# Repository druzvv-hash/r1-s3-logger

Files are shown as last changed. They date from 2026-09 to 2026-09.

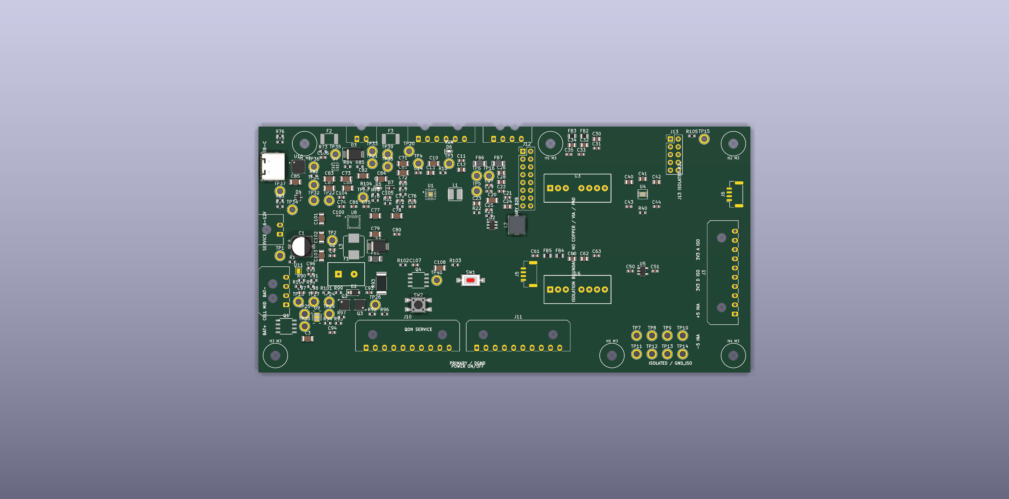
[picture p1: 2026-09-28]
hardware/kicad/R3_PowerBox/reports/R3_power_preliminary_placement.png

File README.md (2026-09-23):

# R1-S3 Logger

**[Посібник екосистеми: схеми, підключення та інструкції](../lily-logger-r3/docs/manual/README.uk.md)** — актуальний спільний вхід для R3, R1, CANBox і Viewer.

**English** | [Українська](README.uk.md)

Rebuilding Logger R1 around **ESP32-S3 + INA228**. Current firmware: **PANEL v0.36-can-live-dev**, with USB/Wi-Fi Start/Stop controls, integer 1–300 Hz measurements with presets and manual input, a 30/60 FPS live chart and explicit draft/apply/save settings. Sessions flow through a PSRAM FIFO into checked block writes on microSD. The encoder remains a no-GPIO stub. [Recording guide](docs/P5_RECORDING.md).

CAN tab: shared live/CBX playback/finite transmit workspace, using CANBox USB or
Wi-Fi directly. BLE remains service-only. [CAN guide](../GLL%20CANBox/docs/CAN_WORKSPACE.uk.md).

INA228 averaging/conversion controls and 10/30/60 s chart navigation: [guide](docs/INA228_PANEL.md).
**R3 ecosystem:** saved authenticated association, boot reconnect, coarse RTC
correction while idle and optional remote Start/Stop through R3's `/ecosystem`
page are implemented and host-tested. A [bounded two-board bench passed](docs/ECOSYSTEM_ACCEPTANCE_2026-09-09.md)
for saved permissions, coarse RTC correction, selected control and reboot recovery. Save
time-only or explicitly enable recording permission. New files use CSV v2 with
static group/RTC provenance, preserving v1 reading. [Operator guide](docs/ECOSYSTEM_CONTROL.md).

**Device UI:** run [device_ui/start.cmd](device_ui/start.cmd) with the board on native USB (COM9 on this PC),
or join the logger's Wi-Fi AP and open 192.168.4.1. Credentials are shown in the USB
panel's Diagnostics tab. [Test-panel guide](docs/P4A_TEST_PANEL.md).

**SD files:** the **Файли SD** tab lists folders and downloads existing files through
USB or Wi-Fi, without removing the card. [File transfer guide](docs/SD_DOWNLOADS.md).
The scrolling explorer includes search, sorting and automatic full-folder loading.
[Measured rate/noise limits](docs/RATE_BENCHMARK.md) distinguish usable control from
the experimental recording ceiling; v0.22 adds explicit [1–300 Hz profiles](docs/MEASUREMENT_RATES.md) with visible speed/noise tradeoffs.

## Hardware

- ESP32-S3-WROOM-2-N32R16V (reported marking MCN32R16V): 32 MB Octal Flash, 16 MB Octal PSRAM.
- Shared I²C bus: SDA GPIO8, SCL GPIO9, 100 kHz; INA228 `0x40`, SH1106G 128×64 OLED `0x3C`, 24C32 EEPROM `0x50`, DS3231 RTC `0x68`.
- SPI SD: CS GPIO10, MOSI GPIO11, SCK GPIO12, MISO GPIO13.
- INA228 ALERT: GPIO14. External shunt: owner-confirmed 60 mV / 400 A (150 microohms).
- OLED rotation: 180°. The current bench uses direct ESP32-S3 USB Serial/JTAG on COM9.

See the [pin map](hardware/pinmap.md). Board revision and SD module circuitry remain to be recorded.

Selected local control: [Bourns PEC11R-4220F-S0024](hardware/encoder.md), not yet installed. Physical and web controls will share one device state.

## Verified status

| Component | Result |
|---|---|
| Flash / PSRAM | Detected; no memory stress test performed |
| I²C | Four expected addresses responding in repeated scans without bus errors |
| SD | 10 MHz write, close, remount and exact readback PASS; output files checked on a PC |
| OLED | SH1106G 128×64 image and 180° rotation confirmed by the owner |
| EEPROM | Owner confirmed EEP PASS: backup, sample write, restore and full-image comparison |
| RTC | Browser UTC synchronization verified; OSF=0, tick PASS; retention checked after owner-reported power disconnection |
| INA228 | Fresh ADC and owner-reported voltage comparison established; independent current calibration and active ALERT pending |

Native USB flashing, full-image verification and console operation are confirmed. Use direct USB going forward; the cause of intermittent CP210x failures remains unproven.

## VS Code / PlatformIO

Open the repository root in VS Code with PlatformIO IDE installed. Dependencies are pinned to `espressif32@6.12.0` (Arduino 2.0.17), `Adafruit SH110X@2.1.12` and `NimBLE-Arduino@1.4.3`.

```sh
pio run
```

The default environment is `esp32-s3-usb`: direct USB Serial/JTAG with the console enabled. This R1 is COM9; confirm device identity before flashing (CANBox is COM11). Close the UI bridge / Serial Monitor before uploading. Port numbers may change on another PC.

```sh
pio run -e esp32-s3-usb -t upload --upload-port COM9
pio device monitor -e esp32-s3-usb -p COM9
```

`esp32-s3-uart-manual` retains the BOOT + RESET fallback (manual RESET after upload). `esp32-s3` retains the old UART profile; native USB is the normal workflow. The explicit `esp32-s3-service` build enables the original SD/EEPROM write tests; ordinary builds exclude them.

## Current behavior and migration

Normal boot reads the SD root and checks two complete EEPROM reads, then displays live voltage/current. It creates no SD test files and writes no EEPROM patterns. `SD READ / SAVED` indicates readable SD and matching persisted settings; UNSAVED means explicit saving is needed. The explicit [RTC sync](docs/rtc-sync.md) command remains available; saved R3 enrollment also permits automatic fresh RTC correction while idle. INA228 uses timed 1–300 Hz acquisition. Explicit START creates a session; STOP drains, verifies and closes it before publishing the CSV.

[3 A / 3 V load acceptance](docs/LOAD_TEST_2026-09-08.md): all three rates passed without missed samples or I2C errors; 40 verified USB downloads passed alongside 100 Hz acquisition. v0.17 fixes delayed panel-state publication found during these tests.

The [PSRAM FIFO and block-buffer foundation](docs/BUFFERING_AND_REUSE.md) is implemented and host-tested. Boot reserves the configured sample budget in PSRAM plus 8 KiB internal SD staging; the recorder now uses these buffers after explicit Start. P4a now has a working web test panel on core 0 and a hardware command owner on core 1. [P4b live acquisition](docs/P4B_LIVE_ACQUISITION.md) now uses timed INA conversions, chunked OLED transfers and batched PSRAM preview. [P5 session files](docs/P5_RECORDING.md) are implemented; local menus remain.

[P0 baseline and backup evidence](docs/P0_BASELINE.md). P1 contracts: [settings/EEPROM](docs/CONFIG_SCHEMA.md), [self-contained CSV](docs/FILE_FORMAT.md), [viewer compatibility](docs/VIEWER_COMPATIBILITY.md). Run host checks with `python -m unittest discover -s tests -v` (Python 3.10+; firmware-core tests also need a native C++ compiler). P2 viewer is implemented: launch `viewer/start.cmd` or `python viewer/server.py`. [Viewer guide](viewer/README.md) · [P2 results](docs/P2_VIEWER.md). P3 settings/EEPROM are implemented: [commands and evidence](docs/P3_SETTINGS.md). P5 connects acquisition to session recording, checkpoints and rotation; physical acceptance and limits are in the recording guide. The owner deferred remaining R5 analysis/plugins until real logger files exist. The current viewer is a data-reading foundation, not a feature-complete R5 replacement.

## Repository guide

- [BLE link controls](docs/BLE_LINK.md): authenticated pairing and explicit saved permission through **BLE · R3**. The [v0.24 two-board bench](docs/ECOSYSTEM_ACCEPTANCE_2026-09-09.md) verifies control and recovery within documented limits; extended qualification and the earlier 300 Hz signal-quality question remain open.
- [Ecosystem control](docs/ECOSYSTEM_CONTROL.md): time-only/remote permission, ON/OFF/FORGET, boot RTC correction and selected R3 control.
- [Ecosystem synchronization](docs/ECOSYSTEM_TIME_SYNC.md): R3 / R1-S3 / CAN architecture; [CSV v2](docs/FILE_FORMAT_V2.md) has static provenance, while precise sample alignment and the CAN adapter remain pending.
- [firmware/](firmware/README.md): Arduino test firmware and GPIO constants.
- [hardware/](hardware/README.md): hardware notes and pin map.
- [Bring-up plan and results](docs/bring-up.md).
- [SD serial evidence](docs/sd-test-v0.2-serial.txt).
- [Project context](docs/project-context-review.md): relevant findings from earlier logger work.
- [Ukrainian owner notes](docs/uk/README.md): historical bench notes and local workspace review.

See the staged plan below for remaining acquisition, calibration, ALERT and recording acceptance work.

Legacy recovery: [R1 firmware and viewer review](docs/legacy-r1-analysis.md).

- [Migration journal](docs/R1_MIGRATION.md): migration stages, decisions and dated hardware evidence.

- [Engineering plan](docs/R1_S3_PLAN.md): architecture, EEPROM, self-contained recording and cross-version viewer roadmap.

## CANBox fallback (experimental)

The direct CANBox control adapter and panel are implemented in the working tree.
R1 flashing and the two-board BLE acceptance are pending a manual BOOT/RESET.
See [CANBox fallback status and procedure](docs/CANBOX_FALLBACK.md).

The owner confirmed that the R1 SD card was removed during the CANBox bench. The observed SD FAIL therefore does not establish an SD fault; recheck after reinsertion.

Deployed update: **0.28-canbox-dev** adds an always-visible CANBox status and controls, including unknown/offline and pending states. Native USB deployment and live CANBox readiness/authorization verified.

## CANBox clock update 0.29

Deployed: the connected R1 supplies its valid, fresh RTC calendar to CANBox.
START requires clock_synced; STOP remains available. Live synchronization
passed; the new SD-file acceptance test awaits card reinsertion in CANBox.
See `C:\Projects\GLL CANBox\docs\CLOCK_SYNC_2026-09-15.uk.md`.

**CANBox + R1:** [Спільний запис / linked Start and Stop](docs/LINKED_RECORDING.uk.md) — перемикач біля старту CANBox, одна група сесій, підтверджений стан обох пристроїв.

Wi-Fi firmware updates: [Browser OTA](docs/OTA.md).

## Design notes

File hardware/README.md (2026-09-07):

# Hardware

The current bench consists of an ESP32-S3 board and external INA228 module, shared I²C peripherals and SPI SD storage. Initial supply checks were reported as normal; a complete numerical measurement record is still needed.

- [Pin map](pinmap.md)
- [Bring-up plan and results](../docs/bring-up.md)

The owner reports ESP32-S3-WROOM-2-N32R16V (MCN32R16V): 32 MB Octal Flash / 16 MB Octal PSRAM. Firmware detects 32 MiB Flash and approximately 16 MiB PSRAM; no stress test has been performed. The bench CP210x USB–UART bridge currently appears as COM5 on Windows.

Store schematics, BOM, wiring photos and shunt specifications here as they become available. No schematic or PCB files are included yet. Record the exact board revision, SH1106G OLED and DS3231 module wiring, SD module power circuitry, shunt resistance and allowable current.

## External shunt

Owner-confirmed on 2026-09-07: **60 mV / 400 A**, nominal **150 microohms (0.00015 ohm)**; owner reports it connected. HWTEST v0.9 uses this nominal resistance for signed current from VSHUNT. This is not measured calibration. Wiring/polarity, shunt tolerance and temperature coefficient remain to be recorded. See [migration journal](../docs/R1_MIGRATION.md).

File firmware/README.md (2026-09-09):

# PANEL v0.20 firmware

PlatformIO + Arduino for ESP32-S3 N32R16V. Run commands from the repository root. See the [main README](../README.md) for build and upload environments.

The [device test panel](../docs/P4A_TEST_PANEL.md) now provides USB/Wi-Fi controls.
The hardware owner remains core 1; the web task on core 0 uses snapshots and commands.
I²C scanning after startup is explicit, not periodic. Timed integer 1–300 Hz sampling,
chunked OLED and PSRAM live preview are implemented. [Session recording](../docs/P5_RECORDING.md) uses the PSRAM FIFO and checked SD block writes.
See [cadence and transport](../docs/P4B_LIVE_ACQUISITION.md).
Existing SD files can now be downloaded through the panel; the dedicated storage
owner is in `sd_files.cpp`. See [file transfers](../docs/SD_DOWNLOADS.md).

- `src/main.cpp`: memory information, explicit I²C scans, SD test and SH1106G 128×64 OLED rotated 180°.
- `src/eeprom_test.cpp`: 24C32 backup to SD, sample write, restoration and full-image comparison.
- `src/rtc_test.cpp`: read-only DS3231 calendar/BCD, temperature, OSF/EOSC and tick checks.
- `include/pins.h`: GPIO constants matching [hardware/pinmap.md](../hardware/pinmap.md).
- `r3_time_beacon.h/.cpp`: portable strict legacy R3 TMB decoder and bounded observation tracker. Not attached to runtime BLE/UART; never changes RTC or sample time. [Ecosystem time architecture](../docs/ECOSYSTEM_TIME_SYNC.md).

Ordinary boot only reads SD/EEPROM. Explicit CONFIG SAVE writes settings; see [P3 workflow](../docs/P3_SETTINGS.md). `esp32-s3-service` explicitly enables the legacy SD file and EEPROM pattern/restore tests. Periodic checks never set time; the explicit browser command does. See [RTC sync](../docs/rtc-sync.md). The EEPROM write test is temporary diagnostic code; keep power connected until restoration completes.

The default environment is `esp32-s3`; manual UART remains a fallback. Automatic UART reset and experimental native USB environments remain in `platformio.ini`. Automatic UART uploads passed after USB-UART controller rework; long-term reliability remains to be established. See [bring-up results](../docs/bring-up.md).

- `src/ina228_test.cpp`: identity, fresh triggered VBUS/VSHUNT/temperature sample, ADC_CONFIG restoration and passive ALERT level. See the [migration journal](../docs/R1_MIGRATION.md) for test side effects and acceptance limits.

- `include/shunt_config.h`: historical nominal shunt checks. Runtime conversion now uses `appliedSettings()` with validated polarity, shunt, offsets and gains.
- `settings_core.cpp`: portable TLV/CRC/A-B store, INA apply/readback/rollback.
- `settings.cpp`: 24C32 adapter and STOP-only draft/apply/save UART workflow.
- `config_fields.h` and `config_codec_generated.inc`: generated from schemas/config-v1.json. Regenerate with tools/generate_config.py; do not hand-edit.
- `local_input.cpp`: no-hardware encoder stub; no GPIO accessed. [Selected encoder](../hardware/encoder.md).
- `recording_buffer.cpp`: SPSC numeric FIFO and checked block-output primitives; `recording_memory.cpp` reserves PSRAM payload plus an 8 KiB internal DMA-capable staging buffer at boot. Acquisition/SD owners are not yet connected to them. [Reuse evidence and limits](../docs/BUFFERING_AND_REUSE.md).

- `src/storage_check.cpp`: read-only SD-independent EEPROM checks and `EEPROM DUMP` backup transport. See [P0](../docs/P0_BASELINE.md).

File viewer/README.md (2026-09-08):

# R1 / R1-S3 offline viewer 0.2

P2 offline viewer, Python 3.10+ and a modern browser. **No pip/npm install, CDN, Internet connection or device connection is required.** The interface is Ukrainian; code/contracts/documentation are English.

## Start

Windows: double-click `viewer/start.cmd` (requires the Python `py` launcher), or run from the repository/bundle root:

```text
python viewer/server.py
```

The launcher opens the browser. Choose a CSV file or drag it onto the upload area. Keep the launcher running; Ctrl+C stops it. If port 8766 is occupied, use `python viewer/server.py --port 0` to select an available local port. `--no-browser` prints the URL without opening it.

This is a local Python application with a browser interface, **not a standalone HTML or executable**. It binds only to 127.0.0.1, uses a per-run access token, and rejects cross-origin mutation requests. Recordings travel only from the browser to the same computer. Temporary SQLite data are removed at normal shutdown; after a process crash an OS temporary folder can remain. Source recordings are never edited.

## Supported and intentionally limited

- R1 named eight-column CSV: columns by name, optional reordered/extra fields, BOM/CRLF, comments before/after header.
- R1 Pss CSV: current/voltage/power by names; Pss_Wh remains separately labelled because its accumulator meaning is unverified.
- Short/headerless R1 CSV: explicit user confirmation of milliseconds, A, V, W and net Wh before import. Headerless presets have six/eight columns. Unknown layouts require a matching source/mapping, not automatic guesses.
- R1S3 native CSV v1: metadata/config/units, raw/calibrated consistency, monotonic/UTC time, integration, CRC/checkpoints and SHA256 END checks. Exact u64 values remain integer strings in normalized records. Plot coordinates use bounded segment-relative floating seconds.
- Interrupted native file: only checkpoint-verified rows enter charts/statistics; complete unverified tail count and partial-line status are reported. Corrupt files fail explicitly, rather than displaying misleading data.
- LYLI/R3 binary files are recognized but unsupported until P8's verified adapters.

Legacy timezone is unknown unless a fixed UTC offset is explicitly supplied (minutes). This does not implement automatic DST. Existing timezone-qualified strings retain their own offset when interpreted. Relative time stays authoritative. Wrong-width or invalid-time rows are skipped with a continuity break; missing/nonfinite measurements become null and mark the row invalid. Malformed optional columns become null with a diagnostic. This initial viewer conservatively excludes an invalid measurement row from all channel analysis. Parsed numeric values, original timestamp text, line numbers and byte offsets remain in temporary normalized records; unavailable optional text is not retained as a numeric channel.

Select a segment when time resets or a repeated header starts a new session. The viewer never sorts away resets or bridges them. For legacy gaps, twice `interval_us` metadata is used when present; otherwise the explicit import threshold (default 1000 ms) applies. Legacy files cannot prove fresh cadence or missing samples merely from nominal metadata. Adjust the threshold and re-import when necessary.

## Graphs and analysis

Select any available series with the checkboxes. Each channel has its own labelled value axis; all panels share the same time viewport. The statistics-channel selector is independent of visible series. Wheel zoom is anchored at the cursor; choose drag-zoom or pan in the interaction selector. Double-click or “Увесь сегмент” resets the viewport. Numeric start/end inputs provide reproducible selection.

In marker mode, clicks place A then B at the nearest original samples (subsequent clicks replace the oldest). The panel displays exact original t_us, timestamp text, source line and quality. Delta time is signed B minus A. Full-resolution interval statistics use the sorted A/B bounds, independently of zoom. Shift-click places horizontal C/D levels for a single channel; choosing a different channel starts a new value pair so unlike units are never subtracted. Markers persist through zoom and series changes, and clear on new files/segments. “Масштаб A–B” fits their interval.

Hover reports the nearest actual row, its distance from the cursor, original values, quality and continuity status. It does not interpolate values or silently jump over invalid rows. In a gap the nearest sample can be far from the cursor; its displayed distance is intentional. Preview bins retain min/max extrema; a bin containing invalid data or a gap is isolated instead of joined across it.

Statistics scan all valid full-resolution rows in the selected range, not the preview. Mean is sample-weighted. Charge and energy use actual elapsed time, trapezoidal sign splitting, and no integration across gaps/invalid rows. No extrapolation/interpolation to range edges: uncovered edge intervals are included in “without data / outside samples”. Recorded Wh_net delta is shown separately from recomputed energy. First/last cumulative values of an independently opened rotation part are not proof of cross-part continuity.

Download JSON report contains interpretation metadata, diagnostics and selected-range statistics/preview, **not a full-resolution data export; marker coordinates and A/B statistics are included**. At most 200 diagnostic examples are retained, with total count separately available. Unknown optional text values are not plotted as numbers. An old-viewer CSV export, starter/battery plugins, binary adapters and automatic part joining remain later work; they are not advertised by this release.

## Capacity and verification

Input cap: 1 GiB, 10 million rows and 1000 time segments; disk space must accommodate the source upload plus a temporary database that can be substantially larger than CSV. Import reads bounded lines (64 KiB legacy record, 16 KiB native metadata, <=1024 native rows/checkpoint). SQLite uses a 4 MiB page cache; data live on disk. Plot output is at most 2000 extrema bins per selected channel (up to 32 known distinct channels per request). Import/statistics run in the local service, keeping the browser responsive; large scans may take time. Only one recording is active at a time.

Run `python -m unittest discover -s tests -v`. Optional UI smoke test uses Playwright/Chrome supplied by the developer environment: `node tests/smoke_viewer.cjs <printed URL>` and `node tests/r5_viewer.cjs <printed URL>`. It is not a runtime dependency. `python tools/benchmark_viewer.py --rows 350000` tests streaming native input above the P1 oracle's 16 MiB limit. [P2 results](../docs/P2_VIEWER.md) record measured scope and remaining limits.

Build a portable folder ZIP (Python runtime not included): `python tools/package_viewer.py`. Unzip before launching `viewer/start.cmd`.

## R5 preservation correction

This release is the file-reading foundation, not a feature-complete replacement for R5. P2.1a marker/series/navigation recovery is implemented. P2.1b analysis and P2.1c plugin recovery still precede firmware P3; see [migration matrix](../docs/R5_FEATURE_MIGRATION.md). Direct index.html opening now shows launcher instructions and disables nonworking file import.

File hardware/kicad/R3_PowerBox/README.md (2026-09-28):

# R3 PowerBox

Editable KiCad 10 project for the R3 power module. The schematic uses one root
page and ten functional child sheets so battery/BMS, charger/power-path,
user system-power control, primary converters, isolation, LDOs, INA bipolar power and connectors can be
reviewed independently.

## Open

Open `R3_power.kicad_pro` in KiCad 10. The canonical schematic is
`R3_power.kicad_sch`; the PCB file is `R3_power.kicad_pcb`.

## Directory layout

- `R3_power.kicad_pro` — KiCad project settings;
- `R3_power.kicad_sch` — power schematic;
- `R3_power.kicad_pcb` — PCB workspace;
- `libraries/` — project-local symbols and source libraries;
- `footprints/` — project-local provisional footprints;
- `docs/` — design decisions, checks, and transfer notes;
- `bom/` — KiCad-exported BOM plus sourcing/review notes;
- `legacy/` — read-only KiCad 5 source retained for migration reference;
- `tools/` — reproducible schematic generator and its setup notes;
- `manufacturing/` — release outputs only after schematic/PCB review;
- `reports/` — ERC/DRC reports generated during checks.

## Safety and design status

- The board is a unified 2S Li-ion power-management design. The preliminary
  system range is 6.0-8.4 V; there is no intermediate 2S-to-9 V converter.
- J1 is retained as a protected service/bench charger input. USB-C is the
  primary external input; STUSB4500 implements 5/9/12 V negotiation with
  12 V/2 A preferred and a boot-safe 0.50 A charger default.
- `DGND` and `GND_ISO` are separate galvanic domains and must never be joined.
- SW1/Q4 disconnect only `VSYS_MAIN`; BMS, PD and charging remain active while
  R3 is off. SW2 is the separate QON ship/wake/service control.
- The present files are an engineering prototype, not a manufacturing release.
- Q2/Q3, F1/F2/F3 and the dual-NTC strategy are selected for Rev.A. Battery
  chemistry/configuration, hot-current validation and PD NVM compliance remain
  open before ordering a PCB.
- The PCB contains a 160 x 80 mm outline, four spatial zones, an isolation
  keepout on all four copper layers, six NPTH M3 mounting holes, optional
  primary/isolated B2B headers and final pre-routing component placement. It
  has no routing or vias.
- KiCad ERC has zero errors. Remaining generator-related warnings and the visual
  review limitations are recorded in `docs/VERIFICATION.md`.

Start with [the current power review](R3_POWER_REVIEW.md) and
[battery architecture](R3_BATTERY_POWER_ARCHITECTURE.md), then see the compact
[design notes](docs/R3_power_module_design.md) and
[verification status](docs/VERIFICATION.md). Placement images are in
`reports/R3_power_preliminary_placement.png` and
`reports/R3_power_zone_isolation_annotated.png`; mechanical stack dimensions
and views are in [the B2B interface note](docs/R3_BOARD_TO_BOARD_INTERFACE.md).

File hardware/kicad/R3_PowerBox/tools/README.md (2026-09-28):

# Schematic regeneration

`generate_hierarchical.py` is the reproducible electrical source for the root
sheet and ten KiCad 10 child sheets. It requires Python and `skidl==2.3.0`.

Set `KICAD10_SYMBOL_DIR` to KiCad's `share/kicad/symbols` directory, run the
generator from the `R3_PowerBox` directory, and then open/save the result in
KiCad 10. Then run `tools/arrange_schematic.py` from the same Python environment.
It applies the reviewed, deterministic sheet layout without changing connectivity.
Regeneration replaces the generated schematic sheets, so always rerun the
arranger before review.

The arranger also fixes the dense battery/BMS sheet to A3 and the
charger/power-path sheet to A2. This prevents SKiDL's automatic paper-size
selection from clipping or crowding those two sheets on regeneration.

The generator also writes `logical_nets.json`. This is the authoritative
pin-to-net map used by the arranger, avoiding accidental reliance on labels that
may overlap in the initial automatic drawing.

The project-local symbol source is `libraries/R3_POWER.lib`; the native KiCad
library used by the editor is `libraries/R3_POWER.kicad_sym`.

`generate_preliminary_placement.py` is a separate, explicitly unrouted PCB
placement generator. Run it with KiCad 10's bundled Python after schematic
regeneration. It exports a temporary XML netlist, reloads the assigned
footprints, assigns nets and packs them into the documented four zones while
preserving the outline and isolation keepout. It never creates tracks or vias.

The placement generator also adds the six project-local M3 NPTH footprints,
their four-layer keepouts and the `Dwgs.User` future-R3 envelope. These are
mechanical PCB objects and intentionally do not appear in the schematic BOM.

`generate_mechanical_views.py` regenerates the annotated zone/isolation,
stack-top and stack-side PNG references (plus the annotated-zone PDF) from the
dimensioned coordinates used by this pass.

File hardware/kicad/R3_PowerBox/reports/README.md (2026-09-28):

# Verification reports

KiCad ERC and DRC reports are stored here. A report documents only the file and
revision that generated it; it is not physical hardware acceptance.

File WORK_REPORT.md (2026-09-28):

# r1-s3-logger — work reports

## 2026-09-28 — R3 PowerBox mechanical and B2B pass

Added six electrically floating 3.20 mm NPTH M3 holes with project-local 8 mm
all-copper-layer keepouts, DNP J12 primary 2x8 and J13 isolated 2x5 generic
2.54 mm THT stacking interfaces, a dimensioned `Dwgs.User` upper-board
envelope and reproducible top/side mechanical views. Existing Micro-Fit cable
interfaces, user power controls, zones and 3 mm isolation corridor remain.

The final placement has 193 electrical footprints plus six mechanical holes,
0 tracks and 0 vias. KiCad checks report ERC 0 errors/412 known generator-grid
warnings and zero clearance, copper-edge, hole, drill, annular or courtyard
geometry errors. Visual review covered all 11 schematic PDF pages. U3/U6 are
11.1 mm high, making 15 mm the recommended stack; 12 mm needs upper-board
cutouts. Routing remains blocked by the pre-existing programming/bench/thermal
gates plus final enclosure, M3 and header/socket mechanical selection.

## 2026-09-28 — R3 PowerBox KiCad capture

Created and advanced `hardware/kicad/R3_PowerBox` to a final pre-routing
checkpoint. The editable SKiDL source now generates a root plus ten functional
sheets covering 2S battery/BQ28Z610 protection, BQ25798 NVDC charging,
STUSB4500 USB-C PD, service-input muxing, user load switching, TPS62132/TPS54302,
separate ADS and INA primary filters, RS3E/RS3 isolation, ADM7150/TPS7A20 clean
rails, connectors and test points. `DGND` and `GND_ISO` remain distinct.

Closed the final UI/control correction: Q4 `DMP3007LSS-13` switches
`VSYS_PROT` to `VSYS_MAIN` while BMS/PD/charging remain upstream; SW1 is normal
latching power and SW2 is separate QON service. D5 remains on REGN/raw
`BQ_STAT_RAW`; BAT54WS isolates the 3.3 V `CHARGE_STATUS` logic. J11 exports
panel power/control/I2C/status without shared onboard LED-anode nets or GND_ISO.
The conservative status LOW is <=0.72 V, below STM32H755 and ESP32-S3 limits.

Validation with KiCad 10.0.0 and SKiDL 2.3.0: PDF export PASS and all 11 pages
visually inspected; ERC 0 errors / 408 generated library-grid warnings. BOM and
logical net map regenerated. The 160 x 80 mm four-layer preliminary placement
contains 191 footprints, no courtyard overlap, 0 tracks and 0 vias. DRC has zero
clearance, copper-to-edge, drill-range and annular-width findings; remaining
items are expected unrouted connections and silkscreen cleanup. No Gerbers,
routing, procurement, assembly, power-up, thermal, ripple, EMC, isolation or
load acceptance was performed. Exact routing blockers remain recorded in
`hardware/kicad/R3_PowerBox/docs/VERIFICATION.md`.

## 2026-09-24 — shared session files and BLE resilience

R1 0.38 / CANBox 0.6.5 / R3 CC 0.2.1 deployed; STM32 CM7 LFN/UTC update
ST-LINK verified. R1/CANBox share UTC/group basenames and continue through BLE
loss; explicit offline STOP reconciles original session on reconnect. Hardware
R1/R3-controller tests PASS with no CAN frames; R1 finalized file integrity PASS.
Actual FatFs host test validates creation/modification fields and LFN. STM32
recording awaits ADS131 development (owner clarified), not yet ECO1 group member.
Earlier R1 HTTP outage cause unresolved; final short download PASS. No overnight
or load qualification. Viewer reader updated; running server needs restart.
[Contract, evidence, deployment and limits](../GLL%20CANBox/docs/SESSION_RESILIENCE_2026-09-24.md).

## 2026-09-23 — shared owner manual

Created the Ukrainian ecosystem manual with topology, entry points, workflows,
troubleshooting and evidence limits. Update it alongside user-visible changes.
Documentation only; no new build, firmware deployment or hardware acceptance.
[Manual](../lily-logger-r3/docs/manual/README.uk.md).

## 2026-09-23 — R3 primary CANBox integration verified

R3 now controls R1 and CANBox together and provides coarse UTC. R1 firmware
unchanged. Group START/STOP, saved R1 fallback and return to R3 passed;
25/25 post-return fresh/time samples, not precision acceptance. Canonical report:
../lily-logger-r3/docs/CANBOX_CONTROL.md. Existing averaging owner edits preserved.

## 2026-09-23 — CAN Live update deployed

Shared CAN assets deployed by OTA alongside existing0.37 owner changes.
88 tests/build PASS; real UI122722/0 live-ring losses, not hardware losslessness.
R1↔R3 unchanged; CANBox UTC invalid/service adapter missing.
See [deployment report](docs/CAN_LIVE_FIXES_2026-09-23.md).

## 2026-09-22 — shared CAN workspace

Added CAN tab, embedded `/can`, PC bridge route and generated common assets from
../GLL CANBox/workspace. BLE remains service/control/time only. Browser directly
uses CANBox USB/Wi-Fi; no CAN payload relay through R1. Version 0.36-can-live-dev.
Preserved OTA, timezone and linked-recording implementation.

HOST TESTED: build and 88 Python tests PASS (PlatformIO Python with pyserial).
BENCH TESTED: native COM9 flash/hash to verified active app1 0x490000; subsequent
STATE 0.36/READY/generation 6. Real R1-hosted `/can` + CANBox Wi-Fi: rejected wrong
token, 60 s live/status without stale UI, clean disconnect. Concurrent R1 BLE:
12/12 connected/fresh/clock synced; fallback mode enabled. Zero CAN frames seen.
No physical TX, loaded traffic or new analog accuracy qualification. No R3 flash.
Canonical protocol, LED wiring and limits: sibling docs/CAN_WORKSPACE.md and
CAN_WORKSPACE.uk.md. Evidence stays private in CANBox/local; secrets not committed.

Append dated entries with scope, changes, validation, limitations, deployment and next steps. Do not include credentials or claim unperformed tests.

## 2026-09-21 — reporting established

Created this project-specific report at the owner's request. Existing notes and
history remain authoritative; this entry does not claim a retrospective code or
hardware audit. No firmware was deployed and no project functionality changed
as part of this reporting setup.

## 2026-09-21 — Control Center clock priority and local time UI

Request: make the R1 clock configurable with R3 Control Center priority and manual
fallback; consult existing ideas and maintain independent project reports.

Changes:
- Added Overview date/time controls: explicit browser clock or local calendar
  entry, timezone display and conversion to UTC. Invalid dates and spring DST
  gaps are rejected; repeated autumn times use the browser's earlier occurrence.
- Fresh authenticated valid R3 UTC (under 5 seconds old) prevents manual RTC
  writes in both UI and firmware, including legacy serial commands. CANBox is
  not treated as R3 time authority. Disconnect/invalid/stale R3 allows fallback.
- Existing recording guard and RTC readback remain. Only the already validated
  ecosystem owner path bypasses the local-clock priority guard; it still cannot
  change time while recording. Manual changes invalidate old R3 provenance,
  allowing existing automatic synchronization to resume when R3 returns.
- Accepted 9-digit Unix timestamps for the supported year-2000 RTC range.
- Version: 0.32-time-dev; no EEPROM schema or recording format change.
- Read R1 engineering/time plans and sibling R3 NOTES.md. Added R1 NOTES.md links,
  owner time instructions and shared C:/Projects/AGENTS.md continuity rules.
- Created independent WORK_REPORT.md files in seven active Git repositories;
  archive/snapshot directories were excluded. Other repositories received only
  their reporting file, not functional changes.

Validation:
- Production PlatformIO build PASS: RAM 87,556 bytes; Flash 1,202,421 bytes.
- RTC priority host test PASS: executes actual admission functions against mocked
  hardware; freshness boundary, authentication, CANBox exclusion, recording lock,
  epoch bounds and absence of write/provenance side effects on rejected commands.
- Time browser fixture PASS: local-to-UTC, DST gap, no implicit write, authority
  and recording locks, mobile width. General panel and BLE browser fixtures PASS.
- Nine panel/API/bundle host tests and two BLE trust/protocol tests PASS.
- Updated the old BLE fixture assembly to include INA/chart modules and use the
  stable tab selector; it previously failed before exercising any BLE controls.
- git diff --check PASS.

Deployment: built locally, not uploaded to a board; no physical RTC/radio test,
commit or GitHub push in this work session. Next: deploy to an identified idle R1
and test manual set/readback, R3 reconnect priority and power-cycle RTC retention.

## 2026-09-21 — requested deployment of time controls

Identified R1-S3 on native USB COM9 by MAC 90:e5:b1:cd:55:74 and PANEL
0.31-canbox-dev response. Recorder was READY with saved settings generation 5.
Built/uploaded esp32-s3-usb 0.32-time-dev successfully; flash hash verified.
Native build: RAM 87,356 bytes, Flash 1,187,985 bytes.

Three post-boot STATE responses confirmed 0.32-time-dev, READY, advancing samples
and RTC, ADC OK, TICK OK and zero I2C errors. Full configuration and EEPROM
generation matched pre-upload state. No TIME or EEPROM Save command was sent.
R3 time authority was unavailable during this check; physical R3 priority and
manual time write/readback remain separate acceptance tests. No Git commit/push.

## 2026-09-21 — shared LAN Wi-Fi, TTGO-style connection

Request: access R1 while phone/PC stays on the home network; provision known Wi-Fi
profiles. Read TTGO README/main.cpp and R3 NOTES.md. The inspected notes did not
contain home credentials; used the owner's saved Windows WLAN profiles instead.

Implemented AP+STA, three NVS profile blobs, 20-second nonblocking profile retry,
mDNS r1-s3-7455.local, LAN status/links and primary-network UI configuration.
Network writes run on the network task, with recording/download checks at both
queue admission and execution. Existing AP remains available. Fixed SD download
redirect to use the incoming interface's local IP instead of always the AP IP.
No OTA or captive portal was added. TTGO functional code was not modified.

Provisioned TP-Link_CC06, dlink_DWR-932_4280 and iPhone. Secret bootstrap header is
Git-ignored; credentials are absent from public docs and station status. NVS is
separate from measurement settings. Private seeded firmware must not be published.

Validation/deployment:
- LAN browser fixture and existing panel browser checks PASS; nine host panel/API
  checks PASS. Verified mobile layout and removed obsolete AP-only UI text.
- Built/flashed final 0.33-lan-dev via native USB COM9; image hash verified.
  RAM 89,796 bytes; Flash 1,219,625 bytes.
- R1 joined TP-Link_CC06 while PC stayed on the same network. Both
  http://192.168.0.149/ and http://r1-s3-7455.local/ worked.
- Real Chrome page showed advancing samples on one boot, zero I2C errors and no
  page errors over a bounded 15-second observation. SD directory listing passed.
- Downloaded an existing 735,865-byte CSV through the LAN redirect on port 81;
  Content-Length matched. SHA-256:
  c4dd33c702b56b1967f739f6ec1ece9b6a8744d2e9ed12facf5f52aca564bf9d.
  This is a transport check, not renewed measurement-file validation.
- After the final cosmetic reflash, automatic reconnect worked, READY returned,
  measurement configuration and saved generation 5 matched baseline, and the
  HTTP-served page matched the generated asset byte-for-byte.

Limits: alternate hotspots, router-loss recovery, profile changes through the
physical UI, phone acceptance and long-term BLE/Wi-Fi coexistence are not yet
qualified. RSSI varied roughly -71 to -82 dBm. No measurement settings, RTC or
recordings were changed; no Git commit/push was performed.

## 2026-09-21 — requested Git synchronization

Set RTC from PC using the visible UI button; UI confirmed RTC UTC written and verified. R3 time was unavailable, recorder idle. Audited the five outgoing CANBox commits and current time/LAN work for known WLAN secrets; ignored bootstrap/data remain excluded. Committing and pushing to the existing origin/main as requested. Previous build and targeted tests are recorded above.

## 2026-09-21 — unified local operator time requirement

Reviewed the reported two-hour discrepancy and current time/display code.
The R1 live clock explicitly renders UTC, whereas RTC input and directory dates
use browser local time. Existing display_utc_offset_min is not used for these
views; recording session names explicitly use UTC Z. The ecosystem contract
currently synchronizes UTC, without a shared operator timezone.
Recorded the owner requirement in NOTES.md: one shared local display convention
from the Control Center, persistent fallback, recording-time timezone provenance,
and compatible canonical timestamps. No firmware, RTC, recording or remote
repository was changed in this requirement review. Implementation and hardware
validation across R1, R3, CANBox and viewer remain outstanding.

## 2026-09-21 — R1 local operator time implemented

Deployed 0.34-local-time-dev on R1 native USB COM9. UI live clock and manual
calendar now use saved display_utc_offset_min rather than mixing UTC and browser
local time. PC time button applies/saves its current offset when different, then
sets RTC; existing priority/recording locks remain. OLED header now shows local
HH:MM:SS. New recording names include local calendar and explicit numeric offset;
random identity suffixes remain. Directory parser accepts both new offset names
and legacy UTC names; new names preserve their original local date after an
offset change. Existing CSV canonical UTC and config snapshot remain compatible;
recorded config already carries display_utc_offset_min. Other devices/viewer
were not modified.

Validation: nine serializer/contract/viewer roundtrip tests PASS, including
positive/negative offset, leap-day rollover and unknown time. Nine panel tests
PASS; browser fixture passed local conversion, legacy/new filename recognition,
priority/recording locks and mobile layout. Production build/upload PASS with
hash verification (RAM 89,796; Flash 1,220,093 bytes). Actual visible UI PC-time
button saved generation 6 and offset +120; full config comparison showed ONLY
that field changed. UI displayed 18:08:30 local; RTC was within one second of PC
in a sequential HTTP comparison, TICK OK, zero I2C errors. OLED time rendering
compiled/deployed but not visually observed. No new physical SD recording was
created; filename serialization was host-tested. Browser fixture ran in Prague;
no cross-timezone physical browser test claimed.

Limit: fixed saved offset, not automatic DST; update from PC at seasonal change.
Historical UTC-named files have no filename offset and use current R1 display
offset. Canonical CSV times remain UTC; viewer display work is deferred as asked.

## 2026-09-21 — browser OTA delivered

Read TTGO src/main.cpp as reference; no TTGO edits. Added authenticated /update
page with progress, same-origin/header validation, bounded exact image length,
S3 header check and standard Update verification before slot activation. R1
owner pauses acquisition only after excluding active/linked recording and taking
the SD request gate; releases on failure. Added Wi-Fi panel link and OTA guide.
USB bootstrap deployed 0.35-ota-dev, RAM 90,012 bytes, Flash 1,235,577 bytes.

Validation: nine panel host tests PASS; production build and USB upload/hash PASS.
Physical HTTP bench: missing authentication 401; foreign Origin, invalid header,
and truncated image rejected without reboot; owner resumed. Real Wi-Fi firmware
upload succeeded, verified app0 -> app1 and new boot ID, READY. Full configuration
and EEPROM generation preserved. Additional actual file OPEN lease blocked OTA;
lease closed afterward. A short test recording also blocked OTA while continuing
RUNNING, then STOP finalized it and returned READY. That SD file is a guard test,
not measurement qualification. An initial exhausted directory-list test did not
hold a lease (expected auto-close); the subsequent file OPEN exercised the guard.

Limits: browser form itself not manually uploaded in this bench; matching HTTP
multipart endpoint was exercised. Power loss, unhealthy-image rollback and hostile
LAN isolation are not qualified. See docs/OTA.md for authentication boundary and
firmware selection. No ArduinoOTA IDE protocol added. Existing trusted-LAN model
retained; credentials/images remain outside Git.

## 2026-09-21 — external-memory audit and bootstrap

### Request / Context
Establish durable project context without copying chat transcripts. Reviewed
existing entry documents, relevant reports, repository status and recent commits.

### Changes
Added/linked bootstrap and concise evidence-aware project memory. Existing
technical history, owner notes and unsuccessful approaches retained.

### Validation
Documentation-only audit: local reference existence and Git change scope checked.
No new build, host runtime, browser, bench, hardware acceptance or vehicle test.
Previously reported evidence remains attributed to its original source/scope.

### Result / Limitations
A new task can enter via AGENTS -> NOTES -> relevant WORK_REPORT/docs. This is
not a full code re-audit; contradictory old dates/version banners require the
linked newer report and current code. Private raw evidence may be local-only.

### Failed / rejected approaches
Rejected copying entire histories or turning backup/snapshot folders into active
projects. See NOTES for project-specific negative knowledge.

### Deployment / Next
Documentation only; no device changes. Workspace audit at
C:/Projects/PROJECT_MEMORY.md records repository classification and commit status.
Maintain checkpoints after substantial work; resolve the open tasks in NOTES.

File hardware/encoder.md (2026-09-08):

# Local control encoder

Selected 2026-09-08: **Bourns PEC11R-4220F-S0024**, plus a knob for a **6 mm D-shaft**. The owner has not purchased/installed it yet. GPIO remain unassigned.

This part has 24 detents and 24 quadrature pulses/revolution, a momentary push switch, a 20 mm metal flatted shaft and panel fastening hardware. One complete quadrature cycle corresponds to one detent. The 20 mm dimension is the manufacturer's actuator dimension; check the drawing against the enclosure and knob depth before drilling. Source: [Bourns PEC11R datasheet and ordering table](https://www.bourns.com/docs/product-datasheets/pec11r.pdf). [Supplier product page](https://www.tme.eu/en/details/pec11r-4220f-s0024/incremental-type-encoders/bourns/); no price or stock level is frozen in this document.

This is a compact mechanical menu control, not a precision shaft-position sensor. It offers enough tactile steps for navigating the small OLED, fine adjustments and software-selected larger increments. The push switch provides Select; a long press can provide Back. Keep a visible Back menu action too. A separate momentary REC/STOP button is optional, not required to use the logger. Debounce and full quadrature transition validation are required when implementing the real adapter.

## Electrical implementation target

- Bare encoder: A/B/common contacts and two separate push-switch contacts; no module power pin. Common and one switch contact go to GND; A, B and the other switch contact go to three confirmed GPIO inputs.
- Use pull-ups to **3.3 V** for ESP32-S3 inputs. The datasheet's 5 V contact rating is not a requirement to apply 5 V to the MCU. Select pull-ups/filter values for the actual wiring; the manufacturer shows a filter example. Verify bounce, fast rotation, press/release and idle levels on the assembled unit.
- Confirm the particular footprint/contact orientation from the drawing. Do not infer pin order from a generic KY-040 board.
- Keep BOOT/RESET and the existing I2C/SD/ALERT wiring unchanged; no pin allocation in this stage.

`firmware/include/local_input.h` defines Previous/Next/Select/Back/Start/Stop actions. `local_input.cpp` is deliberately disconnected: available=false, poll returns no action, with no GPIO, pull-up or interrupt operations. The future adapter changes input acquisition, not recording ownership. The stub is not a simulated working encoder and not a finished menu UI.

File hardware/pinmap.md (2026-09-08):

# R1-S3 pin map

Numbers below are **ESP32-S3 GPIO numbers**, not connector pin positions.

| Interface | Signal | GPIO |
|---|---|---:|
| I²C | SDA | 8 |
| I²C | SCL | 9 |
| SD / SPI | CS | 10 |
| SD / SPI | MOSI | 11 |
| SD / SPI | SCK | 12 |
| SD / SPI | MISO | 13 |
| INA228 | ALERT | 14 |

All four I²C devices share the bus. Verify common ground and SDA/SCL pull-ups to 3.3 V, not 5 V. Check the actual INA228 module schematic for ALERT wiring and pull-up requirements before testing.

## I²C addresses

| Device | 7-bit address | Evidence |
|---|---|---|
| INA228 | `0x40` | ID 0x5449/0x2281 and fresh ADC readings confirmed; analog comparison pending |
| SH1106G OLED, 128×64 | `0x3C` | ACK and readable image confirmed; rotation 180° |
| EEPROM 24C32 | `0x50` | ACK and sample write/restore test PASS |
| DS3231 RTC | `0x68` | UTC synchronization and ticking confirmed, OSF=0; time retained after main-power removal |

Repeated scans found all four addresses without bus errors. Address ACK alone does not establish device identity or full functionality. EEPROM address depends on A0–A2; INA228 address depends on its address configuration.

Keep this map and [firmware/include/pins.h](../firmware/include/pins.h) synchronized when wiring changes.

Local encoder A/B/SW: **not assigned, hardware not installed**. The current input adapter is a no-GPIO stub. See [selected encoder](encoder.md) before assigning three new input pins.

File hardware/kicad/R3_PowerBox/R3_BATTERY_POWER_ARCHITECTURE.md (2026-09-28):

# R3 PowerBox 2S battery and power architecture

Date: 2026-09-28
Status: final UI / power-control / DRC pass complete; electrical validation gates
remain before a routing release.

## Fixed system decision

R3 uses one onboard-managed **2S Li-ion battery**:

- nominal stack voltage: about 7.4 V;
- maximum charge voltage: 8.4 V;
- preliminary operating system range: 6.0-8.4 V;
- final per-cell undervoltage thresholds remain a chemistry/BMS configuration decision.

There is no separate BMS/charger board and no intermediate 2S-to-9 V converter.

## Direct 2S operation of the existing converters

### TPS62132

The official datasheet specifies 3-17 V input, 3 A output and 100% duty-cycle operation. A 6.0-8.4 V system rail is therefore inside the guaranteed input range with ample headroom for 3.3 V. Startup UVLO is below the 2S range. Existing soft-start, FB-to-AGND connection, inductor and output capacitors are retained.

### TPS54302

The official datasheet specifies 4.5-28 V input, 3 A, 400 kHz operation and internal VIN UVLO of 4.1 V typical. At 6.0 V input, an ideal 5 V output requires 83.3% duty cycle. This is within a normal buck operating region, but TI's published reference design is characterized from 8 V and the datasheet does not give a guaranteed dropout curve at 5 V/3 A. Direct 2S operation is retained, with a required bench test at 6.0 V under load and transient conditions.

The old 511 kOhm / 105 kOhm external EN divider was copied from the 8-28 V reference design and would block part of the required 2S range. It has been removed; EN follows the switched `VSYS_MAIN` rail. Battery undervoltage protection is owned by the BMS and TPS54302 retains internal UVLO.

## Implemented architecture

```text
2S cells: BAT_POS_RAW / CELL_MID / BAT_NEG_RAW
  -> BQ28Z610 gauge + protection + cell balancing
  -> TI-EVM-style common-drain CSD17577Q3AT DSG/CHG N-FET pair
  -> PACK_POS
  -> 10 mOhm Kelvin shunt in negative path -> DGND

USB-C -> F2 / SMBJ13A / STUSB4500 (5/9/12 V PD) ---+
                                     -> TPS2121 input mux -> CHARGER_IN
J1 service/bench 6-12 V -> existing protection ---+

CHARGER_IN -> BQ25798 buck-boost NVDC charger/power-path
PACK_POS   -> BQ25798 BAT
BQ25798 SYS -> VSYS_RAW -> F3 system protection -> VSYS_PROT
             -> Q4 DMP3007LSS user load switch -> VSYS_MAIN

VSYS_MAIN -> TPS62132 -> +3V3_D
VSYS_MAIN -> TPS54302 -> +5V_PREISO
  -> independent +5V_PREISO_ADS filter -> RS3E -> ADS isolated rails
  -> independent +5V_PREISO_INA filter -> RS3 dual -> INA851 +/-5 V
```

`DGND` and `GND_ISO` remain galvanically separate. `BAT_NEG_RAW` is in the primary domain but is not the same schematic net as `DGND` because the Kelvin current shunt lies between them.

## USER POWER AND INDICATION

Normal user power control is deliberately downstream of the charger. Q4
`DMP3007LSS-13` is a 30 V P-channel SO-8 high-side switch between
`VSYS_PROT` and `VSYS_MAIN`. R102 (100 kOhm) returns its gate to the source, so
the default/unplugged state is OFF. Local maintained SW1 or a remote switch on
J11 closes `POWER_CTRL` to DGND through R103 (10 kOhm); C107 (100 nF) controls
the gate edge. The switch carries about 55-76 uA over 6.0-8.4 V, not load
current.

At a conservative hot RDS(on) of 15 mOhm, Q4 drop/loss is:

| Main current | Voltage drop | Q4 dissipation |
|---:|---:|---:|
| 1.0 A | 15 mV | 15 mW |
| 2.0 A | 30 mV | 60 mW |
| 3.3 A | 49.5 mV | 163 mW |

With SW1 OFF, BQ28Z610, STUSB4500 and BQ25798 remain operational and charging
continues; only `VSYS_MAIN` and the downstream R3 electronics are removed.
QON is separately connected to momentary SW2/J11.4 for ship exit, wake and the
documented long-hold reset. It is not the normal user power switch, and no
external ship FET is populated in Rev.A.

The red CHG indicator is powered from BQ25798 REGN through 2.2 kOhm and sinks
into raw open-drain `BQ_STAT_RAW`, so it works while `VSYS_MAIN` is off.
`CHARGE_STATUS` has a separate 10 kOhm pull-up to +3V3_D and reaches raw STAT
only through D7 `BAT54WS-7-F` (anode at logic, cathode at raw STAT). This
prevents the REGN/LED circuit from back-powering the main 3.3 V rail. The green
RUN indicator is powered from +3V3_D and therefore shows actual main-rail
operation. Battery level is software-derived from BQ28Z610 SOC/capacity over
PM I2C rather than an analog voltage LED bar.

J11 USER PANEL is primary-only: 1 +3V3_D, 2 DGND, 3 POWER_CTRL,
4 QON_SERVICE, 5 CHARGE_STATUS, 6 PG_3V3_D, 7 PM_I2C_SCL, 8 PM_I2C_SDA,
9 BQ_STAT_RAW and 10 SPARE/NC. It never carries GND_ISO or shared onboard LED
anode nets. Panel indicators require their own series resistors. POWER_CTRL is
for a latching contact to DGND only; QON_SERVICE is for a momentary contact to
DGND only.

## Charger and power-path comparison

| Candidate | Topology and strengths | Costs/risks | Result |
|---|---|---|---|
| TI BQ25798 | 3.6-24 V input, 1-4 cells, integrated four-switch buck-boost, integrated BATFET/current sensing, 5 A programmable charge, NVDC power path, DPM, I2C, ADC and NTC; 29-pin 4x4 mm QFN | fine-pitch QFN, firmware/register configuration, switching noise must be confined to Zone A; no per-cell balancing | **Implemented provisional recommendation**; works from 5 V and future 9/12 V PD without changing charger |
| TI BQ25713 | 1-4 cell buck-boost NVDC controller with external power MOSFETs; high power and repairable external switches | largest BOM/area, most high-current loops and gate-drive layout risk | Good for substantially higher power; unnecessarily complex for current R3 load |
| TI BQ24780S | SMBus narrow-VDC buck charger, suitable for 12 V PD to 2S and external FETs | cannot charge 2S from 5 V without another boost stage; external FET/BOM complexity | Lowest conversion complexity with mandatory 12 V PD, but loses useful 5 V fallback |

The BQ25798 is not treated as the BMS. Its charger protections do not replace independent per-cell OV/UV, short-circuit and pack-current protection.

## BMS, protection and balancing comparison

| Candidate | Coverage | Result |
|---|---|---|
| TI BQ28Z610 | 1-2S gauge, per-cell measurement, programmable voltage/current/temperature protection, high-side CHG/DSG N-FET drive, internal 200-ohm balancing paths, coulomb counter, I2C/SOC | **Implemented provisional recommendation** |
| TI BQ40Z50-R2 | 2-4S gauge/protector/balancer with more pins and pack-management features | technically capable but larger and unnecessarily complex for fixed 2S |
| TI BQ29209 plus separate protector/gauge | 2S overvoltage protection and balancing | incomplete by itself: still needs UV, current/short protection, current measurement and SOC; more ICs and validation |

The BQ28Z610 requires data-flash configuration and validation of OV, UV, overcurrent, short-circuit, temperature, recovery, balancing and FET behavior before it is safety-relevant.

### BQ28Z610 reference-network correction

The schematic now follows BQ28Z610EVM Figure 20 for the requested functions:

- `VC2` senses `BAT_POS_RAW`; `VC1` senses `CELL_MID`; VSS senses
  `BAT_NEG_RAW`;
- the retained 100 ohm Kelvin resistors feed the two VC pins;
- 100 nF is connected VC1-to-VSS for Cell1 and another 100 nF VC2-to-VC1
  for Cell2;
- the high-side N-FETs are common-drain: `PACK_POS -> Q2 DSG source`, common
  drains, then `Q3 CHG source -> BAT_POS_RAW`;
- each gate has the EVM-class 5.1 kOhm series resistor and 10 MOhm
  gate-to-local-source bias; each FET has 100 nF drain-source capacitance;
- the 10 mOhm Kelvin shunt, 100 ohm SRP/SRN resistors and 100 nF differential
  capacitor are retained.

U11 is only an unconnected DNP DRV0006A footprint-space reservation for a
possible future `BQ294502DRVR`/BQ2945xx secondary-overvoltage circuit. It is
not a populate-able or functional protection circuit and must not be fitted in
Rev.A. The exact threshold variant, cell RC network, OUT/fuse interface and
local bypass must be designed and reviewed before any future population.

### Q2/Q3 MOSFET study

Losses below use published **maximum** RDS(on) at 10 V and two series devices
at 25 C, matching the BQ28Z610 nominal 9.5 V drive more closely. Hot
resistance/PCB copper must still be validated.

| Candidate | VDS / package | Max RDS(on) @10 V | Pair loss @1 A | @3.3 A | @5 A | Comment |
|---|---|---:|---:|---:|---:|---|
| TI CSD17577Q3A | 30 V, SON 3.3 x 3.3 mm | 4.8 mOhm | 9.6 mW | 104.5 mW | 240 mW | **selected for Rev.A**; compact, 13 nC Qg |
| Vishay SiRA80DP | 30 V, PowerPAK SO-8 | 0.62 mOhm | 1.24 mW | 13.5 mW | 31.0 mW | lowest conduction loss; about 60 nC Qg |
| Vishay SQJA26EP | 30 V, PowerPAK SO-8L | 0.77 mOhm | 1.54 mW | 16.8 mW | 38.5 mW | AEC-Q101; larger package and gate charge |

`CSD17577Q3AT` is the fixed Rev.A pre-routing Q2/Q3 selection. The BQ28Z610 specifies
8.75-10.25 V FET-on drive over the relevant stack range, so the device's
4.8 mOhm maximum RDS(on) at 10 V is the correct nominal design point. Pair
loss is 9.6 mW at 1 A, 104.5 mW at 3.3 A and 240 mW at 5 A at 25 C. Its
13 nC typical gate charge is materially easier on the gauge's protected FET
drive than the roughly 60 nC SiRA80DP. A project-local DQG/VSON footprint is
assigned. Using 1.8x the 25 C maximum RDS(on) as a conservative hot estimate,
pair loss is 17.3 mW at 1 A, 188 mW at 3.3 A and 432 mW at 5 A. Reserve at
least 200 mm2 combined L1 spreading copper and 4-6 x 0.30 mm finished thermal
vias per FET into primary copper. SOA/short-circuit interruption and assembly
yield remain validation gates, not component-selection blockers.

## USB-C and PD implementation

`STUSB4500QTR` is now the provisional standalone PD sink. It negotiates without
the MCU, is powered from protected connector-side VBUS, and uses the documented
`CC1DB->CC1` / `CC2DB->CC2` dead-battery wiring. Legacy R70/R71 standalone Rd
resistors are removed. USB data remains unused.

The programmed logical NVM profile is:

| PDO | Voltage/current | Use |
|---|---|---|
| PDO1 | 5 V / 3 A maximum capability | Type-C/PD fallback; actual draw remains source-capability limited |
| PDO2 | 9 V / 2 A | secondary PD fallback |
| PDO3 | 12 V / 2 A | preferred R3 contract |

No 15 V or 20 V PDO is advertised. `RESET` is tied directly to `DGND`.
`POWER_OK_CFG=10b` selects ST power-OK configuration 2: `POWER_OK3` is
active-low only after a successful PDO3 contract and PS_READY, so it is valid
as `PD_CONTRACT_12V_N`; `ALERT` is exported as `PD_ALERT_N`. The exact NVM record,
programming and recovery procedure are in `docs/STUSB4500_PD_CONFIG.md`.

Before any confirmed contract/source capability, the BQ25798 243 kOhm/100 kOhm
ILIM_HIZ divider enforces about 0.50 A. Firmware may clear `EN_EXTILIM` and
increase IINDPM only after reading the STUSB4500 state: 1.35 A for confirmed
5 V/1.5 A, 2.25 A for confirmed 5 V/3 A, and 1.80 A for 9 V/2 A or 12 V/2 A.
The 2.25 A cap deliberately stays below the approximately 2.5 A TPS2121 ILIM
and current F2 design class; the 12 V/2 A policy is unchanged.

## Input and power-path behavior

TPS2121 combines the USB input and the retained J1 service/bench input. It supports 2.8-22 V, reverse-current blocking, seamless switchover and programmable current limiting. R73 currently targets about 2.5 A typical. J1 keeps its PTC, reverse-polarity PMOS, TVS and filter, but is now explicitly an alternate charger input rather than a fixed 9 V system rail. D1 and USB D3 are Bourns-class SMBJ13A: 13 V VRWM, 14.4-15.9 V breakdown and 21.5 V maximum clamp at 28 A for a 10/1000 us pulse. At the documented 10 A design surge assumption, linear interpolation gives about 17.9 V, leaving about 4.1 V to the TPS2121 22 V recommended maximum; even the TVS-rated 28 A clamp remains 0.5 V below that recommended maximum and 2.5 V below the 24 V absolute maximum.

BQ25798 has a distinct local VBUS bypass bank of 100 nF plus three 10 uF/25 V ceramics. The 100 nF part is a 0402 intended directly at the VBUS/GND pins; C73 remains TPS2121 output bulk and is not counted as this bypass.

BQ25798 NVDC power-path supplies R3:

- from external input with battery absent;
- from battery with external input absent;
- while charging;
- with input-current/voltage DPM and battery supplement behavior during source overload.

## Temperature sensing

One NTC cannot be connected directly to both BQ28Z610 TS1 and BQ25798 TS because each IC biases its input. The schematic therefore provides:

- J8 pin 4: `NTC_BMS` for BQ28Z610;
- J9: separate `NTC_CHG` and `DGND` return for BQ25798. On PCB this conductor is named/treated as `DGND_CHG_SENSE`: a quiet Kelvin return to the charger ground area, never to `BAT_NEG_RAW` on the battery side of the shunt.

Rev.A therefore uses two separate SEMITEC `103AT-2` probes: 10.0 kOhm at
25 C, B25/85=3435 K, both resistance and B-value tolerance 1%. The harness
entries are recorded in `bom/R3_power_harness_bom.csv`; the probes are not
shared or passively paralleled.

## Battery and MCU telemetry

The BQ28Z610 exposes cell voltages, pack voltage, current, temperature and SOC over primary-side `PM_I2C_SCL/SDA`. These correspond to `CELL1_VOLTAGE`, `CELL2_VOLTAGE`, `BAT_VOLTAGE`, `BAT_CURRENT`, `BAT_TEMPERATURE` and `SOC`; duplicate analog dividers were not added.

J10 exports:

1. `+3V3_D`
2. `DGND`
3. `PM_I2C_SCL`
4. `PM_I2C_SDA`
5. `CHARGE_STATUS`
6. `PG_3V3_D` as system power-good
7. `CHARGER_INT_FAULT`
8. `INPUT_SOURCE_STATUS`
9. `PD_ALERT_N`
10. `PD_CONTRACT_12V_N`

J11 exports the primary user-panel interface documented above. Pin 9 is the
raw open-drain charger status, not a shared LED-anode feed, and J11 contains no
GND_ISO.

BQ28Z610 has no dedicated general fault interrupt pin. Critical faults autonomously control CHG/DSG FETs; detailed status is read over I2C. If the MCU requires a separate hardware BMS fault line, an additional supervisor or FET-state detector is still open.

## Power budget assumptions

The expected table is an engineering planning case, not a measured result. It assumes STM32/ESP32/SD average digital load of 0.85 A at 3.3 V, about 0.8 W into the ADS isolated converter, and about 0.25 W no/light-load input for the INA converter. Peak is a plausible simultaneous activity case. Design worst case is the sum of converter nameplate limits and is not an intended operating mode.

### A. Design worst case

| Rail | Voltage | Worst current | Output power | Assumed efficiency | Upstream input/current | Thermal estimate |
|---|---:|---:|---:|---:|---:|---:|
| `VSYS_PROT` | 6.0-8.4 V | 3.30 A at 6 V equivalent | 19.8 W input demand | - | battery: 3.30 A at 6 V | wiring/FET/shunt case, not normal load |
| `VSYS_MAIN` | 6.0-8.4 V minus Q4 drop | 3.30 A at 6 V equivalent | 19.8 W demand | Q4 >99% | from VSYS_PROT | about 0.163 W at 3.3 A using 15 mOhm hot estimate |
| `+3V3_D` | 3.3 V | 3.00 A | 9.90 W | 90% planning | 11.0 W from VSYS | about 1.1 W converter loss |
| `+5V_PREISO` | 5.0 V | 1.59 A | 7.95 W | 90% planning | 8.83 W from VSYS | about 0.88 W buck loss |
| `+5V_PREISO_ADS` | 5.0 V | 0.80 A nominal / 0.889 A at U3 4.5 V limit | 4.0 W input | branch loss negligible | U3 limited to 3 W output | bead rated 2 A |
| `+5V_PREISO_INA` | 5.0 V | 0.789 A nominal / 0.877 A at U6 4.5 V limit | 3.95 W input | branch loss negligible | U6 limited to 3 W output | bead rated 2 A |
| `+5V_ISO_RAW` | 5.0 V | 0.60 A | 3.00 W | U3 75% typical | 4.0 W from ADS branch | about 1.0 W U3 loss |
| `+5V_ISO_A` | 5.0 V | 0.30 A allocation | 1.50 W | filter | from U3 shared 3 W | measure bead rise |
| `+5V_ISO_D` | 5.0 V | 0.30 A allocation | 1.50 W | filter | from U3 shared 3 W | measure bead rise |
| `+3V3_A_ISO` | 3.3 V | 0.30 A planning cap | 0.99 W | LDO | 1.50 W at 5 V | about 0.51 W LDO loss |
| `+3V3_D_ISO` | 3.3 V | 0.30 A IC limit | 0.99 W | LDO | 1.50 W at 5 V | about 0.51 W LDO loss |
| `+5V_INA` | +5.0 V | 0.30 A converter rating | 1.50 W | U6 combined 76% minimum | shared with negative rail | not a valid INA851 load case |
| `-5V_INA` | -5.0 V | 0.30 A converter rating | 1.50 W | U6 combined 76% minimum | shared with positive rail | not a valid INA851 load case |

### B. Expected R3 load

| Rail | Expected current | Peak current | Expected power | Efficiency/input estimate | Approximate local loss |
|---|---:|---:|---:|---:|---:|
| `VSYS_PROT` | 0.59 A at 7.4 V | 1.08 A at 7.4 V | 4.4 W expected / 8.0 W peak | battery path | shunt 3.5 mW expected |
| `VSYS_MAIN` | 0.59 A at 7.4 V | 1.08 A at 7.4 V | 4.4 W expected / 8.0 W peak | Q4 >99% | about 5.2 mW expected / 17.5 mW peak using 15 mOhm |
| `+3V3_D` | 0.85 A | 1.50 A | 2.81 W | 90%; about 3.12 W input | about 0.31 W expected |
| `+5V_PREISO` | 0.21 A | 0.44 A | 1.05 W | 90%; about 1.17 W input | about 0.12 W expected |
| `+5V_PREISO_ADS` | 0.16 A | 0.35 A | 0.80 W | feeds U3 | bead loss negligible at expected load |
| `+5V_PREISO_INA` | 0.05 A | 0.10 A | 0.25 W | dominated by U6 light-load draw | validate on bench |
| `+5V_ISO_RAW` | 0.12 A | 0.25 A | 0.60 W | about 75% U3 | about 0.20 W expected |
| `+5V_ISO_A` | 0.08 A | 0.15 A | 0.40 W | ADM7150 input | filter loss small |
| `+5V_ISO_D` | 0.04 A | 0.10 A | 0.20 W | TPS7A20 input | filter loss small |
| `+3V3_A_ISO` | 0.08 A | 0.15 A | 0.264 W | LDO | about 0.136 W expected |
| `+3V3_D_ISO` | 0.04 A | 0.10 A | 0.132 W | LDO | about 0.068 W expected |
| `+5V_INA` | 6 mA | 20 mA | 30 mW | U6 light-load operation | included in U6 idle loss |
| `-5V_INA` | 6 mA | 20 mA | 30 mW | U6 light-load operation | included in U6 idle loss |

### Battery current

| Battery voltage | Expected 4.4 W | Peak 8.0 W | Design-worst 19.8 W |
|---:|---:|---:|---:|
| 8.4 V | 0.52 A | 0.95 A | 2.36 A |
| 7.4 V | 0.59 A | 1.08 A | 2.68 A |
| 6.0 V | 0.73 A | 1.33 A | 3.30 A |

## Battery-path sizing target

Based on expected peak rather than only regulator nameplates:

- keyed battery connector: at least 5 A/contact system rating with suitable wire;
- BMS path and protection FETs: 5 A continuous design target, at least 8-10 A short transient capability, at least 20 V VDS;
- shunt: 10 mOhm, 1 W, Kelvin connected; 0.25 W at 5 A;
- battery/system copper: size for 5 A local path and temperature rise, not for average current only;
- TPS2121 input mux: 2.5 A typical current-limit target in current draft;
- F1 service input: Bourns `MF-R250-0-10`, 30 V, 2.50 A hold/5.00 A trip at
  23 C, 1.70 A hold at 60 C, radial 5.1 mm pitch;
- F2 USB input: Bourns `MF-MSMF260/16X-2`, 16 V, 2.60 A hold/5.00 A trip at
  23 C, 2.00 A hold at 60 C, 1812;
- F3 system rail: Bourns `MF-MSMF250/16X-2`, 16 V, 2.50 A hold/5.00 A trip at
  23 C, 1.85 A hold at 60 C, 1812;
- charge/input connector and protection: minimum 3 A if 5 V fallback is used near its useful limit.

The PPTCs are fixed for Rev.A placement/BOM, but hot sustained current is still
a validation gate. In particular, the 2.25 A confirmed 5 V/3 A firmware policy
exceeds F2's 60 C hold value; charger thermal/DPM derating or a separately
reviewed fuse option is required if that combination must be continuous.

## Charge-current examples

Assuming 90% conversion efficiency and 4.4 W simultaneous expected system
load, required adapter input is `(VBAT * ICHG + 4.4 W) / 0.90`:

| VBAT | 1 A charge input power / current at 12 V | 2 A charge input power / current at 12 V |
|---:|---:|---:|
| 6.0 V | 11.56 W / 0.96 A | 18.22 W / 1.52 A |
| 7.4 V | 13.11 W / 1.09 A | 21.33 W / 1.78 A |
| 8.4 V | 14.22 W / 1.19 A | 23.56 W / 1.96 A |

The 12 V/2 A contract is limited in firmware to 1.80 A (21.6 W) for margin.
It supports 2 A charging at low/mid state of charge with expected system load,
but cannot maintain a full 2 A near 8.4 V or during the 8 W system peak. Input
DPM must reduce charge current; battery supplement may carry brief system peaks.
At 9 V/2 A with a 1.80 A policy limit, only 16.2 W is available, so 2 A charge
is not sustainable and even 1 A charge must be power-managed at peak load.
Unknown 5 V starts at 0.50 A (2.5 W), which may require battery supplement and
does not guarantee charging. Confirmed 5 V/1.5 A or 3 A may use the documented
1.35 A or 2.25 A limits, respectively.

Charge current remains programmable and is not frozen until cell capacity, allowed C-rate, connector temperature and enclosure cooling are known.

## Test points

New dirty-side test points:

- TP20 `USB_VBUS_RAW`
- TP21 `CHARGER_IN`
- TP22 `VSYS_RAW`
- TP23 `VSYS_PROT`
- TP24 `BAT_POS_RAW`
- TP25 `CELL_MID`
- TP26 `BAT_NEG_RAW`
- TP27 `BMS_SRP_FILT`
- TP28 `BMS_SRN_FILT`
- TP29 `NTC_BMS`
- TP30 `NTC_CHG`
- TP31 `USB_CC1`
- TP32 `USB_CC2`
- TP33 `USB_VBUS_PROT`
- TP34 `PD_VDD` (fed from protected VBUS through the 0 ohm R85 link)
- TP35 `PD_VREG_2V7`
- TP36 `PD_ALERT_N`
- TP37 `PM_I2C_SCL`
- TP38 `PM_I2C_SDA`
- TP39 `QON_SERVICE`
- TP40 `VSYS_MAIN`

Existing primary and isolated test points are retained. Dirty and clean points belong on opposite physical areas.

## PCB floorplan and layers

The PCB draft uses four explicit spatial zones:

```text
DIRTY EDGE                     MIDDLE                    CLEAN EDGE
+----------------------+----------------+-----------+----------------------+
| USB-C / J1 / battery | TPS62132       | RS3E/RS3  | ADM7150 / TPS7A20    |
| TPS2121 / BQ25798    | TPS54302       | isolation | clean filters        |
| BQ28Z610 / FET/shunt | Q4 / J10 / J11 | keep-out  | ADS/INA connectors   |
+----------------------+----------------+-----------+----------------------+
```

Charger SW1/SW2 and L3 stay entirely inside Zone A. TPS62132/TPS54302
switching loops stay in Zone B. U3/U6 pins 1/2/3 face primary and pins
5/6/7/8 face clean. The full-height x=121...124 mm rule area blocks pads,
vias, tracks and pours on all four copper layers. The SIP8 geometry provides
3.08 mm edge-to-edge between pad 3 and pad 5, so the adopted rule is 3.0 mm
minimum copper clearance and board-surface creepage. This is a low-voltage
functional-isolation rule, not a mains/reinforced certification claim.

A four-layer board is recommended:

- L1 components/signals and compact switching loops;
- L2 continuous primary DGND plane, interrupted only by the isolation corridor;
- L3 power distribution/quiet routing with no copper under the barrier;
- L4 secondary routing and clean ground/power areas.

Four layers improve return-path control, EMI and heat spreading enough to
justify the added cost. No thermal copper, plane or via may cross the isolation
corridor. L3 charger, L1 TPS62132 and L2 TPS54302 are alternately oriented;
U3/U6 are vertically separated from that magnetic group and from the clean
LDOs. Board size remains 160 x 80 mm.

## Mechanical mounting and future R3 stacking

The PowerBox now has six 3.20 mm NPTH M3 holes with no electrical net or
plating. Their coordinates are H1 (35.0,25.5), H2 (174.5,25.5), H3
(25.5,94.5), H4 (174.5,94.5), H5 (115.0,25.5) and H6 (135.0,94.5). Every
hole includes an 8 mm all-copper-layer keepout/courtyard. No hole or hardware
enters the x=121...124 mm functional-isolation corridor; insulating standoffs
are the prototype default.

Cable assembly remains fully supported. Optional DNP J12 (primary 2x8) and J13
(isolated 2x5) provide parallel generic 2.54 mm THT stacking interfaces without
mixing DGND and GND_ISO. The future-R3 envelope is a `Dwgs.User` reference only.
Use 15 mm standoffs as the baseline because U3/U6 are 11.1 mm high; 12 mm is
conditional on an upper-board cutout/keepout. Exact dimensions, pinouts and
header/socket guidance are maintained in
`docs/R3_BOARD_TO_BOARD_INTERFACE.md`.

## Open technical decisions and blockers

1. Program and compliance-test the provisional STUSB4500 5/9/12 V NVM profile and firmware current-limit policy.
2. Validate CSD17577Q3AT protection-event SOA/turn-off and the specified
   thermal-copper implementation at 5 A/hot conditions.
3. Validate both 103AT-2 harness locations and temperature thresholds.
4. Freeze battery chemistry/capacity and program/validate BQ28Z610 protection, balancing, recovery and gauge parameters.
5. Validate BQ25798/BQ28Z610/STUSB4500 shared-bus interoperability and the boot-safe 0.50 A charger default.
6. Bench-test TPS54302 5 V regulation and transients at VSYS = 6.0 V.
7. Resolve RS3-0505D/H3 light-load and rail-balance behavior for INA851.
8. Measure expected/peak loads and hot ambient, then validate the fixed
   F1/F2/F3 choices, connector contacts and copper widths.
9. Decide whether the reserved BQ2945xx secondary-OV footprint is populated; its active network is intentionally DNP/unconnected in Rev.A.
10. Check J3/J10/J11 mating-housing, latch, enclosure and cable-bend clearances in
    mechanical CAD.
11. Freeze J12/J13 long-post header/socket MPNs and verify engagement at the
    selected 15 mm spacing; validate the M3 hardware diameter against the 8 mm
    local keepouts.

PCB routing and production outputs remain blocked until these decisions are closed.

## Original manufacturer references

- TI TPS62132: https://www.ti.com/lit/ds/symlink/tps62132.pdf
- TI TPS54302: https://www.ti.com/lit/ds/symlink/tps54302.pdf
- TI TPS2121: https://www.ti.com/lit/ds/symlink/tps2121.pdf
- TI BQ25798: https://www.ti.com/lit/ds/symlink/bq25798.pdf
- TI BQ28Z610: https://www.ti.com/lit/ds/symlink/bq28z610.pdf
- TI BQ25713 candidate: https://www.ti.com/lit/ds/symlink/bq25713.pdf
- TI BQ24780S candidate: https://www.ti.com/lit/ds/symlink/bq24780s.pdf
- ST STUSB4500: https://www.st.com/resource/en/datasheet/stusb4500.pdf
- TI BQ28Z610EVM: https://www.ti.com/lit/ug/sluube3/sluube3.pdf
- Bourns SMBJ series: https://www.bourns.com/data/global/pdfs/SMBJ.pdf
- Bourns MF-R: https://www.bourns.com/docs/product-datasheets/mf-r.pdf
- Bourns MF-MSMF: https://www.bourns.com/docs/product-datasheets/mf-msmf.pdf
- SEMITEC 103AT-2: https://www.semitec-global.com/products/thermistor_at/
- TI CSD17577Q3A: https://www.ti.com/lit/ds/symlink/csd17577q3a.pdf
- ST ESDA25W: https://www.st.com/resource/en/datasheet/esdaxxxwx.pdf
- TI TPS25750 candidate: https://www.ti.com/lit/ds/symlink/tps25750.pdf
- Infineon CYPD3177 candidate product page: https://www.infineon.com/part/CYPD3177-24LQXQ

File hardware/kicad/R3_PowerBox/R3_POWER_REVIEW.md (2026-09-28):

# R3 PowerBox review

Review date: 2026-09-28
Status: final UI / power-control / DRC pass complete; **routing remains blocked by the validation items below**.

The editable electrical source is `tools/generate_hierarchical.py`. Generated KiCad sheets, PDF and BOM are derived artifacts. The detailed battery decision record and budgets are in `R3_BATTERY_POWER_ARCHITECTURE.md`.

## Implemented in this pass

- Added a normal user load switch after F3: `VSYS_PROT -> Q4 -> VSYS_MAIN`.
  Q4 is `DMP3007LSS-13`, a 30 V P-channel SO-8 MOSFET. Its 100 kOhm
  gate-source resistor makes the default state OFF; SW1 closes only the
  low-current gate-control path through 10 kOhm, and C107 provides controlled
  turn-on. BMS, STUSB4500 and BQ25798 stay upstream, so charging continues
  while R3 main electronics are off.
- Corrected the invalid/ambiguous old `DMP3010LSS` reverse-polarity MPN to the
  verified P-channel `DMP3007LSS-13` for Q1 and added a project-local SO-8
  footprint with the physical 1-3=S, 4=G, 5-8=D mapping.
- Connected BQ25798 QON to local momentary SW2 and `QON_SERVICE`; QON remains a
  ship/wake/service input and is not used as normal ON/OFF.
- Added `LED_CHARGE` from REGN through 2.2 kOhm to raw open-drain
  `BQ_STAT_RAW`, and `LED_RUN` from switched `+3V3_D`. `CHARGE_STATUS` is now
  a separate 3.3 V logic net isolated from raw STAT by D7. Added ten-pin
  primary-only J11 for the user panel and SOC/I2C expansion.
- Cleared all 18 copper-to-edge, 8 drill-range, 4 annular-width and 20
  footprint-internal-clearance DRC findings. USB-C moved 1.8 mm inward from
  its original provisional origin; U1/U7 use non-via land patterns, with
  0.30/0.70 mm thermal vias reserved for routing. The project fine-pitch
  minimum is 0.13 mm versus the selected 4-layer process capability of
  0.09 mm; use 0.20 mm wherever density permits.

- Replaced service-input D1 and USB VBUS D3 with `SMBJ13A` (13 V VRWM,
  14.4-15.9 V VBR, 21.5 V clamp at 28 A/10-1000 us). At the 10 A design surge
  assumption the interpolated clamp is about 17.9 V, below TPS2121's 22 V
  recommended and 24 V absolute maximum limits.
- Corrected BQ28Z610 2S VC wiring to the TI pin definitions: `BAT_POS_RAW`
  through 100 ohm to VC2, `CELL_MID` through 100 ohm to VC1, and
  `BAT_NEG_RAW` to VSS. Cell filters are 100 nF VC1-VSS (Cell1) and 100 nF
  VC2-VC1 (Cell2).
- Rebuilt Q2/Q3 as the TI-EVM common-drain pair: DSG FET on PACK side, CHG FET
  on cell side, 5.1 kOhm gate resistors, 10 MOhm gate-source bias and 100 nF
  drain-source capacitors. Q2/Q3 are fixed as `CSD17577Q3AT` in the
  project-local 3.3 x 3.3 mm DQG/VSON footprint.
- Changed J9 pin 2 from `BAT_NEG_RAW` to `DGND`. Layout must implement the
  conductor as quiet `DGND_CHG_SENSE` direct to the BQ25798 ground area.
- Added BQ25798-local VBUS bypass: 100 nF 0402 plus three 10 uF/25 V ceramics.
- Added `STUSB4500QTR` autonomous PD sink, documented dead-battery CC wiring,
  ESDA25W CC protection, 5/9/12 V PDO record, PD test points and J10 PD status.
- Removed legacy independent 5.1 kOhm CC Rd resistors.
- Changed BQ25798 ILIM_HIZ divider to 243 kOhm/100 kOhm for approximately
  0.50 A hardware default until a source contract is confirmed.
- Marked U11 explicitly as an unconnected DNP footprint-space reservation,
  not a functional BQ294502 secondary-overvoltage circuit.
- Tied STUSB4500 RESET directly to `DGND`; PDO3 remains 12 V/2 A and
  `POWER_OK_CFG=10b` maps POWER_OK3 only to a successful PDO3 contract after
  PS_READY.

The earlier architecture items below remain valid unless superseded by this
correction list.

- Fixed the product architecture at 2S Li-ion, 6.0-8.4 V preliminary range and 8.4 V charge voltage.
- Renamed fixed-9-V system nets to `VSYS_RAW` and `VSYS_PROT`.
- Retained J1 and its protection as a 6-12 V service/bench charger input, not as the battery/system rail.
- Retained the USB protection/TPS2121 input mux and upgraded the USB-C input to autonomous 5/9/12 V PD with safe 5 V fallback.
- Added provisional BQ25798 1-4S buck-boost NVDC charger/power-path, configured as a 2S architecture.
- Added 4-pin keyed 2S connector with `BAT_POS_RAW`, `CELL_MID`, `BAT_NEG_RAW`, `NTC_BMS` and an optional separate charger-NTC connector.
- Added provisional BQ28Z610 1-2S gauge/protector with per-cell monitoring, internal balancing, CHG/DSG high-side FET control and a 10 mOhm Kelvin shunt.
- Added primary-side I2C and charger/status telemetry connector J10.
- Preserved the existing TPS62132, TPS54302, independent ADS/INA pre-isolation filters, RS3E, RS3 dual, ADM7150 and TPS7A20 architecture.
- Removed the TPS54302 8-V reference-design EN divider because it blocked the 6-8.4 V 2S range; EN now follows `VSYS_PROT` and battery cutoff belongs to the BMS.
- Added battery, cell, NTC, shunt, charger-input and VSYS test points.
- Added a reproducible preliminary placement inside the DIRTY -> PRIMARY ->
  ISOLATION -> CLEAN floorplan and retained the isolation copper/via/pad
  keepout. No routing, vias or copper pours were added.
- Converted the board definition to four copper layers and extended the
  3.0 mm isolation keepout across every copper layer and the entire board
  height. U3/U6 primary pins face DGND and secondary pins face GND_ISO.
- Fixed Rev.A protection/temperature choices: F1 `MF-R250-0-10`, F2
  `MF-MSMF260/16X-2`, F3 `MF-MSMF250/16X-2`, and two independent SEMITEC
  `103AT-2` NTC probes.

## Current power tree

```text
USB-C 5/9/12 V -- F2/SMBJ13A/STUSB4500 --+
                                  +-> TPS2121 -> CHARGER_IN
J1 service 6-12 V -- existing protection --+

2S cells -> BQ28Z610 / CHG+DSG FETs / shunt -> PACK_POS + DGND

CHARGER_IN + PACK_POS -> BQ25798 NVDC charger/power-path
                       -> VSYS_RAW -> F3 MF-MSMF250/16X-2 -> VSYS_PROT
                       -> Q4 DMP3007LSS / SW1 -> VSYS_MAIN

VSYS_MAIN -> TPS62132 -> +3V3_D
VSYS_MAIN -> TPS54302 -> +5V_PREISO
  -> FB6/C26/C27 -> +5V_PREISO_ADS -> RS3E -> isolated ADS rails
  -> FB7/C28/C29 -> +5V_PREISO_INA -> RS3 dual -> isolated INA rails

DGND || galvanic isolation || GND_ISO
```

## Direct 2S verification

- TPS62132: 3-17 V input and 100% duty mode; direct 2S operation is supported.
- TPS54302: 4.5-28 V input and internal UVLO below the 2S range. Required duty at 6.0 V to make 5.0 V is 83.3%. Direct operation is retained, but TI does not publish a guaranteed 5 V/3 A dropout curve at 6 V, so low-battery load/transient bench validation is mandatory.
- No 2S-to-9 V converter was added.

## New IC/package verification

| Part | Verified manufacturer pin/package summary |
|---|---|
| TPS2121RUXR | RUX VQFN-HR-12: OUT 1/8, IN2 2, CP2 3, OV2 4, OV1 5, PR1 6, IN1 7, ST 9, ILIM 10, SS 11, GND 12; 2.8-22 V, 24 V absolute maximum, 4.5 A class |
| BQ25798RQM | RQM VQFN-29 4x4 mm: exact pins 1-29 captured from TI Table 5-1; 3.6-24 V, 1-4S, 5 A charge, integrated buck-boost and NVDC BATFET power path |
| BQ28Z610DRZR | DRZ VSON-12+EP: VSS 1, SRN 2, SRP 3, TS1 4, SCL 5, SDA 6, DSG 7, PACK 8, CHG 9, PBI 10, VC2 11, VC1 12, EP 13; 1-2S gauge/protection/balancing |
| STUSB4500QTR | QFN-24 EP: official KiCad/ST pin mapping verified; VDD 4.1-22 V, VSYS 3.0-5.5 V, VBUS pins 28 V tolerant, CC short-to-VBUS protection to 22 V, 3 NVM PDOs and dead-battery operation |
| DMP3007LSS-13 | 30 V P-channel SO-8; 10 mOhm maximum RDS(on) at VGS=-4.5 V; project footprint maps physical 1-3=S, 4=G, 5-8=D to the logical PMOS symbol |

STUSB4500 `RESET` is tied directly to `DGND`. The NVM definition uses PDO3 =
12 V/2 A and `POWER_OK_CFG=10b`; consequently `PD_CONTRACT_12V_N` is low only
after PDO3 is selected and the source completes the transition with PS_READY.

Original TI datasheets are assigned in each symbol. The BQ28Z610 project
footprint follows TI DRZ0012A dimensions. Q2/Q3 are fixed as
`CSD17577Q3AT`; the project DQG footprint maps the physical gate, source and
drain lands to the existing logical three-pin symbol.

## Connectors

| Connector | Function/pinout |
|---|---|
| J1 | service/bench input: 1 `SERVICE_IN_RAW`, 2 `DGND` |
| J2 | digital power: two `+3V3_D`, two `DGND`, `PG_3V3_D`, NC |
| J3 | isolated rails with repeated `GND_ISO`, unchanged |
| J4 | `DGND`, `PG_3V3_D`, `CTRL_RS3E_PRI`, NC |
| J5/J6 | primary/isolated AUX DNP, unchanged |
| J7 | USB-C PD input; CC1/CC2 owned by STUSB4500 with CCxDB dead-battery connections; data pins unused |
| J8 | keyed 2S battery: `BAT_POS_RAW`, `CELL_MID`, `BAT_NEG_RAW`, `NTC_BMS` |
| J9 | optional separate `NTC_CHG`, `DGND` quiet/Kelvin charger return |
| J10 | `+3V3_D`, `DGND`, PM I2C, charge status, `PG_3V3_D`, charger fault/interrupt, input-source status, `PD_ALERT_N`, `PD_CONTRACT_12V_N` |
| J11 | user panel: 1 `+3V3_D`, 2 `DGND`, 3 `POWER_CTRL`, 4 `QON_SERVICE`, 5 `CHARGE_STATUS`, 6 `PG_3V3_D`, 7/8 PM I2C SCL/SDA, 9 `BQ_STAT_RAW`, 10 SPARE/NC |

No connector contains both `DGND` and `GND_ISO`.

## New test points

TP20 USB VBUS raw, TP21 charger input, TP22 VSYS raw, TP23 VSYS protected,
TP24 battery positive, TP25 cell midpoint, TP26 battery negative, TP27/TP28
filtered Kelvin shunt sense, TP29 BMS NTC, TP30 charger NTC, TP31/TP32 CC1/CC2,
TP33 protected USB VBUS, TP34 PD VDD, TP35 PD 2.7 V regulator, TP36 PD alert
and TP37/TP38 PM I2C. All existing primary and isolated test points remain.

## Budget summary

- Expected R3 system input: approximately 4.4 W.
- Expected battery current: 0.52 A at 8.4 V, 0.59 A at 7.4 V, 0.73 A at 6.0 V.
- Plausible peak case: approximately 8 W, or 0.95/1.08/1.33 A at 8.4/7.4/6.0 V.
- Converter-nameplate design worst case: approximately 19.8 W, or 2.36/2.68/3.30 A. This is a sizing bound, not the expected R3 operating load.
- Proposed battery path target: 5 A connector/FET/shunt/copper class. F3 is
  `MF-MSMF250/16X-2`: 2.50 A hold at 23 C and 1.85 A at 60 C, so the measured
  peak current/temperature gate remains mandatory.
- With 4.4 W system load and 90% conversion, 1 A charging needs 0.96/1.09/1.19 A from 12 V at BAT=6.0/7.4/8.4 V. A 2 A setting needs 1.52/1.78/1.96 A. The 12 V/2 A contract policy limits IINDPM to 1.80 A, so DPM must reduce charge near full battery and during system peaks.

### PD/source current policy

| Confirmed source | BQ25798 input limit | Available input power | Charging consequence with expected 4.4 W system load |
|---|---:|---:|---|
| unknown 5 V / no PD | 0.50 A hardware | 2.5 W | system may need battery supplement; charging not guaranteed |
| confirmed 5 V/1.5 A | 1.35 A | 6.75 W | slow charging only |
| confirmed 5 V/3 A | 2.25 A | 11.25 W policy cap | reduced charging; kept below TPS2121/F2 approximately 2.5 A hardware class |
| 9 V/2 A PD | 1.80 A | 16.2 W | 1 A charge expected; 2 A not sustainable |
| 12 V/2 A PD | 1.80 A | 21.6 W | 2 A possible at low/mid BAT; reduced near 8.4 V/peak load |

## Technical issues not silently hidden

1. **PD configuration:** STUSB4500 is implemented, but its NVM must be programmed/read back and USB-PD behavior verified with an analyzer before higher IINDPM values are enabled.
2. **Dual temperature inputs:** Rev.A uses two independent SEMITEC `103AT-2`
   probes (10.0 kOhm at 25 C, B25/85=3435 K, 1%). `NTC_BMS` terminates at
   the pack/BQ28Z610 reference; `NTC_CHG` returns quietly to charger DGND.
3. **BMS configuration:** BQ28Z610 safety and gauge data-flash values, chemistry profile, recovery and balancing require configuration and test.
4. **MOSFETs:** Q2/Q3 use the final pre-routing `CSD17577Q3AT` selection and a
   project-local DQG/VSON footprint. BQ28Z610 drives approximately 9.5 V, so
   the relevant 10 V maximum RDS(on) is 4.8 mOhm: pair conduction loss is
   9.6 mW at 1 A, 104.5 mW at 3.3 A and 240 mW at 5 A at 25 C. Using a
   conservative 1.8x hot-resistance multiplier gives 17.3 mW, 188 mW and
   432 mW for the pair. Reserve at least 200 mm2 combined L1 spreading copper
   and 4-6 0.30 mm finished thermal vias per FET into primary copper. Protection
   event SOA/turn-off and assembly yield still require validation.
   Distributor check on 2026-09-28 found CSD17577Q3AT stocked at Mouser; the
   part is active, but procurement must recheck stock at release time.
5. **TPS54302 dropout:** verify 5 V regulation, startup and load steps at `VSYS=6.0 V`.
6. **INA isolated supply:** RS3-0505D/H3 light-load regulation and rail balance remain unresolved.
7. **BMS hardware fault signal:** BQ28Z610 has autonomous FET protection and I2C status but no general alert pin. Add an external supervisor only if the MCU requires a dedicated fault wire.
8. **PPTC temperature:** F1/F2/F3 are fixed for Rev.A placement and BOM, but
   their hold current derates with ambient. At 60 C F1 is 1.70 A, F2 is
   2.00 A and F3 is 1.85 A. The 5 V/3 A firmware policy remains 2.25 A, so
   sustained hot operation must invoke charger thermal/DPM derating or use a
   separately reviewed non-resettable-fuse option.
   MF-MSMF250/16X-2, MF-MSMF260/16X-2 and MF-R250-0-10 were stocked at
   authorized distributors on 2026-09-28; purchasing must preserve the exact
   F1 5.1 mm lead-style suffix.

## USER POWER AND INDICATION

- **Normal OFF:** SW1 open lets R102 pull Q4 gate to `VSYS_PROT`; Q4 is off,
  `VSYS_MAIN`, TPS62132, TPS54302 and all R3 main loads are de-energized.
  BQ28Z610, STUSB4500 and BQ25798 remain connected to their upstream rails.
- **Normal ON:** SW1 closes `POWER_CTRL` to DGND through R103. At 8.4 V the
  control current is about 76 uA; no 3-5 A load current crosses SW1. C107/R103
  controls the gate edge. Q4 logical pin 2/physical pins 1-3 are the source on
  `VSYS_PROT`; logical pin 3/physical pins 5-8 are the drain on `VSYS_MAIN`.
- **Loss:** using a conservative hot 15 mOhm Q4 resistance gives 15/30/49.5 mV
  drop and 15/60/163 mW at 1/2/3.3 A. Even the 3.3 A design-worst case is
  modest for SO-8 with local top copper; verify temperature on the prototype.
- **Charge while OFF:** BQ25798 SYS/charger and STAT are upstream of Q4, so
  charging and LED_CHARGE remain functional with `VSYS_MAIN` off.
- **QON/ship mode:** SW2 or J11.4 momentarily pulls the internally biased QON
  pin low. Rev.C uses the programmed 1 s default or 15 ms `WKUP_DLY` interval
  to exit ship mode; an approximately 10 s low requests system-power reset.
  No external ship FET is fitted in Rev.A.
- **CHARGE LED:** REGN -> R104 2.2 kOhm -> red D5 -> `BQ_STAT_RAW`. Expected current is
  about 1.3 mA. Charging=ON, complete/disabled/battery-only=OFF, fault=1 Hz
  blink. R80 pulls the separate `CHARGE_STATUS` net to switched +3V3_D, while
  D7 `BAT54WS-7-F` connects anode=`CHARGE_STATUS`, cathode=`BQ_STAT_RAW`.
  Therefore STAT LOW propagates to logic but REGN/D5 cannot back-power
  +3V3_D. At the combined approximately 1.6 mA STAT sink, the TI maximum
  `VOL_STAT` specification is 0.4 V; adding the BAT54WS maximum 0.32 V at
  1 mA gives a conservative logic LOW no greater than 0.72 V. This is below
  the ESP32-S3 0.25*VDD = 0.825 V and STM32H755 0.3*VDD = 0.99 V limits at
  3.3 V.
- **RUN LED:** +3V3_D -> R105 2.2 kOhm -> green D6 -> DGND, about 0.6-0.8 mA.
  It indicates the actual main digital rail and is dark in normal OFF.
- **SOC:** no analog LED gauge is added. BQ28Z610 supplies SOC, voltage,
  current/state and capacity over PM I2C to the R3 display/UI.
- **J11:** primary-only user-panel connector; it never exposes GND_ISO or the
  onboard LED anode nets. J11.9 is raw open-drain `BQ_STAT_RAW`; every panel
  LED must have its own series resistor. `POWER_CTRL` accepts only a latching
  contact to DGND; `QON_SERVICE` accepts only a momentary contact to DGND.

## ERC and files

Final ERC result: **0 errors and 412 warnings**, limited to 206
`endpoint_off_grid` and 206 `lib_symbol_mismatch` findings from the SKiDL
embedded-library/deterministic-grid generation path. The count is recorded in
`reports/R3_power_erc.txt` and `docs/VERIFICATION.md`. Generated outputs are:

- schematic PDF: `reports/R3_power_schematic.pdf`;
- BOM: `bom/R3_power_kicad_bom.csv`;
- harness BOM: `bom/R3_power_harness_bom.csv`;
- logical pin/net map: `tools/logical_nets.json`.
- high-resolution placement: `reports/R3_power_preliminary_placement.png`;
- annotated zones/isolation: `reports/R3_power_zone_isolation_annotated.png`;
- stacked-board top/side references:
  `reports/R3_power_mechanical_stack_top.png` and
  `reports/R3_power_mechanical_stack_side.png`;
- unrouted placement DRC: `reports/R3_power_pcb_drc.txt`.

## Mechanical and board-to-board interface

Six electrically floating 3.20 mm NPTH M3 holes are present. Each has an
8.0 x 8.0 mm four-copper-layer routing/pad/via/pour keepout and 8.0 mm
courtyard. Coordinates are H1 (35.0,25.5), H2 (174.5,25.5), H3
(25.5,94.5), H4 (174.5,94.5), H5 (115.0,25.5) and H6 (135.0,94.5). H1-H4
are the preferred common mounting set for the future R3 board; H5/H6 stiffen
the PowerBox without entering x=121...124 mm.

J12 is a DNP generic 2x8/2.54 mm THT primary header at pin-1 origin
(106.0,28.0). It duplicates +3V3_D/DGND contacts and exports PM I2C, PG,
charger/input/PD status, POWER_CTRL and QON_SERVICE. J13 is a physically
separate DNP 2x5/2.54 mm THT isolated header at (154.0,24.0), with one
GND_ISO return adjacent to each clean rail. J12 has no GND_ISO and J13 has no
DGND. Existing Micro-Fit cable connectors are unchanged and remain in parallel.

The future-board reference envelope is on `Dwgs.User`, not `Edge.Cuts`.
U3/U6 set the height limit at 11.1 mm. A 12 mm spacing leaves only 0.9 mm
nominal and requires an upper-board cutout/keepout; **15 mm is recommended**
and leaves about 3.9 mm nominal. Final header/socket MPNs, standoff tolerance,
J3/J10/J11 latch access and enclosure cable bends remain a mechanical-CAD
gate. Full dimensions and pin tables are in
`docs/R3_BOARD_TO_BOARD_INTERFACE.md`.

## PCB recommendation and blockers

The board is explicitly four-layer: L1 components/critical loops, L2 primary
DGND, L3 power/quiet routing and L4 secondary/clean routing. Every layer is
interrupted by the x=121...124 mm isolation rule area. The resulting 3.0 mm
minimum board copper clearance/creepage is the maximum supported by the SIP8
pad-3/pad-5 geometry (3.08 mm edge-to-edge) and is accepted here for
low-voltage functional isolation only, not certified mains/reinforced safety.

The unrouted PCB DRC has **zero** clearance, copper-to-edge, hole-to-hole,
hole-to-copper, drill-range, annular-width and courtyard-overlap errors. It
retains 437 expected unconnected/ratsnest findings, 233 expected
schematic-parity findings and 214 non-electrical silkscreen findings.
These do not authorize routing release; final reference-text cleanup remains.

PCB routing is blocked by STUSB4500 NVM/compliance validation, BQ28Z610
configuration thresholds, Q2/Q3 protection-event SOA, hot PPTC/current
validation, enclosure/mating-connector/B2B stack clearance, measured power budget,
TPS54302 low-battery validation and the RS3 INA light-load decision. Secondary
OV remains a documented DNP space reservation and is not active in Rev.A.

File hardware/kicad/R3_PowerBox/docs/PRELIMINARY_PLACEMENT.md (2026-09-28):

# R3 PowerBox preliminary placement

Status: final pre-routing placement checkpoint; **no tracks or production
copper pours are present**.

The board now also carries six M3 NPTH mounting holes, optional primary and
isolated B2B headers, and a `Dwgs.User` future-R3 envelope. Exact coordinates
and pinouts are in `R3_BOARD_TO_BOARD_INTERFACE.md`.

## Board and zones

Rev.A remains 160 x 80 mm and four-layer. Placement follows the approved
left-to-right order:

1. DIRTY: USB-C, service input, TPS2121, BQ25798, battery connector,
   BQ28Z610, Q2/Q3 and the Kelvin shunt.
2. PRIMARY: TPS62132, TPS54302, digital/control connectors and primary test
   points, Q4 system load switch, SW1 and J11 user panel.
3. ISOLATION: RS3E-0505S/H3 and RS3-0505D/H3.
4. CLEAN: ADM7150, TPS7A20, isolated filtering, isolated test points and J3.

U3 and U6 are oriented with pins 1/2/3 toward PRIMARY and pins 5/6/7/8 toward
CLEAN. Their pad-3 to pad-5 center gap is 5.08 mm. With 2.0 mm pads the board
edge-to-edge copper gap is 3.08 mm; this layout therefore adopts a **3.0 mm
minimum copper clearance and surface creepage corridor** from x=121 to
x=124 mm across the full board height. The rule area blocks pads, vias,
tracks and copper pours on L1, L2, L3 and L4. It is a low-voltage functional
isolation decision, not a claim of mains/reinforced-insulation certification.

## Stackup intent

- L1: components, critical signals and the smallest switching loops.
- L2: primary DGND plane; it stops completely at the isolation corridor.
- L3: power distribution and quiet sensing; no copper crosses the corridor.
- L4: secondary/clean routing and GND_ISO copper; it also stops at the
  corridor.

No split islands are planned inside the primary domain. Return-current control
comes from compact placement and uninterrupted local reference copper.

## Critical placement

- BQ25798, L3, bootstrap capacitors, charger-local VBUS bank, PMID, SYS and
  BAT capacitors are grouped in Zone A. SW1/SW2 copper must remain local and
  must not extend under any adjacent block.
- STUSB4500, CC ESD and TP31/TP32 are adjacent to J7. CC test pads are inline
  access points, not permission for long routed stubs.
- BQ28Z610, the common-drain CSD17577Q3AT pair, VC filters, SRP/SRN filters and
  WSL2512 shunt form one battery-management group. SRP/SRN and VC1/VC2 remain
  Kelvin/quiet paths.
- L3 is rotated 90 degrees, L1 is 0 degrees and L2 is 90 degrees. U3/U6 retain
  the electrical left-to-right isolation orientation and are vertically
  separated. These choices avoid a single aligned magnetic row and keep all
  magnetics away from the clean-edge LDOs.
- C40-C44 surround U4 and C50/C51 flank U5. These parts are placement-locked
  for short stability/bypass connections during routing.
- Q4, R102/R103, C107, C108 and TP40 form a compact primary-side
  `VSYS_PROT -> VSYS_MAIN` group. SW1 carries gate-control current only.
  Local CHG/RUN LED footprints are visible for bench work; J11 is kept on the
  primary/service edge for an external front-panel harness.
- J3 and J6 are vertical at the clean edge. J1/J7/J8 remain on the dirty edge,
  J2/J4/J9 on the primary edge, and J10/J11 on the primary/service edge. Courtyards
  do not overlap; the board-edge side of each right-angle connector is left
  free for its mating housing, latch and cable bend.
- J12 2x8 is at (106.0,28.0) entirely on PRIMARY. J13 2x5 is at
  (154.0,24.0) entirely on CLEAN/ISOLATED. Both are generic 2.54 mm THT and
  DNP in Rev.A; neither crosses or approaches the isolation corridor.

Primary and dirty test points remain left of the isolation corridor. TP7-TP14
form two dedicated isolated rows at the clean edge. Silkscreen explicitly says
`PRIMARY / DGND`, `ISOLATED / GND_ISO` and marks the isolation boundary.

## Thermal reservations

- Q2/Q3: at least 200 mm2 combined top-layer drain/source copper around the
  pair, with 4-6 x 0.30 mm finished thermal vias per FET into primary-domain
  spreading copper where the Kelvin path permits.
- BQ25798, TPS2121, TPS62132 and TPS54302: exposed-pad copper and thermal-via
  arrays per the respective manufacturer land/layout guidance.
- R93: symmetric 2512 copper with Kelvin taps taken inside the force-current
  pads; do not add thermal-via asymmetry that creates measurement error.
- ADM7150: local copper/EP vias only if the validated load makes its estimated
  dissipation require them.

No thermal copper or via crosses the isolation corridor.

## Connector mechanical gate

The footprints/courtyards are collision-free, but enclosure CAD and the exact
mating housings are still required before routing release. J3, J10 and J11 are the
highest-risk interfaces because their latch access and cable bend direction
must be checked against the future enclosure.

## Mounting and stacked-board reference

- H1-H6 are 3.20 mm NPTH M3 holes with no net and no plating. Each includes an
  8.0 x 8.0 mm F.Cu/In1.Cu/In2.Cu/B.Cu keepout and matching mechanical
  courtyard. Coordinates are H1 (35.0,25.5), H2 (174.5,25.5), H3
  (25.5,94.5), H4 (174.5,94.5), H5 (115.0,25.5), H6 (135.0,94.5).
- H1 is intentionally moved inward for the USB-C plug. H5/H6 avoid both the
  connector rows and x=121...124 mm isolation corridor. Insulating standoffs
  are preferred; no mounting feature bonds either ground domain.
- The future-board reference on `Dwgs.User` spans (22,22) to (178,98). It is
  not a manufacturing outline. H1-H4 are the preferred common mounting set.
- U3 and U6 are the height limit at 11.1 mm. A 12 mm board spacing leaves only
  0.9 mm nominal and therefore requires an upper-board cutout/keepout. Use
  15 mm for the baseline; it leaves about 3.9 mm nominal above the modules.
- Side-entry cable connectors remain reachable in the reference envelope, but
  J3/J10/J11 still require exact latch, housing, bend-radius and enclosure CAD.

## USER POWER AND INDICATION

- Local SW1 is a maintained low-current ON switch; J11.3 provides the same
  `POWER_CTRL` node for a panel-mounted contact to DGND.
- Local SW2 is momentary QON service/wake; J11.4 provides remote access.
- D5 CHG sits in the dirty/charger section and is fed from REGN, so it remains
  active when the main system is off. D7/R80 sit beside it and separate
  `BQ_STAT_RAW` from 3.3 V `CHARGE_STATUS`. D6 RUN is in the primary section
  and is fed from +3V3_D.
- J11.7/J11.8 expose the primary PM I2C bus for a future SOC display based on
  BQ28Z610 data. J11.9 is `BQ_STAT_RAW`; panel LEDs use independent series
  resistors. J11 contains no isolated rail or GND_ISO. J11.3 POWER_CTRL is a
  latching contact-to-DGND input, while J11.4 QON_SERVICE is momentary-to-DGND.
- J7 was shifted inward enough to provide at least 0.5 mm copper-to-edge
  clearance without changing the DIRTY -> PRIMARY -> ISOLATION -> CLEAN
  ordering.

## Generated mechanical views

- `reports/R3_power_preliminary_placement.png`: high-resolution KiCad top view;
- `reports/R3_power_zone_isolation_annotated.png`: zones and barrier;
- `reports/R3_power_mechanical_stack_top.png`: mounting/header coordinates and
  upper-board envelope;
- `reports/R3_power_mechanical_stack_side.png`: 12/15 mm height decision.

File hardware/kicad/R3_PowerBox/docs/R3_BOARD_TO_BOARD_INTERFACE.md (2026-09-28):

# R3 PowerBox board-to-board and mounting interface

Status: **final pre-routing mechanical reference; not a released mechanical
drawing and not routed**.

## Coordinate system

All dimensions below are millimetres in the KiCad PCB coordinate system. The
PowerBox outline is x=20.0...180.0, y=20.0...100.0 (160 x 80 mm). Coordinates
refer to the KiCad footprint origin/pin-1 origin, not the footprint centroid.
The proposed future-R3 reference envelope is drawn on `Dwgs.User` from
(22.0,22.0) to (178.0,98.0). It is intentionally not on `Edge.Cuts` and is not
a final upper-board outline.

## M3 mounting pattern

All six holes use the project-local
`MountingHole_M3_NPTH_3.2mm_Keepout8mm` footprint: 3.20 mm NPTH, unplated,
unnumbered and electrically floating. Each footprint carries an 8.0 x 8.0 mm
keepout on F.Cu, In1.Cu, In2.Cu and B.Cu plus an 8.0 mm courtyard. Tracks,
vias, pads and copper pours are prohibited in that square. The courtyard is the
minimum screw-head/washer/standoff component clearance; enlarge it in the final
enclosure if the selected hardware exceeds 8 mm diameter.

| Hole | X | Y | Note |
|---|---:|---:|---|
| H1 | 35.0 | 25.5 | moved inward for USB-C plug/shell access |
| H2 | 174.5 | 25.5 | upper-right corner |
| H3 | 25.5 | 94.5 | lower-left corner |
| H4 | 174.5 | 94.5 | lower-right corner |
| H5 | 115.0 | 25.5 | upper long edge, primary side |
| H6 | 135.0 | 94.5 | lower long edge, isolated side |

H1-H4 are the preferred reusable four-hole upper-board pattern. H5/H6 add
PowerBox stiffness; their asymmetric x coordinates avoid J10/J11 and the
x=121...124 mm isolation corridor. No hole or 8 mm keepout enters the corridor.
Use insulating standoffs for the prototype. Metal hardware remains floating;
do not use a mounting hole as DGND, GND_ISO or chassis bonding.

## J12 PRIMARY B2B

Footprint origin/pin 1: **(106.0,28.0)**. Footprint:
`PinHeader_2x08_P2.54mm_Vertical`, generic 2x8, 2.54 mm pitch, THT, DNP in
Rev.A. Odd/even pins are paired by row.

| Pin | Signal | Pin | Signal |
|---:|---|---:|---|
| 1 | +3V3_D | 2 | +3V3_D |
| 3 | DGND | 4 | DGND |
| 5 | PM_I2C_SCL | 6 | PM_I2C_SDA |
| 7 | PG_3V3_D | 8 | CHARGE_STATUS |
| 9 | CHARGER_INT_FAULT | 10 | INPUT_SOURCE_STATUS |
| 11 | PD_ALERT_N | 12 | PD_CONTRACT_12V_N |
| 13 | POWER_CTRL | 14 | QON_SERVICE |
| 15 | SPARE / NC | 16 | SPARE / NC |

Pins 1/2 and 3/4 intentionally share current and reduce connector/return
impedance. `POWER_CTRL` is a maintained contact to DGND only. `QON_SERVICE` is
a momentary contact to DGND only. J12 contains no GND_ISO.

## J13 ISOLATED B2B

Footprint origin/pin 1: **(154.0,24.0)**. Footprint:
`PinHeader_2x05_P2.54mm_Vertical`, generic 2x5, 2.54 mm pitch, THT, DNP in
Rev.A.

| Pin | Signal | Pin | Signal |
|---:|---|---:|---|
| 1 | +5V_ISO_RAW | 2 | GND_ISO |
| 3 | +3V3_A_ISO | 4 | GND_ISO |
| 5 | +3V3_D_ISO | 6 | GND_ISO |
| 7 | +5V_INA | 8 | GND_ISO |
| 9 | -5V_INA | 10 | GND_ISO |

Every even pin is the same GND_ISO network and gives its adjacent rail a short
return. J13 contains no DGND. J12 and J13 are on opposite sides of the
functional-isolation barrier; no trace, plane, via, pad or mounting hardware may
bridge the x=121...124 mm corridor.

## Header/socket combinations and stack height

The land patterns accept ordinary straight male headers, female sockets and
long-post stacking headers. A right-angle part is mechanically possible on the
same 2.54 mm grid but must be checked against the upper board and adjacent
parts. Do not select a shrouded body larger than the plotted courtyard without
rerunning the mechanical check.

- **15 mm recommended:** 15 mm M3 standoffs, a 2xN long-post/stacking male on
  one PCB and a low-profile 2xN female socket on the other. Select post length
  for at least 2.5-3.0 mm contact engagement after both PCB thicknesses and the
  socket-body height are included. This gives about 13 mm practical under-board
  component allowance after reserving about 2 mm for tolerance/solder leads.
- **12 mm conditional:** 12 mm standoffs with a low-profile female socket and
  appropriately shortened stacking post. Practical allowance is about 10 mm.
  It is not acceptable over U3/U6 without an upper-board cutout/keepout because
  the RECOM modules are 11.1 mm high.

Freeze an exact header/socket manufacturer series only after the future R3 PCB
thickness, standoff tolerance and enclosure height are known. The DNP Rev.A
default preserves cable-only assembly.

## Component-height and upper-board keepout

| Item | Height / constraint | Stack result |
|---|---|---|
| U3 RS3E-0505S/H3 | 11.1 mm manufacturer height | fails the practical 12 mm allowance; fits nominal 15 mm with about 3.9 mm geometric clearance |
| U6 RS3-0505D/H3 | 11.1 mm manufacturer height | same as U3 |
| C1 CP_Elec_6.3x5.8 | 5.8 mm body | fits 12/15 mm |
| L3 SRP7028A class | 2.8 mm class | fits 12/15 mm |
| L1 XFL4020 | about 2.1 mm class | fits 12/15 mm |
| L2 SRP5030T class | about 3.0 mm class | fits 12/15 mm |
| Micro-Fit right-angle headers | edge-entry; housing/latch/cable envelope dominates | keep upper-board edge and enclosure out of mating/latch corridor |
| test points | bare plated-hole footprint; probe hardware not fixed | use low-profile pads under overlap; tall posts require upper-board keepout |
| SW1/SW2 | local low-profile controls | provide finger/tool cutout if the upper board overlaps them |

For a 12 mm stack, the upper board must exclude/cut out the U3/U6 projected
areas. For 15 mm, retain at least 1.5-2.0 mm tolerance above every fitted item;
the nominal 3.9 mm margin over U3/U6 satisfies that target. STEP/enclosure CAD
remains required before production release.

## Cable and stacked assembly

- **Cable mode:** populate the existing Micro-Fit/JST connectors; leave J12 and
  J13 DNP.
- **Stacked mode:** populate J12/J13 with the selected header/socket pair.
  Existing cable connectors remain electrically parallel and may remain fitted.
- J1/J7/J8 exit the DIRTY edge; J2/J4/J9 exit the upper primary edge; J3/J6
  exit the CLEAN edge; J10/J11 exit the lower primary edge. Their side-entry
  mating direction remains unobstructed by the reference upper PCB, but the
  final upper-board/enclosure outline needs local edge notches or setbacks for
  latch release and cable bend radius.
- J3, J10 and J11 remain the highest-risk access interfaces. Validate the exact
  43645 mating housings, wire gauge, latch tool/finger access and bend radius in
  assembly CAD before routing release.

## Isolation restrictions

The 3.0 mm corridor x=121...124 mm is an all-layer functional-isolation rule
area. L1/L2/L3/L4 copper, zones, tracks, vias and pads are forbidden. The future
R3 PCB must implement its own corresponding barrier and must not reconnect
DGND to GND_ISO through headers, mounting hardware, shields, test equipment or
mechanical metalwork. This is low-voltage functional isolation, not a claim of
mains/basic/reinforced safety certification.

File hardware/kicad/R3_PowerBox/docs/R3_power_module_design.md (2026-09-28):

# R3 PowerBox design notes

Status: unified 2S architecture review; not ready for PCB routing.

Authoritative documents:

- `../R3_POWER_REVIEW.md`
- `../R3_BATTERY_POWER_ARCHITECTURE.md`
- reproducible source: `../tools/generate_hierarchical.py`

## Architecture

```text
USB-C 5 V fallback + protected J1 service input
  -> TPS2121 input mux
  -> BQ25798 2S buck-boost charger/NVDC power-path

2S cells
  -> BQ28Z610 gauge/protection/balancing
  -> external CHG/DSG FETs + Kelvin shunt
  -> BQ25798 BAT

BQ25798 SYS -> VSYS_RAW -> F3 MF-MSMF250/16X-2 -> VSYS_PROT
  -> Q4 DMP3007LSS / SW1 user control -> VSYS_MAIN
  +-> TPS62132 -> +3V3_D
  +-> TPS54302 -> +5V_PREISO
       +-> separate ADS filter -> RS3E -> clean ADS rails
       +-> separate INA filter -> RS3 dual -> INA +/-5 V
```

No 2S-to-9 V stage is used. `DGND` and `GND_ISO` remain galvanically separate. `BAT_NEG_RAW` differs from `DGND` only across the battery-current shunt and must use Kelvin sensing.

## Floorplan constraints

- Zone A, dirty edge: USB-C, J1, TPS2121, BQ25798, battery connector, BQ28Z610, protection FETs, shunt and charger inductor.
- Zone B: TPS62132, TPS54302, digital output/control.
- Zone C: RS3E/RS3 modules and explicit isolation keepout.
- Zone D, opposite clean edge: secondary filters, ADM7150, TPS7A20, isolated connectors/test points.
- Keep charger SW1/SW2/L3 loop local. Do not route it under or toward the clean secondary zone.
- Do not cluster the charger, TPS62132, TPS54302 and RECOM magnetics; vary orientation and spacing after mechanical review.
- Use one controlled DGND plane rather than arbitrary split islands. Keep high-current and sense returns local, with Kelvin shunt and quiet cell/NTC traces.
- Use four copper layers: L1 critical loops/components, L2 primary DGND, L3
  power/quiet routing and L4 clean/secondary routing. The full-height 3.0 mm
  isolation rule area blocks pads, vias, tracks and pours on every copper layer.
- Rev.A protection parts are F1 `MF-R250-0-10`, F2 `MF-MSMF260/16X-2` and F3
  `MF-MSMF250/16X-2`. NTC_BMS and NTC_CHG are separate `103AT-2` probes.
- Four layers are recommended; no final stackup is approved yet.

The current PCB file contains the floorplan/keepout and a preliminary
component placement. It intentionally contains no routing or vias.

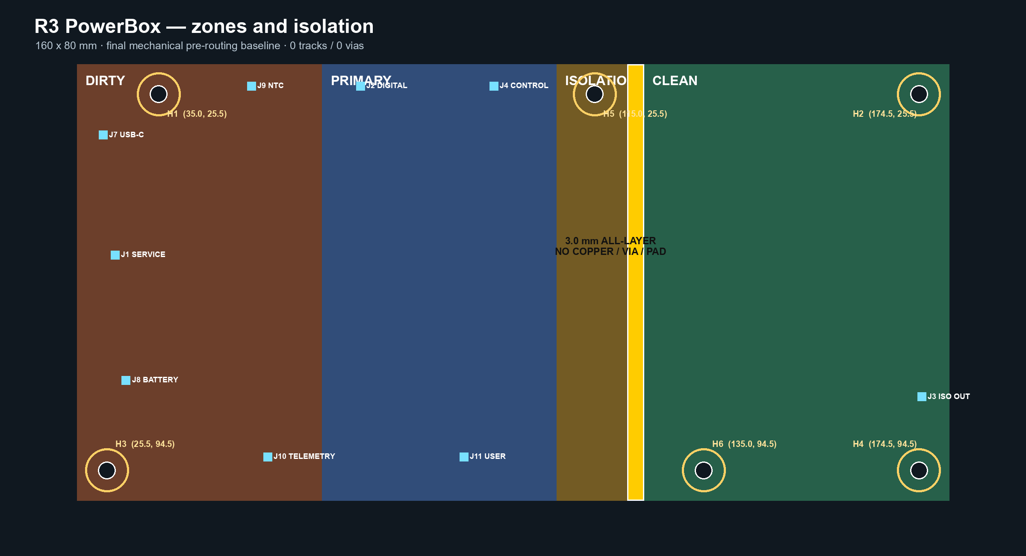
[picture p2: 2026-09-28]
hardware/kicad/R3_PowerBox/reports/R3_power_zone_isolation_annotated.png

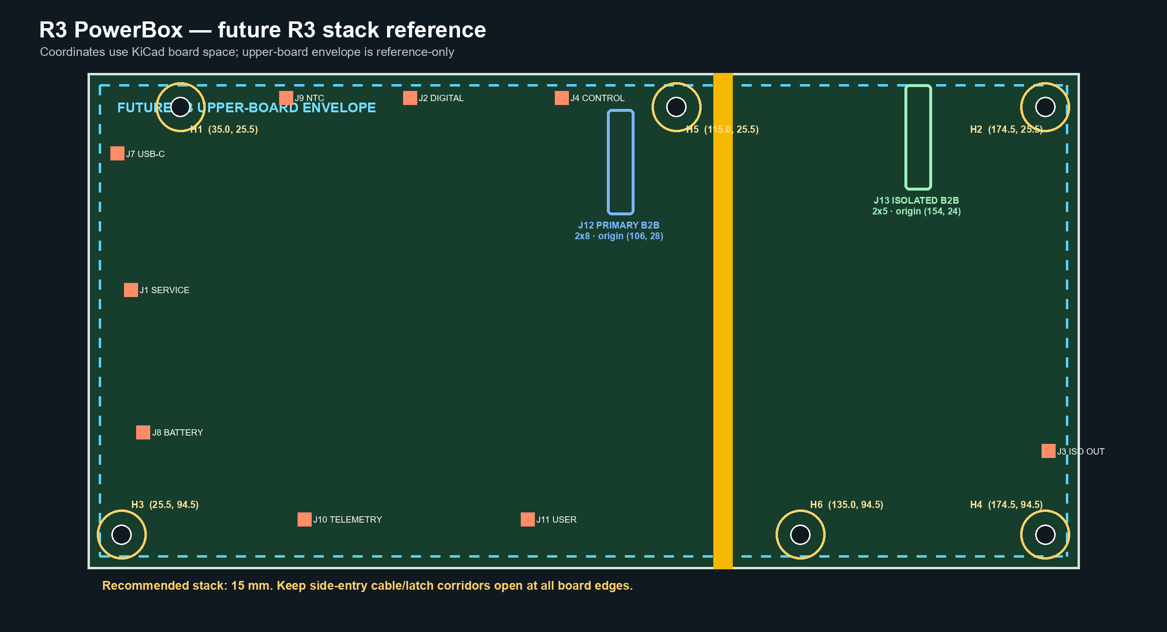
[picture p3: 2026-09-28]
hardware/kicad/R3_PowerBox/reports/R3_power_mechanical_stack_top.png

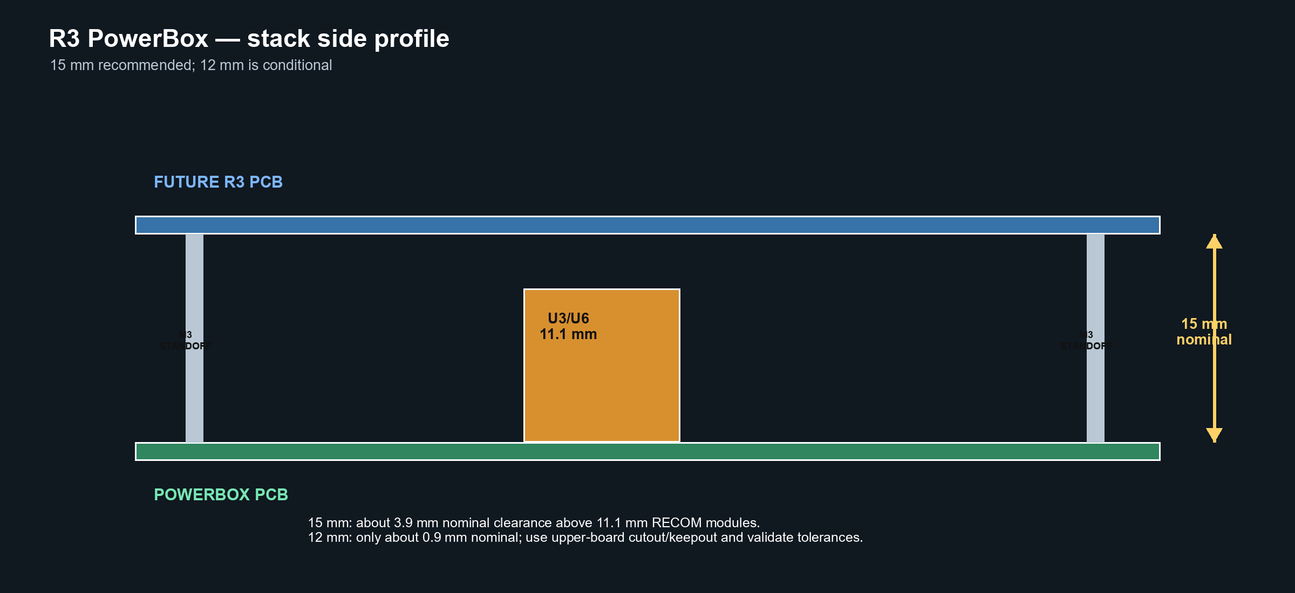
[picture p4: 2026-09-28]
hardware/kicad/R3_PowerBox/reports/R3_power_mechanical_stack_side.png

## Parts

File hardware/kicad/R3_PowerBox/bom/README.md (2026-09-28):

# Bill of materials

- `R3_power_kicad_bom.csv` is generated directly from the current KiCad
  schematic and is the sole reference for schematic quantities, values,
  footprints and designators.
- `R3_power_harness_bom.csv` records the two off-board SEMITEC 103AT-2
  temperature probes plus the optional DNP stacking-mate/standoff selections
  that cannot be fully represented by populated PowerBox footprints.
- Sourcing status, package checks and unresolved selections are maintained in
  `../R3_POWER_REVIEW.md` so they cannot drift from the design review.

Regenerate the KiCad BOM after every schematic change. It is not an approved
purchasing list until all exact manufacturer part numbers and package variants
listed in the power review have been closed.

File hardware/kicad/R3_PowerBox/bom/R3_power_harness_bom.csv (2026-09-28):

Reference | Function | Manufacturer | MPN | Nominal | B25/85 | Tolerance | Connection | Rev.A status
NTC_BMS | Battery-pack protection temperature | SEMITEC | 103AT-2 | 10.0 kOhm @25C | 3435 K | 1% | J8 pin 4 to BAT_NEG_RAW | Populate in battery harness
NTC_CHG | Charger temperature qualification | SEMITEC | 103AT-2 | 10.0 kOhm @25C | 3435 K | 1% | J9 pin 1 to quiet DGND_CHG_SENSE return | Populate as separate probe
J12_MATE | Optional primary stacking interface | Generic 2.54mm / series TBD | 2x8 long-post header plus low-profile socket | 15 mm recommended |  |  | J12 2x8 THT | DNP Rev.A / select after stack CAD
J13_MATE | Optional isolated stacking interface | Generic 2.54mm / series TBD | 2x5 long-post header plus low-profile socket | 15 mm recommended |  |  | J13 2x5 THT | DNP Rev.A / select after stack CAD
M3_STACK | Optional stacked-board hardware | Generic insulated | M3 standoffs and screws | 15 mm nominal |  |  | H1-H4 preferred shared pattern | Select after enclosure CAD

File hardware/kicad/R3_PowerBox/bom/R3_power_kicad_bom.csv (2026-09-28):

Refs | Value | Footprint | Qty | DNP
C1 | 47uF/25V low-ESR | Capacitor_SMD:CP_Elec_6.3x5.8 | 1
C2,C4,C11,C21 | 100nF/25V | Capacitor_SMD:C_0603_1608Metric | 4
C3 | 22uF/25V | Capacitor_SMD:C_1206_3216Metric | 1
C10,C20 | 10uF/25V | Capacitor_SMD:C_1206_3216Metric | 2
C12,C13,C23,C24 | 22uF/10V | Capacitor_SMD:C_0805_2012Metric | 4
C14 | 3.3nF | Capacitor_SMD:C_0603_1608Metric | 1
C22 | 100nF BOOT | Capacitor_SMD:C_0603_1608Metric | 1
C25 | 75pF C0G | Capacitor_SMD:C_0603_1608Metric | 1
C26 | 10uF/10V ADS IN | Capacitor_SMD:C_0805_2012Metric | 1
C27 | 100nF ADS IN | Capacitor_SMD:C_0603_1608Metric | 1
C28 | 10uF/10V INA IN | Capacitor_SMD:C_0805_2012Metric | 1
C29 | 100nF INA IN | Capacitor_SMD:C_0603_1608Metric | 1
C30 | 10uF/10V RAW | Capacitor_SMD:C_0805_2012Metric | 1
C31 | 100nF RAW | Capacitor_SMD:C_0603_1608Metric | 1
C32 | 10uF A bulk | Capacitor_SMD:C_0805_2012Metric | 1
C33 | 100nF A | Capacitor_SMD:C_0603_1608Metric | 1
C34 | 10uF D bulk | Capacitor_SMD:C_0805_2012Metric | 1
C35 | 100nF D | Capacitor_SMD:C_0603_1608Metric | 1
C40 | 10uF VIN | Capacitor_SMD:C_0805_2012Metric | 1
C41 | 10uF VREG | Capacitor_SMD:C_0805_2012Metric | 1
C42 | 10uF VOUT | Capacitor_SMD:C_0805_2012Metric | 1
C43 | 1uF REF | Capacitor_SMD:C_0603_1608Metric | 1
C44 | 1uF BYP | Capacitor_SMD:C_0603_1608Metric | 1
C50 | 2.2uF IN | Capacitor_SMD:C_0603_1608Metric | 1
C51 | 4.7uF OUT | Capacitor_SMD:C_0603_1608Metric | 1
C60 | 10uF +5V bulk | Capacitor_SMD:C_0805_2012Metric | 1
C61 | 100nF +5V | Capacitor_SMD:C_0603_1608Metric | 1
C62 | 10uF -5V bulk | Capacitor_SMD:C_0805_2012Metric | 1
C63 | 100nF -5V | Capacitor_SMD:C_0603_1608Metric | 1
C70 | 4.7nF SHIELD | Capacitor_SMD:C_0603_1608Metric | 1
C71 | 10uF/25V USB | Capacitor_SMD:C_1206_3216Metric | 1
C72 | 100nF MUX SS | Capacitor_SMD:C_0603_1608Metric | 1
C73 | 10uF/25V MUX OUT | Capacitor_SMD:C_1206_3216Metric | 1
C74 | 47nF BTST1 | Capacitor_SMD:C_0603_1608Metric | 1
C75 | 47nF BTST2 | Capacitor_SMD:C_0603_1608Metric | 1
C76 | 4.7uF REGN | Capacitor_SMD:C_0603_1608Metric | 1
C77-C79 | 10uF/25V PMID | Capacitor_SMD:C_1206_3216Metric | 3
C80 | 100nF PMID | Capacitor_SMD:C_0603_1608Metric | 1
C81-C85 | 10uF/16V SYS | Capacitor_SMD:C_1206_3216Metric | 5
C86 | 100nF SYS | Capacitor_SMD:C_0603_1608Metric | 1
C87,C88 | 10uF/16V BAT | Capacitor_SMD:C_1206_3216Metric | 2
C89 | 1nF SDRV | Capacitor_SMD:C_0603_1608Metric | 1
C93 | 2.2uF PBI | Capacitor_SMD:C_0603_1608Metric | 1
C94 | 100nF SHUNT DIFF | Capacitor_SMD:C_0603_1608Metric | 1
C95 | 100nF DSG D-S / TI EVM | Capacitor_SMD:C_0603_1608Metric | 1
C96 | 100nF CHG D-S / TI EVM | Capacitor_SMD:C_0603_1608Metric | 1
C97 | 100nF VC2-VC1 / CELL2 | Capacitor_SMD:C_0603_1608Metric | 1
C98 | 100nF VC1-VSS / CELL1 | Capacitor_SMD:C_0603_1608Metric | 1
C100 | 100nF/25V VBUS LOCAL | Capacitor_SMD:C_0402_1005Metric | 1
C101-C103 | 10uF/25V VBUS LOCAL | Capacitor_SMD:C_1206_3216Metric | 3
C104 | 1uF VREG_1V2 | Capacitor_SMD:C_0603_1608Metric | 1
C105 | 1uF VREG_2V7 | Capacitor_SMD:C_0603_1608Metric | 1
C106 | 4.7uF/25V PD VDD | Capacitor_SMD:C_0603_1608Metric | 1
C107 | 100nF G-S / SOFT START | Capacitor_SMD:C_0603_1608Metric | 1
C108 | 10uF/16V VSYS_MAIN | Capacitor_SMD:C_1206_3216Metric | 1
D1 | SMBJ13A / 13V VRWM | Diode_SMD:D_SMB | 1
D2 | BZT52C10 | Diode_SMD:D_SOD-123 | 1
D3 | SMBJ13A / 13V VRWM USB VBUS | Diode_SMD:D_SMB | 1
D4 | ESDA25W CC ESD / P1,P2=CC P3=GND | Package_TO_SOT_SMD:SOT-323_SC-70 | 1
D5 | LTST-C190KRKT RED / CHG | LED_SMD:LED_0603_1608Metric | 1
D6 | LTST-C190KGKT GREEN / RUN | LED_SMD:LED_0603_1608Metric | 1
D7 | BAT54WS-7-F STAT ISOLATION | Diode_SMD:D_SOD-323 | 1
F1 | MF-R250-0-10 2.5A/30V PPTC | R3_Power:Fuse_PTC_MF-R250 | 1
F2 | MF-MSMF260/16X-2 2.6A/16V PPTC | Fuse:Fuse_1812_4532Metric_Pad1.30x3.40mm_HandSolder | 1
F3 | MF-MSMF250/16X-2 2.5A/16V PPTC | Fuse:Fuse_1812_4532Metric_Pad1.30x3.40mm_HandSolder | 1
FB1 | BLM31PG601SN1 | Inductor_SMD:L_1206_3216Metric_Pad1.22x1.90mm_HandSolder | 1
FB2 | FB_A / FB-or-0R | Resistor_SMD:R_0805_2012Metric | 1
FB3 | FB_D / FB-or-0R | Resistor_SMD:R_0805_2012Metric | 1
FB4 | FB_INA_P / FB-or-0R | Resistor_SMD:R_0805_2012Metric | 1
FB5 | FB_INA_N / FB-or-0R | Resistor_SMD:R_0805_2012Metric | 1
FB6,FB7 | BLM31KN601B family / 2A | Inductor_SMD:L_1206_3216Metric_Pad1.22x1.90mm_HandSolder | 2
J1 | SERVICE / BENCH INPUT 6-12V | Connector_Molex:Molex_Micro-Fit_3.0_43650-0200_1x02_P3.00mm_Horizontal | 1
J2 | DIGITAL POWER OUT | Connector_Molex:Molex_Micro-Fit_3.0_43650-0600_1x06_P3.00mm_Horizontal | 1
J3 | ISOLATED POWER OUT | Connector_Molex:Molex_Micro-Fit_3.0_43650-1000_1x10_P3.00mm_Horizontal | 1
J4 | CONTROL / SERVICE | Connector_Molex:Molex_Micro-Fit_3.0_43650-0400_1x04_P3.00mm_Horizontal | 1
J5 | PRIMARY AUX DNP | Connector_JST:JST_GH_SM04B-GHS-TB_1x04-1MP_P1.25mm_Horizontal | 1
J6 | ISOLATED AUX DNP | Connector_JST:JST_GH_SM04B-GHS-TB_1x04-1MP_P1.25mm_Horizontal | 1
J7 | USB-C POWER INPUT | Connector_USB:USB_C_Receptacle_GCT_USB4105-xx-A_16P_TopMnt_Horizontal | 1
J8 | 2S BATTERY / KEYED / NTC_BMS=103AT-2 | Connector_Molex:Molex_Micro-Fit_3.0_43650-0400_1x04_P3.00mm_Horizontal | 1
J9 | NTC_CHG=103AT-2 / QUIET DGND RETURN | Connector_Molex:Molex_Micro-Fit_3.0_43650-0200_1x02_P3.00mm_Horizontal | 1
J10 | BATTERY / CHARGER TELEMETRY | Connector_Molex:Molex_Micro-Fit_3.0_43650-1000_1x10_P3.00mm_Horizontal | 1
J11 | USER PANEL / PRIMARY ONLY | Connector_Molex:Molex_Micro-Fit_3.0_43650-1000_1x10_P3.00mm_Horizontal | 1
J12 | PRIMARY B2B 2x8 / DNP | Connector_PinHeader_2.54mm:PinHeader_2x08_P2.54mm_Vertical | 1
J13 | ISOLATED B2B 2x5 / DNP | Connector_PinHeader_2.54mm:PinHeader_2x05_P2.54mm_Vertical | 1
L1 | 2.2uH XFL4020-222ME | R3_Power:L_Coilcraft_XFL4020 | 1
L2 | 10uH SRP5030TA-100M | Inductor_SMD:L_Bourns_SRP5030T | 1
L3 | 1.0uH >=6A / MPN TBD | Inductor_SMD:L_Bourns_SRP7028A_7.3x6.6mm | 1
Q1 | DMP3007LSS-13 | R3_Power:DMP3007LSS_SO8_LOGICAL | 1
Q2 | CSD17577Q3AT 30V NMOS DSG | R3_Power:CSD17577Q3A_VSON-8_3.3x3.3mm | 1
Q3 | CSD17577Q3AT 30V NMOS CHG | R3_Power:CSD17577Q3A_VSON-8_3.3x3.3mm | 1
Q4 | DMP3007LSS-13 SYSTEM LOAD SWITCH | R3_Power:DMP3007LSS_SO8_LOGICAL | 1
R1,R10 | 100k | Resistor_SMD:R_0603_1608Metric | 2
R21 | 100k 1% | Resistor_SMD:R_0603_1608Metric | 1
R22 | 13.3k 1% | Resistor_SMD:R_0603_1608Metric | 1
R40 | 10k | Resistor_SMD:R_0603_1608Metric | 1
R72 | 1M SHIELD | Resistor_SMD:R_0603_1608Metric | 1
R73 | 44.2k / ILIM typ 2.5A | Resistor_SMD:R_0603_1608Metric | 1
R74 | 100R BATP | Resistor_SMD:R_0603_1608Metric | 1
R75 | 6.04k PROG / 2S PROFILE | Resistor_SMD:R_0603_1608Metric | 1
R76 | 243k ILIM TOP / DEFAULT 0.50A | Resistor_SMD:R_0603_1608Metric | 1
R77 | 100k ILIM BOT | Resistor_SMD:R_0603_1608Metric | 1
R78 | 5.24k TS TOP | Resistor_SMD:R_0603_1608Metric | 1
R79 | 30.31k TS BOT | Resistor_SMD:R_0603_1608Metric | 1
R80 | 10k CHARGE_STATUS PU | Resistor_SMD:R_0603_1608Metric | 1
R81 | 10k INT PU | Resistor_SMD:R_0603_1608Metric | 1
R82 | 10k MUX ST PU | Resistor_SMD:R_0603_1608Metric | 1
R83 | 10k ALERT PU | Resistor_SMD:R_0603_1608Metric | 1
R84 | 10k PDO3 OK PU | Resistor_SMD:R_0603_1608Metric | 1
R85 | 0R PD VDD FEED | Resistor_SMD:R_0603_1608Metric | 1
R90 | 100R VC2 / KELVIN | Resistor_SMD:R_0603_1608Metric | 1
R91 | 100R VC1 / KELVIN | Resistor_SMD:R_0603_1608Metric | 1
R92 | 100R TS | Resistor_SMD:R_0603_1608Metric | 1
R93 | WSL2512R0100FEA 10mR 1W | Resistor_SMD:R_2512_6332Metric_Pad1.40x3.35mm_HandSolder | 1
R94,R95 | 100R KELVIN | Resistor_SMD:R_0603_1608Metric | 2
R96,R97 | 10k I2C | Resistor_SMD:R_0603_1608Metric | 2
R98 | 5.1k DSG GATE / TI EVM | Resistor_SMD:R_0603_1608Metric | 1
R99 | 10M DSG G-S / TI EVM | Resistor_SMD:R_0603_1608Metric | 1
R100 | 5.1k CHG GATE / TI EVM | Resistor_SMD:R_0603_1608Metric | 1
R101 | 10M CHG G-S / TI EVM | Resistor_SMD:R_0603_1608Metric | 1
R102 | 100k G-S / DEFAULT OFF | Resistor_SMD:R_0603_1608Metric | 1
R103 | 10k GATE SERIES | Resistor_SMD:R_0603_1608Metric | 1
R104 | 2.2k CHG LED / ~1.3mA | Resistor_SMD:R_0603_1608Metric | 1
R105 | 2.2k RUN LED / ~0.7mA | Resistor_SMD:R_0603_1608Metric | 1
SW1 | C&K RS282G05A3 / POWER ON | Button_Switch_SMD:SW_SPST_CK_RS282G05A3 | 1
SW2 | QON SERVICE / TL3305AF160QG | Button_Switch_SMD:SW_SPST_TL3305A | 1
TP1 | SERVICE_IN_RAW | TestPoint:TestPoint_Plated_Hole_D2.0mm | 1
TP2 | SERVICE_IN_PROT | TestPoint:TestPoint_Plated_Hole_D2.0mm | 1
TP3 | +3V3_D | TestPoint:TestPoint_Plated_Hole_D2.0mm | 1
TP4 | PG_3V3_D | TestPoint:TestPoint_Plated_Hole_D2.0mm | 1
TP5 | +5V_PREISO | TestPoint:TestPoint_Plated_Hole_D2.0mm | 1
TP6 | +5V_PREISO_ADS | TestPoint:TestPoint_Plated_Hole_D2.0mm | 1
TP7 | +5V_ISO_RAW | TestPoint:TestPoint_Plated_Hole_D2.0mm | 1
TP8 | +5V_ISO_A | TestPoint:TestPoint_Plated_Hole_D2.0mm | 1
TP9 | +5V_ISO_D | TestPoint:TestPoint_Plated_Hole_D2.0mm | 1
TP10 | GND_ISO | TestPoint:TestPoint_Plated_Hole_D2.0mm | 1
TP11 | +3V3_A_ISO | TestPoint:TestPoint_Plated_Hole_D2.0mm | 1
TP12 | +3V3_D_ISO | TestPoint:TestPoint_Plated_Hole_D2.0mm | 1
TP13 | +5V_INA | TestPoint:TestPoint_Plated_Hole_D2.0mm | 1
TP14 | -5V_INA | TestPoint:TestPoint_Plated_Hole_D2.0mm | 1
TP15 | DGND | TestPoint:TestPoint_Plated_Hole_D2.0mm | 1
TP16 | +5V_PREISO_INA | TestPoint:TestPoint_Plated_Hole_D2.0mm | 1
TP20 | USB_VBUS_RAW | TestPoint:TestPoint_Plated_Hole_D2.0mm | 1
TP21 | CHARGER_IN | TestPoint:TestPoint_Plated_Hole_D2.0mm | 1
TP22 | VSYS_RAW | TestPoint:TestPoint_Plated_Hole_D2.0mm | 1
TP23 | VSYS_PROT | TestPoint:TestPoint_Plated_Hole_D2.0mm | 1
TP24 | BAT_POS_RAW | TestPoint:TestPoint_Plated_Hole_D2.0mm | 1
TP25 | CELL_MID | TestPoint:TestPoint_Plated_Hole_D2.0mm | 1
TP26 | BAT_NEG_RAW | TestPoint:TestPoint_Plated_Hole_D2.0mm | 1
TP27 | BMS_SRP_FILT | TestPoint:TestPoint_Plated_Hole_D2.0mm | 1
TP28 | BMS_SRN_FILT | TestPoint:TestPoint_Plated_Hole_D2.0mm | 1
TP29 | NTC_BMS | TestPoint:TestPoint_Plated_Hole_D2.0mm | 1
TP30 | NTC_CHG | TestPoint:TestPoint_Plated_Hole_D2.0mm | 1
TP31 | USB_CC1 | TestPoint:TestPoint_Plated_Hole_D2.0mm | 1
TP32 | USB_CC2 | TestPoint:TestPoint_Plated_Hole_D2.0mm | 1
TP33 | USB_VBUS_PROT | TestPoint:TestPoint_Plated_Hole_D2.0mm | 1
TP34 | PD_VDD | TestPoint:TestPoint_Plated_Hole_D2.0mm | 1
TP35 | PD_VREG_2V7 | TestPoint:TestPoint_Plated_Hole_D2.0mm | 1
TP36 | PD_ALERT_N | TestPoint:TestPoint_Plated_Hole_D2.0mm | 1
TP37 | PM_I2C_SCL | TestPoint:TestPoint_Plated_Hole_D2.0mm | 1
TP38 | PM_I2C_SDA | TestPoint:TestPoint_Plated_Hole_D2.0mm | 1
TP39 | QON_SERVICE | TestPoint:TestPoint_Plated_Hole_D2.0mm | 1
TP40 | VSYS_MAIN | TestPoint:TestPoint_Plated_Hole_D2.0mm | 1
U1 | TPS62132RGTR | Package_DFN_QFN:VQFN-16-1EP_3x3mm_P0.5mm_EP1.45x1.45mm | 1
U2 | TPS54302DDCR | Package_TO_SOT_SMD:SOT-23-6 | 1
U3 | RS3E-0505S/H3 | R3_Power:Converter_DCDC_RECOM_RS3E_SIP8 | 1
U4 | ADM7150ACPZ-3.3-R7 | R3_Power:LFCSP-8-1EP_3x3mm_P0.5mm_EP1.74x1.45mm | 1
U5 | TPS7A2033PDBVR | Package_TO_SOT_SMD:SOT-23-5 | 1
U6 | RS3-0505D/H3 | R3_Power:Converter_DCDC_RECOM_RS3_SIP8 | 1
U7 | TPS2121RUXR | Package_DFN_QFN:Texas_VQFN-HR-12_2x2.5mm_P0.5mm | 1
U8 | BQ25798RQM | Package_DFN_QFN:Texas_RQM0029A_VQFN-29_4x4mm_P0.4mm | 1
U9 | BQ28Z610DRZR | R3_Power:Texas_DRZ0012A_VSON-12 | 1
U10 | STUSB4500QTR | Package_DFN_QFN:QFN-24-1EP_4x4mm_P0.5mm_EP2.7x2.7mm | 1
U11 | BQ294502 SPACE ONLY / NC / DNP | Package_SON:WSON-6-1EP_2x2mm_P0.65mm_EP1x1.6mm | 1

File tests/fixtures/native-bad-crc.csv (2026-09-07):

# R1S3_LOG schema=1
# META {"acquisition":{"adc_config":31592 | measured_hz:null | requested_hz:50 | timestamp_note:"synthetic; sequential channels | ready-observation time"} | config:{"adc_range":0 | allow_unknown_utc:true | average_code:0 | calibration_id:"nominal-uncalibrated" | calibration_note:"" | calibration_utc:"" | calibration_valid:false | display_filter_tau_ms:0 | display_hz:5 | display_utc_offset_min:0 | flush_interval_ms:1000 | i_gain:1 | i_zero_uV:0 | live_hz:5 | max_gap_us:40000 | oled_contrast:127 | polarity:1 | queue_bytes:65536 | ready_timeout_us:15000 | requested_rate_hz:50 | reserve_bytes:67108864 | rotation_bytes:1073741824 | shunt_uohm:150 | temp_ct_code:5 | u_gain:1 | u_zero_V:0 | vbus_ct_code:5 | vshunt_ct_code:5} | config_generation:1 | config_sha256:"a14e3288209a80dc239b42de6e868940652a92d8114366c685d19ef87cc584c2" | description:"Synthetic public fixture | no bench data" | hardware:{"board":"ESP32-S3-N32R16V" | device_id:8833 | manufacturer_id:21577 | sensor:"INA228" | sensor_address:64 | shunt_nameplate:"60mV/400A" | topology:"low-side"} | integration:"trapezoid-sign-split-no-gap-v1" | part:0 | previous_part_sha256:null | raw:{"temp":"signed16" | temp_C_lsb:0.0078125 | vbus:"unsigned20" | vbus_V_lsb:0.0001953125 | vshunt:"signed20" | vshunt_uV_lsb:0.3125} | schema:1 | session_id:"synthetic-contract-001" | time:{"anchor_t_us":0 | sample_point:"conversion-ready-observed" | source:"unknown" | uncertainty_us:null | utc_anchor:null}
# META_CRC32 E5002121
timestamp | ms_from_start | I_A | U_V | P_W | Wh_net | Whc | Whd | seq | t_us | vshunt_raw | vbus_raw | temp_raw | quality | Ah_net | Ahc | Ahd
 | 0 | 1.0 | 5.0 | 5.0 | 0.0 | 0.0 | 0.0 | 0 | 0 | 481 | 25600 | 3200 | 8 | 0.0 | 0.0 | 0.0
 | 20 | 1.0 | 5.0 | 5.0 | 2.777777777777778e-05 | 2.777777777777778e-05 | 0.0 | 1 | 20000 | 480 | 25600 | 3200 | 8 | 5.555555555555556e-06 | 5.555555555555556e-06 | 0.0
# CHECKPOINT {"crc32":"7AB437E2" | end:2038 | first_seq:0 | last_seq:1 | rows:2 | start:1841}
 | 40 | -1.0 | 5.0 | -5.0 | 2.777777777777778e-05 | 3.472222222222222e-05 | 6.944444444444445e-06 | 2 | 40000 | -480 | 25600 | 3200 | 8 | 5.555555555555556e-06 | 6.944444444444445e-06 | 1.388888888888889e-06
 | 60 | -1.0 | 5.0 | -5.0 | 0.0 | 3.472222222222222e-05 | 3.472222222222222e-05 | 3 | 60000 | -480 | 25600 | 3200 | 8 | 0.0 | 6.944444444444445e-06 | 6.944444444444445e-06
# CHECKPOINT {"crc32":"F79CD485" | end:2448 | first_seq:2 | last_seq:3 | rows:2 | start:2132}
# END {"clean":true | reason:"stop" | rows:4 | sha256:"dd7485c3ef43b94d5401e0a7740316876c66999cd7b70536cfb6ecfc395b079c"}
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

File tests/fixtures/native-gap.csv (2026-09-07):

# R1S3_LOG schema=1
# META {"acquisition":{"adc_config":31592 | measured_hz:null | requested_hz:50 | timestamp_note:"synthetic; sequential channels | ready-observation time"} | config:{"adc_range":0 | allow_unknown_utc:true | average_code:0 | calibration_id:"nominal-uncalibrated" | calibration_note:"" | calibration_utc:"" | calibration_valid:false | display_filter_tau_ms:0 | display_hz:5 | display_utc_offset_min:0 | flush_interval_ms:1000 | i_gain:1 | i_zero_uV:0 | live_hz:5 | max_gap_us:40000 | oled_contrast:127 | polarity:1 | queue_bytes:65536 | ready_timeout_us:15000 | requested_rate_hz:50 | reserve_bytes:67108864 | rotation_bytes:1073741824 | shunt_uohm:150 | temp_ct_code:5 | u_gain:1 | u_zero_V:0 | vbus_ct_code:5 | vshunt_ct_code:5} | config_generation:1 | config_sha256:"a14e3288209a80dc239b42de6e868940652a92d8114366c685d19ef87cc584c2" | description:"Synthetic public fixture | no bench data" | hardware:{"board":"ESP32-S3-N32R16V" | device_id:8833 | manufacturer_id:21577 | sensor:"INA228" | sensor_address:64 | shunt_nameplate:"60mV/400A" | topology:"low-side"} | integration:"trapezoid-sign-split-no-gap-v1" | part:0 | previous_part_sha256:null | raw:{"temp":"signed16" | temp_C_lsb:0.0078125 | vbus:"unsigned20" | vbus_V_lsb:0.0001953125 | vshunt:"signed20" | vshunt_uV_lsb:0.3125} | schema:1 | session_id:"synthetic-contract-001" | time:{"anchor_t_us":0 | sample_point:"conversion-ready-observed" | source:"unknown" | uncertainty_us:null | utc_anchor:null}
# META_CRC32 E5002121
timestamp | ms_from_start | I_A | U_V | P_W | Wh_net | Whc | Whd | seq | t_us | vshunt_raw | vbus_raw | temp_raw | quality | Ah_net | Ahc | Ahd
 | 0 | 1.0 | 5.0 | 5.0 | 0.0 | 0.0 | 0.0 | 0 | 0 | 480 | 25600 | 3200 | 8 | 0.0 | 0.0 | 0.0
 | 20 |  |  |  | 0.0 | 0.0 | 0.0 | 1 | 20000 |  |  |  | 25 | 0.0 | 0.0 | 0.0
# CHECKPOINT {"crc32":"2B51D4A1" | end:1946 | first_seq:0 | last_seq:1 | rows:2 | start:1841}
 | 80 | -1.0 | 5.0 | -5.0 | 0.0 | 0.0 | 0.0 | 4 | 80000 | -480 | 25600 | 3200 | 26 | 0.0 | 0.0 | 0.0
 | 100 | -1.0 | 5.0 | -5.0 | -2.777777777777778e-05 | 0.0 | 2.777777777777778e-05 | 5 | 100000 | -480 | 25600 | 3200 | 24 | -5.555555555555556e-06 | 0.0 | 5.555555555555556e-06
# CHECKPOINT {"crc32":"4B8035C2" | end:2254 | first_seq:4 | last_seq:5 | rows:2 | start:2040}
# END {"clean":true | reason:"stop" | rows:4 | sha256:"a8f3b5012fb56c7ae558b4a49a7b553572761d390bd5735da78af239cc7117bf"}
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

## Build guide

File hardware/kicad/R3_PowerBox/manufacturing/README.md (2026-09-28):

# Manufacturing outputs

Put reviewed release artifacts here: Gerbers, drill files, position files, BOM,
assembly drawings, and a release checksum manifest.

Do not manufacture from this directory until ERC and DRC are clean, footprints
are verified against purchased parts, and a release revision is recorded.

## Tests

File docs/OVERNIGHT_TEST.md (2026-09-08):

# Overnight UART and SD endurance — 2026-09-08/09

The owner authorized an unattended night test with the logger powered, bench
supply OFF and its measurement wiring still connected. This tests transport,
acquisition and recording stability near zero input, not loaded accuracy or the
cause of the earlier intermittent fault. Firmware v0.22 remains unchanged.

## Bounded run

Started at **2026-09-08 20:27 Europe/Prague**, with a ten-hour budget ending near
**2026-09-09 06:27 Europe/Prague**. Cleanup may extend the finish slightly.

1. Make, close, download and validate a five-second 50 Hz canary recording.
2. Record approximately 20 minutes each at 50, 100 and 300 Hz. After each STOP,
   download that entire finalized file through UART with per-block CRC32 checks.
3. Validate native metadata/configuration, checkpoint CRCs, final SHA-256,
   raw/calibrated values, integration, quality and cadence with the production
   streaming viewer decoder. Files no larger than 16 MiB also use the independent
   whole-file reference reader. Retain originals and validation reports.
4. Use the remaining budget for 300 Hz acquisition with continuous LIVE polling
   and health snapshots. Downloads also leave acquisition running.
5. Close any owned transfer/recording and restore the exact initial volatile
   configuration: 50 Hz, EEPROM generation 3. Keep the panel available.

UART at 115200 with hexadecimal file replies is deliberately slow. The run has
a hard time budget: an unfinished transfer is retained as `.download`, reported
as incomplete, and must never count as a verified file. Existing SD files are
not overwritten or deleted. Twenty-minute sessions fit the initial rotation
policy; the runner refuses a smaller incompatible rotation setting.

## Evidence and stopping

The runner shares one serialized UART connection with the local panel. During
testing the panel permits live/state reads; configuration and SD file controls
are reserved by the test. Windows UART error masks, request failures, boot ID,
advancing uptime/sample counters, FIFO occupancy/overflows, SD write/sync maxima,
I2C errors, internal/PSRAM free memory and OLED progress are captured. Preview
drops are distinct from acquisition loss. Logs are bounded and private.

Unexpected reset, acquisition/I2C loss, UART error flags, storage/validation
failure, low memory or unrecoverable transport failure stops the test and
triggers best-effort cleanup. State-changing commands are never automatically
replayed after an ambiguous response. Cleanup does not overwrite an externally
changed configuration or stop an identified unrelated recording. If communication
is lost, cleanup is reported as unconfirmed; the tool cannot guarantee an SD
STOP without a working command path. No automatic hardware reset hides failures.

The PC is temporarily kept awake by the test thread; its permanent power plan
is not changed. Keep the PC powered and running. Firmware, EEPROM and RTC are
not written. A thread heartbeat checks progress every 30 minutes and reports
failure or completion, without repeating unchanged status messages.

Private artifacts: `data/overnight-2026-09-08_20-27-07/`. `status.json` contains
safe progress, `events.jsonl` bounded observations, `uart-errors.json` error
flags, and `baseline.json`/`restored.json` private full configuration. Do not
publish raw state/session files. The status PID identifies the actual Python
worker (Windows may also have a Python launcher parent).

Orderly cancellation: create a file named `STOP` inside that exact run directory,
or POST to the current panel's authenticated `/api/overnight-stop` endpoint.
Allow cleanup to finish before manually using SD/configuration controls. This
runner is a local process; the scheduled heartbeat supervises it independently.

## Outcome

**Interrupted by a reproduced UART fault; the ten-hour plan did not complete.**
The worker ended at **2026-09-08 22:33:29 Europe/Prague**, after **7,579.4 s
(2 h 6 min 19 s)** including its initial cleanup attempt. The first transfer
failure occurred two seconds earlier. No second overnight run was started.

Startup canary: 322 rows / 84,417 bytes, verified clean in both
readers; actual cadence 49.999572 Hz, no missing/invalid/gap rows. Complete-file
SHA-256: `5e966c1ebe3bb712720c8df8ef5192609dd6b747b9028d3a8a4b7bd471314302`.
The five-second polling window produced about 6.42 seconds between first/last
stored samples, including command/publication latency; durations are measured
from the file rather than assumed from the PC timer. Seven host guard tests
pass, covering ambiguous control replies, ownership, external configuration,
unexpected boot, lost samples, cancellation and corrupt-file rejection.

### Recording and transfer results

| Stage | Device recording | PC verification |
| --- | --- | --- |
| Canary, 50 Hz | 322 rows / 84,417 bytes | Complete; both readers verified clean |
| 50 Hz, 20-minute target | 60,098 rows / 15,517,430 bytes | Complete; both readers verified clean; no missing/invalid/gap rows |
| 100 Hz, 20-minute target | 120,122 rows / 30,981,634 bytes; device finalized `.csv` and returned READY | Transfer interrupted; only 1,153,024 bytes retained on PC; full file remains unverified |
| 300 Hz recording and remaining soak | Not reached | Not tested in this overnight run |

The verified 50 Hz file has 1,201.939998 s between first and last sample,
50.000000083 Hz actual cadence and 19,084–20,874 us sample intervals. Its
complete-file SHA-256 was independently recomputed after the failure:
`887c0fe32cfb6d67103430274b3c5c8bf0828e86dae7604d0cf30535931e871b`.
The device reports 1,201.465 s for the finalized 100 Hz session; its complete
file cadence/quality cannot be established from the interrupted download.

The partial 100 Hz PC copy passes 4,407 checkpoint-verified rows, followed by
76 complete but unverified rows and a partial line. It is correctly classified
as interrupted. Integrity of the remaining bytes on SD is untested; the
incomplete transfer does not establish corruption of the SD source file.

### Failure and health evidence

Before the worker finished, it counted **35,356 successful requests** and two
failed operations: a FILES reply with an invalid JSON control character, then
a cleanup CLOSE that could not obtain the UART lock within two seconds. Windows
reported **two `CE_FRAME` (`0x0008`) notifications** at 22:33:26.694 and
22:33:26.697 local time. They are error notifications, not counts of damaged
bytes or proof of two separate physical incidents. No other UART mask was
recorded during the run. Subsequent panel requests also saw temporary lock
timeouts and a LIVE timeout; these occurred after the worker's final counters.

Across **1,356 health snapshots**, the boot ID remained `135af910`. Missed
samples, invalid samples, I2C errors and FIFO overflows all remained zero.
Maximum FIFO occupancy was 6 samples at 50 Hz and 14 at 100 Hz, within the
2,048-sample PSRAM queue. Maximum SD write/sync times were 106.364/78.851 ms
at 50 Hz and 132.234/117.983 ms at 100 Hz. Free internal heap ranged from
93,000 to 103,756 bytes, and free PSRAM from 16,555,807 to 16,591,247 bytes.
Chip temperature was 24.617–25.125 C. No memory-reserve guard triggered; this
bounded observation is not a proof of indefinite leak-free operation.

The recurrence occurred with the bench supply OFF, so the earlier powered load
is not required for this failure. The error still does not identify a specific
component, joint, signal-integrity issue or driver as its cause. No firmware,
EEPROM, RTC or hardware reset operation was used to recover this run.

### Cleanup and final state

The runner's first cleanup stopped at the busy UART lock before restoration,
leaving `needs_attention` and the initial evidence intact. The heartbeat then
queried the **existing panel/serial owner**, verified the same boot and READY,
and confirmed the expired transfer was closed. It compared the applied 100 Hz
profile with the exact test-generated profile before restoring the baseline.
By **22:37:44 local time**, two fresh states confirmed **READY, 50 Hz, SAVED,
EEPROM generation 3**, the original configuration bytes and advancing samples.
No additional STOP was needed because the 100 Hz recording had already closed.
The panel remains running and temporary sleep inhibition has been released.

Private evidence is retained under the original run directory, including
`failure-evidence/`, `supervisor-audit.json`, `supervisor-recovery.json` and
`supervisor-restored.json`. The original worker status is deliberately not
rewritten to imply that its cleanup succeeded. The follow-up check is stopped
after this final report. Before another unattended run, cleanup should prevent
panel polling from taking the UART lock ahead of bounded recovery operations;
this host-side cleanup limitation is separate from the recorded framing fault.

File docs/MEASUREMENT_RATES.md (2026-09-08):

# Measurement rates: 1–300 Hz

PANEL v0.22 accepts every **integer** from 1 through 300 Hz. The overview provides
1, 5, 10, 25, 50, 100, 150, 200, 250 and 300 Hz buttons and a number field.
Select a preset or type a number, inspect the displayed ADC mode, then choose
**Apply frequency** (or Enter). Selection alone sends no command. Rates cannot
change during a recording. Stop and wait for the CSV to close first.

## Speed and noise

The overview applies these explicit profiles; conversion time applies separately
to shunt voltage, bus voltage and die temperature. No averaging is enabled.

| Requested rate | Conversion time per channel | I2C clock | Profile |
| --- | --- | --- | --- |
| 1–100 Hz | 1052 µs | 100 kHz | Normal |
| 101–200 Hz | 150 µs | 400 kHz | Fast |
| 201–300 Hz | 50 µs | 400 kHz | Maximum speed |

The panel displays the profile and explains increased noise before application.
The previous [benchmark](RATE_BENCHMARK.md) contains measured examples of the
tradeoff. Sampling frequency and chart frame rate (30/60 FPS) are independent;
animation does not create ADC samples. USB at 115200 baud can limit preview
delivery. Wi-Fi polls extra batches (up to a 10 Hz delivery target) while a queue
is waiting. If USB falls over 0.75 seconds behind (at least one 48-point batch),
the preview requests a recent window and marks the skipped section as a gap.
It does not silently replay increasingly old data. The SD file retains all raw
samples independently of these bounded preview windows.

Shunt resistance, polarity, gains, offsets, range and calibration provenance are
preserved. In particular, a high rate does not silently select the narrow shunt
range. Advanced settings still allow explicit conversion/averaging choices, but
firmware rejects combinations without room for conversion plus the bus and
scheduling budget. The bus clock follows the requested rate in production.

## Persistence and file interpretation

Apply affects runtime only. **Save to EEPROM** is a separate, explicit action.
There is no implicit SAVE at boot, on rate selection or during acceptance tests.
The next boot uses the last explicitly saved configuration.

Quick profiles raise `max_gap_us` to at least `ceil(2000000 / Hz)`; at 1 Hz this is
2,000,000 µs, preventing ordinary one-second sample intervals from being excluded
from energy integration. A larger existing gap threshold is preserved. Advanced
settings may deliberately choose a different integration gap limit.

Config v1.1 retains the same 28 TLV fields. New readers accept v1.0. A profile
with 10/50/100 Hz and a gap limit up to 1,000,000 µs remains byte-compatible v1.0;
other frequencies or a larger gap limit use minor version 1 in JSON/EEPROM.
Older firmware protects a committed v1.1 slot from overwriting. It must not be
used to edit new profiles. See [configuration contract](CONFIG_SCHEMA.md).

R1S3 CSV v1 remains self-contained with exact applied coefficients, conversion
settings, requested frequency and raw samples. The updated reader accepts the
expanded range and older R1/R1-S3 recordings. Old viewers with a fixed rate enum
need this reader update to open new rates. Sample timestamps remain measured
read times; the microsecond scheduler period is integer-quantized, so the measured
average can differ slightly from the requested integer frequency.

## Scheduling

Core 1 owns acquisition, I2C and SD work. Core 0 formats panel JSON from a bounded
snapshot copied by the owner; it never reads the mutable settings or calls Wire.
Optional OLED/RTC work can use ADC conversion wait time if the complete operation
fits before the next service deadline. The loop sleeps a tick when time permits
and checks short deadlines without adding a mandatory full tick to every phase.
PSRAM FIFO and block SD writes remain in place. No recorded sample is replaced
with display-filtered data.

## Verification

Host tests cover all 300 integer profiles, shared JS/Python TLV bytes, C++ timing
bounds and slot readback, unchanged v1.0 fixture bytes, forward protection,
invalid/fractional input, JSON import/export, and EEPROM failure injection.
Browser tests cover presets, manual 137 Hz, 1 Hz and 300 Hz, preservation of
unapplied input while polling, the recording lock, no implicit SAVE and mobile
layout. Hardware results are recorded below after the actual runs.

Reproduce a bounded production sweep through the running USB panel:

```text
python tools/test_rate_range.py --hardware --label my-rate-test --seconds 10
```

It creates new recordings, leaves them on SD and restores the exact starting
runtime configuration on normal completion. Private evidence goes under
`data/production-rates/`. Download the resulting files and run
`tools/analyze_rate_record.py` to verify their integrity with both readers.

## Hardware acceptance — 2026-09-08

Measurements used the connected bench load (roughly 3.26 V / 3.09 A), nominal 150 µΩ shunt and existing coefficients. Acquisition firmware was built clean from `d52defec1bcc0f23bfe114e185d7e43f83e8ff10`. No calibration, RTC write or EEPROM SAVE was performed.

All 15 files were downloaded over native Wi-Fi: **60,759 rows, 12,674,362 bytes**. Both the strict native reader and production streaming viewer verified CRC/checkpoints/SHA, raw-to-engineering values, timestamps and integration. Every file closed cleanly, with zero missing sequences, invalid rows or gap rows.

| Requested Hz | Verified rows | Measured Hz | OLED frames during test |
| --- | --- | --- | --- |
| 1 | 9 | 1.000006 | 26 |
| 5 | 45 | 4.999993 | 26 |
| 10 | 91 | 9.999922 | 26 |
| 25 | 225 | 24.999972 | 23 |
| 37 | 336 | 37.000049 | 24 |
| 50 | 452 | 49.999867 | 24 |
| 100 | 900 | 99.999956 | 16 |
| 137 | 1,223 | 137.005115 | 52 |
| 150 | 1,342 | 150.014230 | 52 |
| 200 | 1,797 | 200.000245 | 47 |
| 250 | 2,231 | 249.996805 | 51 |
| 299 | 2,661 | 299.042121 | 37 |
| 300 | 4,810 | 300.029591 | 61 |
| 300 | 36,405 | 300.029897 | 424 |

The 1 Hz file integrates normally: final energy `0.022424171 Wh`, gap threshold 2,000,000 µs. The long 300 Hz run covers about 121 seconds of samples: FIFO high-water 42 entries, maximum SD write 117.261 ms, no overflow. Owner state was fresh in all 109 sampled snapshots and OLED advanced 424 frames. Read-time intervals were 2513–4174 µs (p99 3447 µs); this is measured scheduling jitter, not a uniform timestamp claim.

A direct Wi-Fi mobile-browser run before the preview delivery adjustment recorded 8,232 verified rows at 300.029161 Hz with zero lost/invalid samples and 94 OLED frames. Its graph rendered about 59.88 FPS but only 16/25 observations were fresh, with up to 3.99 seconds of lag. This exposed the 48-point / 5-packet-per-second delivery ceiling; acquisition was unaffected.

The subsequent preview adjustment (`ab1e7d0`) was tested through the USB bridge during the long run: all 76 observations at RUNNING/300 Hz were fresh, median 59.83 FPS, no browser errors. USB deliberately marks skipped preview windows; all ADC samples remain in the verified file.

After the owner replaced the USB cable and reconnected UART, the final clean v0.22 build `ab1e7d0457238221d81c99c30223e886df434139` uploaded successfully on COM5 with Flash hash verification. Firmware SHA-256: `ed9697924b8f914b5144111ad9a38990cc54a982d7a4ef8778c5055a066d06fd`. This completes deployment of the revised embedded panel.

Direct Wi-Fi acceptance on that final build used the embedded page at a 390 × 844 mobile viewport: manual 300 Hz, Apply, Start and Stop. All **25/25** sampled graph observations were fresh, median rendering rate **59.90 FPS**, no browser errors, zero missed/invalid samples or FIFO overflows, and 98 OLED frames. The first CSV download timed out; a separate retry downloaded the complete 1,737,293-byte file in 9.969 seconds and restored the PC's original network.

The final record `r1s3_2026-09-08_15-27-02Z_3047473d_f5b0eb2c_0000.csv` contains **8,376 verified rows at 300.029294 Hz**. Both readers confirm clean closure, integrity, raw values and integration, with zero missing sequences, invalid rows or gap rows. File SHA-256: `aef5a75c9cd200e3377e2da3a6ddf307cb667b16eb58b0e7c1b91e004af58a05`. Read-time intervals were 2587–4092 µs (median 3335 µs, p99 3492 µs). Together with the initial 15 files, acceptance now covers **16 files, 69,135 rows and 14,411,655 bytes**.

Final runtime checks confirm READY at **100 Hz**, I2C 100 kHz, the exact original volatile config payload and unchanged EEPROM generation **3**. No EEPROM SAVE was performed; the panel's UNSAVED indication remains expected because the original runtime profile differs from the persisted profile. The USB panel reconnects, sample/uptime values advance and its graph renders at about 59.71 FPS without browser errors.

These bounded tests support this implementation on the present bench setup. They do not close the earlier unexplained reset, intermittent USB-UART issue, long-duration endurance or full-range metrology work.

A later ROM-entry test reproduced UART failure with the new USB cable while
Wi-Fi acquisition remained responsive. See the separate
[UART diagnostic report](UART_DIAGNOSTICS.md); the successful rate tests above
must not be treated as proof of permanent USB-UART reliability.

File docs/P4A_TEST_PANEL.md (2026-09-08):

# Device test panel v0.20

This is the device control interface, separate from the deferred offline recording viewer.
It reuses the recovered R1 instrument colors: cyan current, yellow voltage, pink power,
a dark graph and compact tabs. It reports actual timed samples, not simulated data.

## Opening the panel

- **PC, USB-UART:** connect the UART connector, close Termite/PlatformIO Serial Monitor,
  then run device_ui/start.cmd. It opens the loopback USB bridge on port 8767 with a
  per-run URL token. PlatformIO's Python with pyserial is used; another installation
  can run python device_ui/bridge.py --port COM5 --open.
- **Phone, standalone:** the normal firmware starts a password-protected AP named
  R1-S3-xxxx. Its generated password is visible in the USB panel's Wi-Fi tab
  and in the UART boot message. Join this network, keep the connection without Internet,
  and open http://192.168.4.1/. No PC bridge is needed for this route.
- Before flashing, use **Release USB for flashing** in Diagnostics or device_ui/stop.cmd.
  Closing only a browser tab does not release a serial port held by the bridge.
- Direct file:// opening is unsupported and displays launcher instructions.
  The existing offline viewer remains on its own port 8766.

The AP credential is generated on first use and stored in internal NVS at boot,
before the UI task starts. It is separate from the measurement EEPROM schema and
never exported in configuration profiles. This is the only new automatic persistent
write in this stage. There is no inherited donor password, cloud service or CDN.
STA/home-Wi-Fi provisioning is not implemented in this test panel.

## Available controls

| Control | Owner behavior |
|---|---|
| Live U/I/P, temperature, raw counts/shunt µV | Applied calibration coefficients; invalid/stale values shown as unavailable |
| U/I graph | 10/30 second viewport; 30/60 FPS rendering; real timestamped samples and visible gaps |
| Measurement frequency | Apply integer 1–300 Hz with visible ADC profile; Save remains explicit |
| Pause/clear graph | Browser display only; does not stop device conversions |
| Measure now | Fresh triggered INA228 conversion with ADC register restoration |
| I²C scan | Address acknowledgements/errors, only on explicit request after startup |
| SD read test | Mount and open root read-only, no format, no file creation |
| EEPROM read test | Two matching complete 4096-byte reads, no writes |
| RTC test / UTC sync | Read health; explicit host UTC write with register readback |
| Configuration | All 28 schema fields, local draft/difference, Apply, separate Save |
| Profile import/export | P1 r1s3-config v1.0 JSON envelope and exact TLV encoding |

Apply validates schema, bounds and INA timing before hardware register readback.
Failed readback retains the earlier applied configuration or exposes the existing
INA fault latch. Save uses the existing A/B footer-last store; no slider autosaves.
Boot identity and configuration revision reject stale edits after a reboot, another
panel's apply, or a UART settings transfer. An uncertain command timeout is never
automatically retried. Read the current device state before deciding what to repeat.

For the installed 400 A / 60 mV shunt, the default is 150 µΩ. The narrow ±40.96 mV
range cannot cover its full rating. Applying nominal values does not validate calibration.

## Task and memory boundaries

- Core 0: UART protocol service plus Wi-Fi AP and HTTP service in an explicitly pinned low-priority task.
- Core 1: existing Arduino hardware owner; INA, RTC, EEPROM, SD diagnostics and OLED.
- HTTP consumes a copied JSON snapshot and submits a bounded command queue. It never
  accesses Wire, SD, the mutable configuration or the recording buffers.
- UART executes the same owner-side command dispatcher and uses request identifiers
  so old responses cannot be mistaken for a new request.
- Web, UART and owner stacks are internal RAM, 24 KiB each. Queue/control storage is internal;
  the existing sample pool remains explicitly allocated in PSRAM and SD staging is
  8 KiB internal DMA-capable RAM.
- Firmware snapshots publish up to twice per second; the browser/USB bridge polls about
  once per second, with separate live batches at the configured delivery target. Heartbeat freshness is checked independently from HTTP success:
  a responding web task cannot make a frozen owner snapshot look live.

The embedded HTML is generated from device_ui/index.template.html, style.css,
codec.js, app.js and the existing config registry. tools/build_panel.py emits
the USB HTML and a gzip PROGMEM asset; PlatformIO regenerates it through a pre-build hook.
No browser libraries or assets are fetched from the Internet.

## Scope and limits

The timed acquisition/live portion of P4b is now active. See
[v0.15 scheduling, quality and transport](P4B_LIVE_ACQUISITION.md).
OLED data is sent in short chunks by the single I2C owner. The browser independently
animates up to 60 FPS. Maintenance commands pause acquisition and mark a gap.

[Production SD sessions](P5_RECORDING.md), totals and file downloads are implemented.
The stopped recorder reallocates the FIFO at the next START after a budget change;
Save remains a separate explicit action. Browser disconnect does not request STOP.

The encoder remains a no-GPIO stub. Local menus, confirmed input GPIO and optional
AP lifecycle controls remain pending. See [P6 Wi-Fi acceptance](P6_WIFI.md) for
native-radio tests, separately from the earlier USB evidence.

## v0.14 baseline validation

For current cadence acceptance, see [v0.15 results](P4B_LIVE_ACQUISITION.md).

- 40 host tests include the existing EEPROM fault injection and FIFO tests, plus JS/Python
  TLV agreement, invalid inputs and loopback API token/origin/size boundaries.
- Chrome fixture acceptance covers dirty drafts, invalid values, external revision
  changes, disconnected/frozen data and responsive layout.
- Physical USB acceptance: normal firmware upload, live INA values, reversible OLED
  contrast Apply/restore through the real browser, and saved generation 3 retained.
- Physical API tests passed for INA, I²C, SD read, EEPROM read and RTC read. A stale boot
  SAVE command was rejected. The complete post-upload EEPROM image matches the pre-panel
  backup byte for byte (CRC32 EBDAE9A1). No EEPROM Save or clock adjustment was needed.
- Normal and explicit service configurations compile; only normal firmware is flashed.
- Native AP startup is reported by the board. Phone-to-AP browser operation still
  needs the owner's check; desktop USB acceptance is not evidence of that radio path.

Private EEPROM backups, live captures and connection credentials remain under
private backup folders / ignored data/, outside the public repository.

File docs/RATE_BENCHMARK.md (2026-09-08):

# Rate and noise experiments

> Historical v0.21 sweep. The subsequent user-approved 1–300 Hz implementation is documented in [Measurement rates](MEASUREMENT_RATES.md). Results below describe the earlier scheduler.

The normal profile still offers 10/50/100 Hz. Experimental results do not promote
a higher rate or a different ADC preset automatically. The owner requested a
measured speed/noise comparison before choosing supported compromises.

`esp32-s3-benchmark` is a separate build, labelled `0.21-bench` in the panel and
recording metadata. It accepts experimental requested rates from 10 to 1000 Hz;
normal configuration validation remains unchanged. EEPROM writes are blocked at
both command and storage levels in the benchmark build. The UI displays a warning.

Through the existing revision-checked command queue, `BENCH Hz CT AVG I2C_Hz seconds`
starts one recording with equal shunt/bus/temperature CT codes, selected averaging
and either 100 or 400 kHz I2C. Duration is 5–600 seconds. The hardware owner stops
the recording and restores the previous volatile profile and I2C clock after
finalization, without depending on the browser or PC timer. Reboot still loads
the previously saved EEPROM profile. Other settings/calibration are preserved.

`tools/rate_bench.py --hardware --label <unique-label> --cases <cases>` drives an
explicit sequence through the local USB bridge; cases are semicolon-separated
`Hz:CT:AVG:I2C_Hz:seconds`. It requires idle benchmark firmware and writes private
snapshots/results to ignored `data/rate-tests/`. A reboot or failed restore stops
the sequence. Normal firmware does not accept BENCH.

Benchmark CSV files retain the native integrity/raw/config metadata contract,
but rates outside the released registry require an explicit diagnostic reader
override. They are not new supported production presets. A normal viewer rejects
an unsupported configuration instead of silently assuming its meaning.

TI documents the trade-off between conversion time, averaging and noise in
sections 7.3.4.2 and 8.1.3 of the [INA228 datasheet](https://www.ti.com/lit/ds/symlink/ina228.pdf).
The present default uses three sequential 1052 us conversions without averaging.
Bench dispersion includes source ripple, wiring and measurement noise; it is not
an independent ADC-noise or calibration measurement. Comparisons must report
actual cadence, gaps/invalid samples, file integrity, UI/OLED availability and
the load conditions as well as observed dispersion.

## Initial evidence

On 2026-09-08 an initial v0.20 100 Hz run rebooted without owner intervention;
the old bridge had not retained a reset trace. It is not counted as stable.
A second 300-second run, with the owner disconnected from the panel, completed
30,031 rows and 6,262,019 bytes with zero missed/invalid samples and FIFO overflow.
FIFO high-water was 12, maximum write 66.460 ms and maximum sync 105.373 ms.
At that stage only device counters were available; full-file validation is below. The first reboot's
cause is unresolved. The updated bridge retains a bounded private UART diagnostic
log, and v0.21 reports `esp_reset_reason()` for subsequent failures.

## Completed measurements — 2026-09-08

The following ceilings apply to this firmware and this bench, not to the INA228
silicon's theoretical limit. The released UI still offers 10/50/100 Hz. No faster
preset has been promoted or saved to EEPROM.

| Mode | Verified recording | Control/display consequence |
|---|---|---|
| Default ADC, 100 kHz I2C, 100 Hz | 300 s, 30,031 rows, 99.999995 Hz, no missing/invalid rows | Normal state and OLED updates |
| Default ADC, 100 kHz I2C, 125 Hz | 20 s, 2,473 rows, no missing rows | State nearly frozen; not a usable general preset |
| CT=150 us/channel, 400 kHz I2C, 200 Hz | 120 s, 23,959 rows, 199.999983 Hz, no missing/invalid rows | State and OLED active; USB live preview sometimes lags |
| Same 200 Hz profile, direct Wi-Fi | 30 s, 5,957 rows, 200.005776 Hz, no missing/invalid rows | 28/28 observed live updates fresh; median 59.87 FPS; OLED +46 frames |
| CT=50 us/channel, 400 kHz I2C, 330 Hz | 90 s, 29,615 rows, 330.030638 Hz, no missing/invalid rows | No OLED progress; state frozen for about 88 s; diagnostic recording only |
| CT=50 us/channel, 400 kHz I2C, 350 Hz | 15 s, delivered 333.626 Hz, 242 missing sequence numbers | Requested rate is not sustained |

The timed duration includes arming/finalization; delivered rate is calculated from
the first and last verified sample timestamps. Integer microsecond periods explain
small nominal-rate differences such as 330.03 Hz. All cases use averaging=1;
CT codes 0/2/3/5 mean 50/150/280/1052 us per channel. All three channels remain
enabled with the original range, shunt, gains, offsets and polarity.

The 200 Hz USB browser run added six to the device's lifetime missed-period counter
near completion. **The complete recording has zero sequence gaps and zero GAP or
INVALID rows.** The lifetime counter also includes acquisition outside the file's
recording interval; it must not be substituted for per-file integrity/cadence checks.
USB preview was fresh in 44/117 observed RUNNING snapshots despite about 59.9 FPS
animation. A separate direct-Wi-Fi test was therefore necessary; it had fresh preview
in every observed RUNNING snapshot and no lifetime missed-period increase. Browser
tests used Chrome on the PC at a 390 x 844 viewport, not a physical Android device.

The 330 Hz test's FIFO high-water was only 59 samples with no overflow, despite a
174.949 ms maximum SD write. At 200 Hz/120 s it was 18 samples, maximum write
75.747 ms and sync 80.611 ms. The tested rate ceiling is primarily in the present
trigger/poll/read scheduling and shared-I2C work, not exhaustion of the PSRAM FIFO.
The owner loop calls `delay(1)` and only publishes state with >1800 us slack,
updates an OLED chunk with >2600 us, and polls RTC with >4500 us. Raising the
requested rate can therefore starve state/OLED/RTC work before the recorder loses
samples. Separate cores alone do not eliminate this shared-owner constraint.

### Observed dispersion, not an accuracy calibration

The load was approximately 3.26 V and 3.09 A during these recordings. It was not
re-measured against an independent reference during this sweep. Standard deviation
includes supply/load ripple, wiring, drift and ADC noise.

| Window | Current standard deviation | Voltage standard deviation |
|---|---:|---:|
| 100 Hz, CT=1052 us, initial 20 s | 15.20 mA | 1.69 mV |
| 100 Hz, CT=50 us, 20 s | 67.75 mA | 4.53 mV |
| 200 Hz, CT=150 us, 120 s | 44.50 mA | 3.96 mV |
| 330 Hz, CT=50 us, 90 s | 69.21 mA | 4.75 mV |

Long-record read-completion intervals also have jitter: 100 Hz/300 s ranged
7.959–12.030 ms (p99 11.012); 200 Hz/120 s ranged 2.908–7.107 ms (p99 6.076);
330 Hz/90 s ranged 2.392–4.461 ms (p99 4.004). They are timestamped measurements,
not a claim of uniform sub-millisecond sampling or simultaneous channel conversion.

### File integrity and the earlier reboot

All 31 downloaded experiment artifacts were parsed by both the contract decoder and production
viewer adapter. Thirty completed files pass metadata/block CRC, final SHA-256,
raw/calibrated value, time and integration checks with no unverified tail. This
includes overload cases whose marked sequence gaps and incomplete totals are
intentional evidence of a failed requested cadence, not successful rate tests.

The initial reboot left
`r1s3_2026-09-08_12-38-26Z_199455ff_d06bba0e_0000.part`: 2,885,599 bytes, 13,808
checkpoint-verified rows, no unverified/partial trailing row and no END record.
Its persisted span is about 138.07 s at 100 Hz. Both readers correctly classify it
as interrupted. It remains on SD and its copy is retained on the PC. Samples still
in RAM at the interruption cannot be recovered from this file. The owner confirmed
no reset or power intervention. The cause remains unresolved; there was no further
unexpected reboot during the subsequent experimental sweep or direct-Wi-Fi test.

Experimental-rate files require `tools/analyze_rate_record.py --experimental-rate`;
this relaxes only the diagnostic rate registry to 10..1000 Hz, not integrity or
sample validation. The ordinary viewer still rejects unpromoted rates. The release
reader accepts the 100 Hz baseline and interrupted recording without an override.
Original recordings and private reports are under ignored `data/rate-tests/`.

### Complete sweep

Missing sequence numbers below come from full downloaded files. OLED progress and
state age come from device snapshots and include boundary work; a single frame in
a whole test is not evidence of a continuously usable display.

| Requested Hz | CT code | I2C kHz | Timed s | Actual Hz | Missing seq | OLED frames | Max stale state s |
|---:|---:|---:|---:|---:|---:|---:|---:|
| 100 | 5 | 100 | 20 | 100.000 | 0 | 15 | 0.0 |
| 125 | 5 | 100 | 20 | 125.000 | 0 | 1 | 18.1 |
| 150 | 5 | 100 | 20 | 133.242 | 332 | 0 | 18.1 |
| 200 | 5 | 100 | 20 | 133.175 | 1322 | 1 | 19.2 |
| 250 | 5 | 100 | 20 | 133.191 | 2310 | 0 | 18.2 |
| 100 | 0 | 100 | 20 | 100.000 | 0 | 31 | 0.0 |
| 150 | 0 | 100 | 20 | 150.008 | 0 | 1 | 0.0 |
| 200 | 0 | 100 | 20 | 200.000 | 0 | 1 | 18.1 |
| 250 | 0 | 100 | 20 | 219.787 | 597 | 0 | 18.1 |
| 400 | 0 | 100 | 20 | 219.539 | 3566 | 0 | 18.1 |
| 200 | 0 | 400 | 20 | 200.010 | 0 | 32 | 0.0 |
| 250 | 0 | 400 | 20 | 250.000 | 0 | 0 | 0.0 |
| 300 | 0 | 400 | 20 | 300.032 | 0 | 0 | 8.5 |
| 400 | 0 | 400 | 20 | 333.535 | 1313 | 1 | 18.1 |
| 500 | 0 | 400 | 20 | 333.619 | 3286 | 0 | 18.1 |
| 800 | 0 | 400 | 20 | 334.008 | 9202 | 0 | 19.3 |
| 1000 | 0 | 400 | 20 | 333.991 | 13155 | 1 | 19.3 |
| 320 | 0 | 400 | 15 | 320.001 | 0 | 0 | 13.2 |
| 330 | 0 | 400 | 15 | 330.033 | 0 | 1 | 13.2 |
| 350 | 0 | 400 | 15 | 333.626 | 242 | 0 | 13.3 |
| 225 | 0 | 400 | 20 | 225.029 | 0 | 2 | 0.0 |
| 150 | 5 | 400 | 20 | 150.015 | 0 | 0 | 2.4 |
| 200 | 5 | 400 | 20 | 166.691 | 659 | 1 | 19.2 |
| 200 | 3 | 400 | 20 | 200.000 | 0 | 3 | 0.0 |
| 100 | 5 | 100 | 20 | 100.000 | 0 | 15 | 0.0 |
| 330 | 0 | 400 | 90 | 330.031 | 0 | 0 | 88.1 |
| 200 | 2 | 400 | 20 | 200.000 | 0 | 31 | 0.0 |
| 200 | 2 | 400 | 120 | 200.000 | 0 | 184 | 0.0 |

### Next decision

Keep the current 100 Hz default-quality mode while selecting the next supported
presets explicitly with the owner. A 200 Hz / 150 us / 400 kHz profile is a useful
candidate with a visible noise trade-off and direct-Wi-Fi preview. The 330 Hz raw
ceiling is not yet suitable for a user-facing preset because state/OLED updates
starve. Before promoting it, separate state publication from acquisition slack,
budget OLED/RTC work and re-test command responsiveness, timing and longer sessions.
Higher-rate normal files also need a coordinated versioned config/viewer contract
update. No claims are made about overnight stability, every SD card, physical
Android acceptance, 400 kHz EEPROM writes or the cause of intermittent USB uploads.

After the sweep, normal v0.21 from clean commit
`0781a4047c34cd411e33868540fb15e0a129398b` was flashed with ROM/no-stub at 38,400 baud
and flash hash verification. The final 100 Hz smoke recording has 628 verified
rows / 134,223 bytes, no gaps or invalid rows, and opens through the unmodified
production reader. The device is READY with the exact original volatile 100 Hz
profile, I2C 100 kHz and saved generation 3. No EEPROM Save or time adjustment was
performed. The original PC Wi-Fi profile was restored after every AP roundtrip.

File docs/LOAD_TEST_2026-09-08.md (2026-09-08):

# Load acceptance — 3 A / 3 V, 2026-09-08

PANEL v0.17 is deployed and passed the following USB bench checks. The owner
reported a 3 A / 3 V load. These are stability and transport results, not an
independent reference calibration. Shunt, gains, offsets and ADC settings were
unchanged. Rate changes used Apply only; the complete original configuration was
restored to 50 Hz afterward, with saved generation 3. No Save or clock adjustment
was issued.

## Acquisition

The shared I2C bus ran at 100 kHz with OLED enabled. Live rows were collected by
sequence; delivered frequency is calculated from their monotonic timestamps.

| Requested Hz | Window | Collected samples | Delivered Hz | Mean V | Mean A | Mean W |
|---:|---:|---:|---:|---:|---:|---:|
| 10 | 10 s | 99 | 10.0000 | 2.99718 | 3.00076 | 8.99382 |
| 50 | 10 s | 500 | 50.0002 | 2.99779 | 2.99891 | 8.99012 |
| 100 | 30 s | 3000 | 100.0004 | 2.99877 | 2.99953 | 8.99489 |

All three windows had zero invalid samples, missed periods, I2C errors, preview
producer drops, sequence gaps and history overruns. The 10 Hz count reflects the
capture boundary, not a missing sequence. Explicit Apply transitions are outside
the acceptance windows and retain their maintenance gap markers.

At 100 Hz, read-completion intervals ranged from 8.917 to 11.099 ms, averaging
9.99996 ms. Current ranged from 2.94583 to 3.05208 A (standard deviation 0.01568 A);
voltage ranged from 2.99277 to 3.00391 V (standard deviation 0.00168 V). INA228
temperature averaged 23.02 degrees C. The test cannot separate source ripple,
wiring noise and measurement noise. No new filtering or calibration was applied.

## Simultaneous acquisition and SD downloads

A further 60-second phase kept acquisition at 100 Hz while repeatedly downloading
the existing 4096-byte `/eeprom_before_0000.bin` file through the USB bridge.

- 40 completed downloads, 163,840 bytes total; mean transfer time 0.878 s.
- Each complete file matched SHA-256
  `78c5017e9cac1ce1807b838a3c168c10e8ab1776354b7e68abdaaa1b10cd8545`.
  The bridge also validates session, offset, size and per-block CRC32.
- Firmware counters advanced by 6069 valid samples at an observed 100.0 Hz,
  with zero invalid samples, missed periods, I2C errors, preview producer drops
  or maintenance pauses. Counter endpoints include request overhead.
- No reboot occurred. Minimum observed free internal heap was 134,184 bytes.
- Periodic Live tail snapshots contained 1920 points, averaging 3.00052 V,
  2.99909 A and 8.99883 W. These are sampled snapshots, not a complete archive
  of all 6069 acquired samples.
- State age relative to the fresh sample clock averaged 432 ms, maximum 708 ms.

After restoring 50 Hz, the real browser displayed numeric live readings and
rendered at 59.67 FPS in 60 FPS mode without JavaScript errors. Its reported
connection stayed online; the desktop screenshot was reviewed. This browser
acceptance occurred after the download phase, not concurrently with it.
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

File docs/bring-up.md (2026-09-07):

# Hardware bring-up

Historical checklist: 2026-09-06, HWTEST v0.6. Latest status: [migration journal](R1_MIGRATION.md), HWTEST v0.9, 2026-09-07; dated additions below supersede earlier pending items. Validate each subsystem before porting the original R1 application. Results below distinguish owner reports and captured logs from checks still pending.

## 1. Power and boot stability

- [ ] Record actual supply voltages, measurement conditions and common ground.
- [ ] Verify 3.3 V logic and no SDA/SCL pull-ups to 5 V against module schematics.
- [ ] Establish stable startup and reliable bootloader entry.
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

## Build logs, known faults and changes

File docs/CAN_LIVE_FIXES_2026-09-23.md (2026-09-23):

# Shared CAN workspace deployment — 2026-09-23

R1 shared CAN assets regenerated from ../GLL CANBox/workspace. Wi-Fi256 batch
negotiation, live-tail start, reconnect guard, endpoint persistence and visible
connection/time state. Token stays memory-only. Existing averaging owner changes
were preserved in the build; this commit stages only CAN assets and this report.

HOST TESTED:88 tests and esp32-s3-usb build PASS. BENCH TESTED: HTTP OTA app0→app1,
new boot/READY and unchanged config/generation. Version0.37-display-average-dev.
Real R1 /can displays122722 records/0 live-ring losses; MCP hardware overflow
remains separately unresolved. Reload keeps endpoint and clears token.
R1 remains connected to R3; CANBox UTC invalid because R3 service adapter absent.
No clock source/role reassignment, SD recording or vehicle test.

Full evidence/deployment boundaries and private log locations:
[CANBox report](../../GLL%20CANBox/docs/CAN_LIVE_FIXES_2026-09-23.md).

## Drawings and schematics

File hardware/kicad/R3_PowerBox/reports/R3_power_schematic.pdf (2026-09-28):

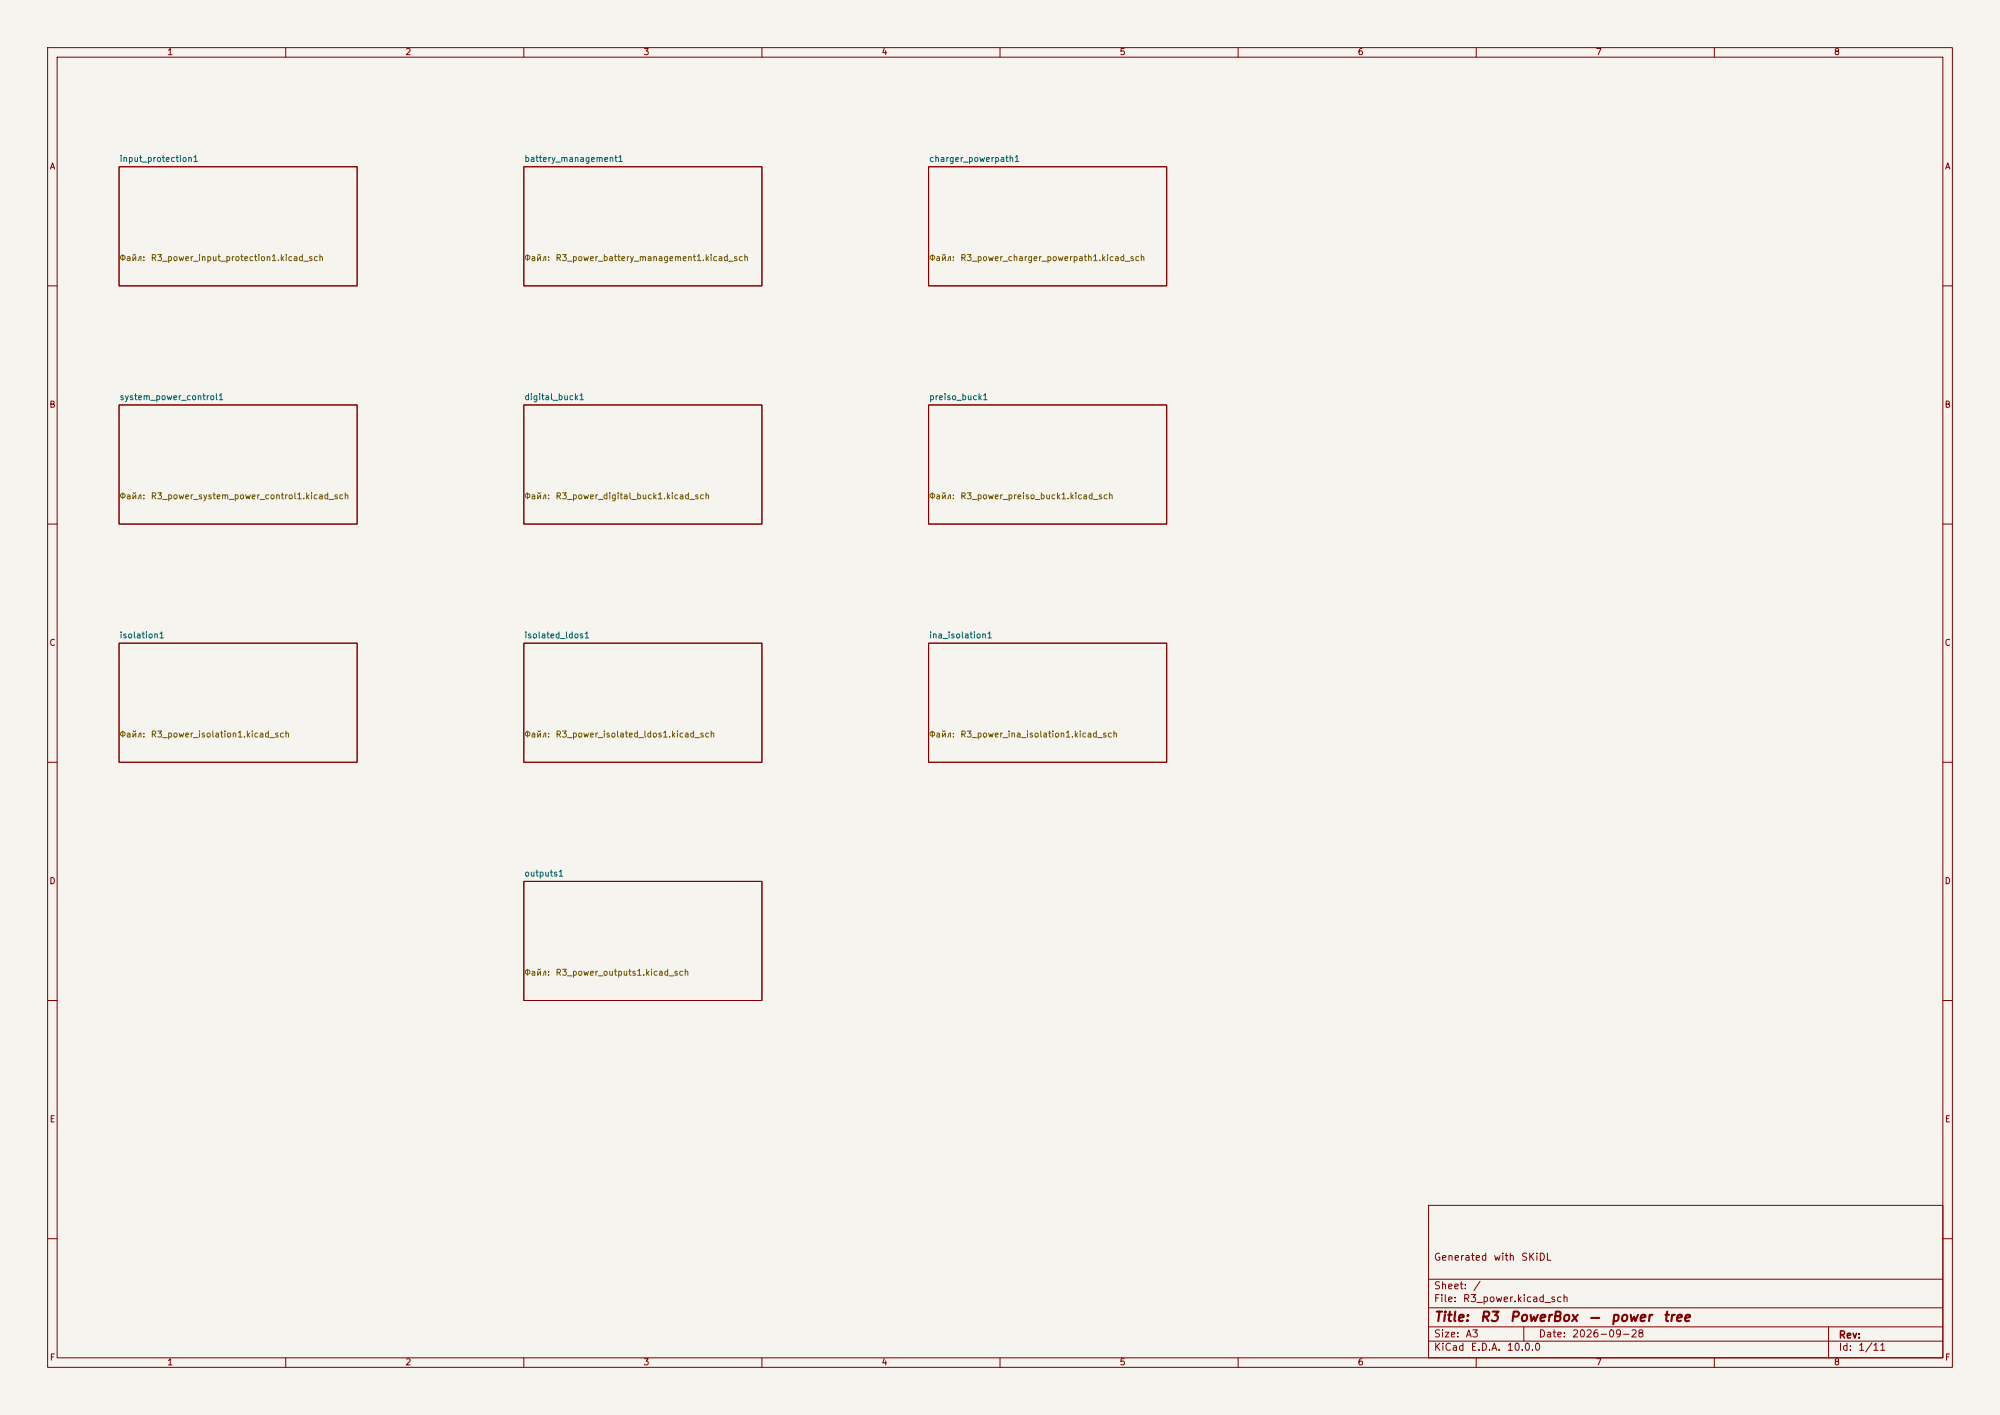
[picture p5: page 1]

Sheet: /
File: R3_power.kicad_sch
Title: R3 PowerBox — power tree

Size: A3 | Rev: | F Date: 2026-09-28 KiCad E.D.A. 10.0.0

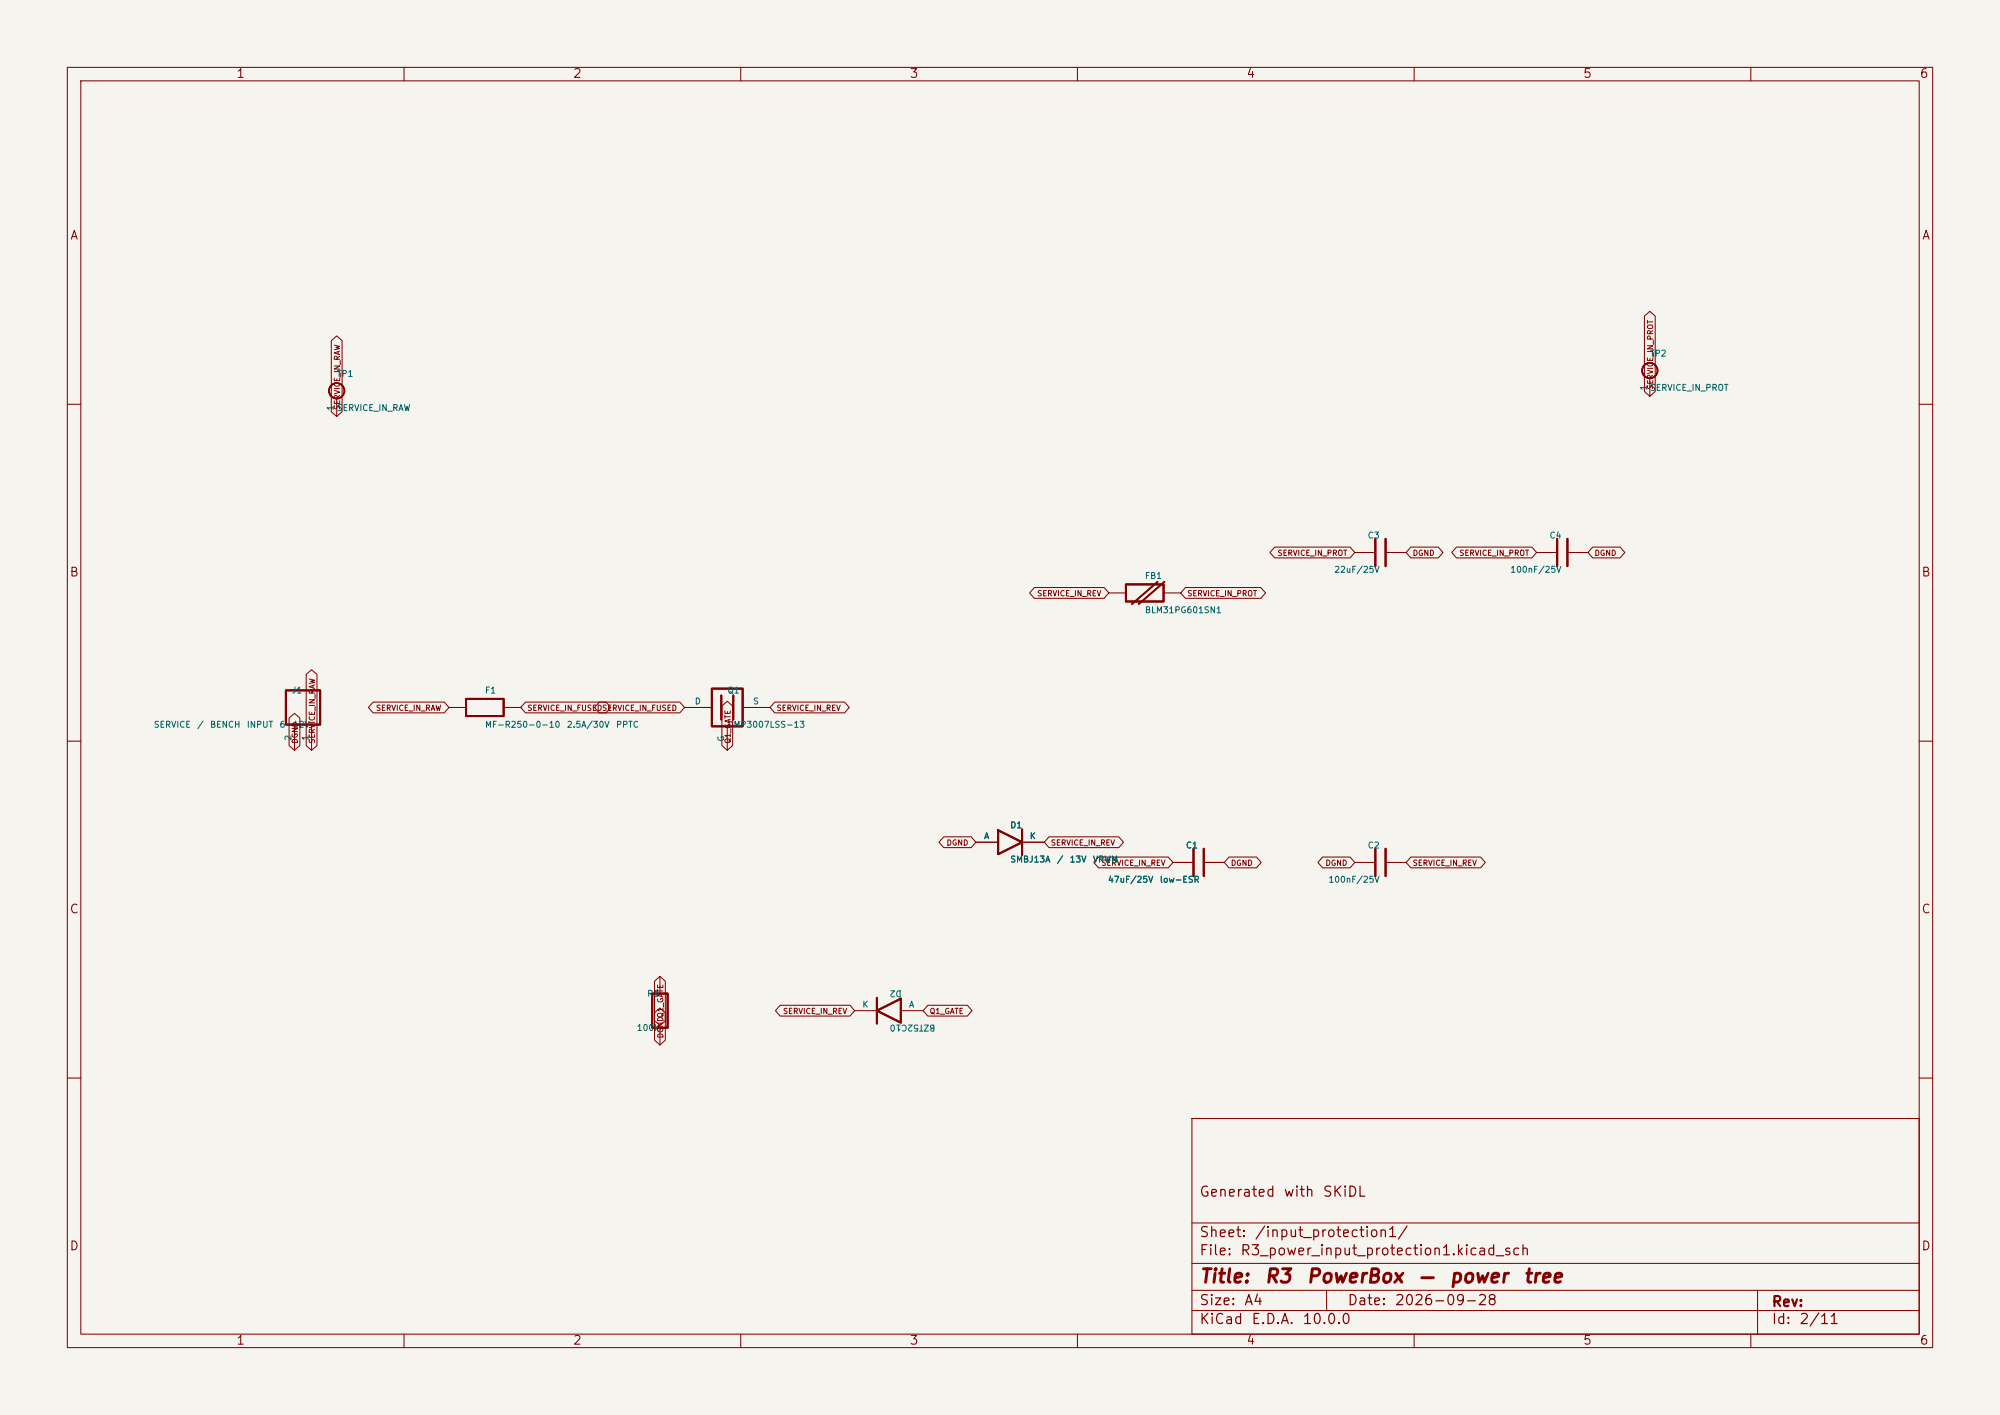
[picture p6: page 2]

Sheet: /input_protection1/
D Date: 2026-09-28 KiCad E.D.A. 10.0.0
File: R3_power_input_protection1.kicad_sch
Title: R3 PowerBox — power tree

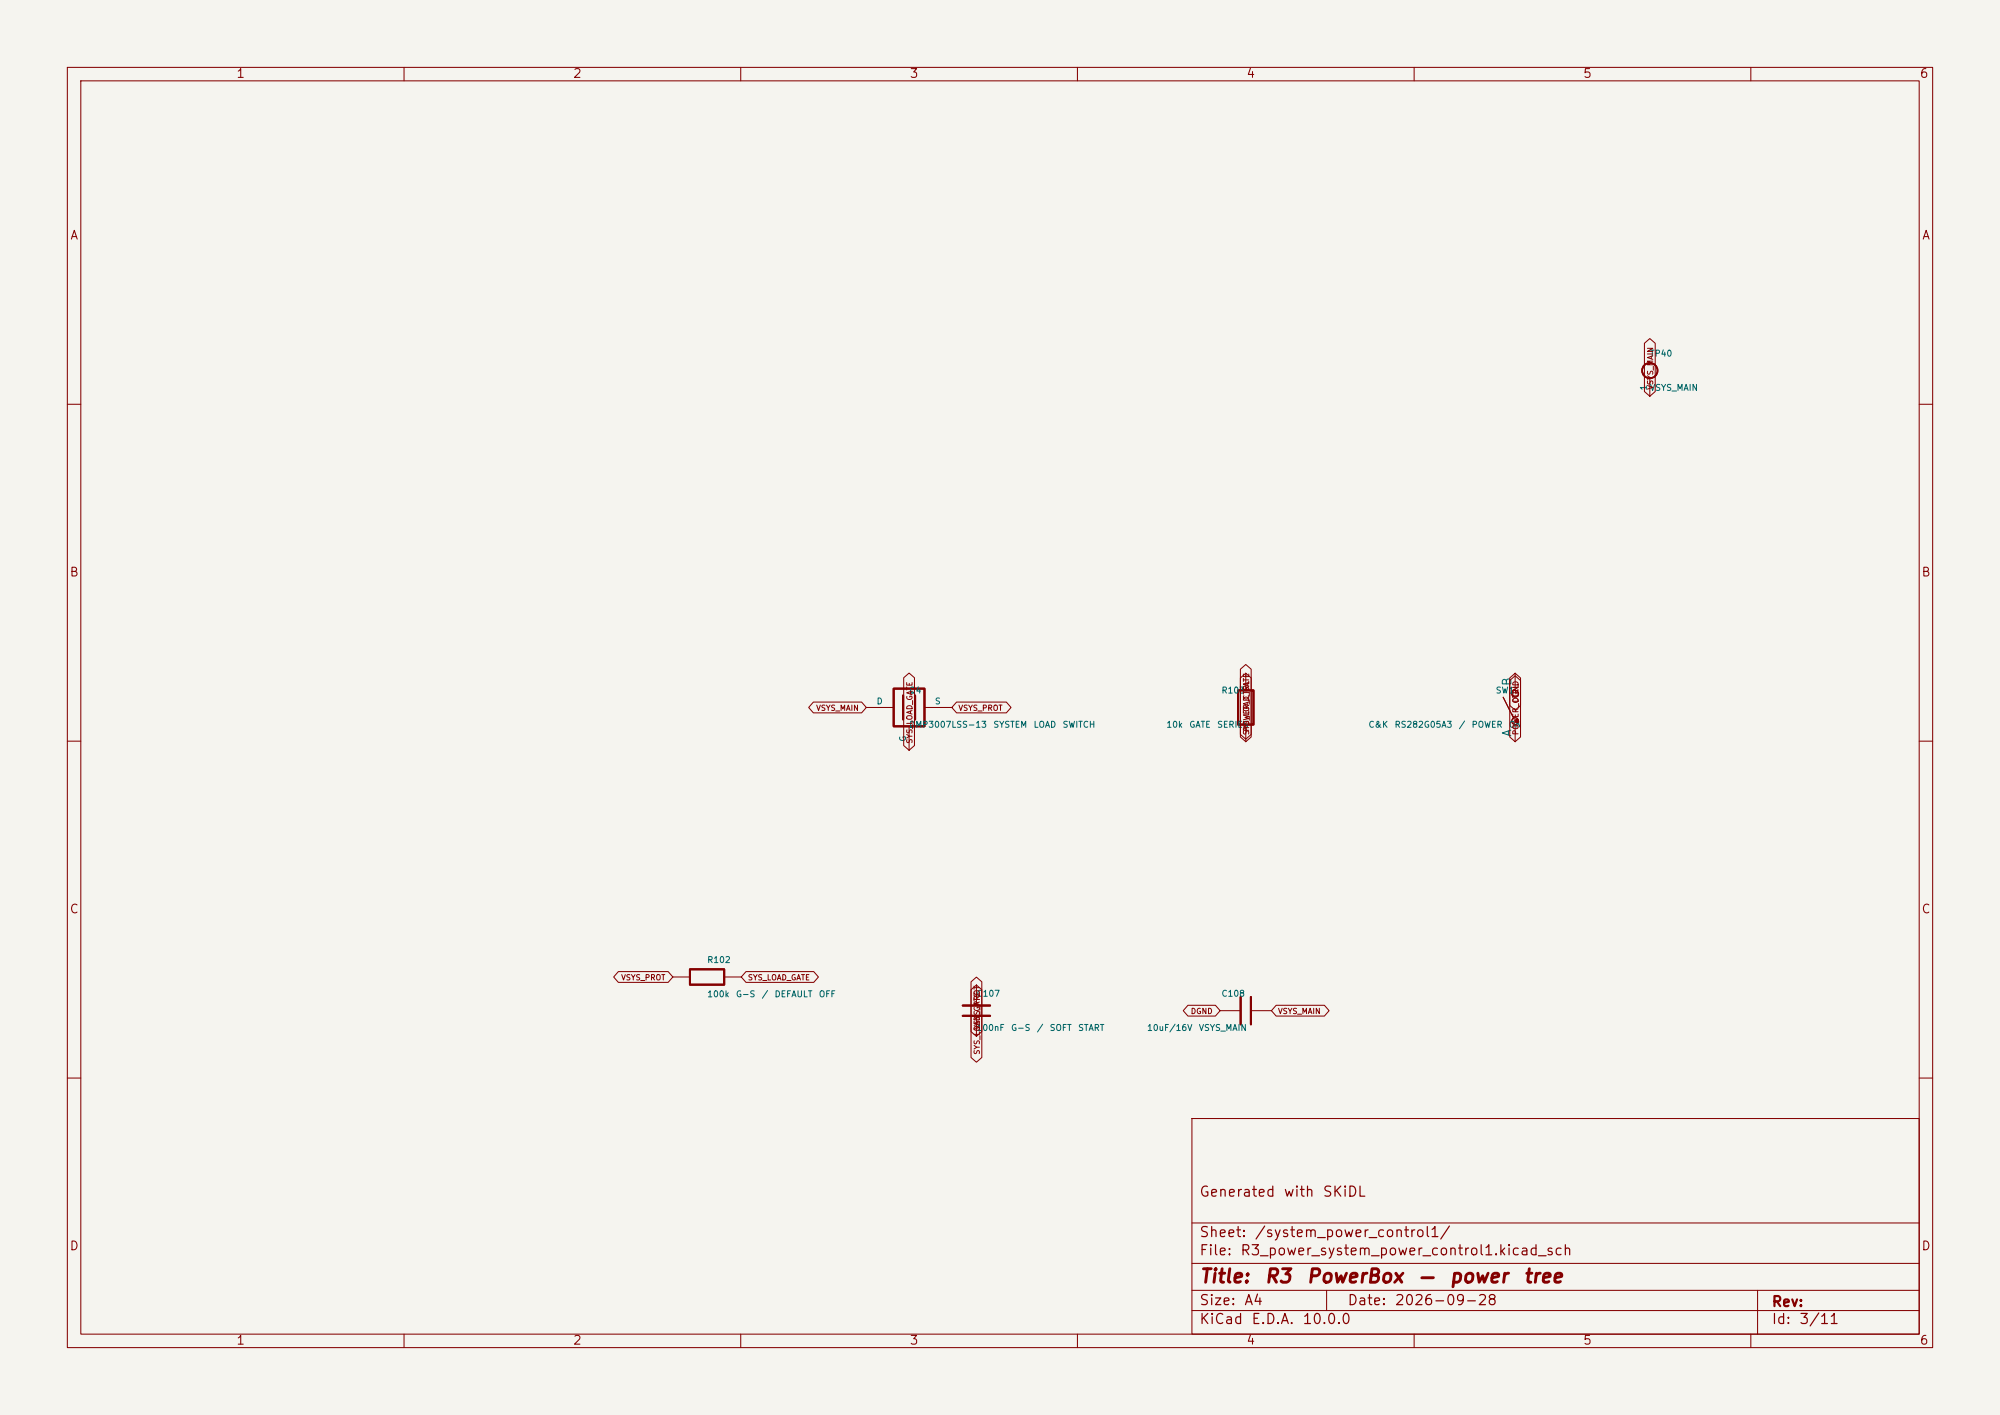
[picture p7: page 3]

Sheet: /system_power_control1/
D Date: 2026-09-28 KiCad E.D.A. 10.0.0
File: R3_power_system_power_control1.kicad_sch
Title: R3 PowerBox — power tree

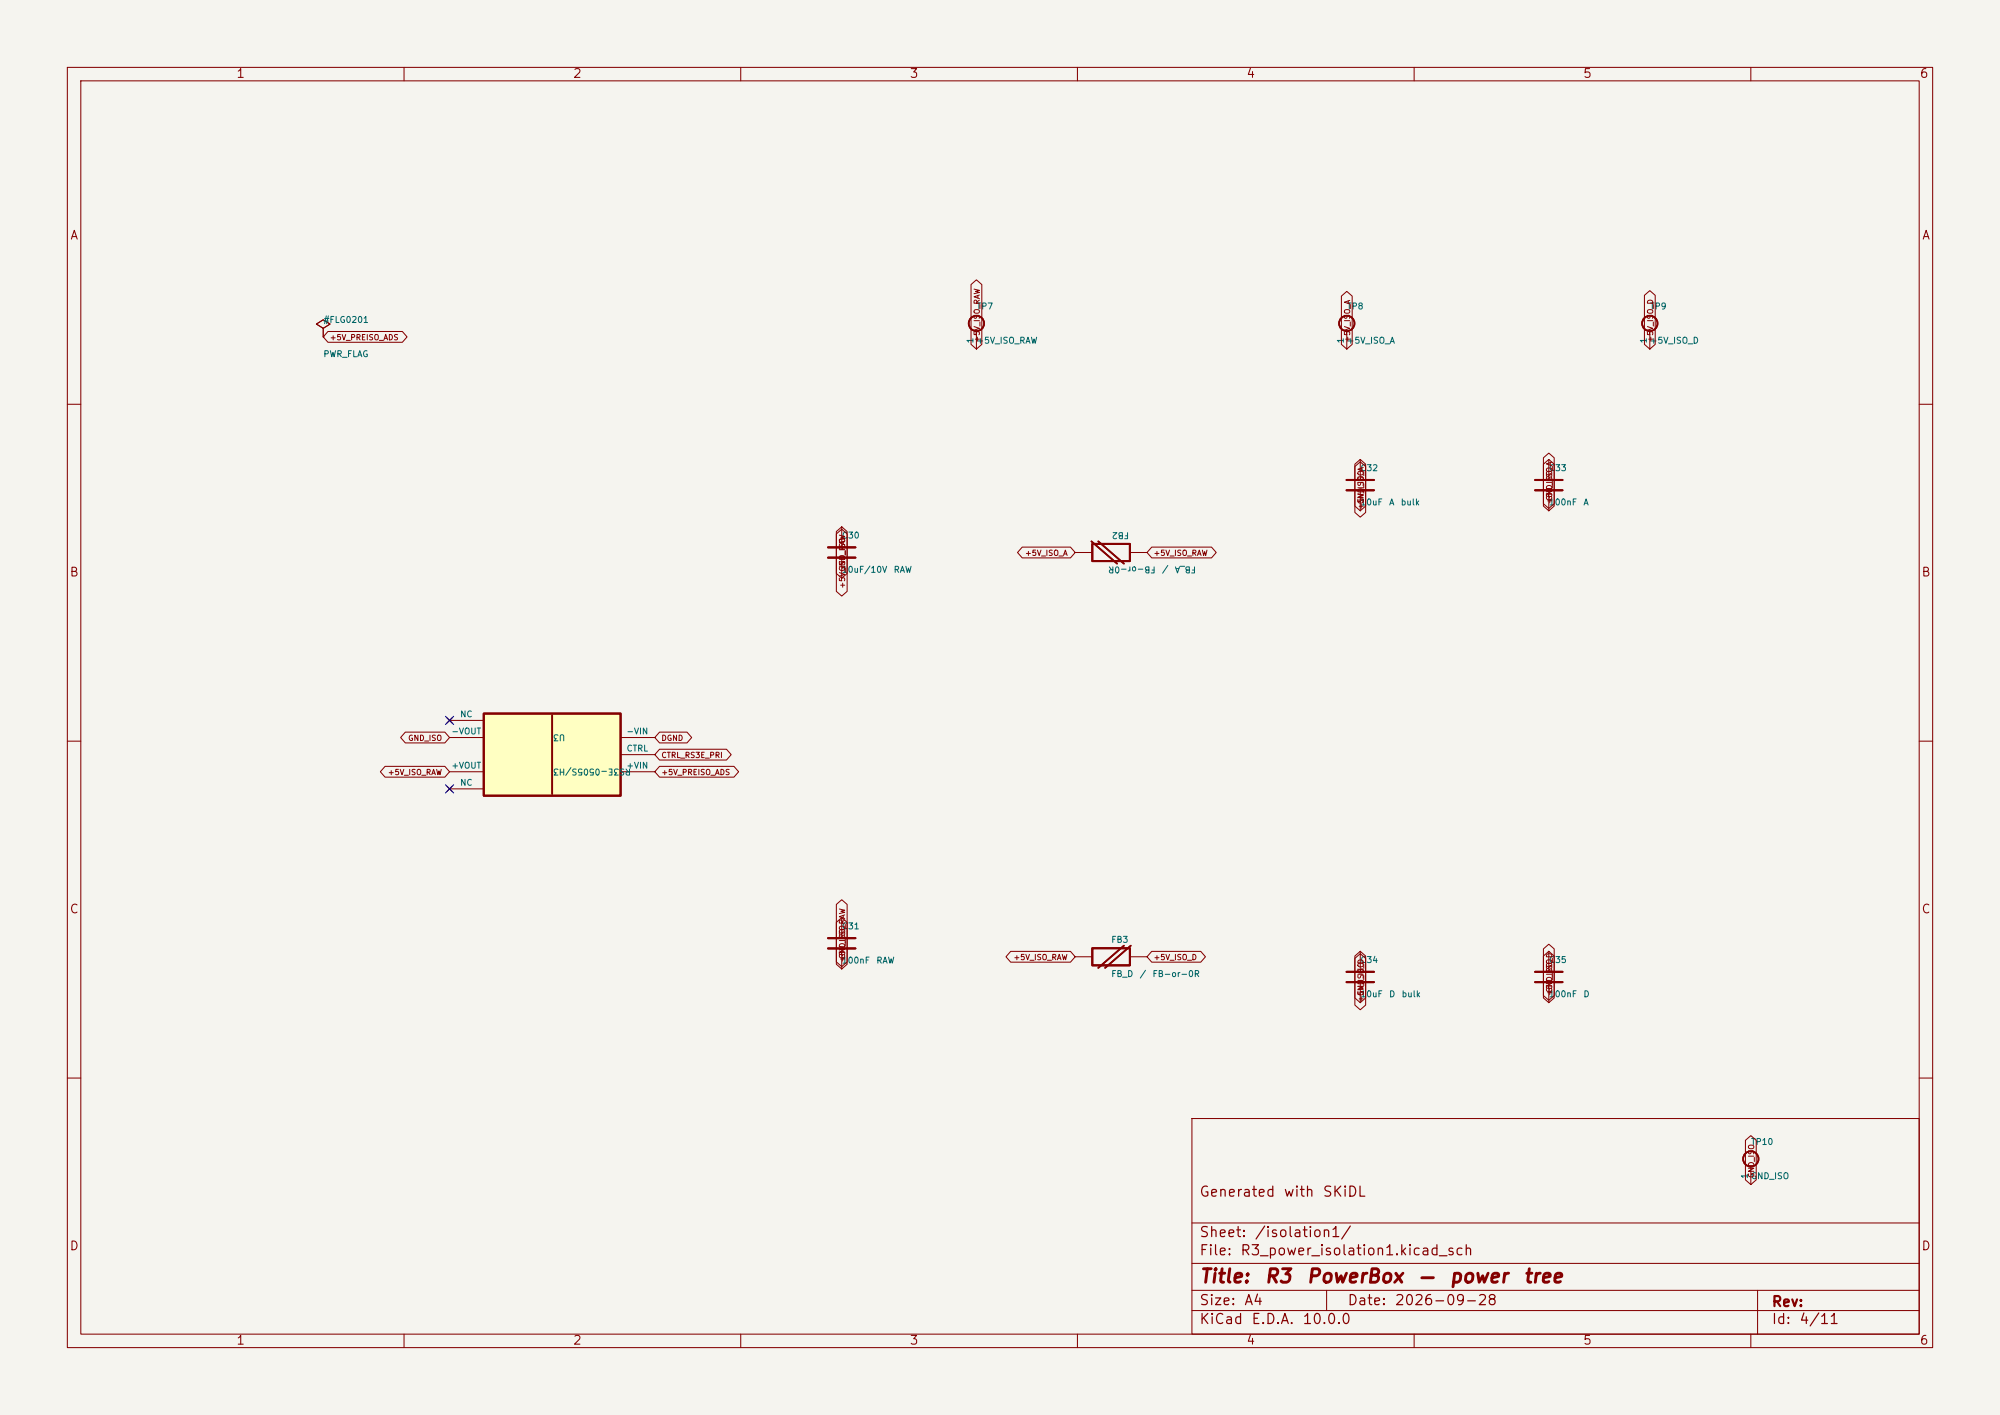
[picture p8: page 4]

Sheet: /isolation1/
D Date: 2026-09-28 KiCad E.D.A. 10.0.0
File: R3_power_isolation1.kicad_sch
Title: R3 PowerBox — power tree

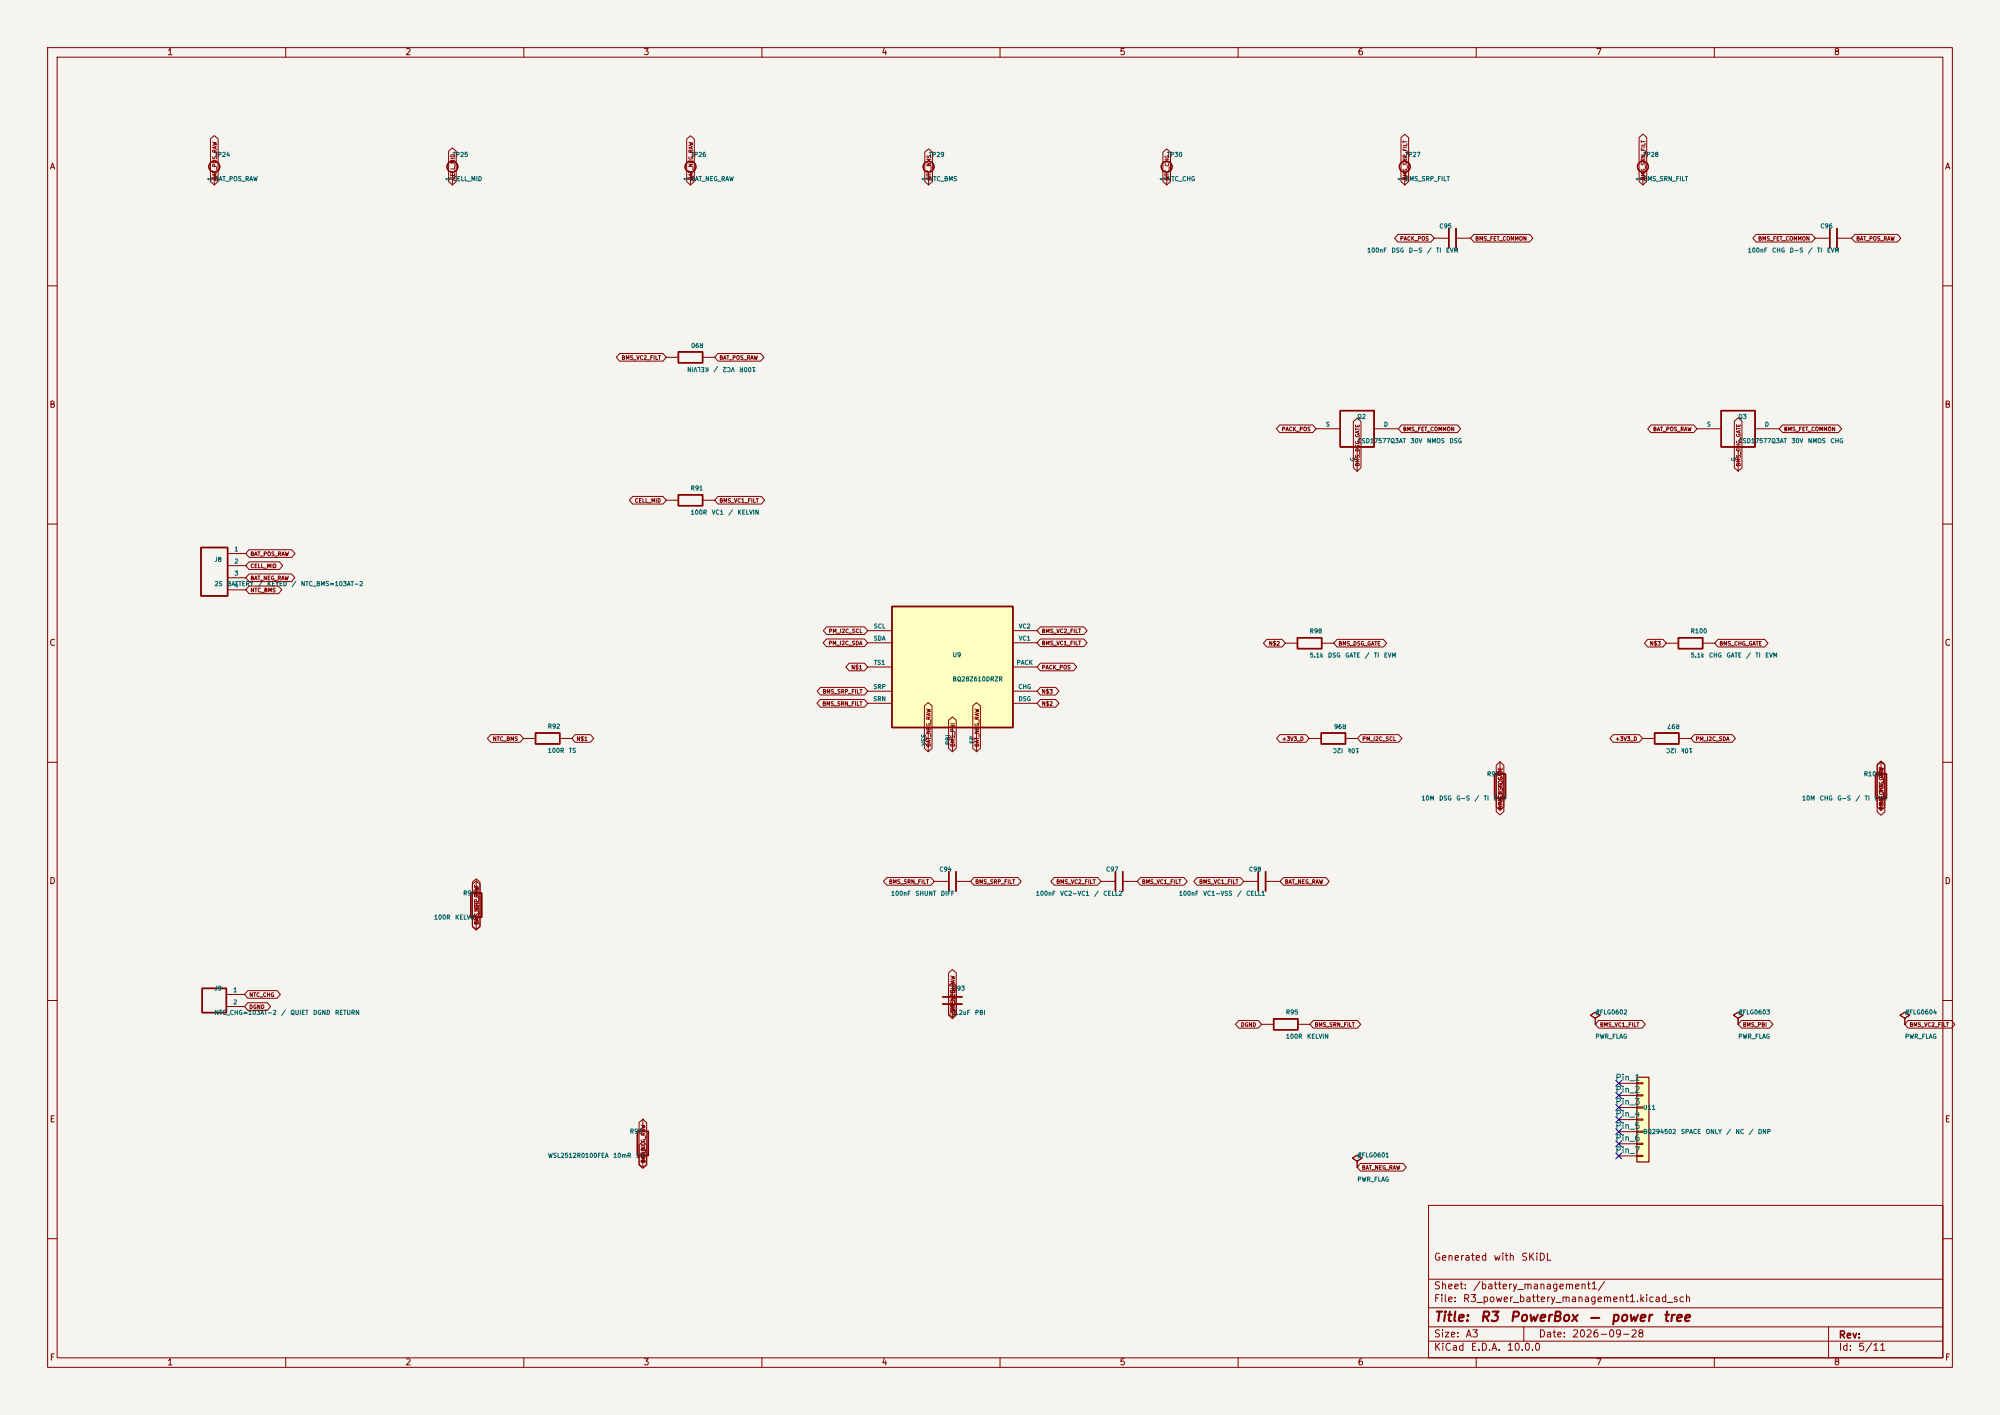
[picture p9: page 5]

5.1k DSG GATE / TI EVM

5.1k CHG GATE / TI EVM

U11 BQ294502 SPACE ONLY / NC / DNP

Sheet: /battery_management1/
File: R3_power_battery_management1.kicad_sch
Title: R3 PowerBox — power tree

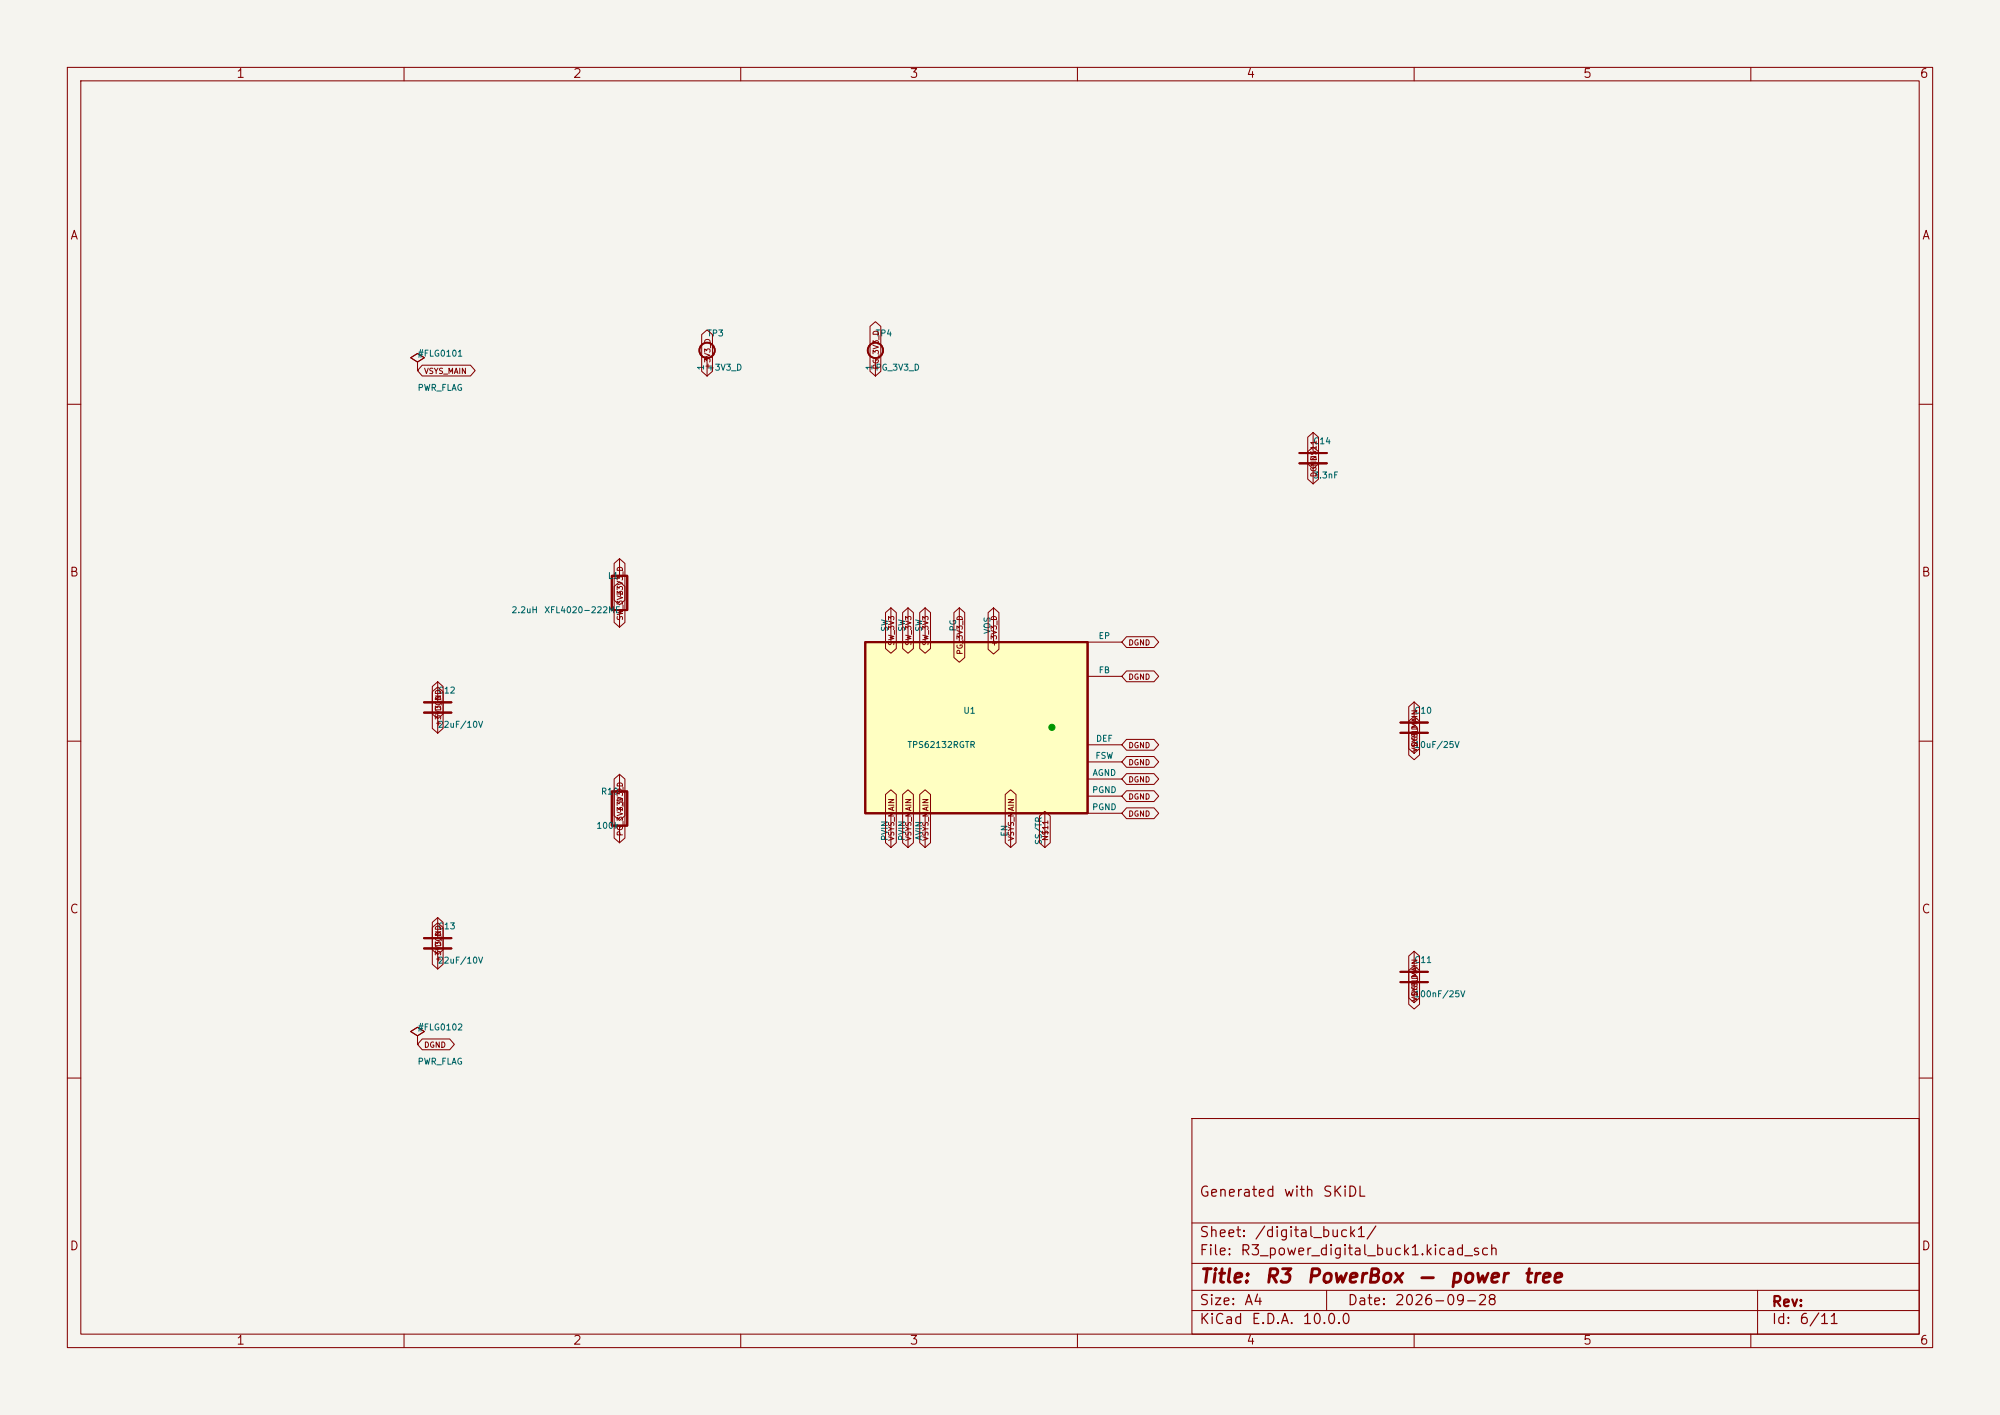
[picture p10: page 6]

Sheet: /digital_buck1/
D Date: 2026-09-28 KiCad E.D.A. 10.0.0
File: R3_power_digital_buck1.kicad_sch
Title: R3 PowerBox — power tree

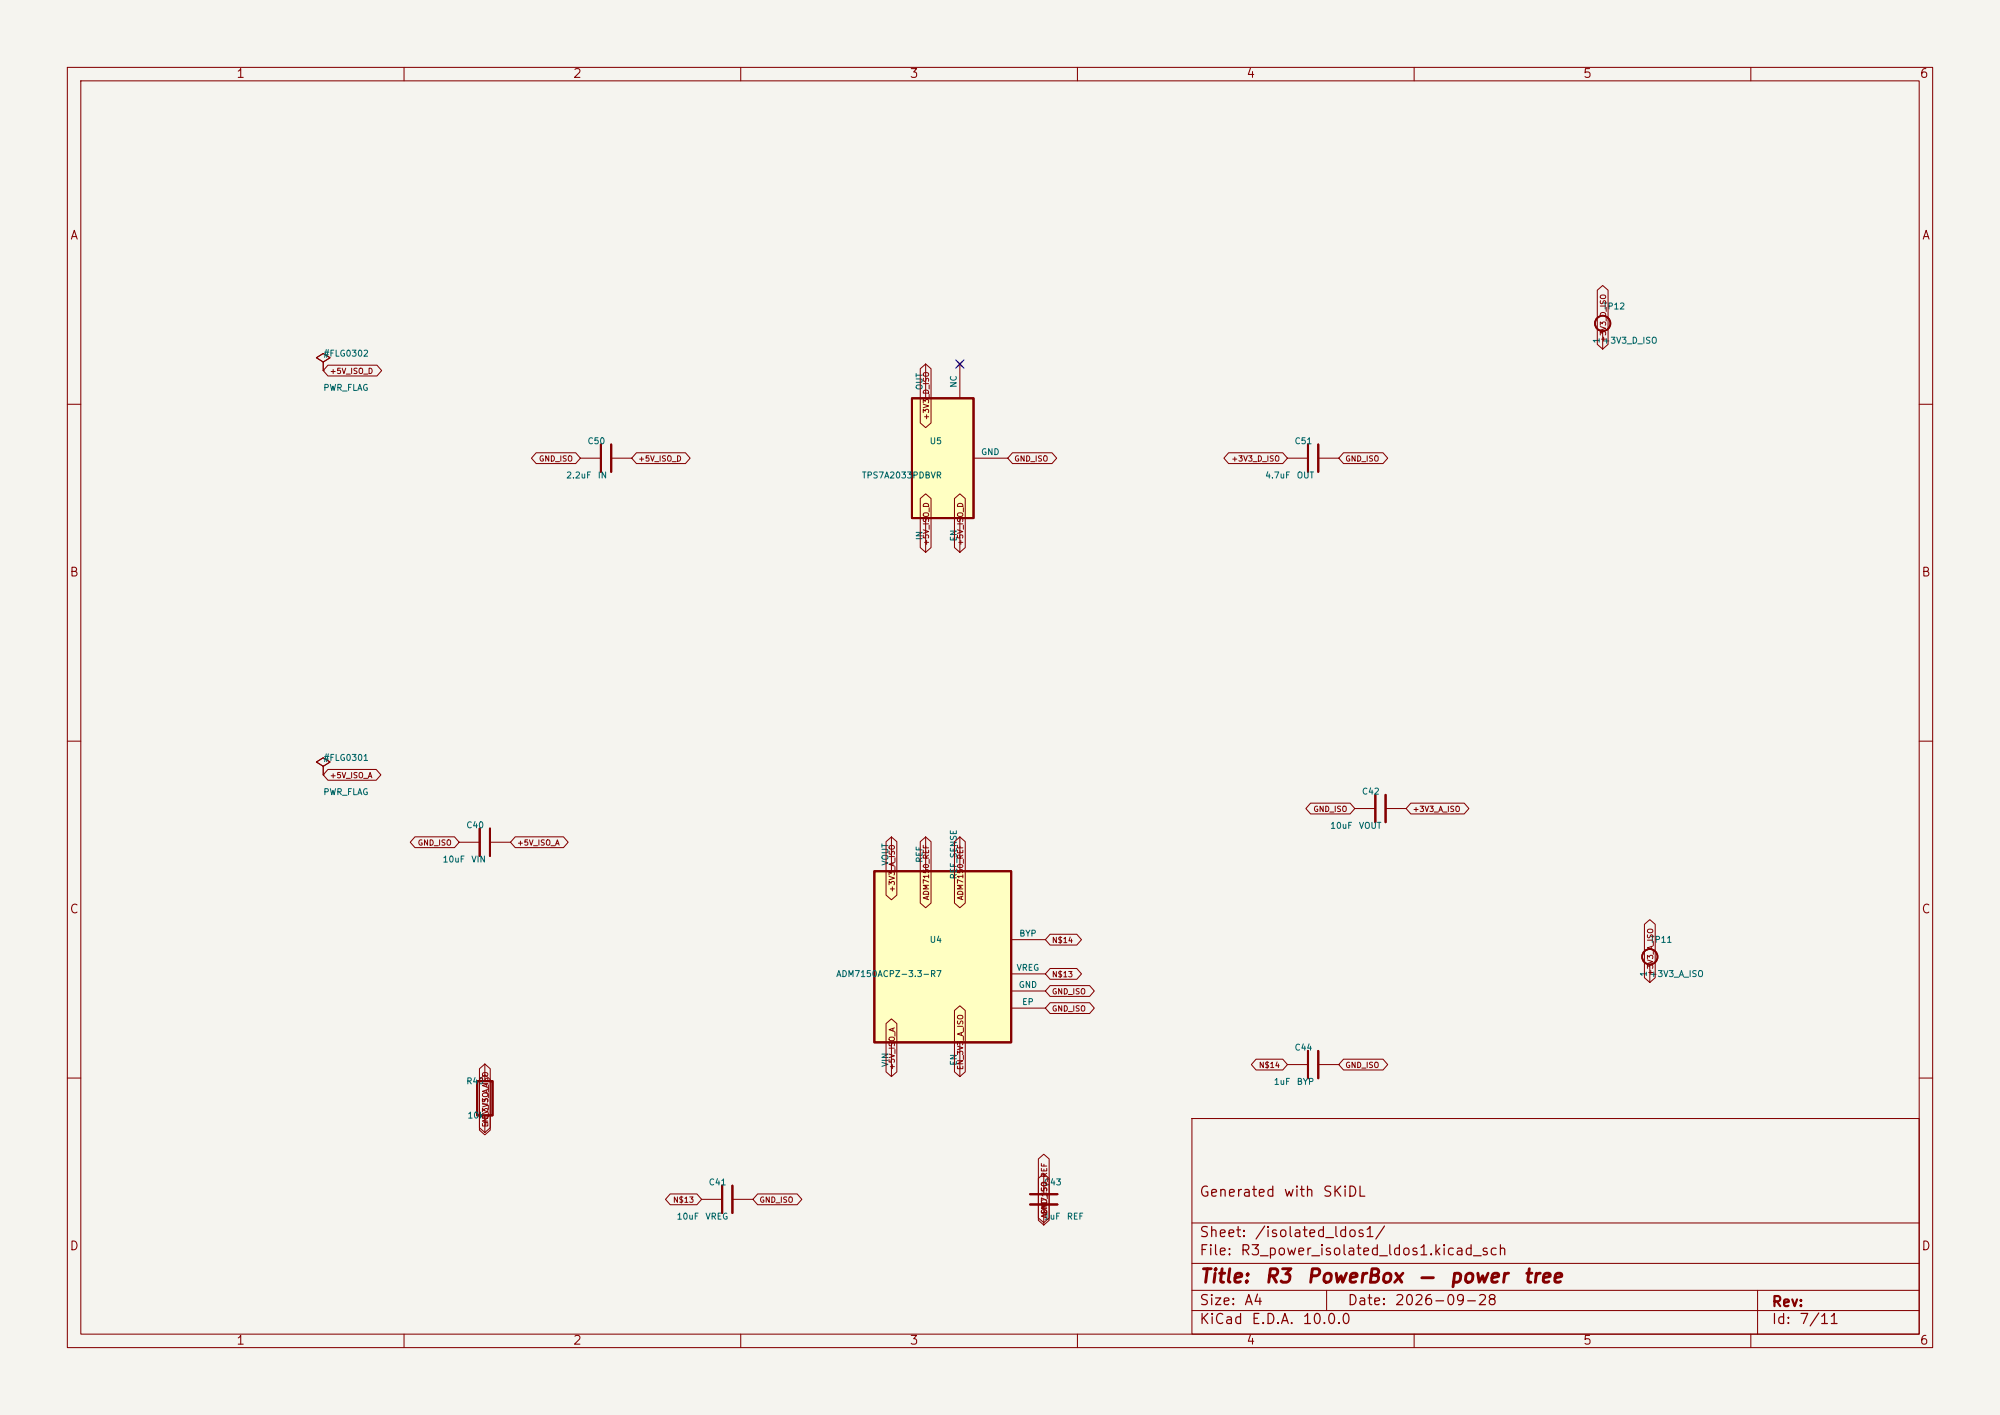
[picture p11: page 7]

Sheet: /isolated_ldos1/
D Date: 2026-09-28 KiCad E.D.A. 10.0.0
File: R3_power_isolated_ldos1.kicad_sch
Title: R3 PowerBox — power tree

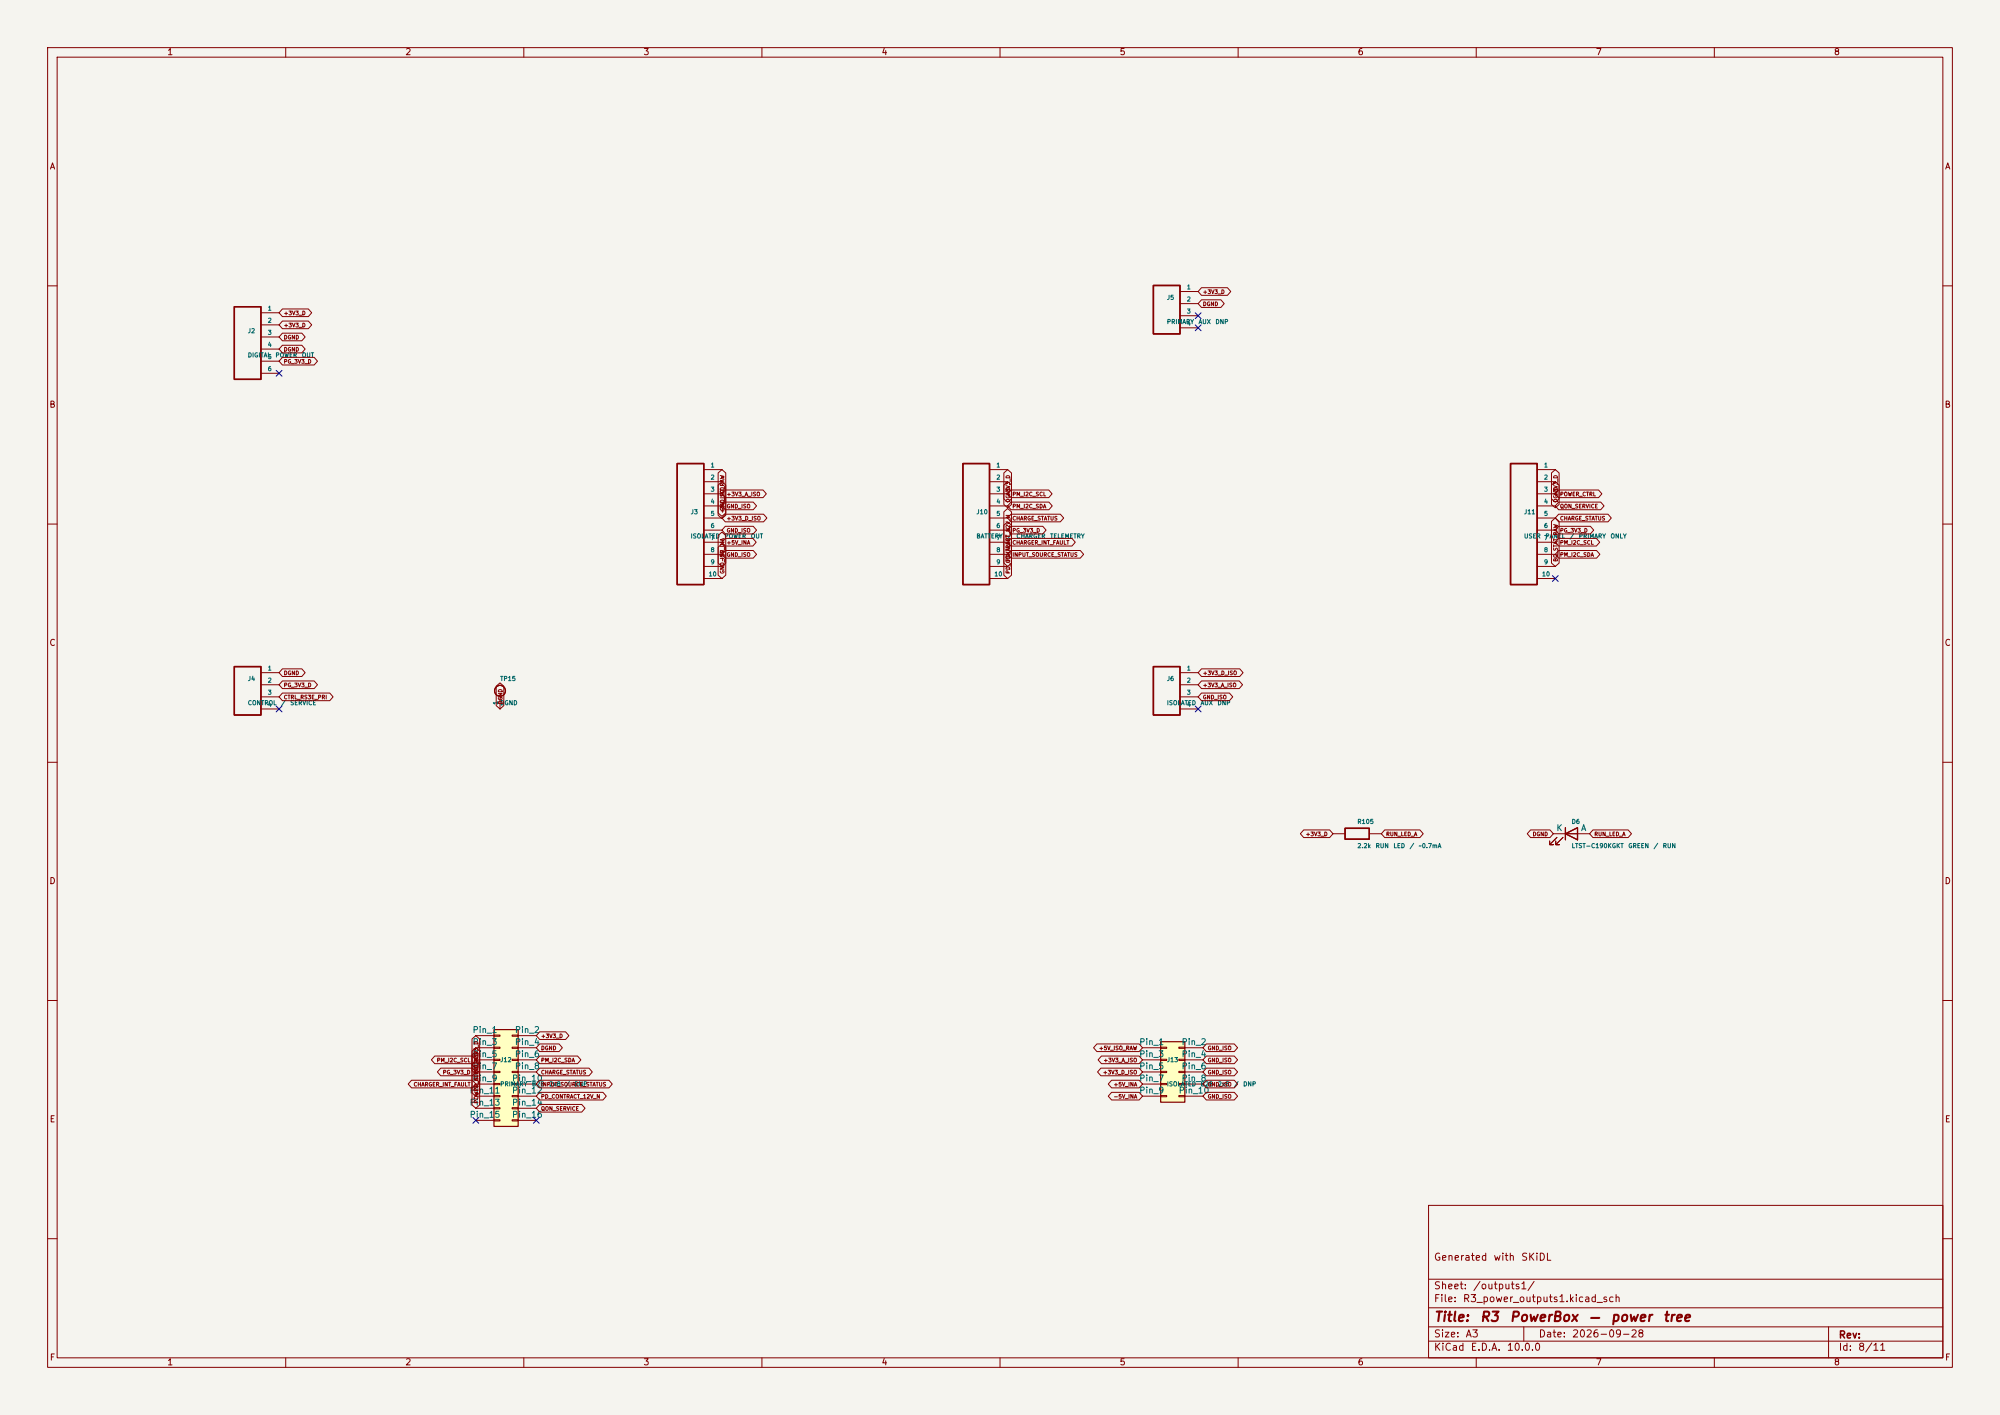
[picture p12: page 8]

Sheet: /outputs1/
File: R3_power_outputs1.kicad_sch
Title: R3 PowerBox — power tree

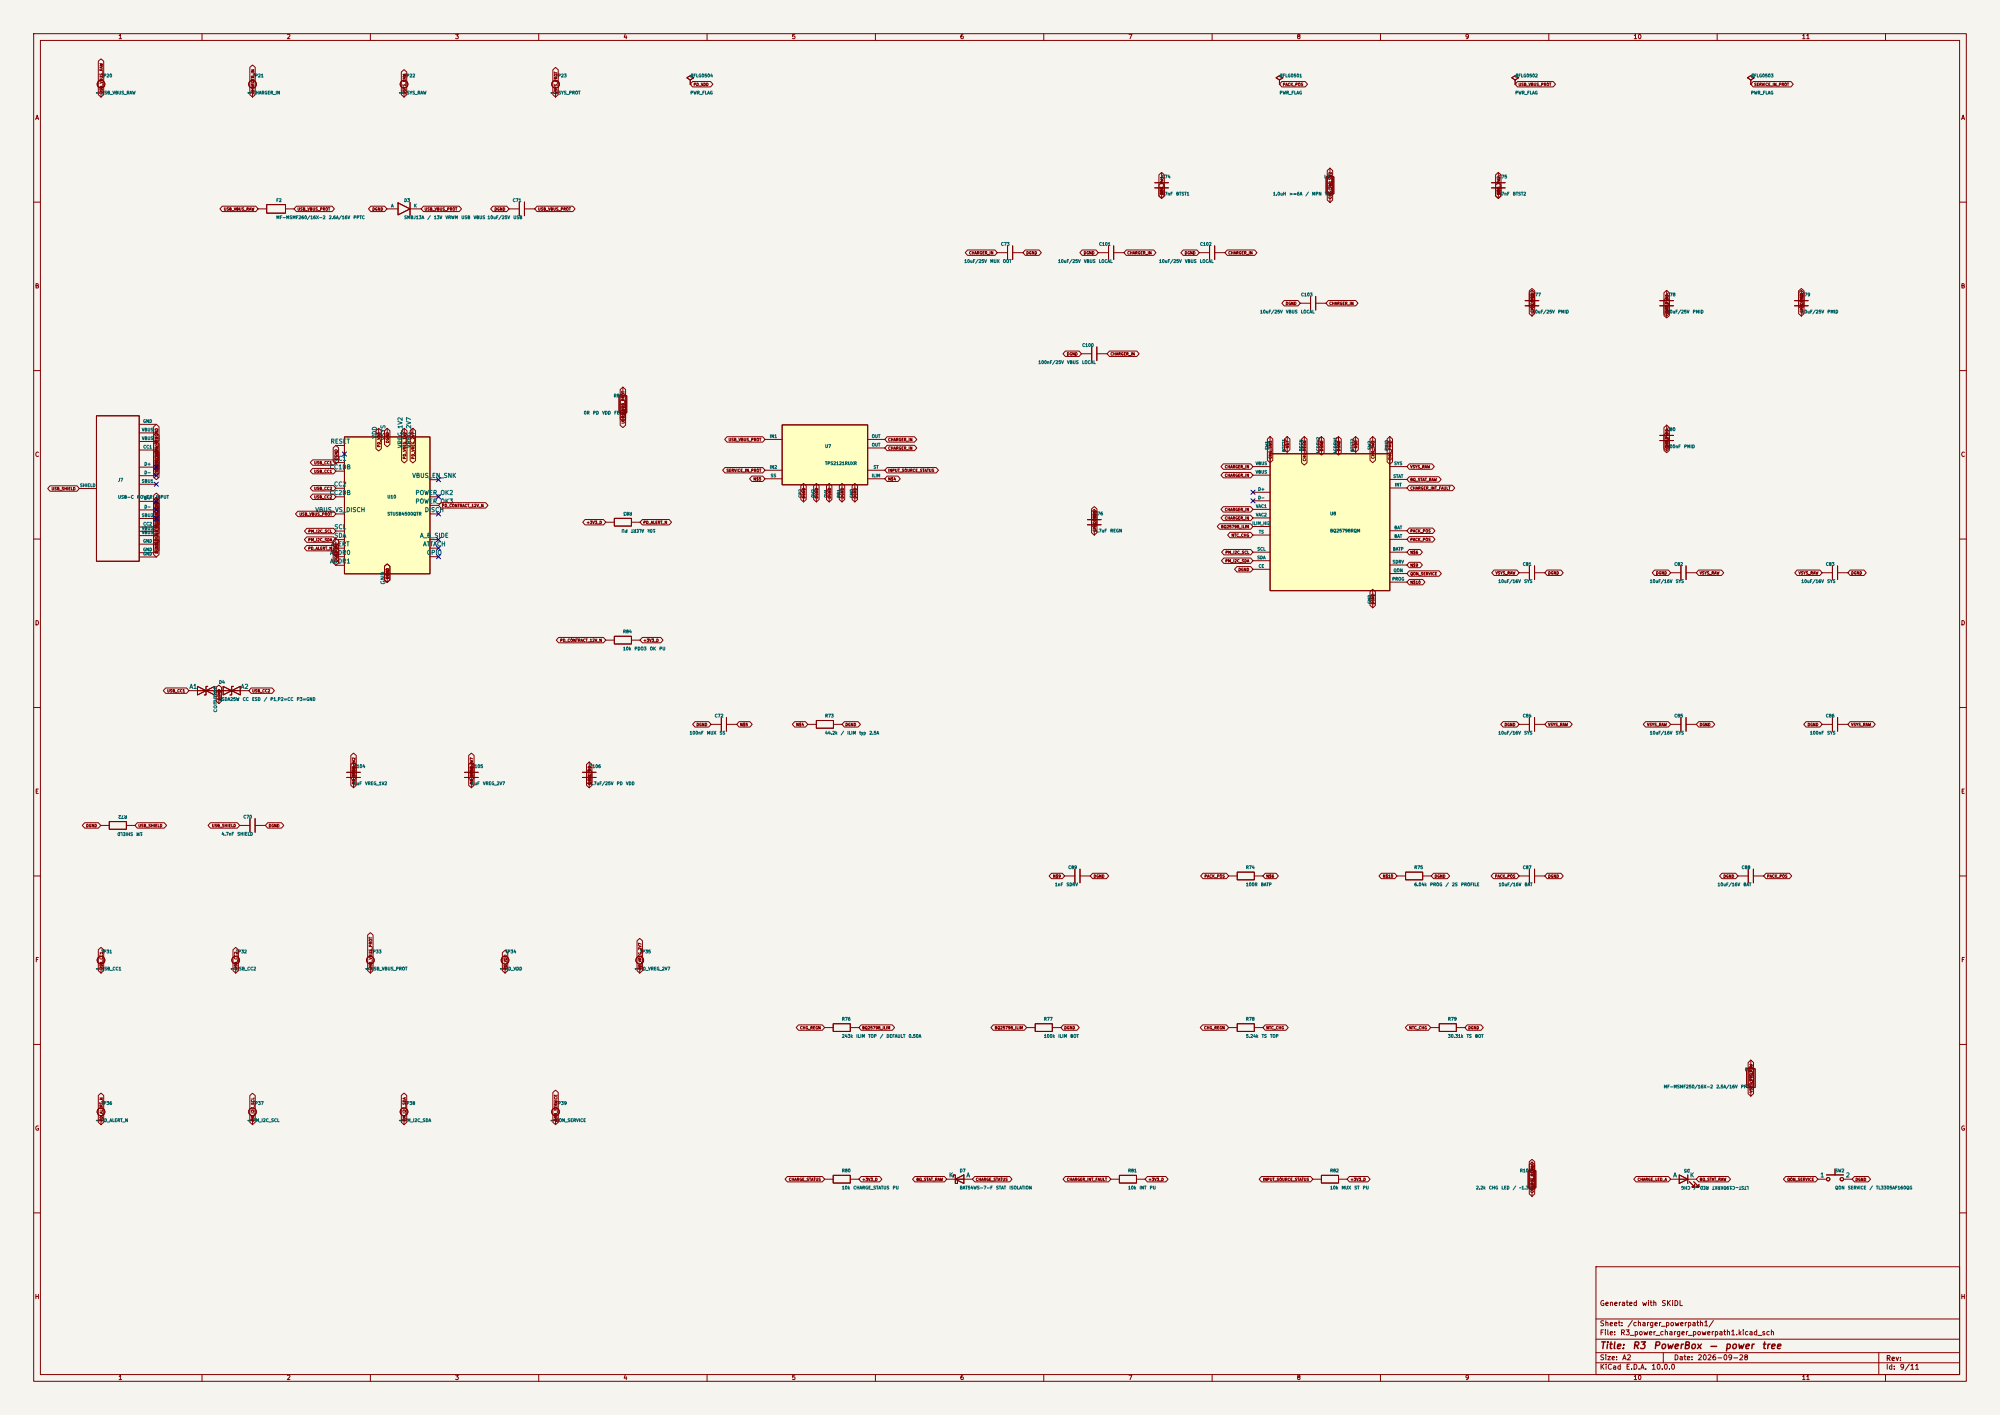
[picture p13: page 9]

ESDA25W CC ESD / P1,P2=CC P3=GND

Sheet: /charger_powerpath1/
File: R3_power_charger_powerpath1.kicad_sch
Title: R3 PowerBox — power tree

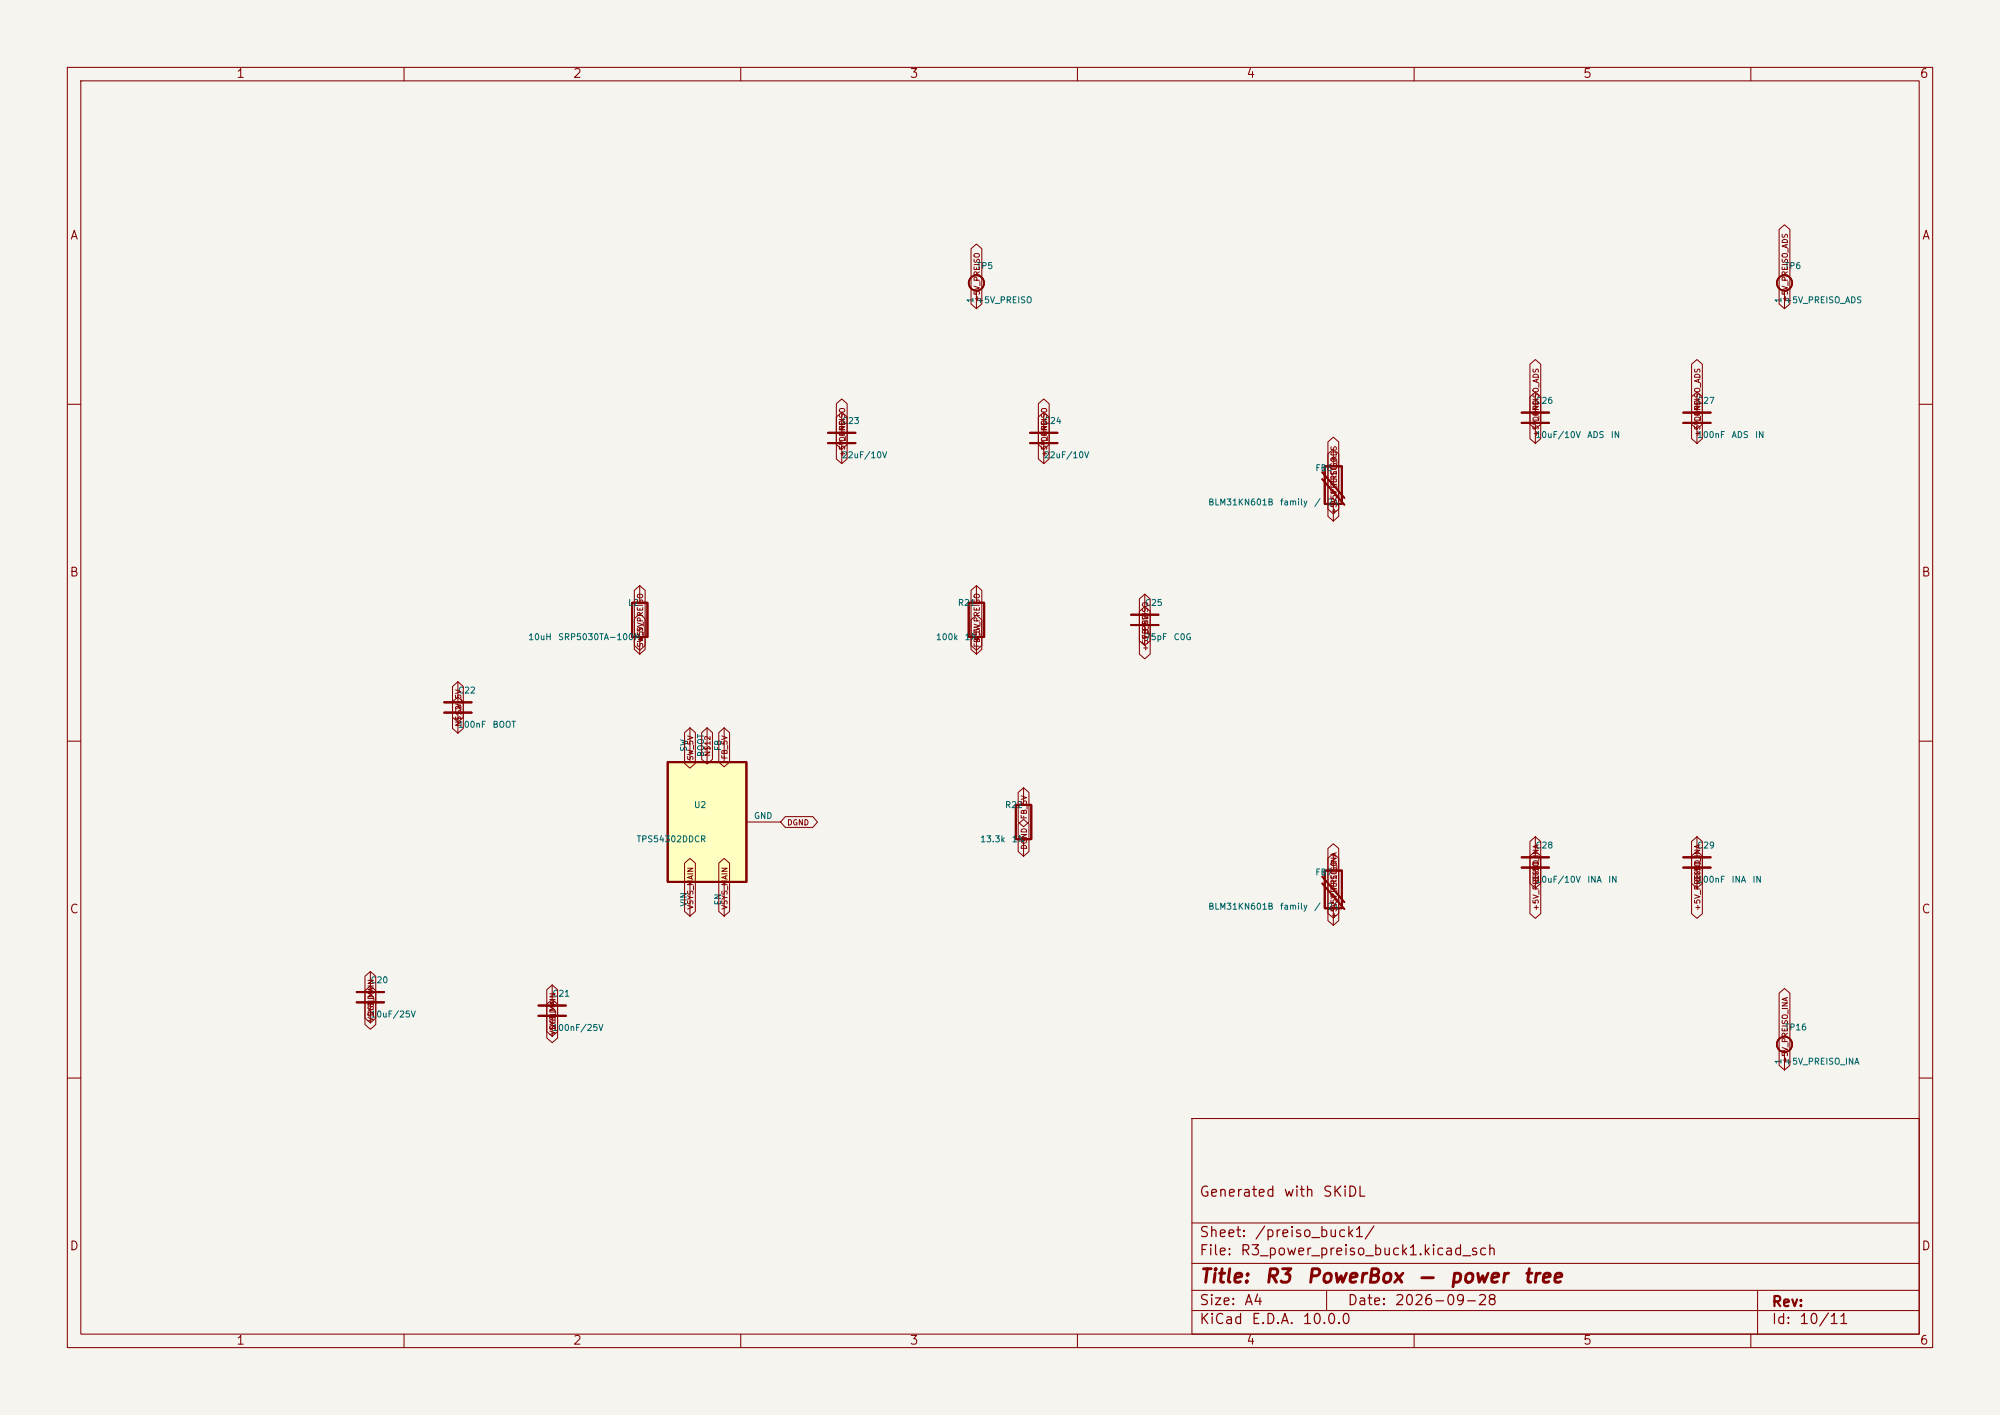
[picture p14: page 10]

Sheet: /preiso_buck1/
D Date: 2026-09-28 KiCad E.D.A. 10.0.0
File: R3_power_preiso_buck1.kicad_sch
Title: R3 PowerBox — power tree

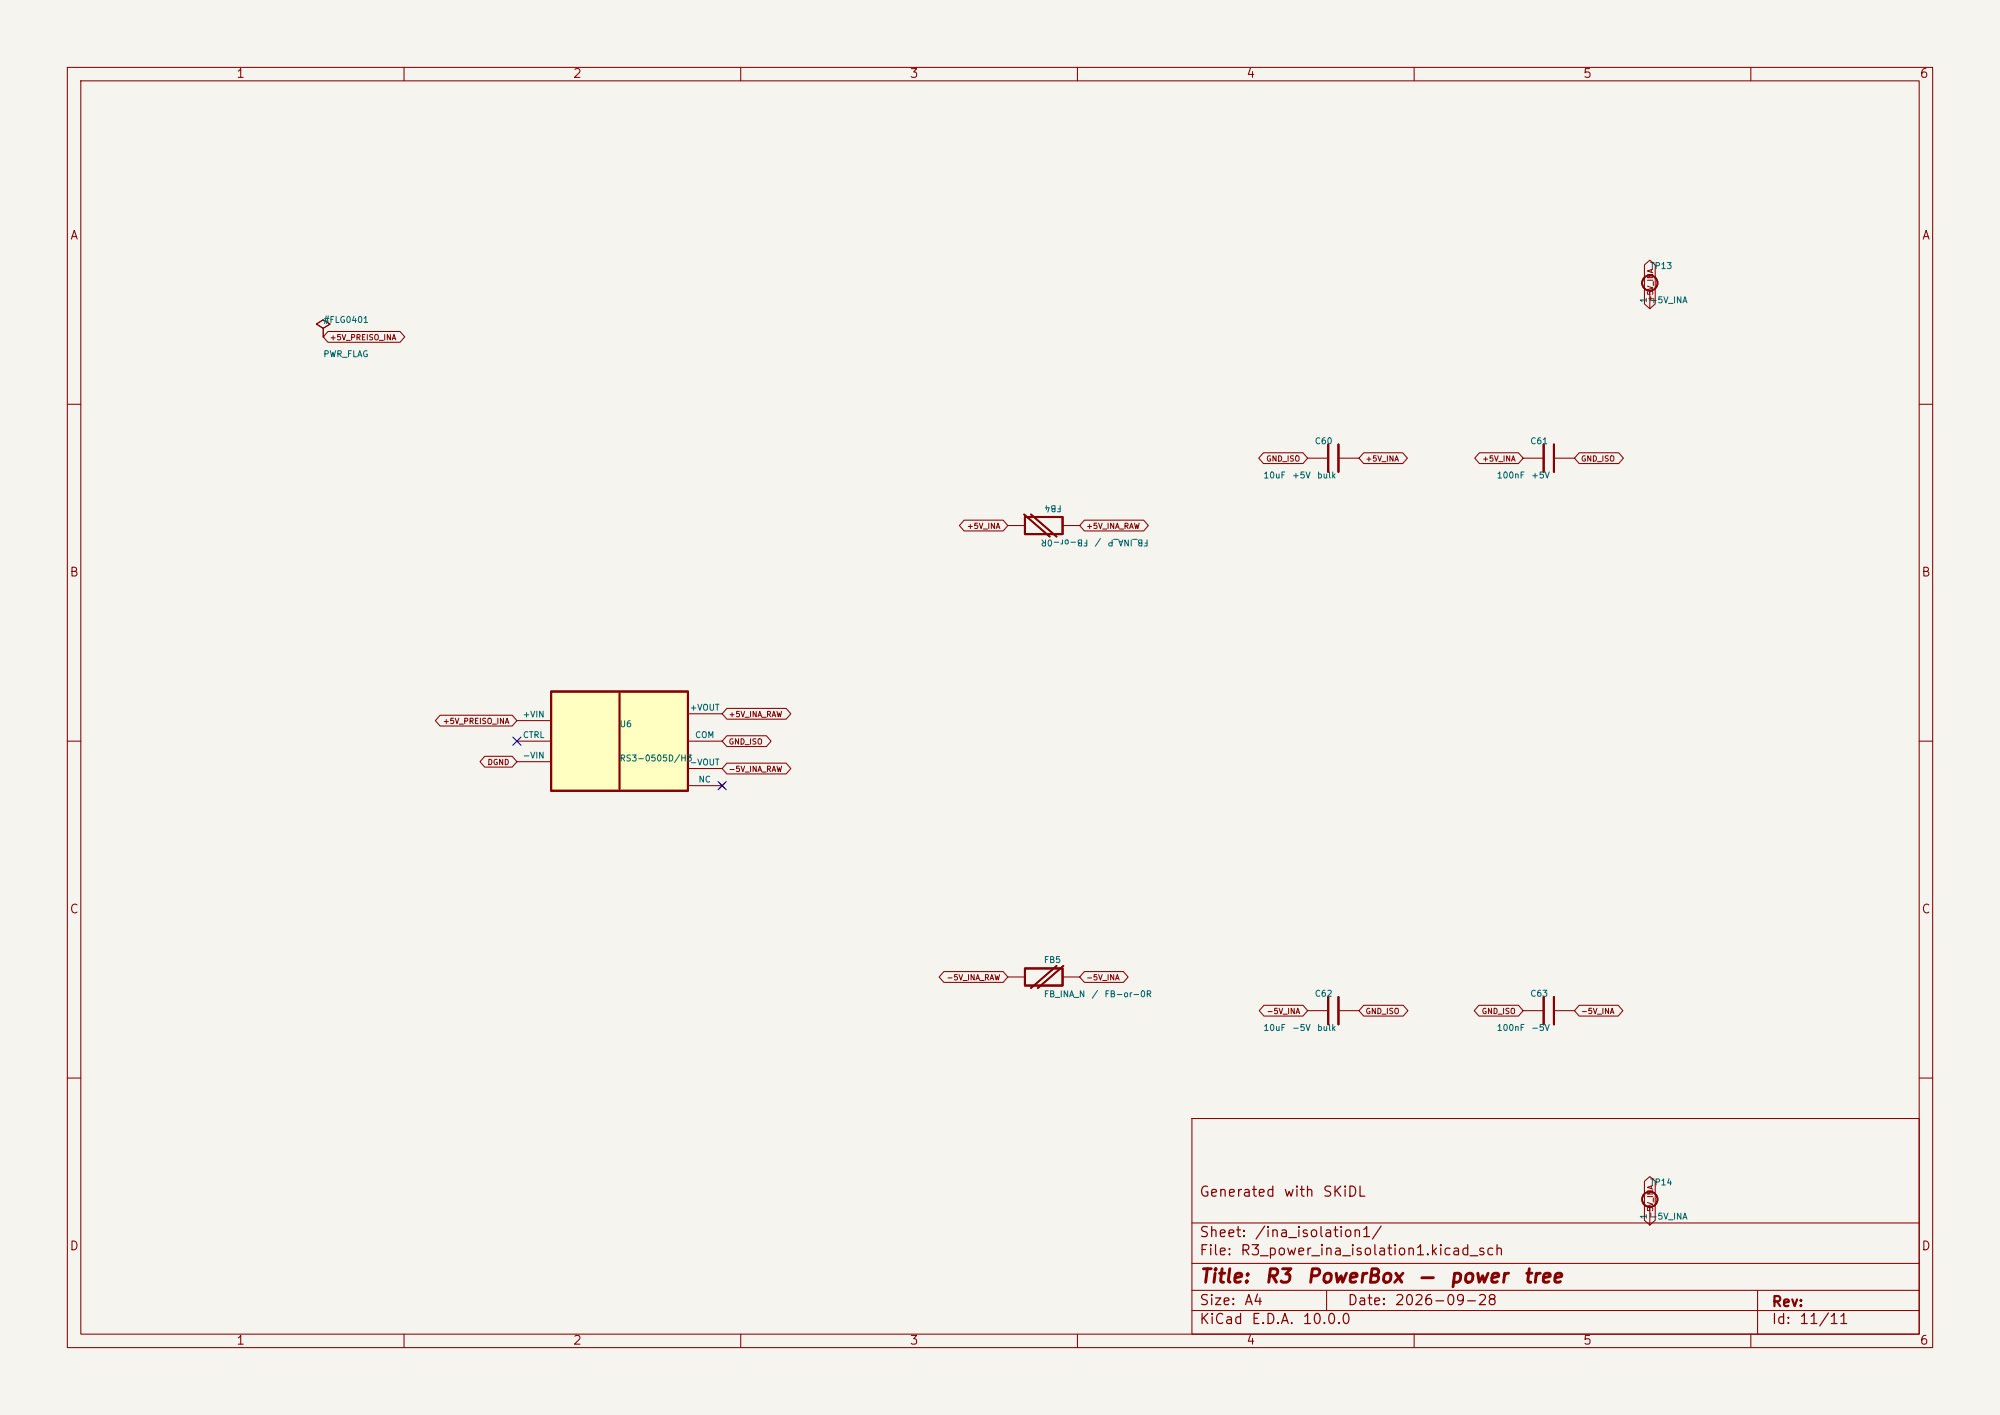
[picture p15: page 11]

Sheet: /ina_isolation1/
D Date: 2026-09-28 KiCad E.D.A. 10.0.0
File: R3_power_ina_isolation1.kicad_sch
Title: R3 PowerBox — power tree

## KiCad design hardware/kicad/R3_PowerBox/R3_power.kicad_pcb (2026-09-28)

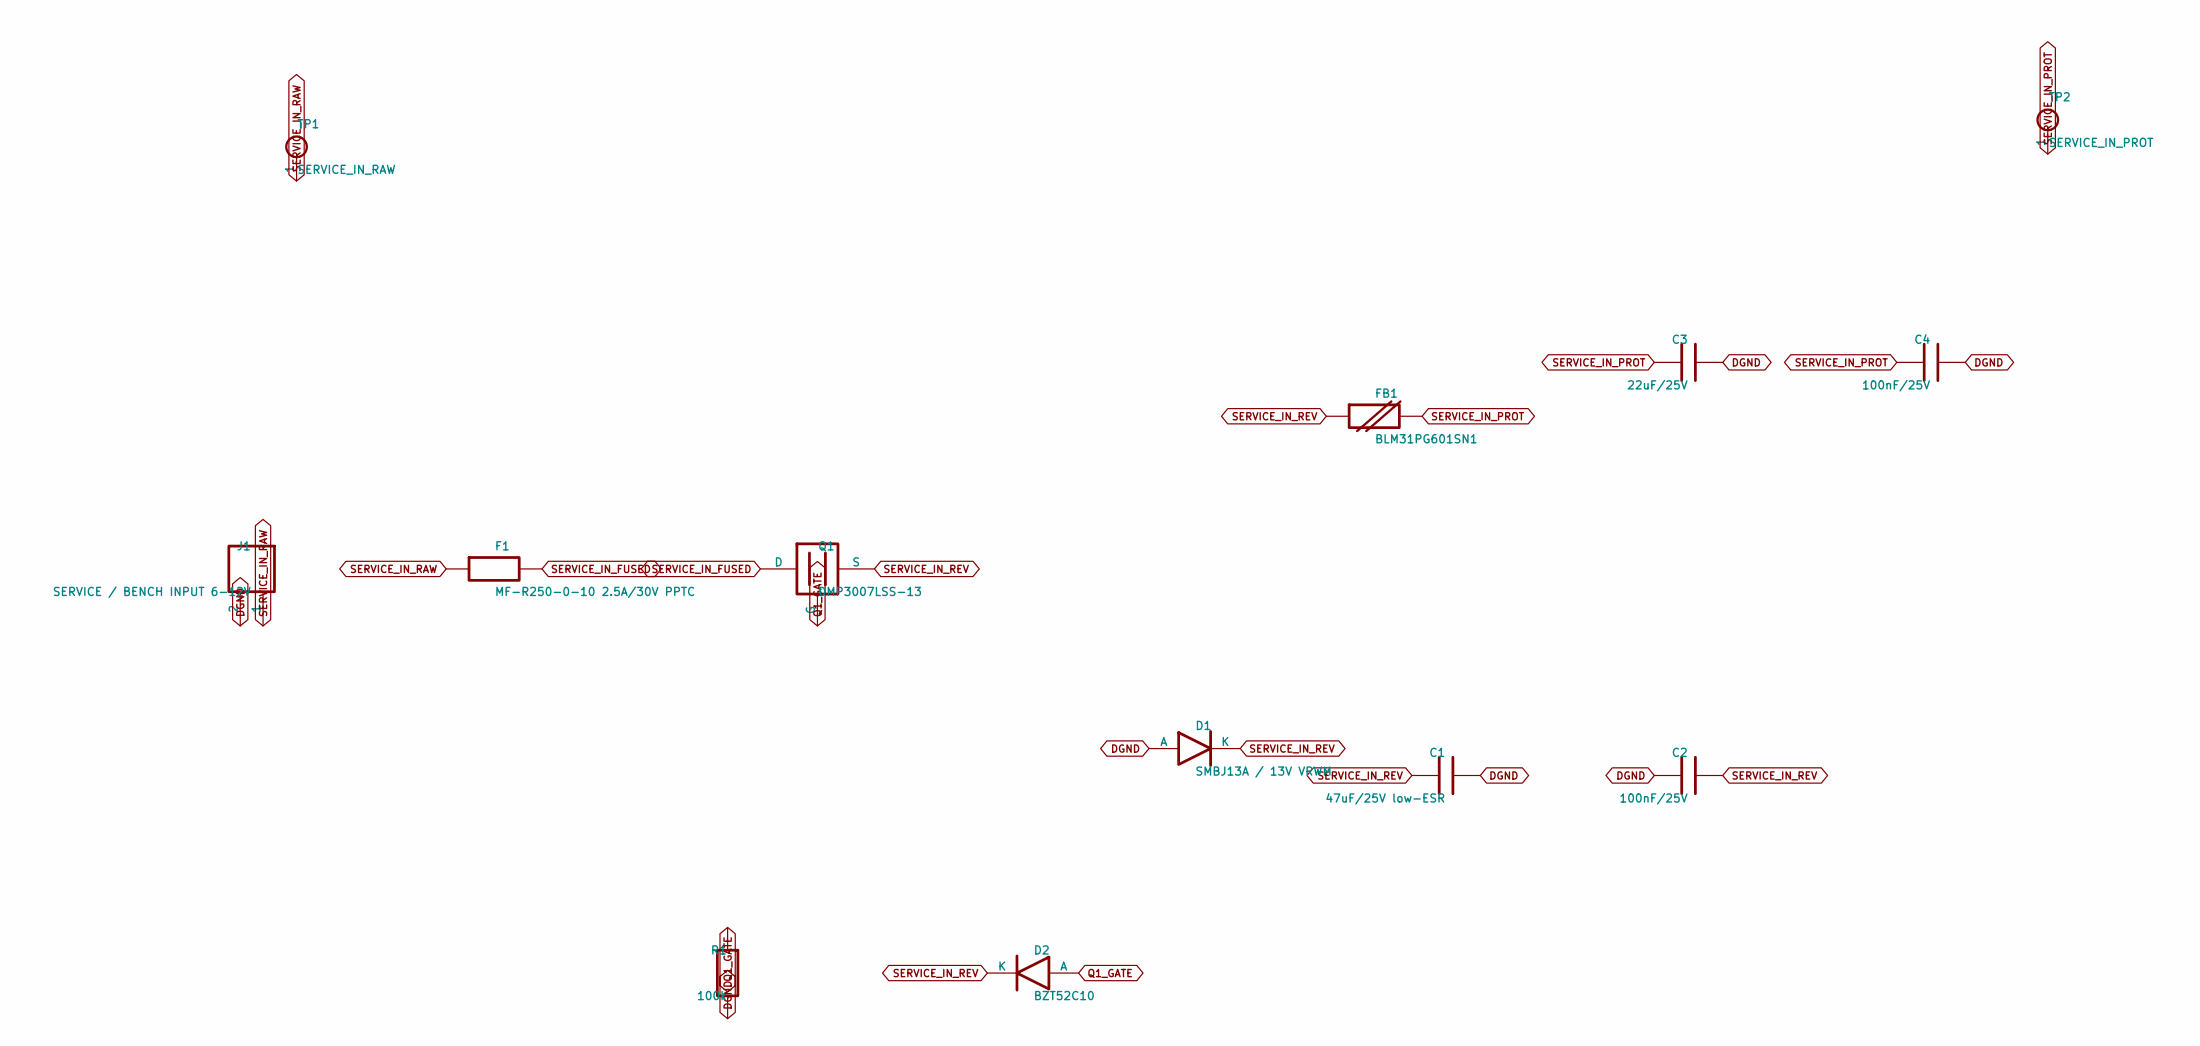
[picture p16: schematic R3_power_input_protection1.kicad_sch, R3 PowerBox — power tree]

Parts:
C1: 47uF/25V low-ESR; CP_Elec_6.3x5.8
C2, C4: 100nF/25V; C_0603_1608Metric
C3: 22uF/25V; C_1206_3216Metric
D1: SMBJ13A / 13V VRWM; D_SMB
D2: BZT52C10; D_SOD-123
F1: MF-R250-0-10 2.5A/30V PPTC; Fuse_PTC_MF-R250
FB1: BLM31PG601SN1; L_1206_3216Metric_Pad1.22x1.90mm_HandSolder
J1: SERVICE / BENCH INPUT 6-12V; Molex_Micro-Fit_3.0_43650-0200_1x02_P3.00mm_Horizontal
Q1: DMP3007LSS-13; DMP3007LSS_SO8_LOGICAL
R1: 100k; R_0603_1608Metric
TP1: SERVICE_IN_RAW; TestPoint_Plated_Hole_D2.0mm
TP2: SERVICE_IN_PROT; TestPoint_Plated_Hole_D2.0mm

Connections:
DGND: C1.2, C2.2, C3.2, C4.2, D1.1 (A), J1.2, R1.2; also elsewhere on the board
Q1_GATE: D2.1 (A), Q1.1 (G), R1.1
SERVICE_IN_FUSED: F1.2, Q1.3 (D)
SERVICE_IN_PROT: C3.1, C4.1, FB1.2, TP2.1; also elsewhere on the board
SERVICE_IN_RAW: F1.1, J1.1, TP1.1
SERVICE_IN_REV: C1.1, C2.1, D1.2 (K), D2.2 (K), FB1.1, Q1.2 (S)

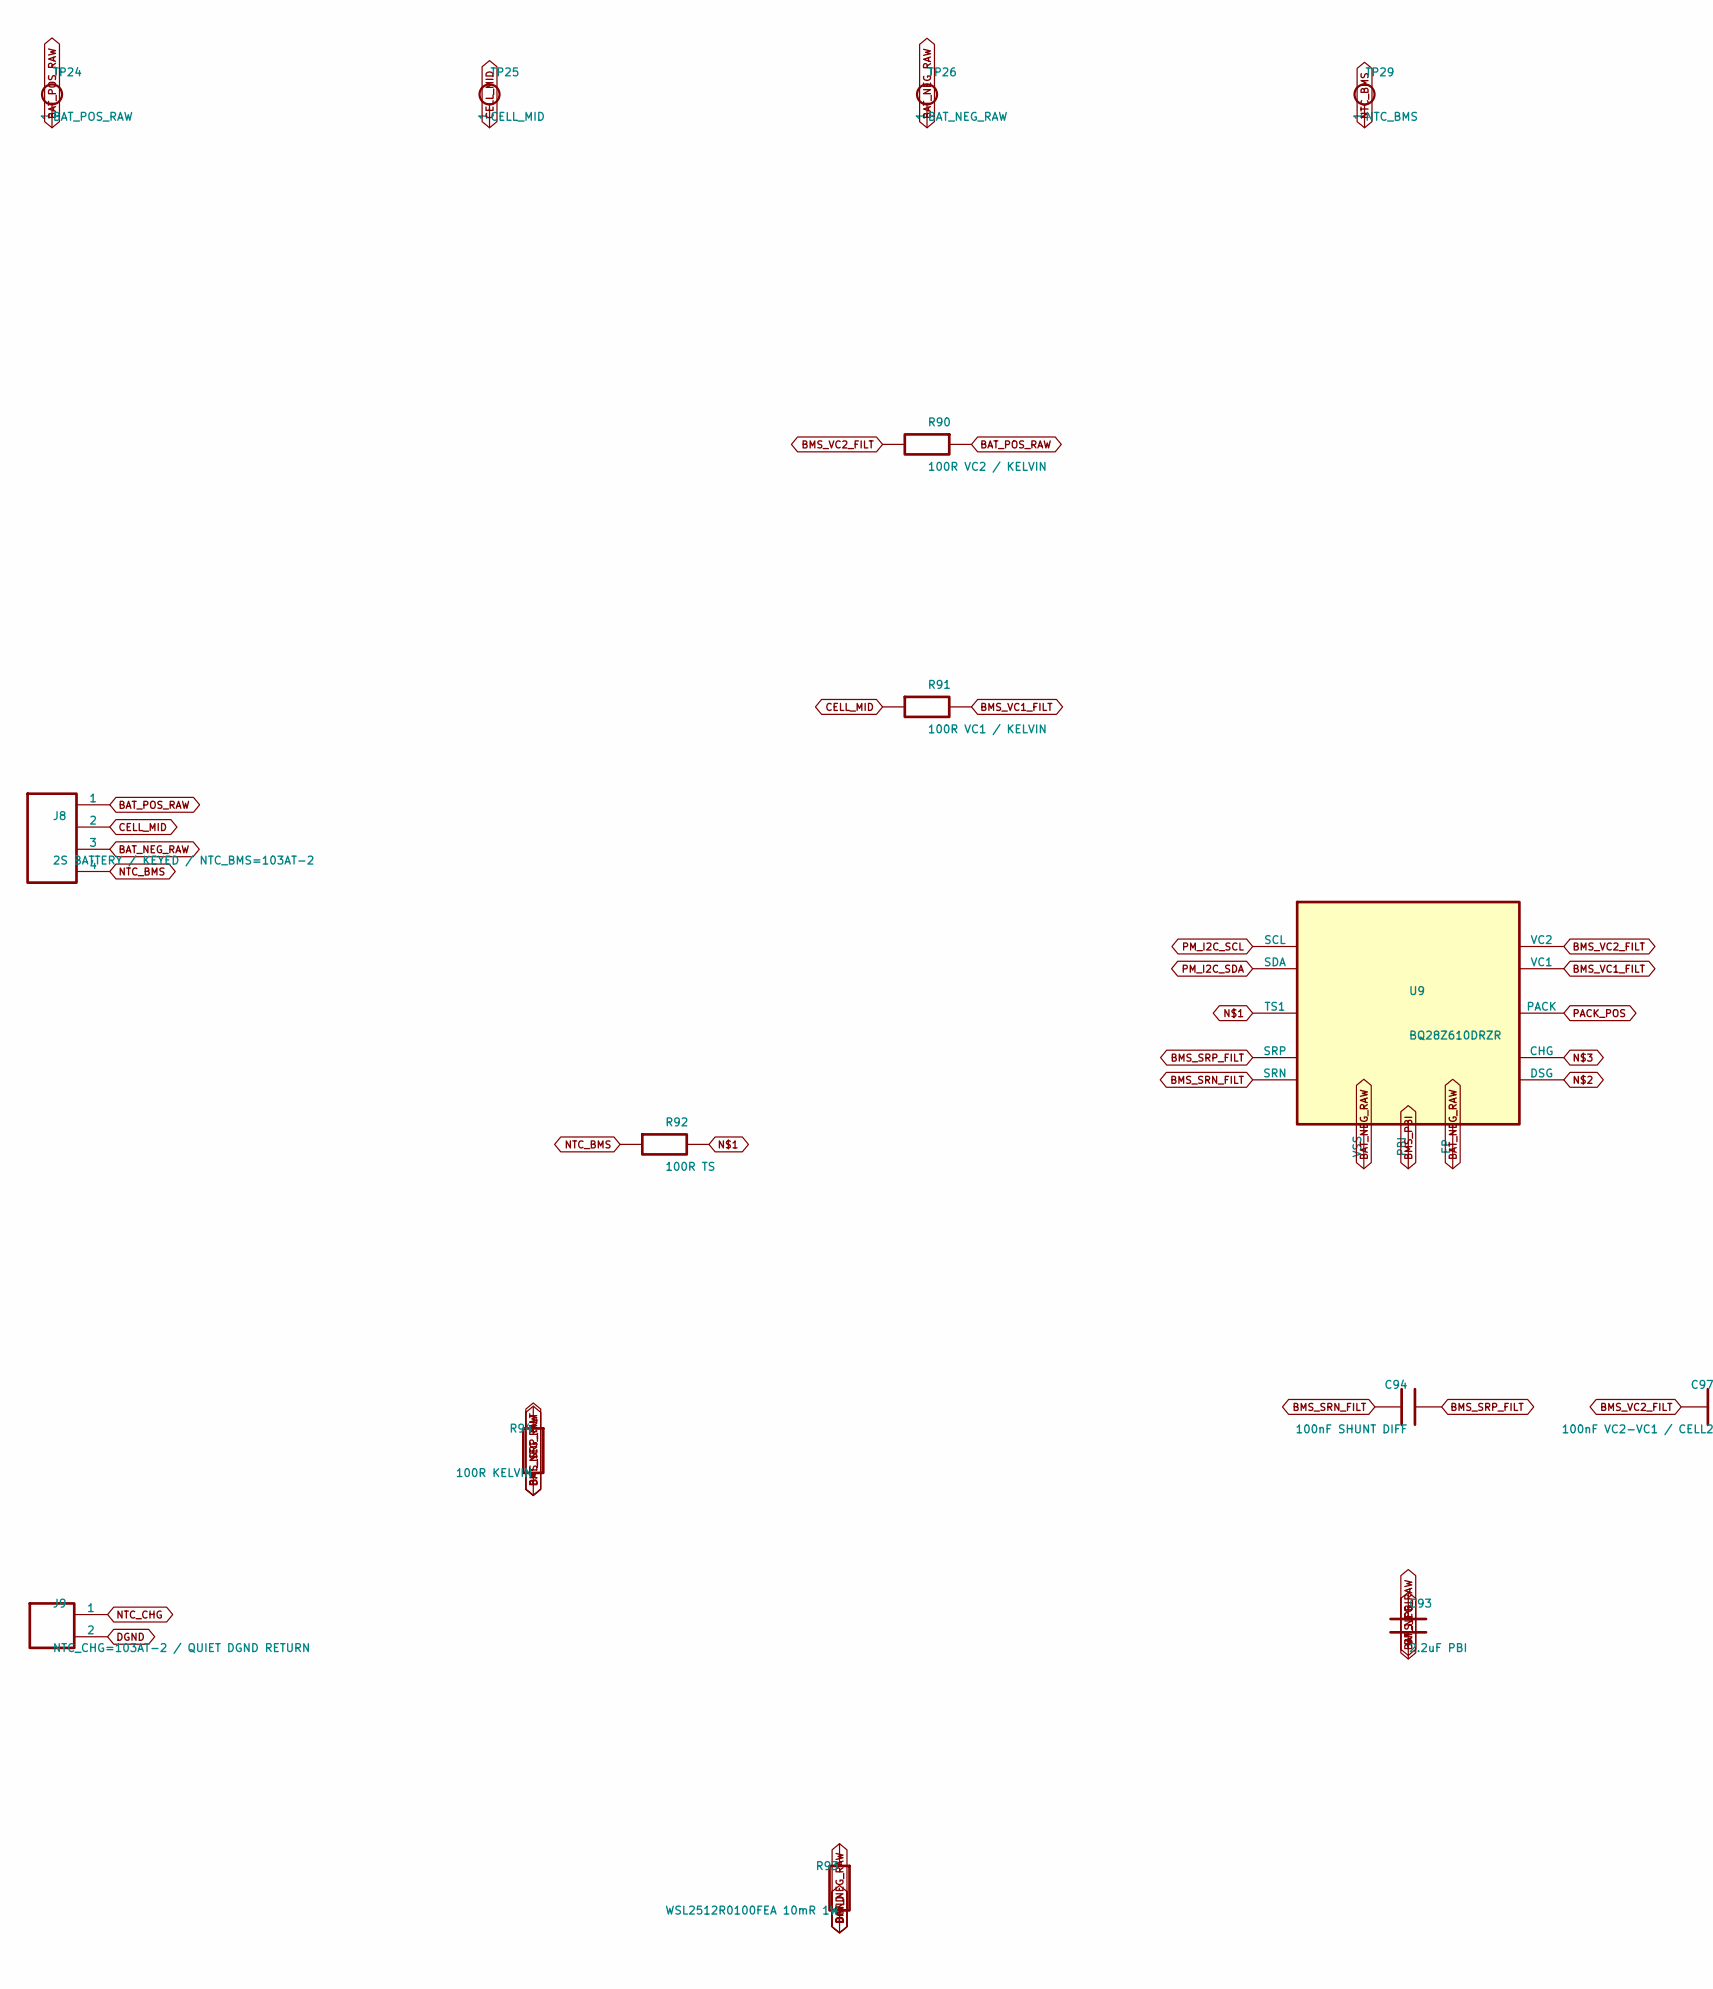
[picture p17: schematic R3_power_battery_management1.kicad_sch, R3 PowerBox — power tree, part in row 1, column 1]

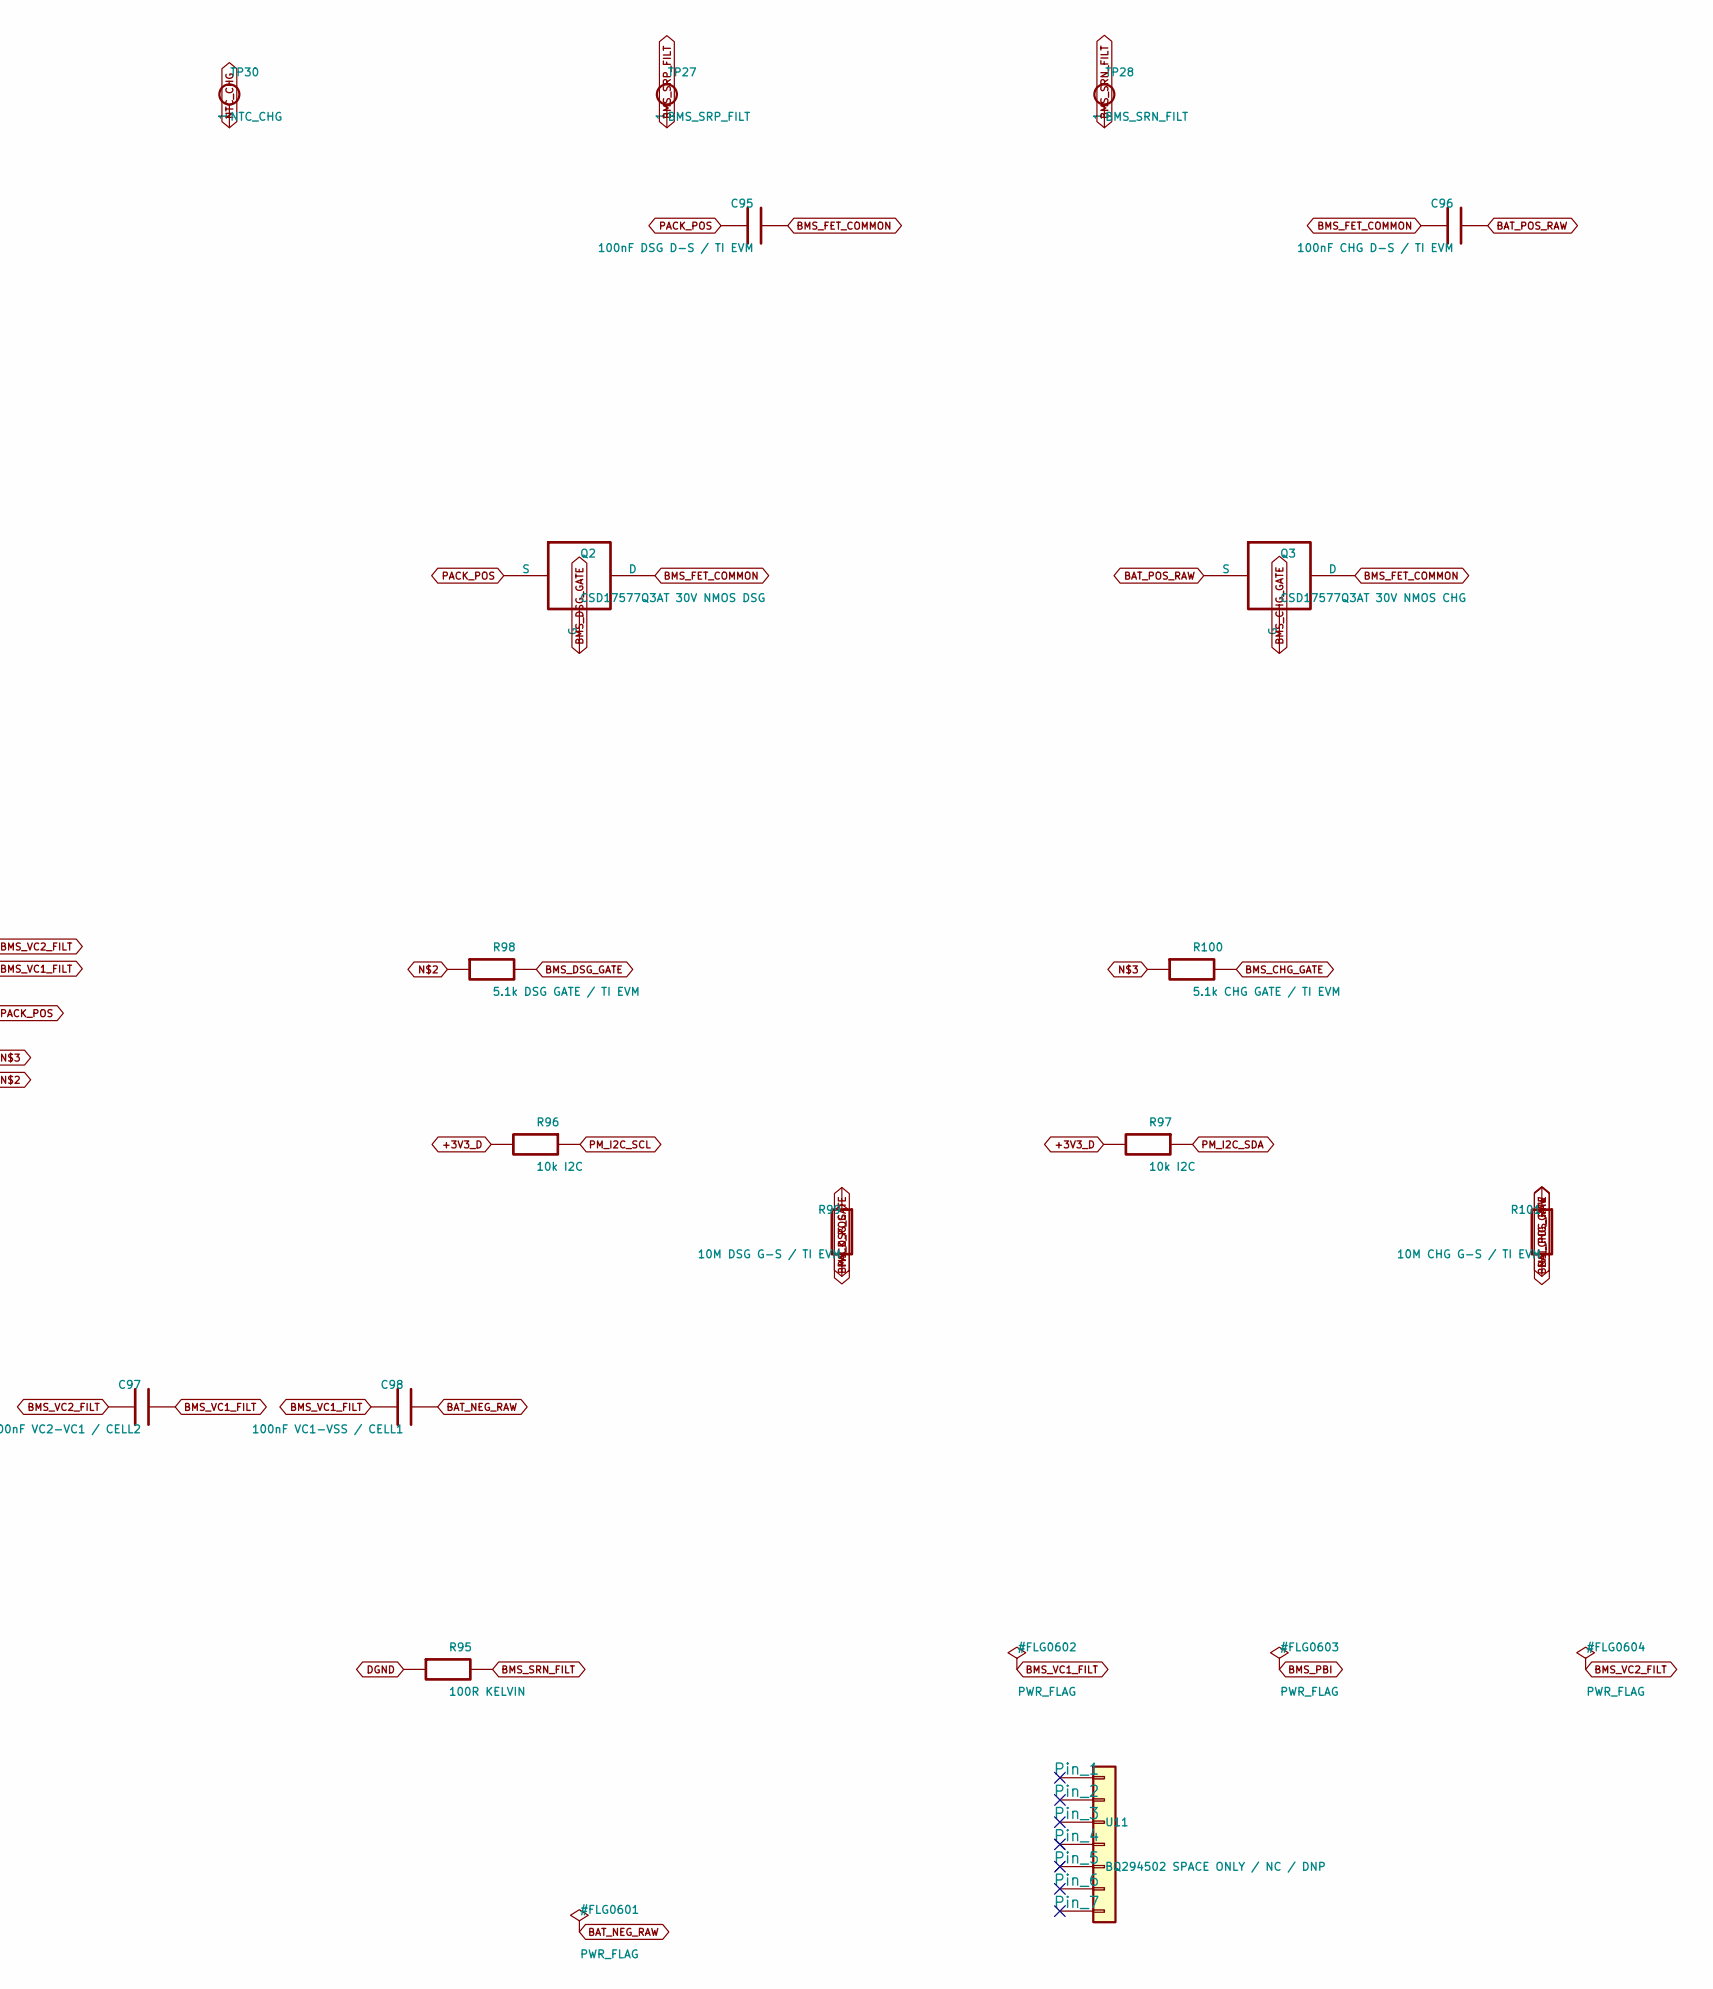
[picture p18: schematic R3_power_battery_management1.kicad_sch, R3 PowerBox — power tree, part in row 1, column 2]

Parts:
C93: 2.2uF PBI; C_0603_1608Metric
C94: 100nF SHUNT DIFF; C_0603_1608Metric
C95: 100nF DSG D-S / TI EVM; C_0603_1608Metric
C96: 100nF CHG D-S / TI EVM; C_0603_1608Metric
C97: 100nF VC2-VC1 / CELL2; C_0603_1608Metric
C98: 100nF VC1-VSS / CELL1; C_0603_1608Metric
J8: 2S BATTERY / KEYED / NTC_BMS=103AT-2; Molex_Micro-Fit_3.0_43650-0400_1x04_P3.00mm_Horizontal
J9: NTC_CHG=103AT-2 / QUIET DGND RETURN; Molex_Micro-Fit_3.0_43650-0200_1x02_P3.00mm_Horizontal
Q2: CSD17577Q3AT 30V NMOS DSG; CSD17577Q3A_VSON-8_3.3x3.3mm
Q3: CSD17577Q3AT 30V NMOS CHG; CSD17577Q3A_VSON-8_3.3x3.3mm
R90: 100R VC2 / KELVIN; R_0603_1608Metric
R91: 100R VC1 / KELVIN; R_0603_1608Metric
R92: 100R TS; R_0603_1608Metric
R93: WSL2512R0100FEA 10mR 1W; R_2512_6332Metric_Pad1.40x3.35mm_HandSolder
R94, R95: 100R KELVIN; R_0603_1608Metric
R96, R97: 10k I2C; R_0603_1608Metric
R98: 5.1k DSG GATE / TI EVM; R_0603_1608Metric
R99: 10M DSG G-S / TI EVM; R_0603_1608Metric
R100: 5.1k CHG GATE / TI EVM; R_0603_1608Metric
R101: 10M CHG G-S / TI EVM; R_0603_1608Metric
TP24: BAT_POS_RAW; TestPoint_Plated_Hole_D2.0mm
TP25: CELL_MID; TestPoint_Plated_Hole_D2.0mm
TP26: BAT_NEG_RAW; TestPoint_Plated_Hole_D2.0mm
TP27: BMS_SRP_FILT; TestPoint_Plated_Hole_D2.0mm
TP28: BMS_SRN_FILT; TestPoint_Plated_Hole_D2.0mm
TP29: NTC_BMS; TestPoint_Plated_Hole_D2.0mm
TP30: NTC_CHG; TestPoint_Plated_Hole_D2.0mm
U9: BQ28Z610DRZR; Texas_DRZ0012A_VSON-12
U11: BQ294502 SPACE ONLY / NC / DNP; WSON-6-1EP_2x2mm_P0.65mm_EP1x1.6mm

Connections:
+3V3_D: R96.2, R97.2; also elsewhere on the board
BAT_NEG_RAW: C93.2, C98.2, J8.3, R93.1, R94.1, TP26.1, U9.1 (VSS), U9.13 (EP)
BAT_POS_RAW: C96.2, J8.1, Q3.2 (S), R90.1, R101.2, TP24.1
BMS_CHG_GATE: Q3.1 (G), R100.2, R101.1
BMS_DSG_GATE: Q2.1 (G), R98.2, R99.1
BMS_FET_COMMON: C95.2, C96.1, Q2.3 (D), Q3.3 (D)
BMS_PBI: C93.1, U9.10 (PBI)
BMS_SRN_FILT: C94.2, R95.2, TP28.1, U9.2 (SRN)
BMS_SRP_FILT: C94.1, R94.2, TP27.1, U9.3 (SRP)
BMS_VC1_FILT: C97.2, C98.1, R91.2, U9.12 (VC1)
BMS_VC2_FILT: C97.1, R90.2, U9.11 (VC2)
CELL_MID: J8.2, R91.1, TP25.1
DGND: J9.2, R93.2, R95.1; also elsewhere on the board
unnamed: R92.2, U9.4 (TS1)
unnamed: R98.1, U9.7 (DSG)
unnamed: R100.1, U9.9 (CHG)
NTC_BMS: J8.4, R92.1, TP29.1
NTC_CHG: J9.1, TP30.1; also elsewhere on the board
PACK_POS: C95.1, Q2.2 (S), R99.2, U9.8 (PACK); also elsewhere on the board
PM_I2C_SCL: R96.1, U9.5 (SCL); also elsewhere on the board
PM_I2C_SDA: R97.1, U9.6 (SDA); also elsewhere on the board

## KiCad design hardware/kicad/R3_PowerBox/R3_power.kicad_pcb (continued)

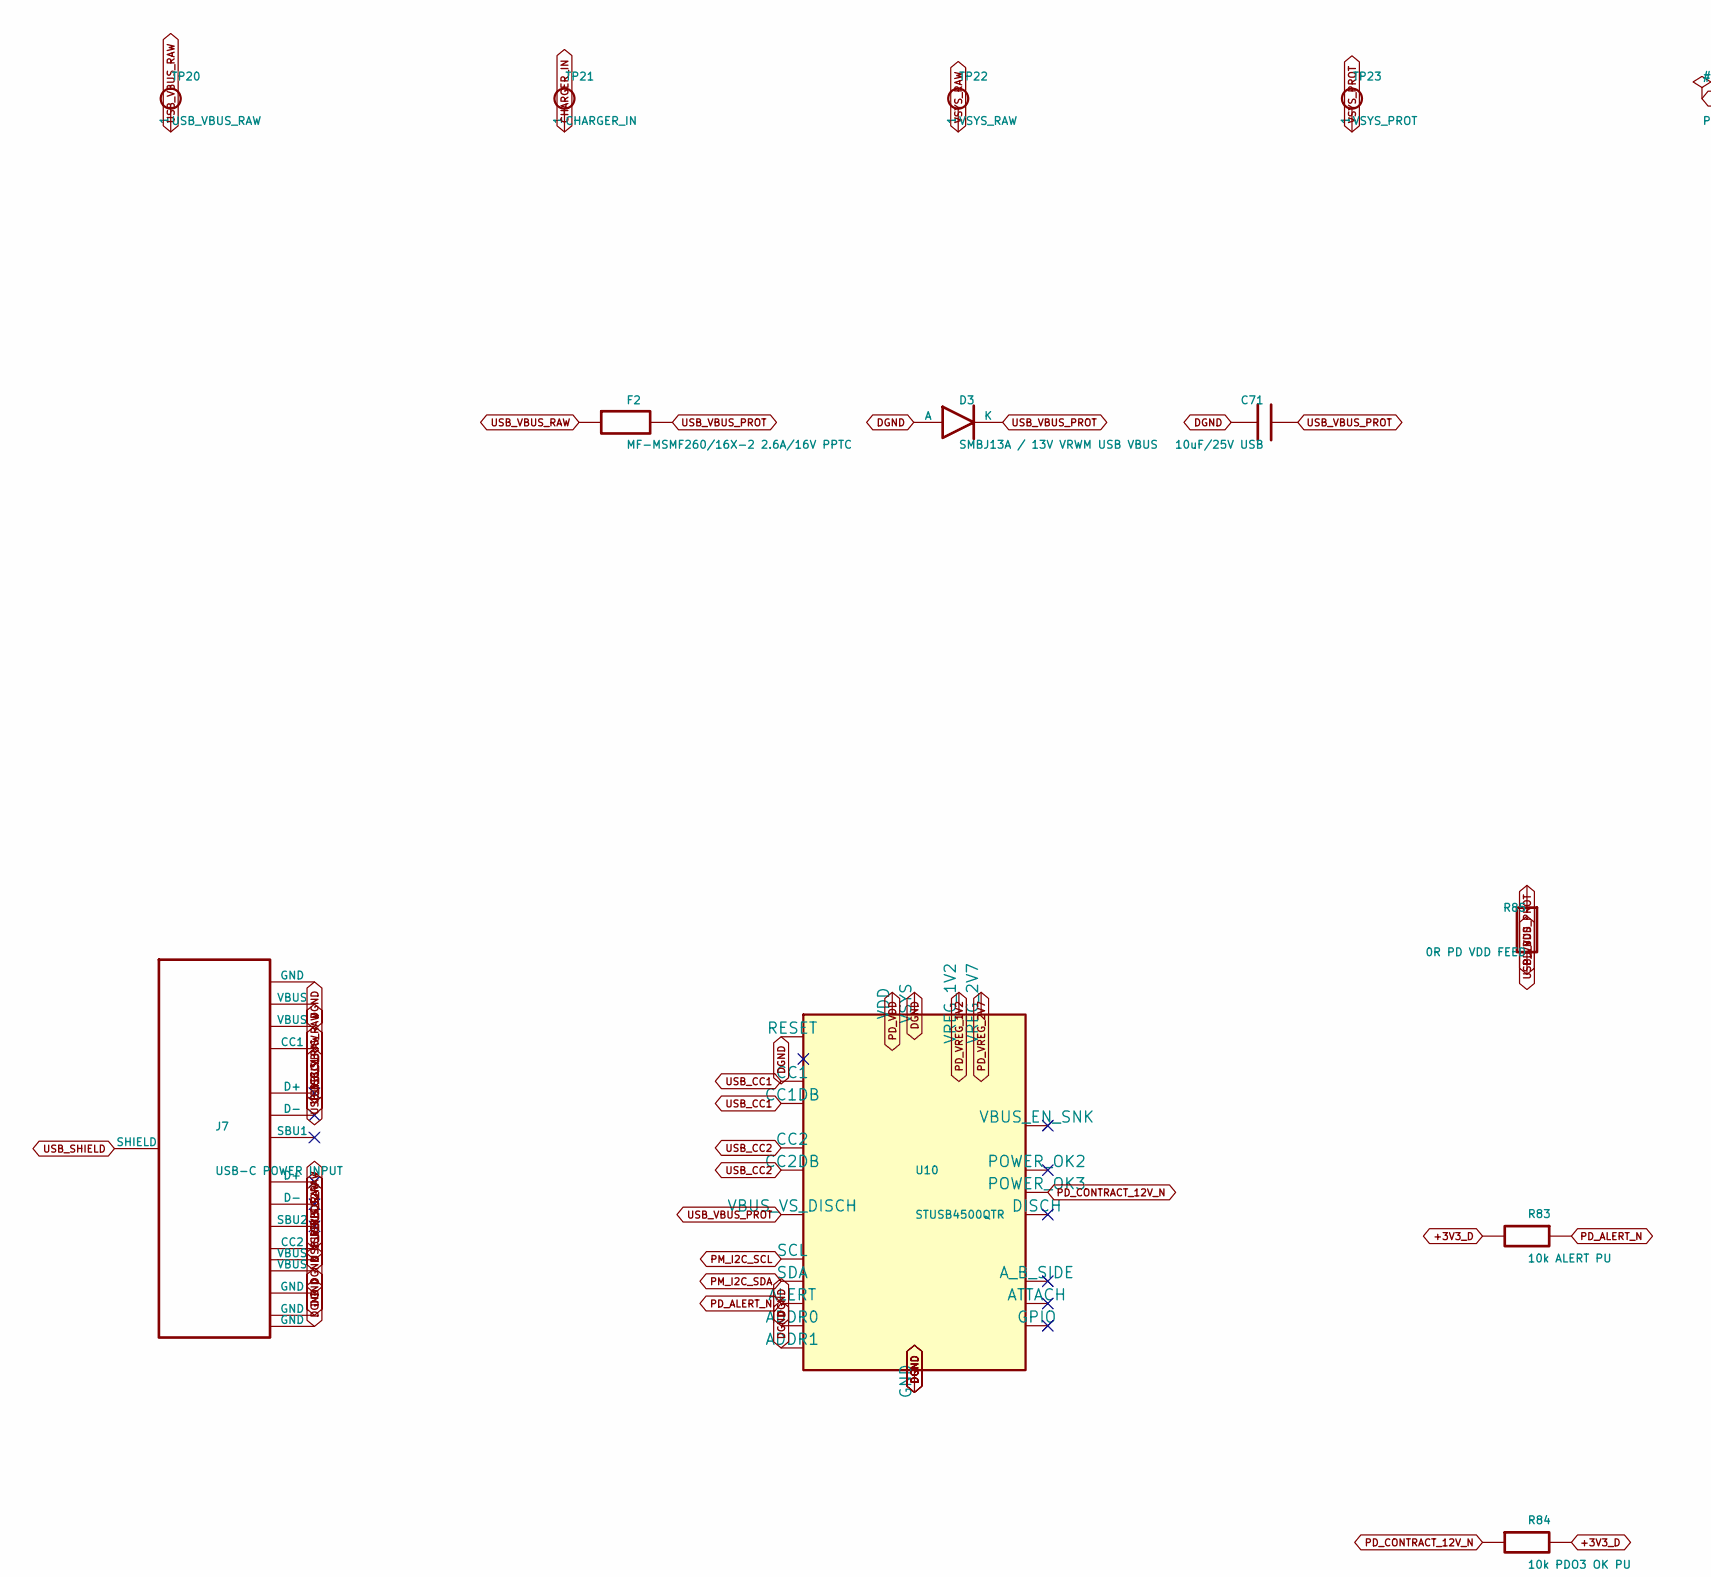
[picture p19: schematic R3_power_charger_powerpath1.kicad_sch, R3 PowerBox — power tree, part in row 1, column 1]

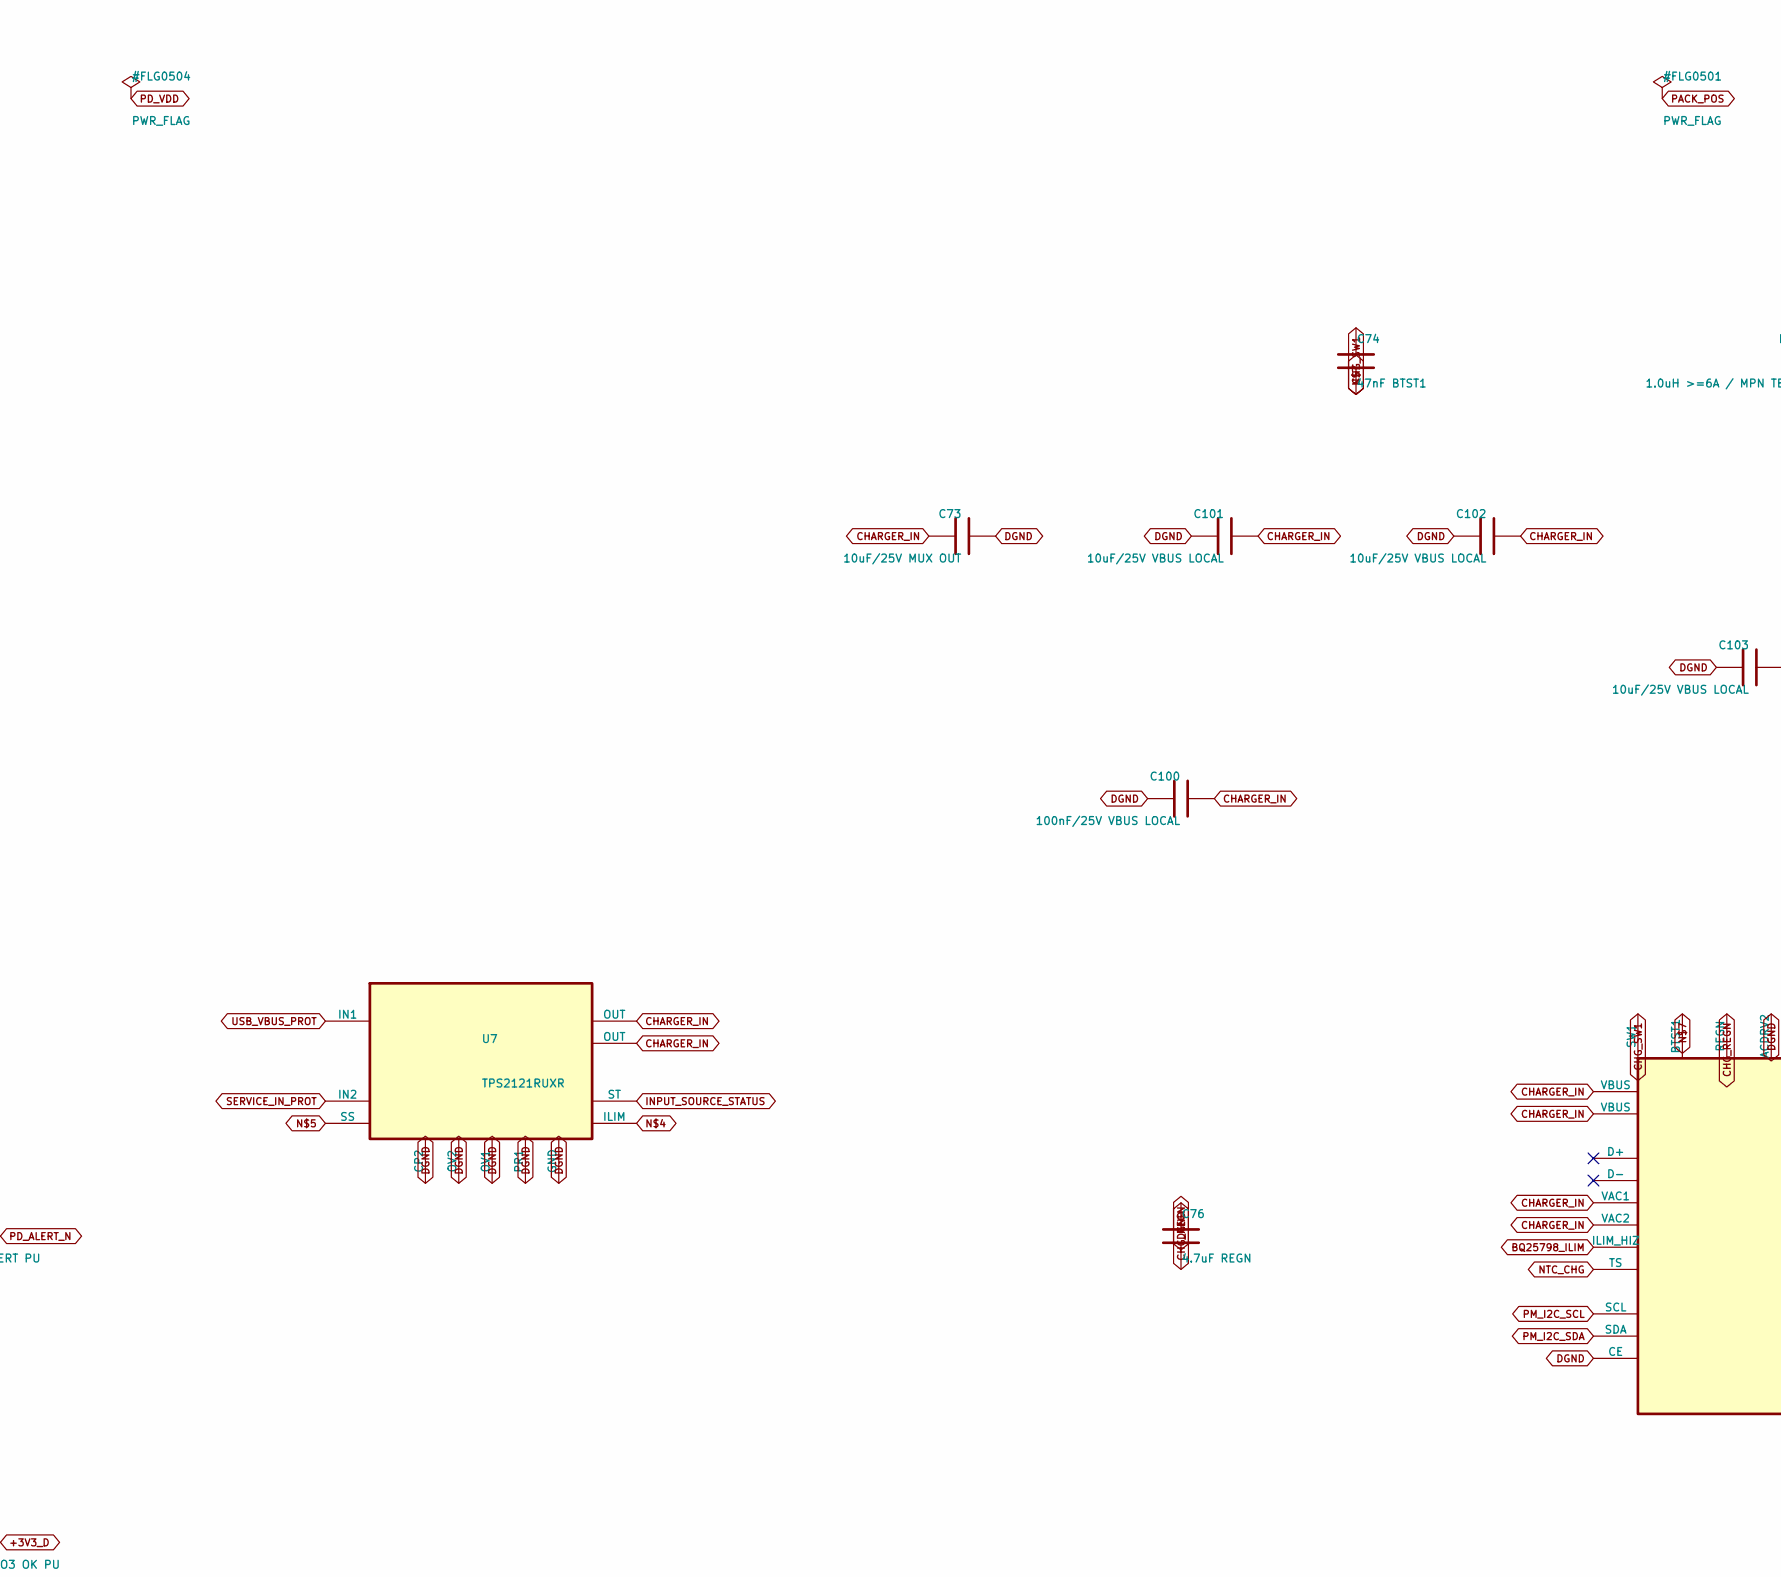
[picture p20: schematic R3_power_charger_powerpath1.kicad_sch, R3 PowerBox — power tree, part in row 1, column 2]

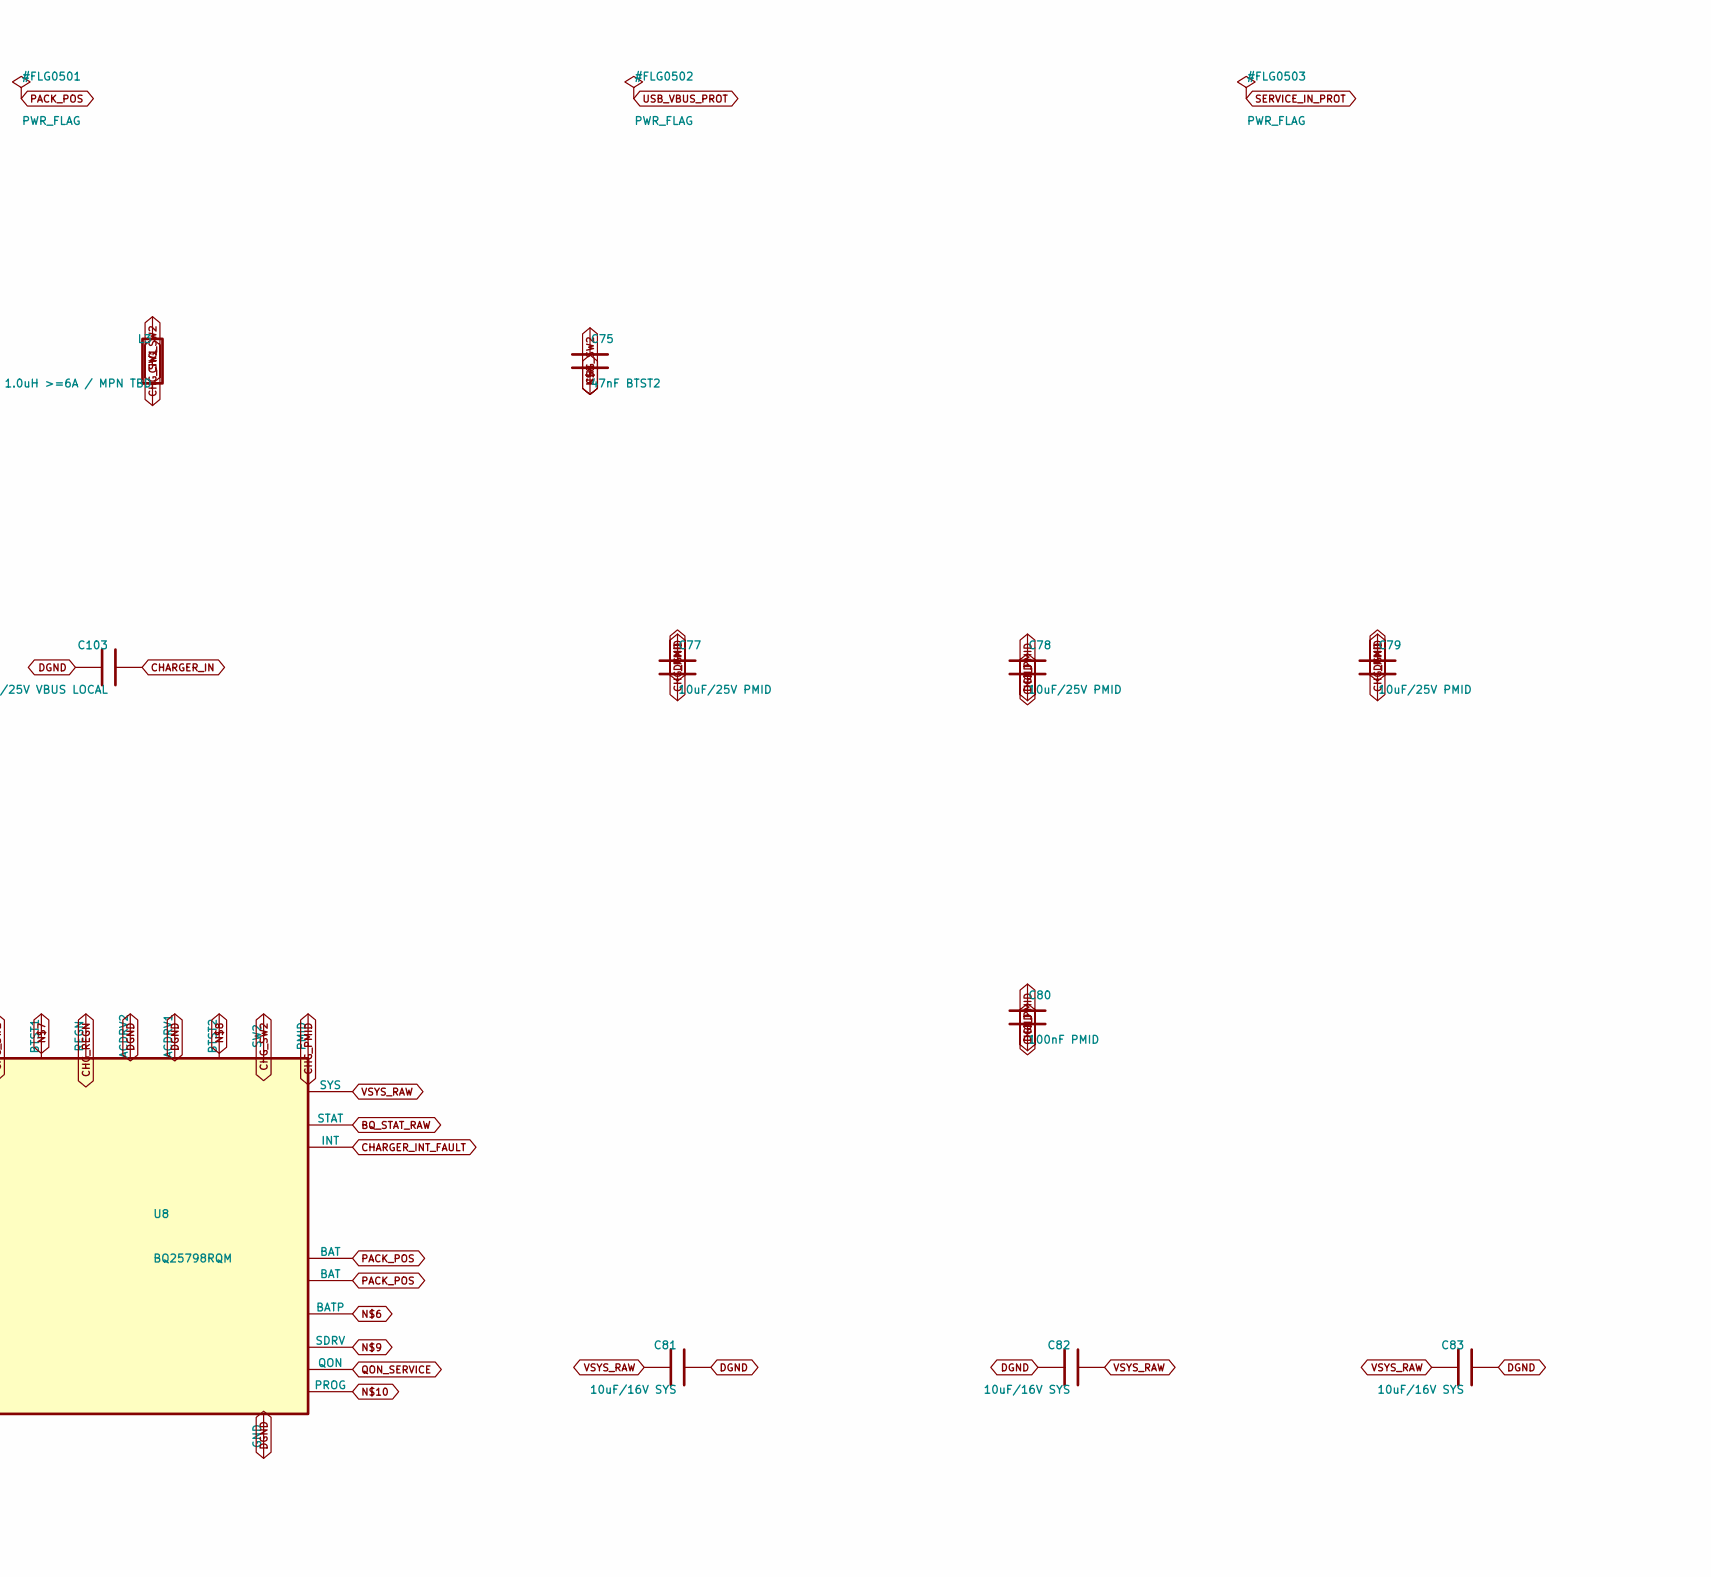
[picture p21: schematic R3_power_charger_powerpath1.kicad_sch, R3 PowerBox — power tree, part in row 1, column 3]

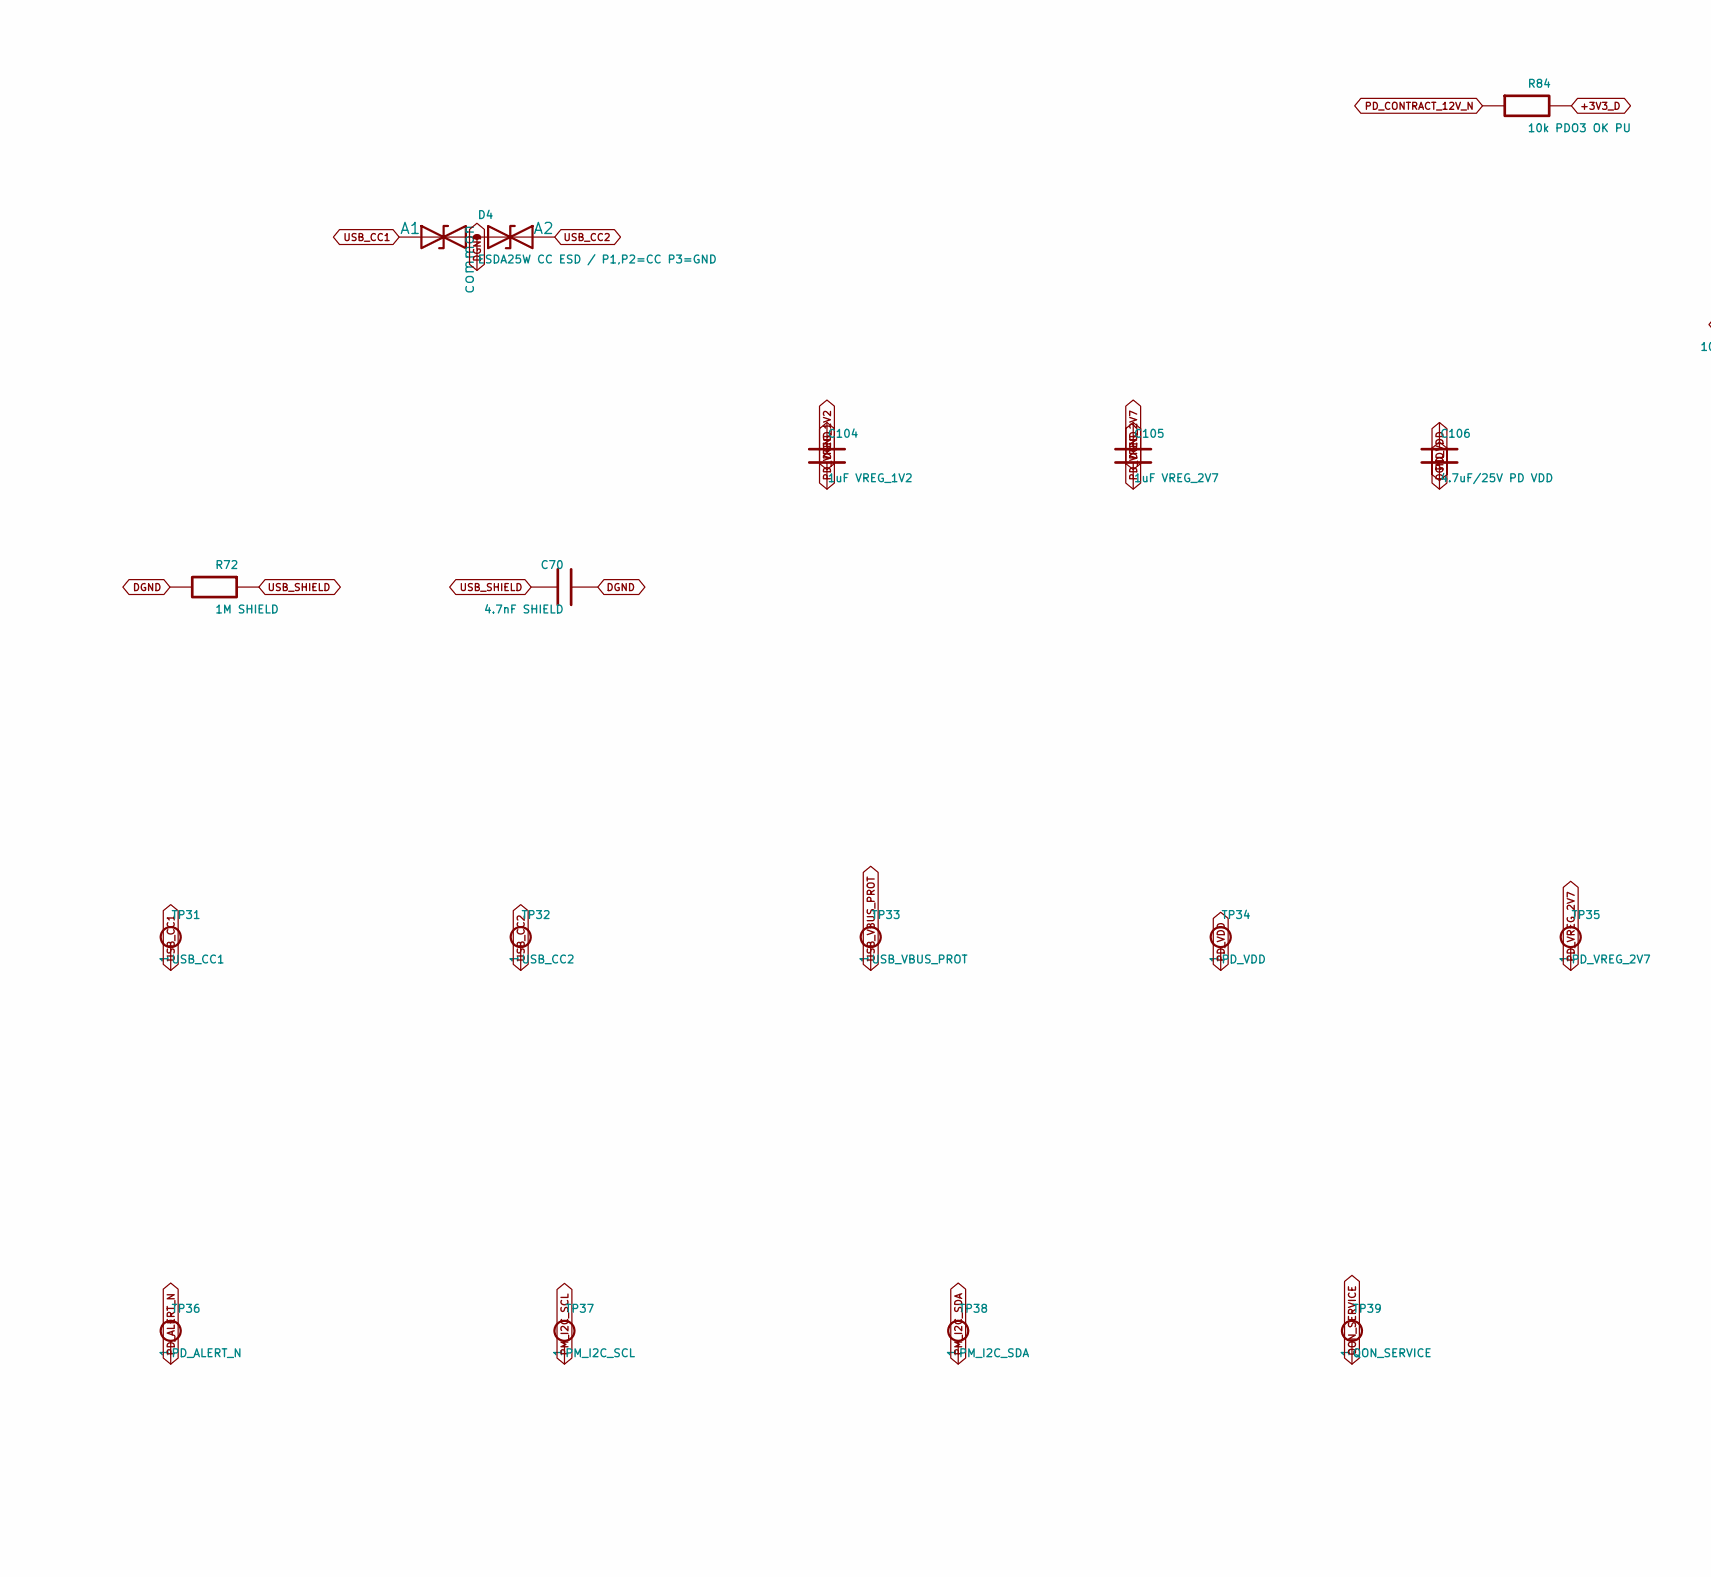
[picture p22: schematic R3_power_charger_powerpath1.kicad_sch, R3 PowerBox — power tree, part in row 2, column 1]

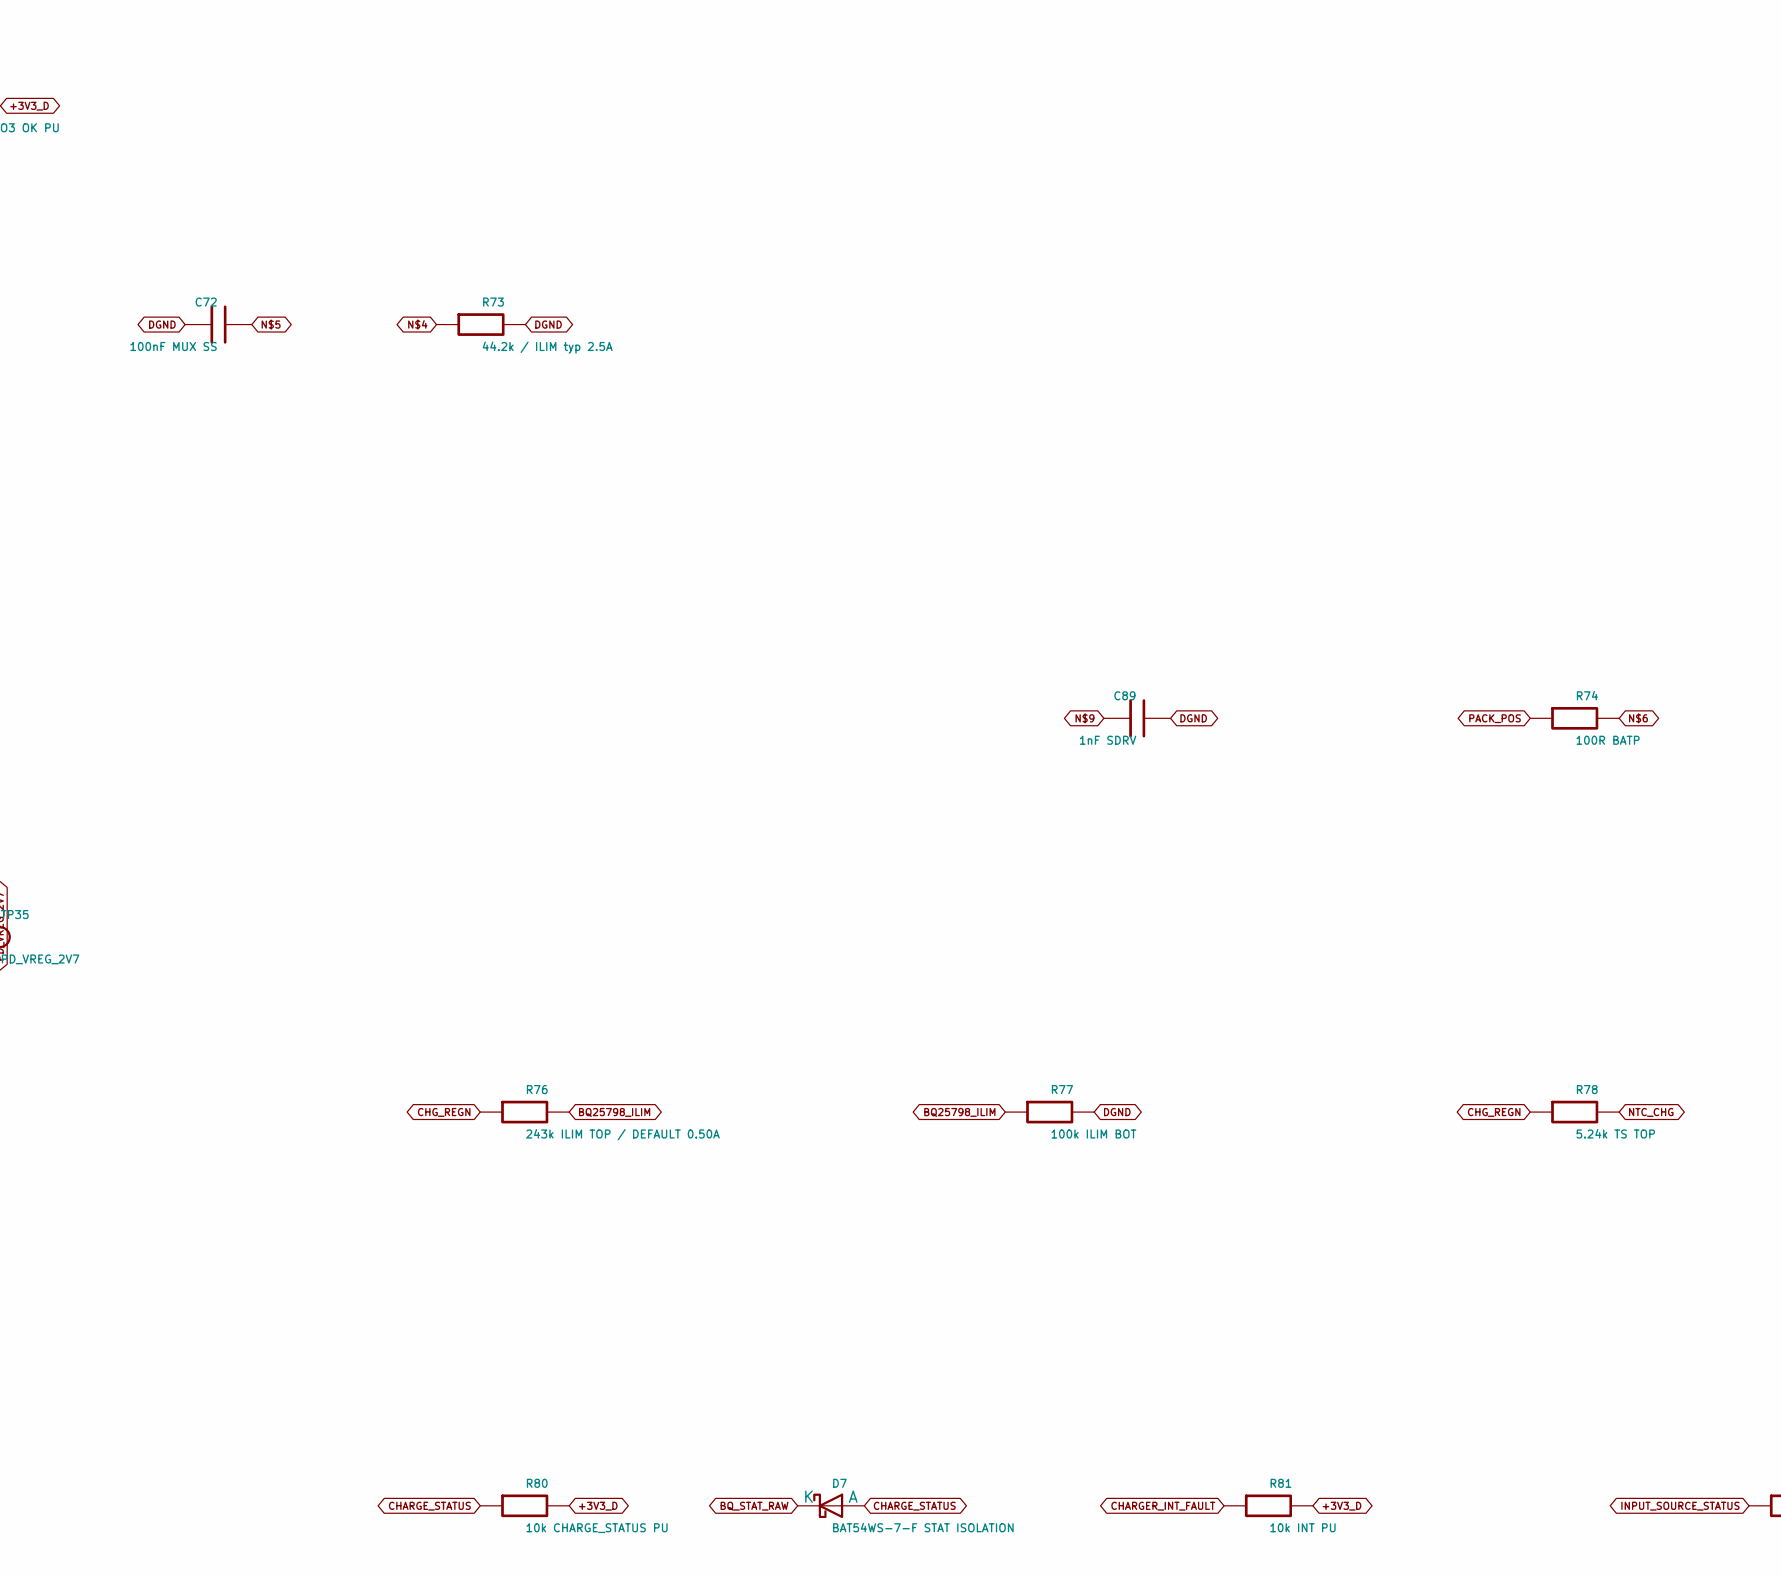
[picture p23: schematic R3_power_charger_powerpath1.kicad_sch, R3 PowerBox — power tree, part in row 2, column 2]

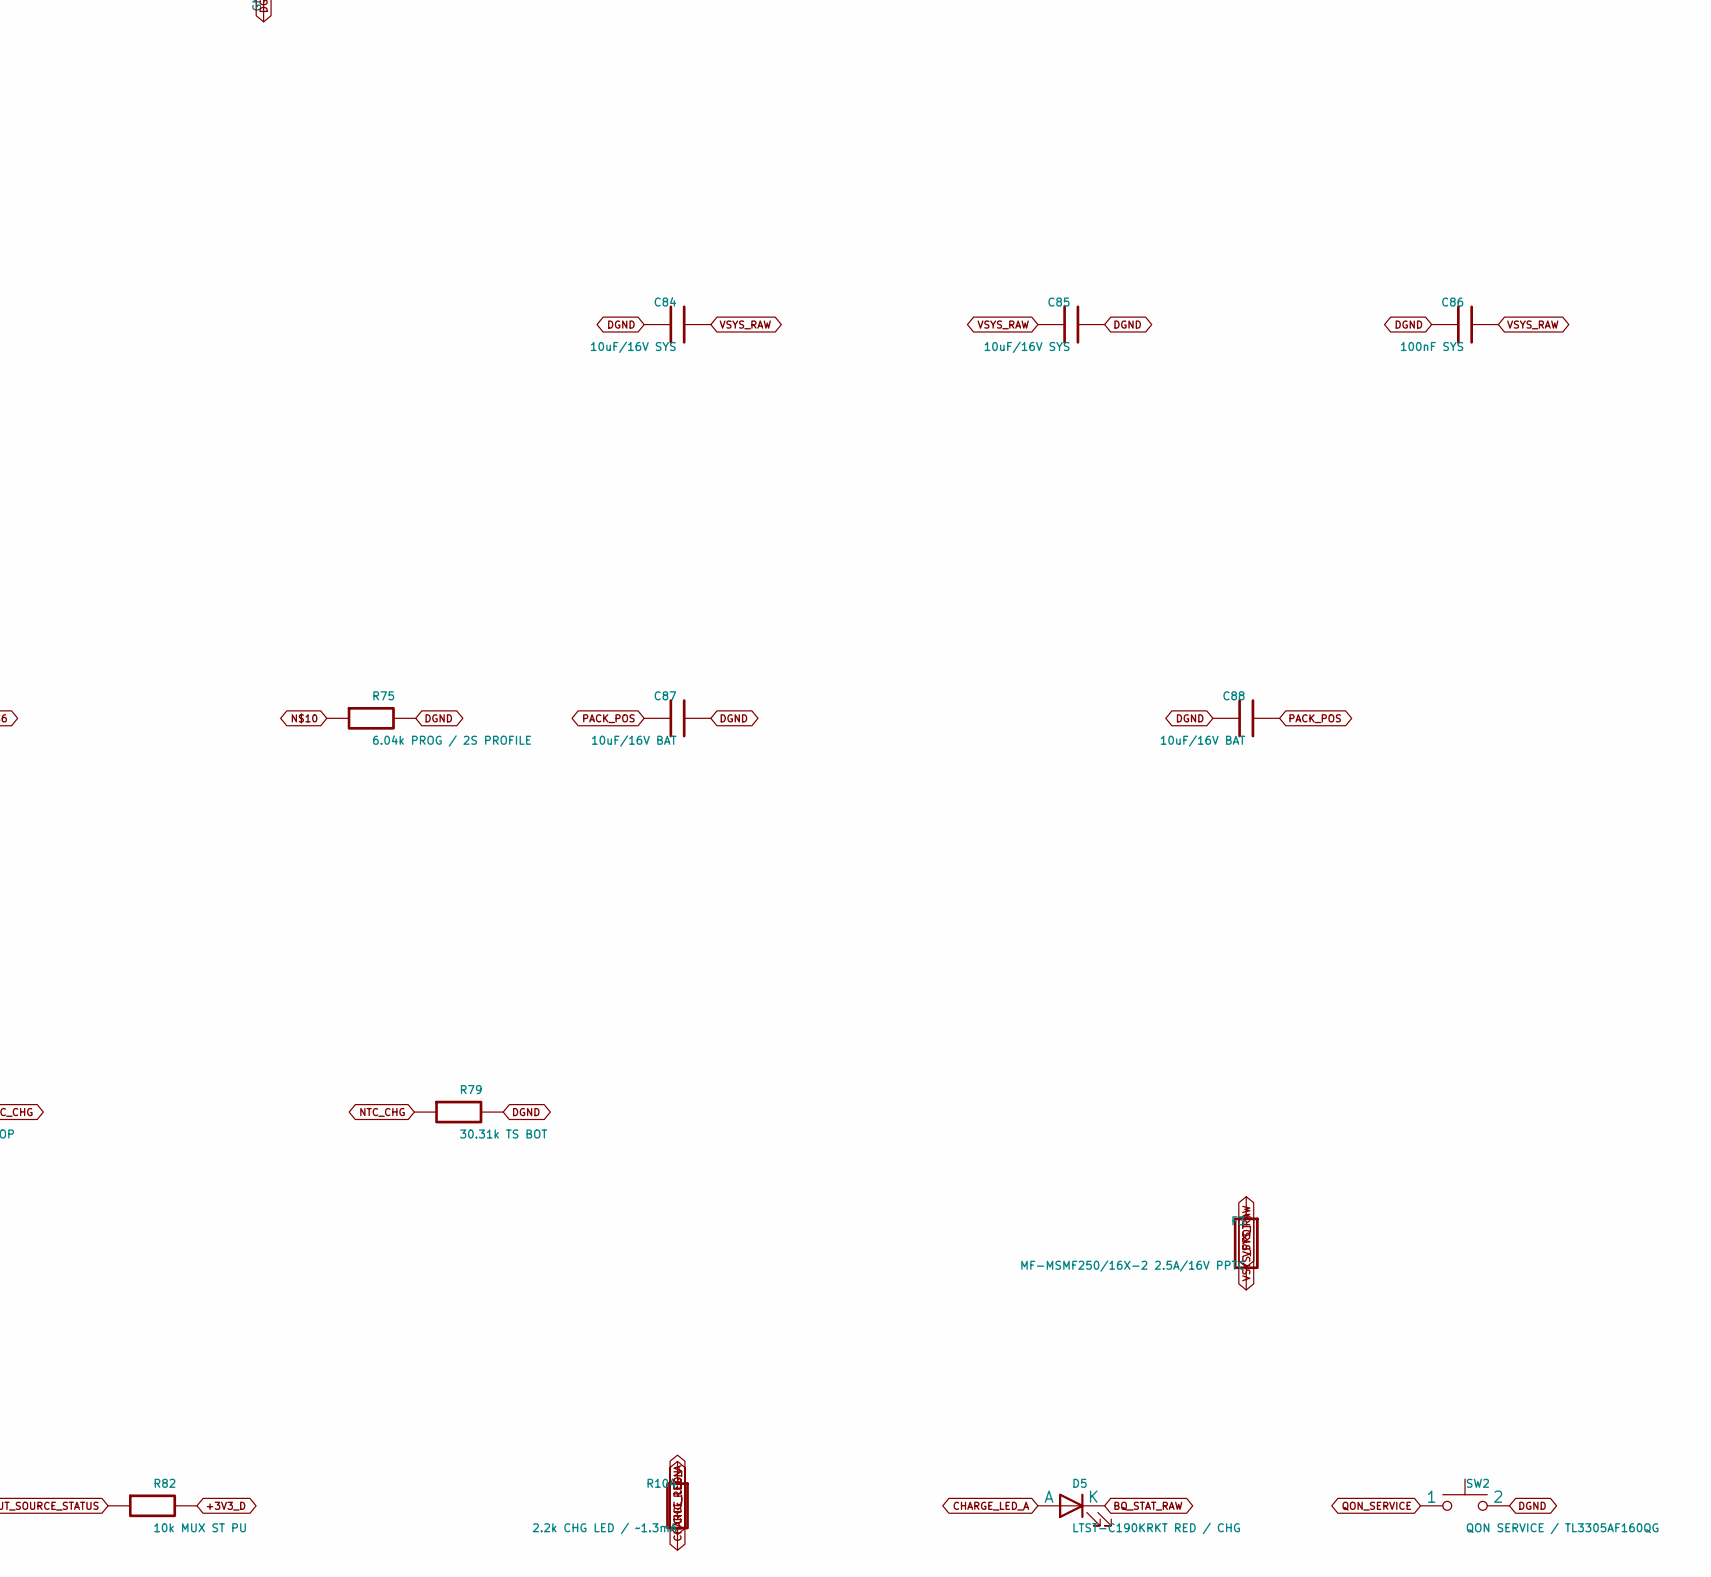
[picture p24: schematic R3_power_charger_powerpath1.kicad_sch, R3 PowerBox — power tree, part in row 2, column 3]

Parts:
C70: 4.7nF SHIELD; C_0603_1608Metric
C71: 10uF/25V USB; C_1206_3216Metric
C72: 100nF MUX SS; C_0603_1608Metric
C73: 10uF/25V MUX OUT; C_1206_3216Metric
C74: 47nF BTST1; C_0603_1608Metric
C75: 47nF BTST2; C_0603_1608Metric
C76: 4.7uF REGN; C_0603_1608Metric
C77, C78, C79: 10uF/25V PMID; C_1206_3216Metric
C80: 100nF PMID; C_0603_1608Metric
C81, C82, C83, C84, C85: 10uF/16V SYS; C_1206_3216Metric
C86: 100nF SYS; C_0603_1608Metric
C87, C88: 10uF/16V BAT; C_1206_3216Metric
C89: 1nF SDRV; C_0603_1608Metric
C100: 100nF/25V VBUS LOCAL; C_0402_1005Metric
C101, C102, C103: 10uF/25V VBUS LOCAL; C_1206_3216Metric
C104: 1uF VREG_1V2; C_0603_1608Metric
C105: 1uF VREG_2V7; C_0603_1608Metric
C106: 4.7uF/25V PD VDD; C_0603_1608Metric
D3: SMBJ13A / 13V VRWM USB VBUS; D_SMB
D4: ESDA25W CC ESD / P1,P2=CC P3=GND; SOT-323_SC-70
D5: LTST-C190KRKT RED / CHG; LED_0603_1608Metric
D7: BAT54WS-7-F STAT ISOLATION; D_SOD-323
F2: MF-MSMF260/16X-2 2.6A/16V PPTC; Fuse_1812_4532Metric_Pad1.30x3.40mm_HandSolder
F3: MF-MSMF250/16X-2 2.5A/16V PPTC; Fuse_1812_4532Metric_Pad1.30x3.40mm_HandSolder
J7: USB-C POWER INPUT; USB_C_Receptacle_GCT_USB4105-xx-A_16P_TopMnt_Horizontal
L3: 1.0uH >=6A / MPN TBD; L_Bourns_SRP7028A_7.3x6.6mm
R72: 1M SHIELD; R_0603_1608Metric
R73: 44.2k / ILIM typ 2.5A; R_0603_1608Metric
R74: 100R BATP; R_0603_1608Metric
R75: 6.04k PROG / 2S PROFILE; R_0603_1608Metric
R76: 243k ILIM TOP / DEFAULT 0.50A; R_0603_1608Metric
R77: 100k ILIM BOT; R_0603_1608Metric
R78: 5.24k TS TOP; R_0603_1608Metric
R79: 30.31k TS BOT; R_0603_1608Metric
R80: 10k CHARGE_STATUS PU; R_0603_1608Metric
R81: 10k INT PU; R_0603_1608Metric
R82: 10k MUX ST PU; R_0603_1608Metric
R83: 10k ALERT PU; R_0603_1608Metric
R84: 10k PDO3 OK PU; R_0603_1608Metric
R85: 0R PD VDD FEED; R_0603_1608Metric
R104: 2.2k CHG LED / ~1.3mA; R_0603_1608Metric
SW2: QON SERVICE / TL3305AF160QG; SW_SPST_TL3305A
TP20: USB_VBUS_RAW; TestPoint_Plated_Hole_D2.0mm
TP21: CHARGER_IN; TestPoint_Plated_Hole_D2.0mm
TP22: VSYS_RAW; TestPoint_Plated_Hole_D2.0mm
TP23: VSYS_PROT; TestPoint_Plated_Hole_D2.0mm
TP31: USB_CC1; TestPoint_Plated_Hole_D2.0mm
TP32: USB_CC2; TestPoint_Plated_Hole_D2.0mm
TP33: USB_VBUS_PROT; TestPoint_Plated_Hole_D2.0mm
TP34: PD_VDD; TestPoint_Plated_Hole_D2.0mm
TP35: PD_VREG_2V7; TestPoint_Plated_Hole_D2.0mm
TP36: PD_ALERT_N; TestPoint_Plated_Hole_D2.0mm
TP37: PM_I2C_SCL; TestPoint_Plated_Hole_D2.0mm
TP38: PM_I2C_SDA; TestPoint_Plated_Hole_D2.0mm
TP39: QON_SERVICE; TestPoint_Plated_Hole_D2.0mm
U7: TPS2121RUXR; Texas_VQFN-HR-12_2x2.5mm_P0.5mm
U8: BQ25798RQM; Texas_RQM0029A_VQFN-29_4x4mm_P0.4mm
U10: STUSB4500QTR; QFN-24-1EP_4x4mm_P0.5mm_EP2.7x2.7mm

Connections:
+3V3_D: R80.2, R81.2, R82.2, R83.2, R84.2; also elsewhere on the board
BQ25798_ILIM: R76.2, R77.1, U8.17 (ILIM_HIZ)
BQ_STAT_RAW: D5.1 (K), D7.1 (K), U8.1 (STAT); also elsewhere on the board
CHARGER_IN: C73.1, C100.1, C101.1, C102.1, C103.1, TP21.1, U7.1 (OUT), U7.8 (OUT), U8.2 (VBUS), U8.3 (VBUS), U8.8 (VAC2), U8.9 (VAC1)
CHARGER_INT_FAULT: R81.1, U8.21 (INT); also elsewhere on the board
CHARGE_LED_A: D5.2 (A), R104.2
CHARGE_STATUS: D7.2 (A), R80.1; also elsewhere on the board
CHG_PMID: C77.1, C78.1, C79.1, C80.1, U8.29 (PMID)
CHG_REGN: C76.1, R76.1, R78.1, R104.1, U8.5 (REGN)
CHG_SW1: C74.2, L3.1, U8.28 (SW1)
CHG_SW2: C75.2, L3.2, U8.26 (SW2)
DGND: C70.2, C71.2, C72.2, C73.2, C76.2, C77.2, C78.2, C79.2, C80.2, C81.2, C82.2, C83.2, C84.2, C85.2, C86.2, C87.2, C88.2, C89.2, C100.2, C101.2, C102.2, C103.2, C104.2, C105.2, C106.2, D3.1 (A), D4.3 (common), J7.A1 (GND), J7.A12 (GND), J7.B1 (GND), J7.B12 (GND), R72.2, R73.2, R75.2, R77.2, R79.2, SW2.2, U7.3 (CP2), U7.4 (OV2), U7.5 (OV1), U7.6 (PR1), U7.12 (GND), U8.10 (ACDRV2), U8.11 (ACDRV1), U8.13 (CE), U8.27 (GND), U10.6 (RESET), U10.10 (GND), U10.12 (ADDR0), U10.13 (ADDR1), U10.22 (VSYS), U10.25 (GND); also elsewhere on the board
INPUT_SOURCE_STATUS: R82.1, U7.9 (ST); also elsewhere on the board
unnamed: R73.1, U7.10 (ILIM)
unnamed: C72.1, U7.11 (SS)
unnamed: R74.2, U8.18 (BATP)
unnamed: C74.1, U8.4 (BTST1)
unnamed: C75.1, U8.19 (BTST2)
unnamed: C89.1, U8.24 (SDRV)
unnamed: R75.1, U8.20 (PROG)
NTC_CHG: R78.2, R79.1, U8.16 (TS); also elsewhere on the board
PACK_POS: C87.1, C88.1, R74.1, U8.22 (BAT), U8.23 (BAT); also elsewhere on the board
PD_ALERT_N: R83.1, TP36.1, U10.19 (ALERT); also elsewhere on the board
PD_CONTRACT_12V_N: R84.1, U10.14 (POWER_OK3); also elsewhere on the board
PD_VDD: C106.1, R85.2, TP34.1, U10.24 (VDD)
PD_VREG_1V2: C104.1, U10.21 (VREG_1V2)
PD_VREG_2V7: C105.1, TP35.1, U10.23 (VREG_2V7)
PM_I2C_SCL: TP37.1, U8.14 (SCL), U10.7 (SCL); also elsewhere on the board
PM_I2C_SDA: TP38.1, U8.15 (SDA), U10.8 (SDA); also elsewhere on the board
QON_SERVICE: SW2.1, TP39.1, U8.12 (QON); also elsewhere on the board
SERVICE_IN_PROT: U7.2 (IN2); also elsewhere on the board
USB_CC1: D4.1 (A1), J7.A5 (CC1), TP31.1, U10.1 (CC1DB), U10.2 (CC1)
USB_CC2: D4.2 (A2), J7.B5 (CC2), TP32.1, U10.4 (CC2), U10.5 (CC2DB)
USB_SHIELD: C70.1, J7.SH (SHIELD), R72.1
USB_VBUS_PROT: C71.1, D3.2 (K), F2.2, R85.1, TP33.1, U7.7 (IN1), U10.18 (VBUS_VS_DISCH)
USB_VBUS_RAW: F2.1, J7.A4 (VBUS), J7.A9 (VBUS), J7.B4 (VBUS), J7.B9 (VBUS), TP20.1
VSYS_PROT: F3.2, TP23.1; also elsewhere on the board
VSYS_RAW: C81.1, C82.1, C83.1, C84.1, C85.1, C86.1, F3.1, TP22.1, U8.25 (SYS)

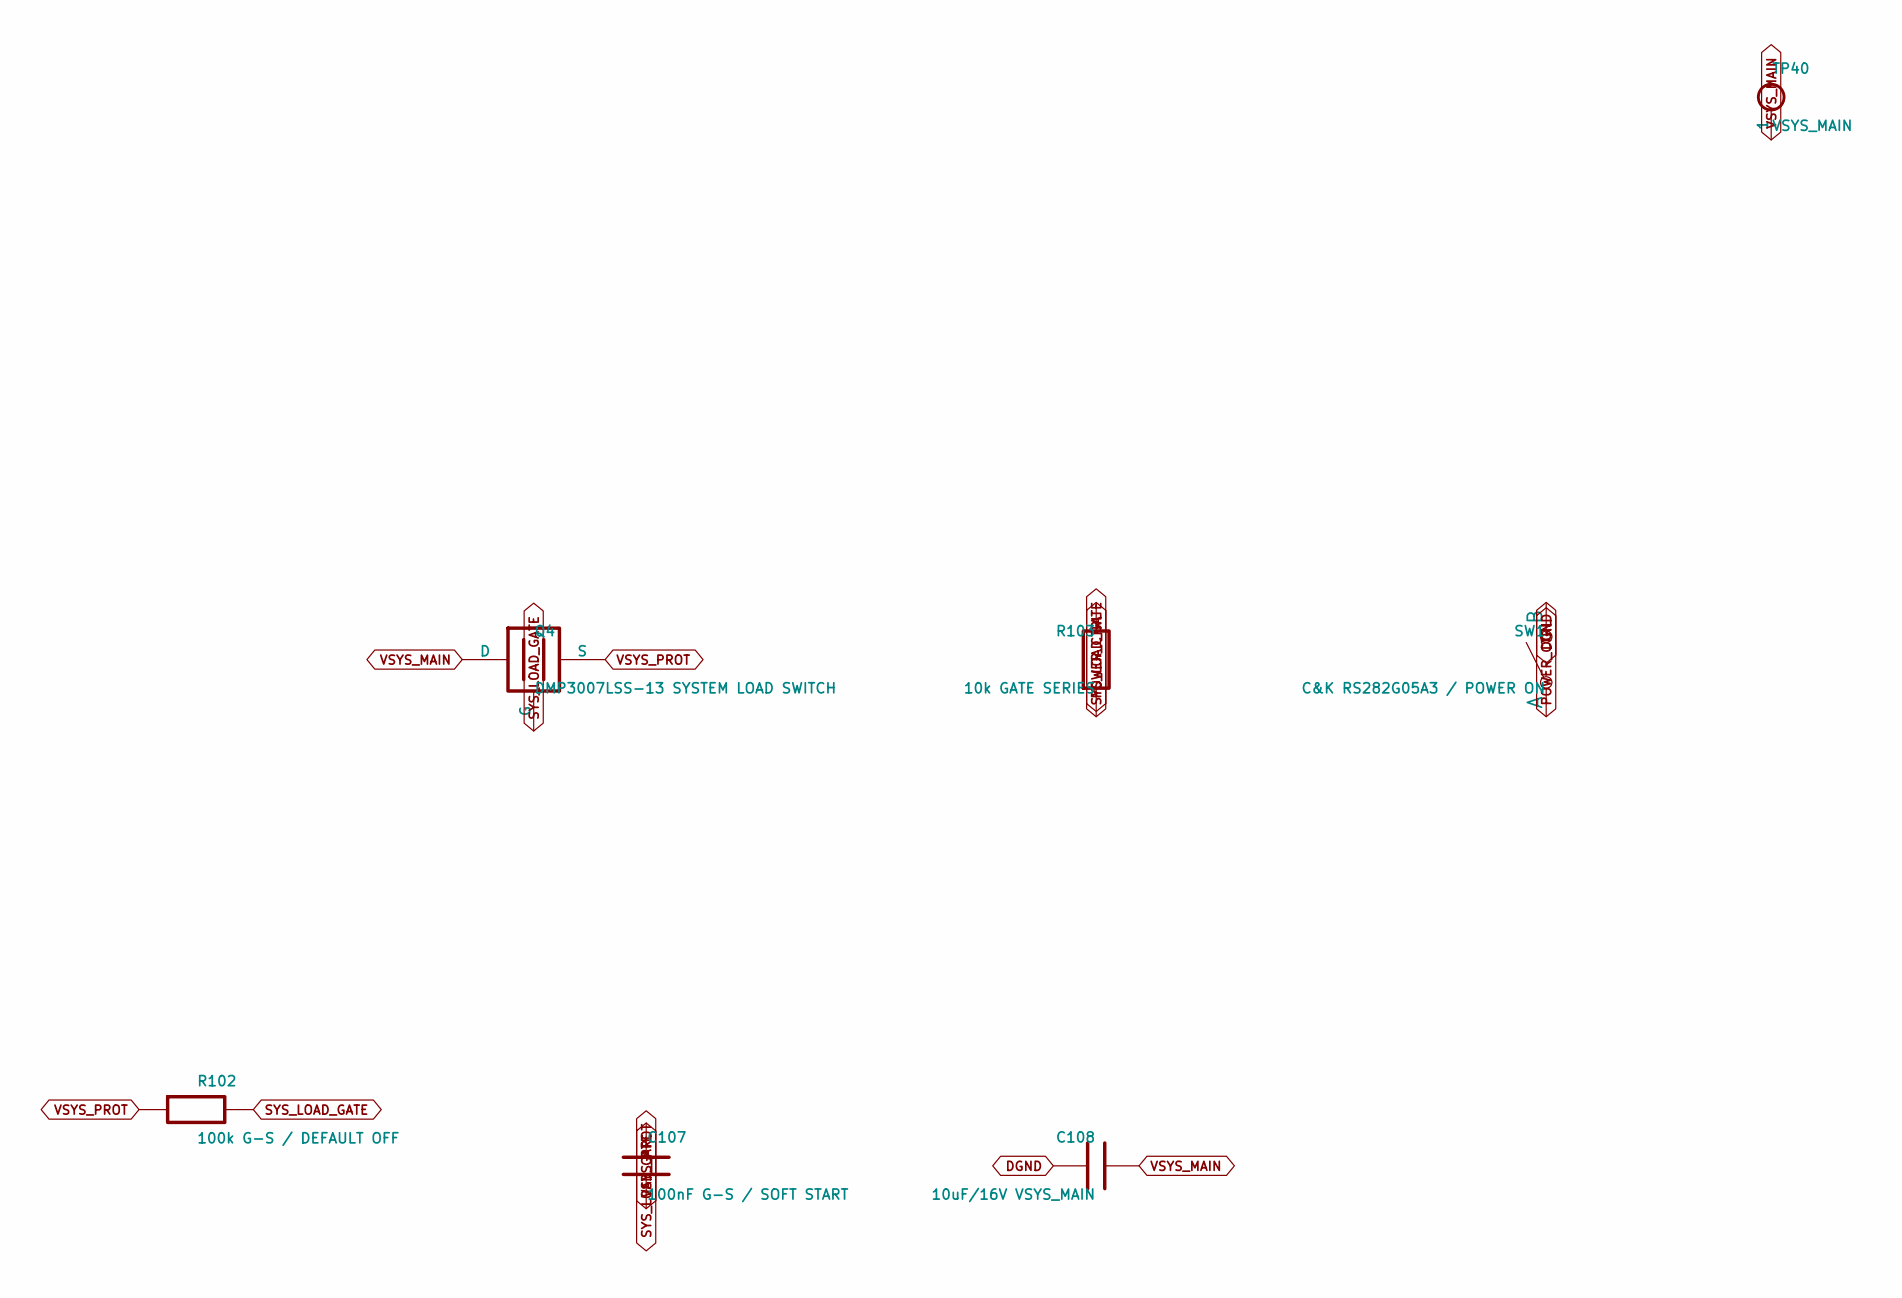
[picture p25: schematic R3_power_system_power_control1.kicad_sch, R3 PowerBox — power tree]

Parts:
C107: 100nF G-S / SOFT START; C_0603_1608Metric
C108: 10uF/16V VSYS_MAIN; C_1206_3216Metric
Q4: DMP3007LSS-13 SYSTEM LOAD SWITCH; DMP3007LSS_SO8_LOGICAL
R102: 100k G-S / DEFAULT OFF; R_0603_1608Metric
R103: 10k GATE SERIES; R_0603_1608Metric
SW1: C&K RS282G05A3 / POWER ON; SW_SPST_CK_RS282G05A3
TP40: VSYS_MAIN; TestPoint_Plated_Hole_D2.0mm

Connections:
DGND: C108.2, SW1.2 (B); also elsewhere on the board
POWER_CTRL: R103.2, SW1.1 (A); also elsewhere on the board
SYS_LOAD_GATE: C107.2, Q4.1 (G), R102.2, R103.1
VSYS_MAIN: C108.1, Q4.3 (D), TP40.1; also elsewhere on the board
VSYS_PROT: C107.1, Q4.2 (S), R102.1; also elsewhere on the board

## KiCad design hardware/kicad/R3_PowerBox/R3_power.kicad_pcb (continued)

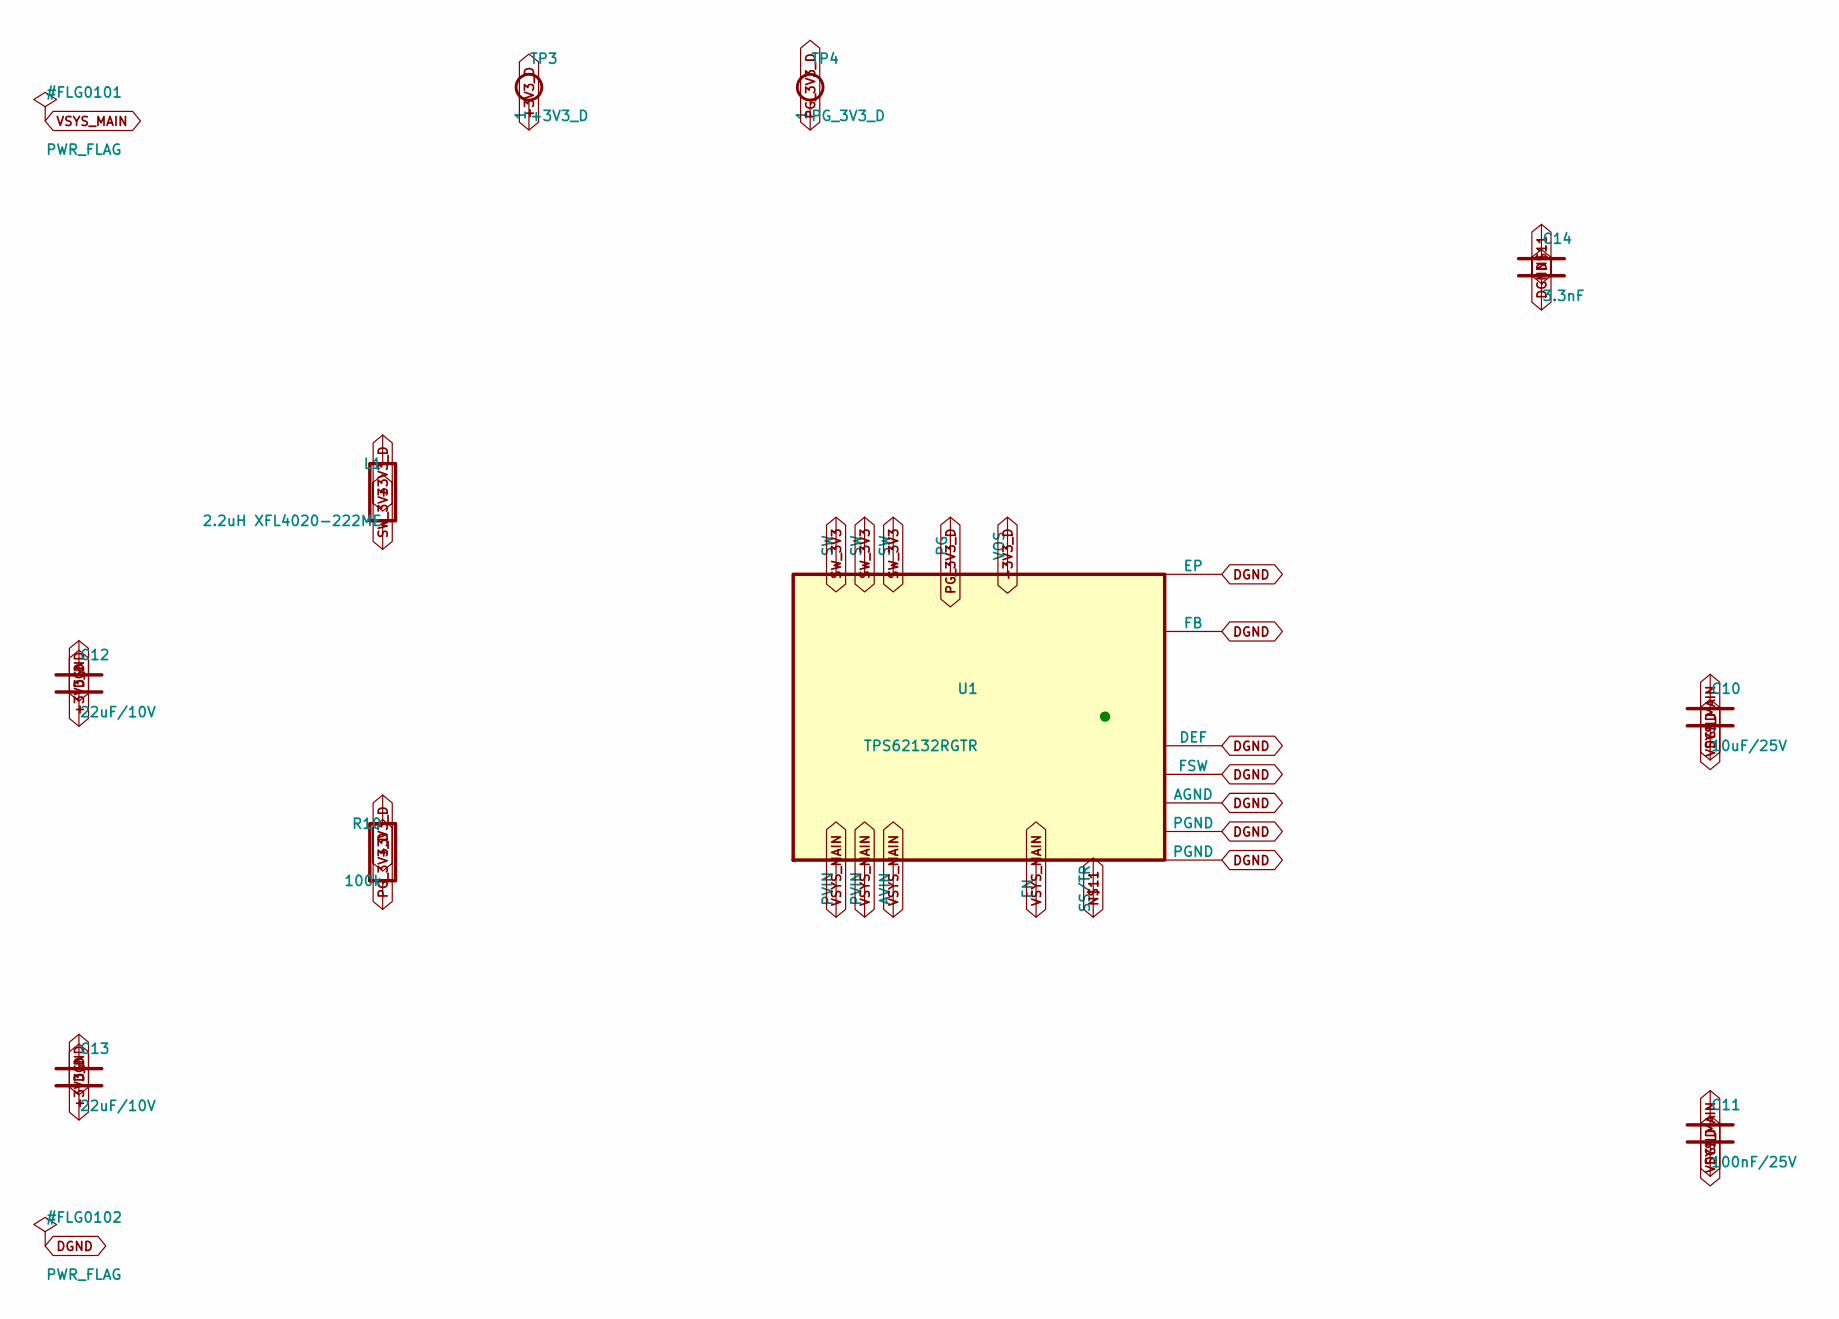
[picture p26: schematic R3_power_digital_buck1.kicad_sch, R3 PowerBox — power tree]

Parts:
C10: 10uF/25V; C_1206_3216Metric
C11: 100nF/25V; C_0603_1608Metric
C12, C13: 22uF/10V; C_0805_2012Metric
C14: 3.3nF; C_0603_1608Metric
L1: 2.2uH XFL4020-222ME; L_Coilcraft_XFL4020
R10: 100k; R_0603_1608Metric
TP3: +3V3_D; TestPoint_Plated_Hole_D2.0mm
TP4: PG_3V3_D; TestPoint_Plated_Hole_D2.0mm
U1: TPS62132RGTR; VQFN-16-1EP_3x3mm_P0.5mm_EP1.45x1.45mm

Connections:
+3V3_D: C12.1, C13.1, L1.2, R10.2, TP3.1, U1.14 (VOS); also elsewhere on the board
DGND: C10.2, C11.2, C12.2, C13.2, C14.2, U1.5 (FB), U1.6 (AGND), U1.7 (FSW), U1.8 (DEF), U1.15 (PGND), U1.16 (PGND), U1.17 (EP); also elsewhere on the board
unnamed: C14.1, U1.9 (SS/TR)
PG_3V3_D: R10.1, TP4.1, U1.4 (PG); also elsewhere on the board
SW_3V3: L1.1, U1.1 (SW), U1.2 (SW), U1.3 (SW)
VSYS_MAIN: C10.1, C11.1, U1.10 (AVIN), U1.11 (PVIN), U1.12 (PVIN), U1.13 (EN); also elsewhere on the board

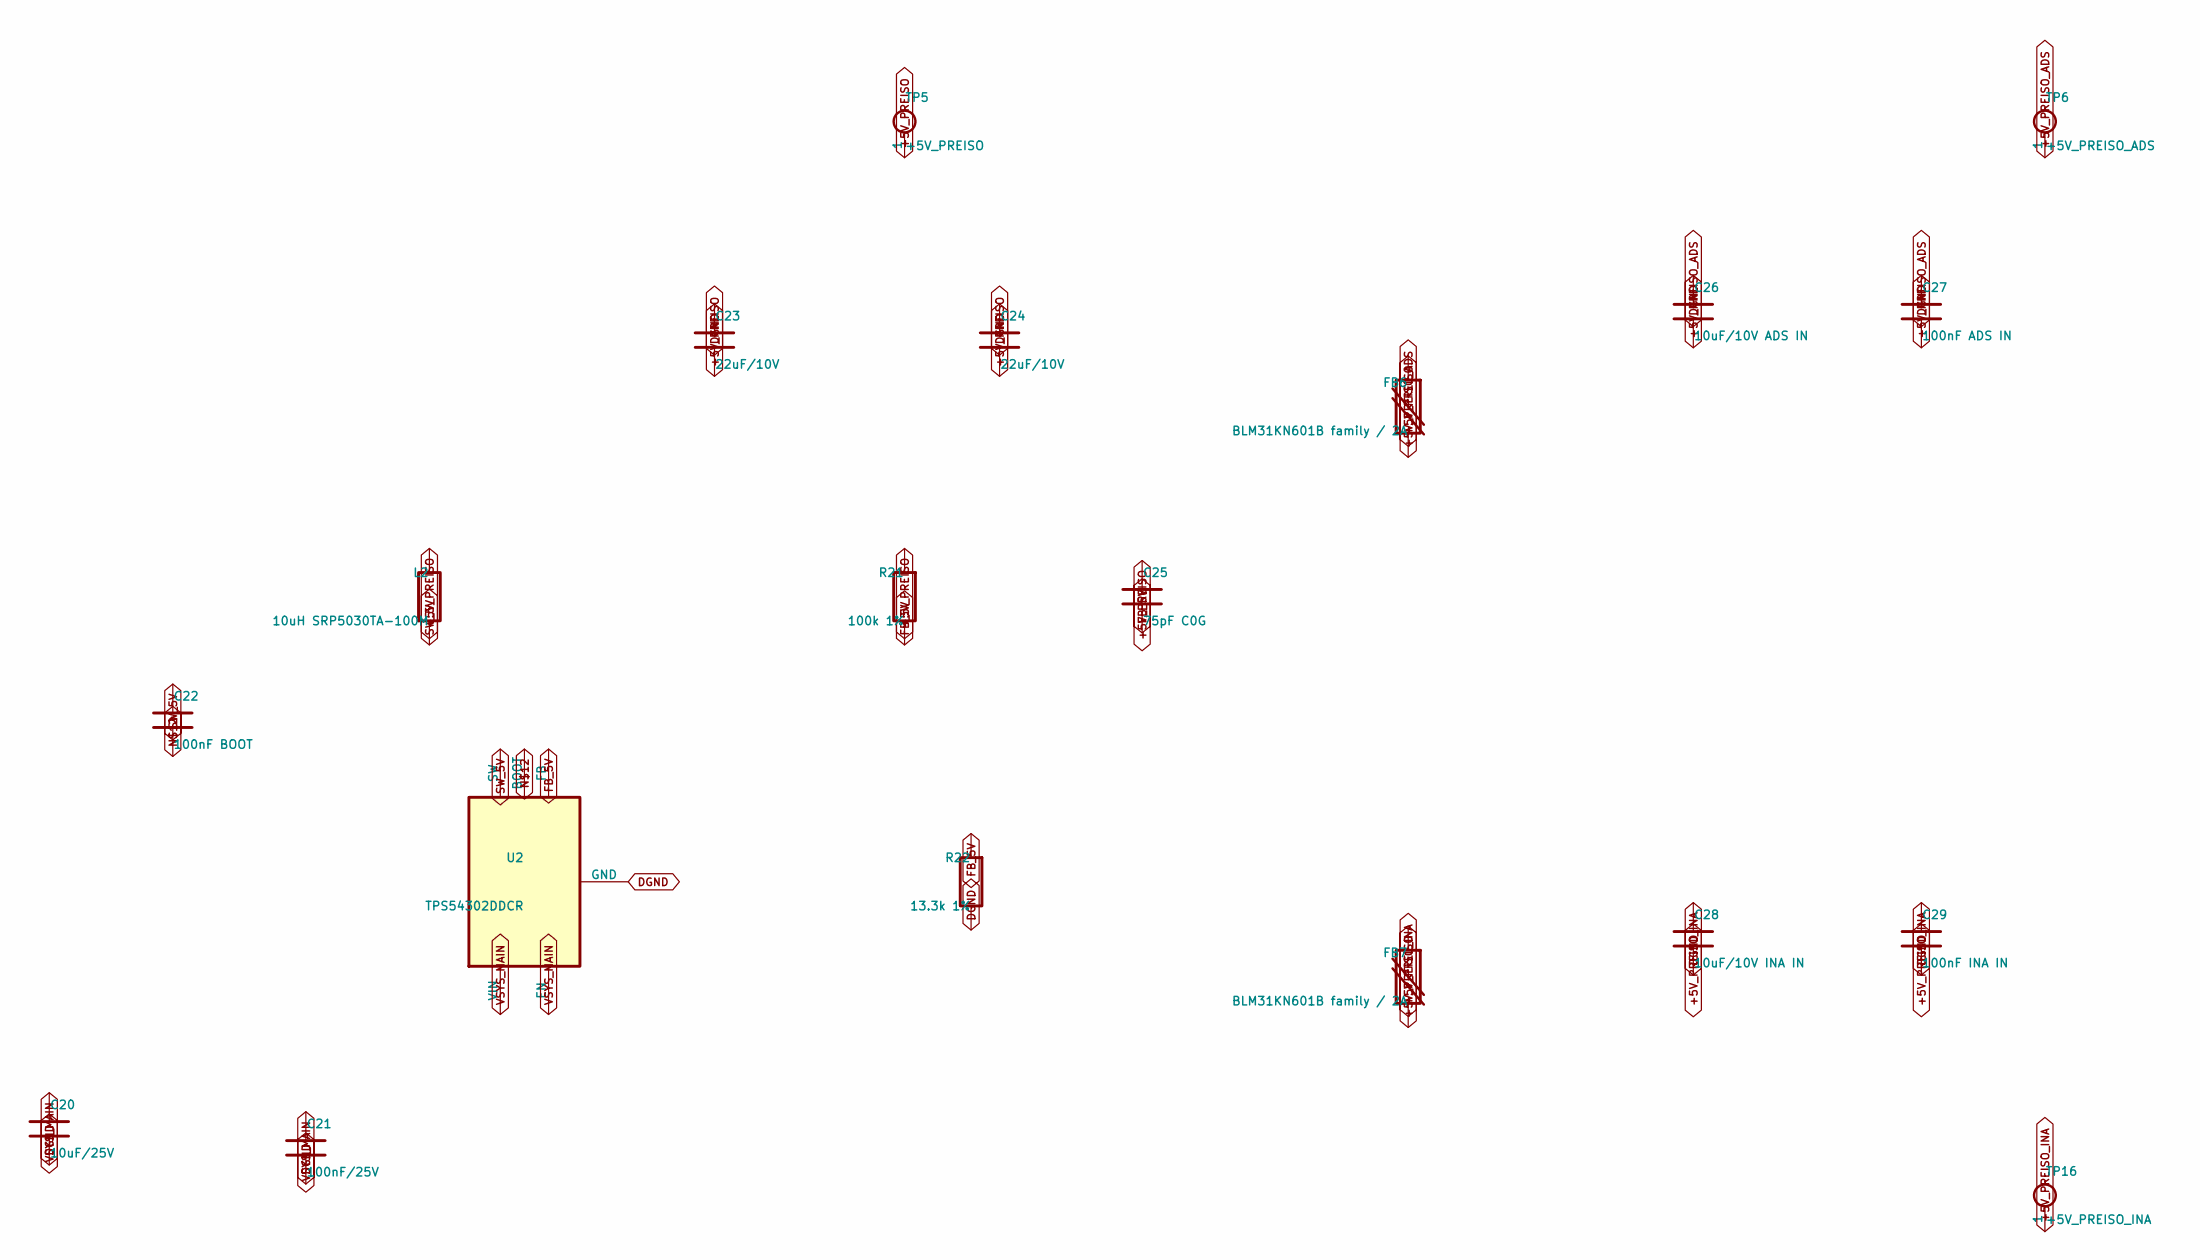
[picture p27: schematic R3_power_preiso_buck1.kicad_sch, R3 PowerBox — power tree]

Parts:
C20: 10uF/25V; C_1206_3216Metric
C21: 100nF/25V; C_0603_1608Metric
C22: 100nF BOOT; C_0603_1608Metric
C23, C24: 22uF/10V; C_0805_2012Metric
C25: 75pF C0G; C_0603_1608Metric
C26: 10uF/10V ADS IN; C_0805_2012Metric
C27: 100nF ADS IN; C_0603_1608Metric
C28: 10uF/10V INA IN; C_0805_2012Metric
C29: 100nF INA IN; C_0603_1608Metric
FB6, FB7: BLM31KN601B family / 2A; L_1206_3216Metric_Pad1.22x1.90mm_HandSolder
L2: 10uH SRP5030TA-100M; L_Bourns_SRP5030T
R21: 100k 1%; R_0603_1608Metric
R22: 13.3k 1%; R_0603_1608Metric
TP5: +5V_PREISO; TestPoint_Plated_Hole_D2.0mm
TP6: +5V_PREISO_ADS; TestPoint_Plated_Hole_D2.0mm
TP16: +5V_PREISO_INA; TestPoint_Plated_Hole_D2.0mm
U2: TPS54302DDCR; SOT-23-6

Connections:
+5V_PREISO: C23.1, C24.1, C25.1, FB6.1, FB7.1, L2.2, R21.1, TP5.1
+5V_PREISO_ADS: C26.1, C27.1, FB6.2, TP6.1; also elsewhere on the board
+5V_PREISO_INA: C28.1, C29.1, FB7.2, TP16.1; also elsewhere on the board
DGND: C20.2, C21.2, C23.2, C24.2, C26.2, C27.2, C28.2, C29.2, R22.2, U2.1 (GND); also elsewhere on the board
FB_5V: C25.2, R21.2, R22.1, U2.4 (FB)
unnamed: C22.1, U2.6 (BOOT)
SW_5V: C22.2, L2.1, U2.2 (SW)
VSYS_MAIN: C20.1, C21.1, U2.3 (VIN), U2.5 (EN); also elsewhere on the board


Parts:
C30: 10uF/10V RAW; C_0805_2012Metric
C31: 100nF RAW; C_0603_1608Metric
C32: 10uF A bulk; C_0805_2012Metric
C33: 100nF A; C_0603_1608Metric
C34: 10uF D bulk; C_0805_2012Metric
C35: 100nF D; C_0603_1608Metric
FB2: FB_A / FB-or-0R; R_0805_2012Metric
FB3: FB_D / FB-or-0R; R_0805_2012Metric
TP7: +5V_ISO_RAW; TestPoint_Plated_Hole_D2.0mm
TP8: +5V_ISO_A; TestPoint_Plated_Hole_D2.0mm
TP9: +5V_ISO_D; TestPoint_Plated_Hole_D2.0mm
TP10: GND_ISO; TestPoint_Plated_Hole_D2.0mm
U3: RS3E-0505S/H3; Converter_DCDC_RECOM_RS3E_SIP8

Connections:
+5V_ISO_A: C32.1, C33.1, FB2.2, TP8.1; also elsewhere on the board
+5V_ISO_D: C34.1, C35.1, FB3.2, TP9.1; also elsewhere on the board
+5V_ISO_RAW: C30.1, C31.1, FB2.1, FB3.1, TP7.1, U3.6 (+VOUT); also elsewhere on the board
+5V_PREISO_ADS: U3.2 (+VIN); also elsewhere on the board
CTRL_RS3E_PRI: U3.3 (CTRL); also elsewhere on the board
DGND: U3.1 (-VIN); also elsewhere on the board
GND_ISO: C30.2, C31.2, C32.2, C33.2, C34.2, C35.2, TP10.1, U3.7 (-VOUT); also elsewhere on the board


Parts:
C40: 10uF VIN; C_0805_2012Metric
C41: 10uF VREG; C_0805_2012Metric
C42: 10uF VOUT; C_0805_2012Metric
C43: 1uF REF; C_0603_1608Metric
C44: 1uF BYP; C_0603_1608Metric
C50: 2.2uF IN; C_0603_1608Metric
C51: 4.7uF OUT; C_0603_1608Metric
R40: 10k; R_0603_1608Metric
TP11: +3V3_A_ISO; TestPoint_Plated_Hole_D2.0mm
TP12: +3V3_D_ISO; TestPoint_Plated_Hole_D2.0mm
U4: ADM7150ACPZ-3.3-R7; LFCSP-8-1EP_3x3mm_P0.5mm_EP1.74x1.45mm
U5: TPS7A2033PDBVR; SOT-23-5

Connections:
+3V3_A_ISO: C42.1, TP11.1, U4.2 (VOUT); also elsewhere on the board
+3V3_D_ISO: C51.1, TP12.1, U5.5 (OUT); also elsewhere on the board
+5V_ISO_A: C40.1, R40.1, U4.8 (VIN); also elsewhere on the board
+5V_ISO_D: C50.1, U5.1 (IN), U5.3 (EN); also elsewhere on the board
ADM7150_REF: C43.1, U4.5 (REF_SENSE), U4.6 (REF)
EN_3V3_A_ISO: R40.2, U4.7 (EN)
GND_ISO: C40.2, C41.2, C42.2, C43.2, C44.2, C50.2, C51.2, U4.4 (GND), U4.9 (EP), U5.2 (GND); also elsewhere on the board
unnamed: C41.1, U4.1 (VREG)
unnamed: C44.1, U4.3 (BYP)

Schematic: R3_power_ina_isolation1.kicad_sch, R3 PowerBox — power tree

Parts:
C60: 10uF +5V bulk; C_0805_2012Metric
C61: 100nF +5V; C_0603_1608Metric
C62: 10uF -5V bulk; C_0805_2012Metric
C63: 100nF -5V; C_0603_1608Metric
FB4: FB_INA_P / FB-or-0R; R_0805_2012Metric
FB5: FB_INA_N / FB-or-0R; R_0805_2012Metric
TP13: +5V_INA; TestPoint_Plated_Hole_D2.0mm
TP14: -5V_INA; TestPoint_Plated_Hole_D2.0mm
U6: RS3-0505D/H3; Converter_DCDC_RECOM_RS3_SIP8

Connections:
+5V_INA: C60.1, C61.1, FB4.2, TP13.1; also elsewhere on the board
+5V_INA_RAW: FB4.1, U6.6 (+VOUT)
+5V_PREISO_INA: U6.2 (+VIN); also elsewhere on the board
-5V_INA: C62.2, C63.2, FB5.2, TP14.1; also elsewhere on the board
-5V_INA_RAW: FB5.1, U6.8 (-VOUT)
DGND: U6.1 (-VIN); also elsewhere on the board
GND_ISO: C60.2, C61.2, C62.1, C63.1, U6.7 (COM); also elsewhere on the board

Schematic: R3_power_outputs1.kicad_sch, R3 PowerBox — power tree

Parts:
D6: LTST-C190KGKT GREEN / RUN; LED_0603_1608Metric
J2: DIGITAL POWER OUT; Molex_Micro-Fit_3.0_43650-0600_1x06_P3.00mm_Horizontal
J3: ISOLATED POWER OUT; Molex_Micro-Fit_3.0_43650-1000_1x10_P3.00mm_Horizontal
J4: CONTROL / SERVICE; Molex_Micro-Fit_3.0_43650-0400_1x04_P3.00mm_Horizontal
J5: PRIMARY AUX DNP; JST_GH_SM04B-GHS-TB_1x04-1MP_P1.25mm_Horizontal
J6: ISOLATED AUX DNP; JST_GH_SM04B-GHS-TB_1x04-1MP_P1.25mm_Horizontal
J10: BATTERY / CHARGER TELEMETRY; Molex_Micro-Fit_3.0_43650-1000_1x10_P3.00mm_Horizontal
J11: USER PANEL / PRIMARY ONLY; Molex_Micro-Fit_3.0_43650-1000_1x10_P3.00mm_Horizontal
J12: PRIMARY B2B 2x8 / DNP; PinHeader_2x08_P2.54mm_Vertical
J13: ISOLATED B2B 2x5 / DNP; PinHeader_2x05_P2.54mm_Vertical
R105: 2.2k RUN LED / ~0.7mA; R_0603_1608Metric
TP15: DGND; TestPoint_Plated_Hole_D2.0mm

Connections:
+3V3_A_ISO: J3.3, J6.2, J13.3; also elsewhere on the board
+3V3_D: J2.1, J2.2, J5.1, J10.1, J11.1, J12.1, J12.2, R105.1; also elsewhere on the board
+3V3_D_ISO: J3.5, J6.1, J13.5; also elsewhere on the board
+5V_INA: J3.7, J13.7; also elsewhere on the board
+5V_ISO_RAW: J3.1, J13.1; also elsewhere on the board
-5V_INA: J3.9, J13.9; also elsewhere on the board
BQ_STAT_RAW: J11.9; also elsewhere on the board
CHARGER_INT_FAULT: J10.7, J12.9; also elsewhere on the board
CHARGE_STATUS: J10.5, J11.5, J12.8; also elsewhere on the board
CTRL_RS3E_PRI: J4.3; also elsewhere on the board
DGND: D6.1 (K), J2.3, J2.4, J4.1, J5.2, J10.2, J11.2, J12.3, J12.4, TP15.1; also elsewhere on the board
GND_ISO: J3.2, J3.4, J3.6, J3.8, J3.10, J6.3, J13.2, J13.4, J13.6, J13.8, J13.10; also elsewhere on the board
INPUT_SOURCE_STATUS: J10.8, J12.10; also elsewhere on the board
PD_ALERT_N: J10.9, J12.11; also elsewhere on the board
PD_CONTRACT_12V_N: J10.10, J12.12; also elsewhere on the board
PG_3V3_D: J2.5, J4.2, J10.6, J11.6, J12.7; also elsewhere on the board
PM_I2C_SCL: J10.3, J11.7, J12.5; also elsewhere on the board
PM_I2C_SDA: J10.4, J11.8, J12.6; also elsewhere on the board
POWER_CTRL: J11.3, J12.13; also elsewhere on the board
QON_SERVICE: J11.4, J12.14; also elsewhere on the board
RUN_LED_A: D6.2 (A), R105.2

Board: 4 copper layers, 199 parts (0 on the bottom side), 85 nets, no tracks yet.

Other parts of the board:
H1, H2, H3, H4, H5, H6: M3 NPTH 3.2mm / 8mm KEEPOUT; MountingHole_M3_NPTH_3.2mm_Keepout8mm

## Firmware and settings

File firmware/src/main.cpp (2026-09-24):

#include <Arduino.h>
#include <Wire.h>
#include <SPI.h>
#include <SD.h>
#include <cstring>
#include <cmath>
#include <ctime>
#include <Adafruit_SH110X.h>
#include "pins.h"
#include "ota_update.h"
#include "eeprom_test.h"
#include "rtc_test.h"
#include "ina228_test.h"
#include "storage_check.h"
#include "settings.h"
#include "local_input.h"
#include "recording_memory.h"
#include "test_panel.h"
#include "live_history.h"
#include "sd_files.h"
#include "recorder.h"
#include "build_provenance.h"
#include "firmware_version.h"
#include "rate_benchmark.h"
#include "r3_ble_client.h"
#include "ecosystem_owner.h"
#include <esp_timer.h>
#include <esp_system.h>

#ifndef R1_SERVICE_TESTS
#define R1_SERVICE_TESTS 0
#endif

bool i2cReady = false;
bool sdPassed = false;
const char* sdStatus = "WAIT";
bool oledReady = false;
const char* eepromStatus = "NOT RUN";
const char* rtcStatus = "WAIT";
const char* inaStatus = "WAIT";
unsigned i2cCount = 0;
unsigned i2cErrors = 0;
Adafruit_SH1106G oled(128, 64, &Wire, -1, 100000, 100000);

uint8_t oledFrame[1024];
unsigned oledOffset=1024;
uint32_t oledFrames=0, oledChunkUs=0;
int lastContrast=-1;

void updateOled() {
    if (!oledReady) return;

    oled.clearDisplay();
    oled.setTextColor(SH110X_WHITE);
    oled.setTextWrap(false);
    oled.setTextSize(1);
    oled.setCursor(4, 3);
    const uint64_t utc=rtcUtcNow();
    if(utc){const time_t local=time_t(int64_t(utc)+int64_t(appliedSettings().display_utc_offset_min)*60);struct tm clock{};gmtime_r(&local,&clock);oled.printf("%02d:%02d:%02d",clock.tm_hour,clock.tm_min,clock.tm_sec);}
    else oled.print("SET TIME");
    const auto& reading = latestIna228Reading();
    static double shownVolts=0, shownAmps=0;
    static uint32_t lastDisplay=0;
    static bool filterValid=false;
    const auto& config=appliedSettings();
    const uint32_t tick=millis();
    if (reading.valid) {
        const double alpha=filterValid && config.display_filter_tau_ms
            ? -std::expm1(-double(uint32_t(tick-lastDisplay))/config.display_filter_tau_ms) : 1.0;
        shownVolts+=alpha*(reading.busVolts-shownVolts);
        shownAmps+=alpha*(reading.currentAmps-shownAmps);
        filterValid=true;
    } else filterValid=false;
    lastDisplay=tick;
    if (reading.valid) {
        oled.setCursor(58, 3);
        oled.printf("T:%5.1f C", reading.temperatureC);
        oled.setTextSize(2);
        oled.setCursor(4, 15);
        oled.printf("%7.3f V", shownVolts);
        oled.setCursor(4, 33);
        if (shownAmps >= 1000 || shownAmps <= -1000)
            oled.printf("%+8.2f A", shownAmps);
        else
            oled.printf("%+8.3f A", shownAmps);
    } else {
        oled.setCursor(4, 18);
        oled.printf("INA: %s", inaStatus);
        oled.setCursor(4, 33);
        oled.print("U: ---  I: ---");
    }
    oled.setTextSize(1);
    oled.setCursor(4, 53);
    // Alternate diagnostics without crowding the two measurement lines.
    if (recorder::busy() || recorder::state()==recorder::State::Error)
        oled.printf("REC:%s",recorder::stateName());
    else if ((millis() / 3000) % 2 == 0)
        oled.printf("SD:%s %s", sdStatus, settingsStatus());
    else
        oled.printf("RTC:%s E:%u", rtcStatus, i2cErrors);
    oled.drawRect(0, 0, 128, 64, SH110X_WHITE);
    memcpy(oledFrame,oled.getBuffer(),sizeof(oledFrame));
    oledOffset=0;
}

// A frozen frame is sent in small, individually addressed pieces by the I2C owner.
// No complete-frame Wire transfer can block the next acquisition deadline.
void oledStep() {
    if(!oledReady)return;
    const uint64_t began=esp_timer_get_time();
    if(lastContrast!=appliedSettings().oled_contrast){
        Wire.beginTransmission(0x3C);Wire.write(0);Wire.write(0x81);Wire.write(appliedSettings().oled_contrast);
        if(Wire.endTransmission()==0)lastContrast=appliedSettings().oled_contrast;else ++i2cErrors;
    }else if(oledOffset<sizeof(oledFrame)){
        const uint8_t col=(oledOffset%128)+2;
        Wire.beginTransmission(0x3C);Wire.write(0);Wire.write(0xB0+oledOffset/128);
        Wire.write(col&15);Wire.write(0x10|(col>>4));
        bool ok=Wire.endTransmission()==0;
        if(ok){
            Wire.beginTransmission(0x3C);Wire.write(0x40);Wire.write(oledFrame+oledOffset,8);
            ok=Wire.endTransmission()==0;
        }
        if(ok){oledOffset+=8;if(oledOffset==sizeof(oledFrame))++oledFrames;}
        else{++i2cErrors;oledOffset=sizeof(oledFrame);}
    }
    const uint32_t elapsed=esp_timer_get_time()-began;
    if(elapsed>oledChunkUs)oledChunkUs=elapsed;
}

void initOled() {
    if (!i2cReady) return;
    Wire.beginTransmission(0x3C);
    if (Wire.endTransmission() != 0) {
        Serial.println("OLED: no ACK at 0x3C; display test skipped.");
        return;
    }
    // Wire is initialized on GPIO8/9 before the display; no reset pin.
    oledReady = oled.begin(0x3C, false);
    oled.setRotation(2);  // Rotate 180 degrees for the installed display orientation.
    Serial.println(oledReady
        ? "OLED: SH1106 128x64 static test started; confirm complete border and readable text."
        : "OLED FAIL: initialization failed.");
    updateOled();
}

#if R1_SERVICE_TESTS
void testSd() {
    constexpr uint32_t frequency = 10000000;
    constexpr char payload[] = "R1-S3 HWTEST v0.2: SD write/read test\r\n";
    Serial.println("\nSD test: CS=10 MOSI=11 SCK=12 MISO=13, 10 MHz");
    pinMode(pins::SD_CS, OUTPUT);
    digitalWrite(pins::SD_CS, HIGH);
    SPI.begin(pins::SD_SCK, pins::SD_MISO, pins::SD_MOSI, pins::SD_CS);
    // Never format a card automatically.
    if (!SD.begin(pins::SD_CS, SPI, frequency, "/sd", 5, false)) {
        Serial.println("SD FAIL: mount failed; check card, power and SPI wiring.");
        SD.end();
        return;
    }
    if (SD.cardType() == CARD_NONE) {
        Serial.println("SD FAIL: no card detected.");
        SD.end();
        return;
    }
    Serial.printf("SD capacity: %llu MiB\n", SD.cardSize() / (1024ULL * 1024ULL));
    char path[32];
    bool available = false;
    for (unsigned index = 0; index < 10000; ++index) {
        snprintf(path, sizeof(path), "/r1s3_test_%04u.txt", index);
        if (!SD.exists(path)) {
            available = true;
            break;
        }
    }
    if (!available) {
        Serial.println("SD FAIL: no unused test filename; existing files preserved.");
        SD.end();
        return;
    }
    File output = SD.open(path, FILE_WRITE);
    if (!output) {
        Serial.println("SD FAIL: cannot create test file.");
        SD.end();
        return;
    }
    const size_t expected = sizeof(payload) - 1;
    const size_t written = output.write(reinterpret_cast<const uint8_t*>(payload), expected);
    output.flush();
    output.close();
    Serial.printf("SD file: %s; written %u/%u bytes\n", path,
                  static_cast<unsigned>(written), static_cast<unsigned>(expected));
    SD.end();
    if (written != expected) {
        Serial.println("SD FAIL: incomplete write.");
        return;
    }
    if (!SD.begin(pins::SD_CS, SPI, frequency, "/sd", 5, false)) {
        Serial.println("SD FAIL: remount after write failed.");
        SD.end();
        return;
    }
    File input = SD.open(path, FILE_READ);
    if (!input) {
        Serial.println("SD FAIL: cannot reopen test file.");
        SD.end();
        return;
    }
    uint8_t actual[sizeof(payload)] = {};
    const size_t fileSize = input.size();
    const size_t received = input.read(actual, sizeof(actual));
    input.close();
    const bool match = fileSize == expected && received == expected &&
                       memcmp(actual, payload, expected) == 0;
    sdPassed = match;
    SD.end();
    Serial.println(match ? "SD PASS: write, close, remount and exact readback matched."
                         : "SD FAIL: readback size or content mismatch.");
    Serial.println("Test file retained. Power-cycle persistence not tested.");
}
#else
void checkSdReadOnly() {
    sdPassed = false; // A failed re-test must replace the previous successful result.
    pinMode(pins::SD_CS, OUTPUT);
    digitalWrite(pins::SD_CS, HIGH);
    SPI.begin(pins::SD_SCK, pins::SD_MISO, pins::SD_MOSI, pins::SD_CS);
    if (SD.begin(pins::SD_CS, SPI, 10000000, "/sd", 5, false) && SD.cardType() != CARD_NONE) {
        File root = SD.open("/", FILE_READ);
        sdPassed = root && root.isDirectory();
        root.close();
    }
    sdStatus = sdPassed ? "READ" : "FAIL";
    Serial.printf("SD %s: mount/root read only; no test files or formatting.\n", sdStatus);
    SD.end();
}
#endif

void scanI2c() {
    bool found[128] = {};
    unsigned count = 0;
    unsigned errors = 0;
    Serial.println("\nI2C scan: SDA=8 SCL=9, 100 kHz (7-bit addresses)");
    for (uint8_t address = 0x08; address <= 0x77; ++address) {
        Wire.beginTransmission(address);
        const uint8_t result = Wire.endTransmission();
        if (result == 0) {
            found[address] = true;
            ++count;
            Serial.printf("  ACK 0x%02X\n", address);
        } else if (result != 2) {
            ++errors;
            Serial.printf("  ERROR 0x%02X: code %u\n", address, result);
        }
        delay(2);
    }
    Serial.printf("Devices: %u; bus errors: %u\n", count, errors);
    i2cCount = count;
    i2cErrors = errors;
    Serial.printf("Expected addresses: OLED 0x3C=%s, INA228 0x40=%s, "
                  "24C32 0x50=%s, RTC 0x68=%s\n",
                  found[0x3C] ? "ACK" : "MISSING",
                  found[0x40] ? "ACK" : "MISSING",
                  found[0x50] ? "ACK" : "MISSING",
                  found[0x68] ? "ACK" : "MISSING");
    Serial.println("ACK confirms an address response, not device identity.");
}

bool runPanelAction(const char* verb, const char* argument, const char*& message) {
    if(!strcmp(verb,"LINK"))return ecosystemLinkedCommand(argument,message);
    if(!strcmp(verb,"BLE")&&(!strcmp(argument,"OFF")||!strcmp(argument,"ON")||!strcmp(argument,"CAN ON")))
        return r3BleCommand(argument,message);
    if(ecosystemLinkedActive()){
        if(!strcmp(verb,"STOP")&&!*argument)return ecosystemLinkedCommand("STOP",message);
        message="Shared recording active; use LINK STOP";return false;
    }
    if(!strcmp(verb,"BLE"))return r3BleCommand(argument,message);
#if R1_BENCHMARK
    if(!strcmp(verb,"BENCH"))return rateBenchmarkStart(argument,message,runPanelAction);
#endif
    if(!strcmp(verb,"STOP")&&!*argument){r3BleCancelPendingStarts();return recorder::stop(message);}
    if(!strcmp(verb,"START")&&!*argument){
        return ecosystemStartRecording(nullptr,message);
    }
    if (!i2cReady) { message="I2C unavailable"; return false; }
    if (!strcmp(verb,"MEASURE") && !*argument) {
        inaStatus=testIna228();message=inaStatus;return latestIna228Reading().valid;
    }
    if (!strcmp(verb,"I2C") && !*argument) {
        scanI2c();message="I2C scan completed; inspect device count and errors";return i2cErrors==0;
    }
    if (!strcmp(verb,"SD") && !*argument) {
#if R1_SERVICE_TESTS
        message="SD command disabled in service build";return false;
#else
        sd_files::Request q;sd_files::Response r;
        sdPassed=sd_files::request(q,r);sdStatus=sdPassed?"READ":"FAIL";
        message=sdPassed?"SD mount/root read passed":"SD unavailable or file transfer active";return sdPassed;
#endif
    }
    if (!strcmp(verb,"EEPROM") && !*argument) {
        eepromStatus=checkEepromReadOnly();message=eepromStatus;return !strcmp(eepromStatus,"READ");
    }
    if (!strcmp(verb,"RTC") && !*argument) {
        rtcStatus=pollRtc();message=rtcStatus;return rtcUtcNow()!=0;
    }
    if (!strcmp(verb,"TIME")) {
        if(r3BleTimeAuthorityAvailable()){message="Control Center time has priority; local time editing unavailable";return false;}
        uint64_t epoch=0;const size_t n=strlen(argument);
        if(n<9||n>10){message="Expected Unix seconds";return false;}
        for(size_t i=0;i<n;++i){if(argument[i]<'0'||argument[i]>'9'){message="Invalid UTC";return false;}epoch=epoch*10+argument[i]-'0';}
        const bool ok=panelSetRtcUtc(epoch);rtcStatus=pollRtc();
        message=ok?"RTC UTC written and verified":"RTC write/readback failed";return ok;
    }
    message="Unknown or unavailable test";return false;
}

void setup() {
#if !ARDUINO_USB_CDC_ON_BOOT
    Serial.setRxBufferSize(8192);
#endif
#if ARDUINO_USB_CDC_ON_BOOT && ARDUINO_USB_MODE == 1
    // Keep a complete panel reply in the native Serial/JTAG TX ring. The
    // default 256-byte ring repeatedly flushes the hardware FIFO mid-reply.
    Serial.setTxBufferSize(16384);
    Serial.setRxBufferSize(4096);
    Serial.setTxTimeoutMs(1000);
#endif
    Serial.begin(115200);
    delay(2000);
    Serial.println("\nR1-S3 PANEL v" R1_FIRMWARE_VERSION ": direct Wi-Fi + SD session recording");
    Serial.printf("RESET reason=%u\n",unsigned(esp_reset_reason()));
    Serial.println(R1_SERVICE_TESTS ? "SERVICE BUILD: SD/EEPROM write tests enabled."
                                 : "NORMAL BUILD: no SD/EEPROM test writes. Command: EEPROM DUMP");
    Serial.printf("Chip: %s rev %u, CPU %u MHz\n", ESP.getChipModel(),
                  ESP.getChipRevision(), ESP.getCpuFreqMHz());
    Serial.printf("Flash: %u bytes, %u Hz\n", ESP.getFlashChipSize(),
                  ESP.getFlashChipSpeed());
    Serial.printf("PSRAM: %s, total %u bytes, free %u bytes\n",
                  psramFound() ? "DETECTED" : "NOT DETECTED",
                  ESP.getPsramSize(), ESP.getFreePsram());
    Serial.println("Memory sizes only; no memory stress test performed.");
    i2cReady = Wire.begin(pins::I2C_SDA, pins::I2C_SCL, 100000);
    Wire.setTimeOut(50);
    if (i2cReady) {
        scanI2c();
    } else {
        Serial.println("FAIL: I2C initialization failed.");
    }
#if R1_SERVICE_TESTS
    testSd();
    sdStatus = sdPassed ? "PASS" : "FAIL";
#else
    checkSdReadOnly();
#endif
    initOled();
#if R1_SERVICE_TESTS
    if (i2cReady && sdPassed) {
        eepromStatus = testEeprom();
        updateOled();
    } else {
        Serial.println("EEPROM SKIP: I2C and SD must pass first.");
    }
#else
    if (i2cReady) eepromStatus = checkEepromReadOnly();
#endif
    if (i2cReady) rtcStatus = pollRtc();
    if (i2cReady) { initSettings(); inaStatus = testIna228(); }
    local_input::begin();
    Serial.println("INPUT: encoder stub; no GPIO assigned or accessed.");
    const bool buffersReady = recording::prepareMemory(appliedSettings().queue_bytes);
    Serial.printf("BUFFER %s: PSRAM=%lu bytes, slots=%lu, sample=%u bytes, internal SD block=%lu bytes.\n",
                  buffersReady ? "PREPARED" : "FAIL",
                  static_cast<unsigned long>(recording::allocatedQueueBytes()),
                  static_cast<unsigned long>(recording::sampleQueue().capacity()),
                  static_cast<unsigned>(sizeof(recording::Sample)),
                  static_cast<unsigned long>(buffersReady ? recording::SD_BLOCK_BYTES : 0));
    Serial.println("BUFFER: acquisition -> PSRAM FIFO -> SD owner; recording starts only on START.");
    Serial.printf("LIVE history in PSRAM: %s\n",liveHistoryBegin()?"READY":"FAIL");
    sd_files::begin();
    r3BleBegin();
    panelBegin(runPanelAction);
    panelPublish({sdStatus,eepromStatus,rtcStatus,inaStatus,oledReady,i2cCount,i2cErrors,oledFrames,oledChunkUs});
    updateOled();
}

void loop() {
    static bool started=false;
    static uint32_t lastRtc=0,lastDisplay=0,lastPublish=0,publishedRevision=0;
    if(!started){vTaskPrioritySet(nullptr,3);acquisitionBegin();started=true;}
    if(otaOwnerPoll())return;
    setSettingsRecording(recorder::busy());
    acquisitionStep();
    rateBenchmarkStep();
    if(acquisitionIdle())panelPoll();
    if(acquisitionIdle())ecosystemOwnerPoll(i2cReady,sdPassed);
    inaStatus=acquisitionStatus();
    // Publish before optional OLED work consumes the remaining acquisition slack.
    // Otherwise a healthy 100 Hz acquisition can leave the UI snapshot stale for seconds.
    if((millis()-lastPublish>=500 || publishedRevision!=settingsRevision()) && acquisitionWorkBudgetUs()>300){
        panelPublish({sdStatus,eepromStatus,rtcStatus,inaStatus,oledReady,i2cCount,i2cErrors,oledFrames,oledChunkUs});
        lastPublish=millis();publishedRevision=settingsRevision();
    }
    // A quiet acquisition slot is not guaranteed (100 Hz / 100 kHz can starve
    // RTC reads indefinitely). Shared recording requires fresh controller time.
    // Reserve an accounted maintenance slot at a conversion boundary; the next
    // sample carries GAP evidence. Independent recording retains its slack policy.
    if(i2cReady && millis()-lastRtc>=5000){
        const bool reserve=(!recorder::busy()||ecosystemLinkedActive())&&acquisitionIdle();
        if(reserve||acquisitionWorkBudgetUs()>(Wire.getClock()>100000?1600:4500)){
            if(reserve)acquisitionPause();
            rtcStatus=pollRtc(false);lastRtc=millis();
            if(reserve)acquisitionResume();
        }
    }
    if(oledOffset==sizeof(oledFrame) && millis()-lastDisplay>=1000/appliedSettings().display_hz && acquisitionWorkBudgetUs()>1500){
        updateOled();lastDisplay=millis();
    }
    if(acquisitionWorkBudgetUs()>(Wire.getClock()>100000?700:2600))oledStep();
    // Leave a tick for SD/idle whenever it fits. Near a deadline avoid adding a
    // whole tick to every trigger and conversion-ready check.
    if(acquisitionWorkBudgetUs()>1300)delay(1);
    else delayMicroseconds(40);
}

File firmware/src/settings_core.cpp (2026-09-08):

#include "settings_core.h"
#include <cstring>
#include <cmath>
#include <algorithm>
#include <limits>
namespace settings {
namespace {
void put(Bytes& b,size_t p,uint64_t v,size_t n){for(size_t i=0;i<n;++i)b[p+i]=uint8_t(v>>(8*i));}
uint64_t get(const uint8_t* p,size_t n){uint64_t v=0;for(size_t i=0;i<n;++i)v|=uint64_t(p[i])<<(8*i);return v;}
bool utf8(const std::string& s){
    for(size_t i=0;i<s.size();){uint32_t cp=uint8_t(s[i++]);unsigned count=0;uint32_t min=0;
        if(!cp)return false;if(cp<128)continue;
        if(cp>=0xc2&&cp<=0xdf){count=1;cp&=31;min=128;}
        else if(cp>=0xe0&&cp<=0xef){count=2;cp&=15;min=2048;}
        else if(cp>=0xf0&&cp<=0xf4){count=3;cp&=7;min=65536;}else return false;
        while(count--){if(i==s.size()||(uint8_t(s[i])&0xc0)!=0x80)return false;cp=(cp<<6)|(uint8_t(s[i++])&63);}
        if(cp<min||cp>0x10ffff||(cp>=0xd800&&cp<=0xdfff))return false;
    }return true;
}
bool validDate(const std::string& s){
    if(s.empty())return true;if(s.size()!=20||s[4]!='-'||s[7]!='-'||s[10]!='T'||s[13]!=':'||s[16]!=':'||s[19]!='Z')return false;
    for(size_t i=0;i<19;++i)if(i!=4&&i!=7&&i!=10&&i!=13&&i!=16&&(s[i]<'0'||s[i]>'9'))return false;
    auto num=[&](int p,int n){int v=0;while(n--)v=v*10+s[p++]-'0';return v;};
    const int y=num(0,4),m=num(5,2),d=num(8,2),days[]={31,28,31,30,31,30,31,31,30,31,30,31};
    return y>=1&&m>=1&&m<=12&&d>=1&&d<=days[m-1]+(m==2&&y%4==0&&(y%100!=0||y%400==0))&&num(11,2)<24&&num(14,2)<60&&num(17,2)<60;
}
void raw(Bytes& b,unsigned id,unsigned type,const uint8_t* p,size_t n){size_t pos=b.size();b.resize(pos+8);put(b,pos,id,2);b[pos+2]=type;put(b,pos+4,n,2);b.insert(b.end(),p,p+n);}
void append(Bytes& b,unsigned id,unsigned type,uint32_t v){Bytes r(4);put(r,0,v,4);raw(b,id,type,r.data(),4);}
void append(Bytes& b,unsigned id,unsigned type,int32_t v){append(b,id,type,uint32_t(v));}
void append(Bytes& b,unsigned id,unsigned type,double v){static_assert(sizeof(v)==8,"IEEE binary64 required");uint64_t u;memcpy(&u,&v,8);Bytes r(8);put(r,0,u,8);raw(b,id,type,r.data(),8);}
void append(Bytes& b,unsigned id,unsigned type,bool v){uint8_t r=v;raw(b,id,type,&r,1);}
void append(Bytes& b,unsigned id,unsigned type,const std::string& v){raw(b,id,type,reinterpret_cast<const uint8_t*>(v.data()),v.size());}
bool field(const Bytes& b,size_t& pos,unsigned id,unsigned type,const uint8_t*& p,size_t& n){
    if(pos+8>b.size()||get(&b[pos],2)!=id||b[pos+2]!=type||b[pos+3]||b[pos+6]||b[pos+7])return false;
    n=get(&b[pos+4],2);pos+=8;if(n>b.size()-pos)return false;p=b.data()+pos;pos+=n;return true;
}
bool take(const Bytes& b,size_t& pos,unsigned id,unsigned type,uint32_t& v){const uint8_t* p;size_t n;if(!field(b,pos,id,type,p,n)||n!=4)return false;v=get(p,4);return true;}
bool take(const Bytes& b,size_t& pos,unsigned id,unsigned type,int32_t& v){uint32_t u;if(!take(b,pos,id,type,u))return false;memcpy(&v,&u,4);return true;}
bool take(const Bytes& b,size_t& pos,unsigned id,unsigned type,double& v){const uint8_t* p;size_t n;if(!field(b,pos,id,type,p,n)||n!=8)return false;uint64_t u=get(p,8);memcpy(&v,&u,8);return true;}
bool take(const Bytes& b,size_t& pos,unsigned id,unsigned type,bool& v){const uint8_t* p;size_t n;if(!field(b,pos,id,type,p,n)||n!=1||*p>1)return false;v=*p;return true;}
bool take(const Bytes& b,size_t& pos,unsigned id,unsigned type,std::string& v){const uint8_t* p;size_t n;if(!field(b,pos,id,type,p,n))return false;v.assign(reinterpret_cast<const char*>(p),n);return true;}
}
#include "config_codec_generated.inc"
uint32_t crc32(const uint8_t* data,size_t n){uint32_t c=0xffffffff;while(n--){c^=*data++;for(unsigned j=0;j<8;++j)c=(c>>1)^((c&1)?0xedb88320:0);}return ~c;}
// Keep legacy-compatible values byte-identical; extended values protect rollback
// by declaring minor 1, which previous firmware treats as write-protected.
unsigned configMinor(const Config& c){return (c.requested_rate_hz==10||c.requested_rate_hz==50||c.requested_rate_hz==100)&&c.max_gap_us<=1000000?0:1;}
Bytes slot(const Config& c,uint64_t gen){
    const Bytes payload=encode(c);if(payload.empty()||payload.size()>1472||!gen)return {};
    Bytes out(slotSize,0xff);std::fill(out.begin(),out.begin()+32,0);memcpy(out.data(),"R1CF",4);put(out,4,1,2);put(out,6,configMinor(c),2);put(out,8,32,2);put(out,12,gen,8);put(out,20,payload.size(),4);std::copy(payload.begin(),payload.end(),out.begin()+32);
    uint32_t crc=crc32(out.data(),32+payload.size());put(out,24,crc,4);
    std::fill(out.begin()+footerOffset,out.end(),0);memcpy(out.data()+footerOffset,"RCMT",4);put(out,footerOffset+4,gen,8);put(out,footerOffset+12,crc,4);put(out,footerOffset+16,payload.size(),4);return out;
}
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

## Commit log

2026-09-07 Add migration journal and verified INA228 ADC bring-up
2026-09-07 Configure 60 mV 400 A shunt and report nominal current
2026-09-07 Record INA228 discrepancy against reported 0.94 A clamp reading
2026-09-07 Record onboard R015 shunt and photo-based wiring findings
2026-09-07 Record improved current readings after onboard shunt removal
2026-09-07 Record low-side current and VBUS observations
2026-09-07 Display live INA228 voltage and current on OLED
2026-09-07 Record owner-reported XDM1241 voltage comparison at 4 A
2026-09-07 Define R1-S3 architecture and staged compatibility roadmap
2026-09-07 Define config and recording contracts with compatibility fixtures
    [native-bad-crc.csv, native-gap.csv, native-interrupted.csv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]
2026-09-08 Define standalone device UI and dual-core task ownership
2026-09-08 Add encoder stub and PSRAM FIFO with checked block buffering
2026-09-08 Add USB and Wi-Fi device test panel with acknowledged hardware commands
2026-09-08 Keep panel state fresh at 100 Hz and document load acceptance
2026-09-08 Add 1-300 Hz rate profiles and keep panel publication off acquisition core
2026-09-08 Keep high-rate live preview current and document rate selection
2026-09-08 Record 1-300 Hz acceptance and pending final UART deployment
2026-09-08 Verify final 300 Hz panel after USB cable replacement
2026-09-08 Document UART failure reproduced after USB cable replacement
2026-09-08 Record paired UART byte and Wi-Fi evidence of framing errors
2026-09-08 Record UART endurance and residual ROM failure after board cleaning
2026-09-08 Add bounded overnight UART and SD endurance runner
2026-09-08 Report interrupted overnight UART test and verified recovery
2026-09-09 Lay groundwork for R3 ecosystem time synchronization
2026-09-15 Stabilize CANBox clock refresh and native USB status transport
    [app.js, bridge.py, main.cpp]
2026-09-28 Add R3 PowerBox power architecture
    [R3_power.kicad_pcb, R3_power.kicad_sch, R3_power.sch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]
2026-09-28 Finalize R3 PowerBox pre-placement corrections
    [R3_power.kicad_sch, R3_power_battery_management1.kicad_sch, R3_power_charger_powerpath1.kicad_sch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]
2026-09-28 Finalize R3 PowerBox pre-routing placement
    [R3_power.kicad_pcb, R3_power.kicad_sch, R3_power_battery_management1.kicad_sch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]
2026-09-28 Finalize R3 PowerBox user power controls
    [R3_power.kicad_pcb, R3_power.kicad_sch, R3_power_battery_management1.kicad_sch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]
2026-09-28 Update R3 PowerBox project memory
2026-09-28 Finalize R3 PowerBox mechanical interconnect
    [R3_power.kicad_pcb, R3_power.kicad_sch, R3_power_battery_management1.kicad_sch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]
2026-10-23 docs: point PowerBox development to standalone R3 repository [skip ci]
